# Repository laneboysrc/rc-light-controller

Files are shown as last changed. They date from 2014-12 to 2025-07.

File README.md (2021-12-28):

# Light controller for Radio Controlled cars

Realistic lighting of RC model cars using a standard 3-channel radio control system.

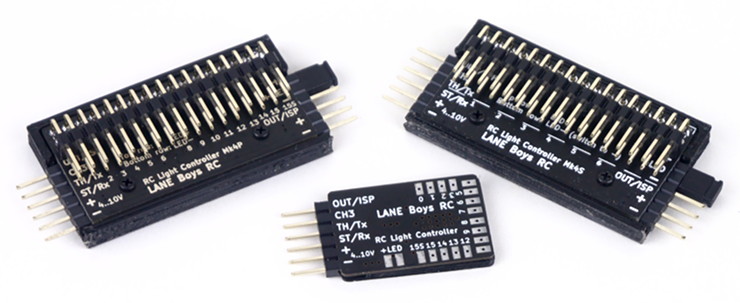
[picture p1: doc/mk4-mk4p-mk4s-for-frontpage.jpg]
MK4 light controller revision 2 PCB


The light controller supports the following features, and more::

- **16 LED outputs, constant-current** driven. Up to 20mA per output. Two light
controllers can be cascaded for a total of 32 LED outputs.
(Mk4 and Mk4P only)

- 1 high current non-dimmable **switched output** of up to **2A** to drive a roof light bar
(Mk4S: 9 non-dimmable switched outputs)

- **Parking, Low-beam, High-beam** and a roof **light bar** can be switched on/off manually from the transmitter

- **Brake** and **Reversing** lights are **automatically** controlled by monitoring the throttle channel. The brake lights now automatically turn on for a short, random time when the throttle goes to neutral.

- **Combined tail and brake light** function in a single LED through controlling the brightness of the LED. (Mk4 and Mk4P only)

- **Indicators** only come on when you want to. You have to stay in neutral for one seconds, then hold the steering left/right for one second before they engage. This way normal driving does not trigger the indicators.

- **Hazard lights** can be switched on/off from the transmitter

- **Programmable output** designed to drive a **steering wheel** or a figures head, or a
**gearbox servo**

- Automatic center and end-point adjustment for steering and throttle channels

- **16 LEDs** can be driven by one light controller. Two controllers can be **daisy-chained for up to 32 LEDs**.

- **Light Programs for custom light animations** like police lights, running lights ...

- Simulation of incandescent lights and faulty ground wiring

- Optional **i-Bus** compatible input

- Optional Pre-Processor for **easier wiring**

- **Up to 3 AUX channels** can control light functions when using the **5-channel Pre-
Processor**

- All functions can be **customized through a [web browser](https://laneboysrc.github.io/rc-light-controller/)**

## Documentation

An **introduction video** can be found at:

- [https://youtu.be/-VyNAVU3-ok](https://youtu.be/-VyNAVU3-ok)

You may also want to read the **[users guide](doc/light-controller-instructions-mk4.pdf)** to get a grasp of the full functionality of this light controller system.

(Die [Bedieungsanleitung ist auch in Deutsch](doc/light-controller-instructions-mk4-deutsch.pdf) verfügbar)

## Hardware

Firmware and schematics for the different variants are included in this project.

Over the years, the light controller went through various iterations. The document [doc/hardware-overview.md](doc/hardware-overview.md) explains the history of development.

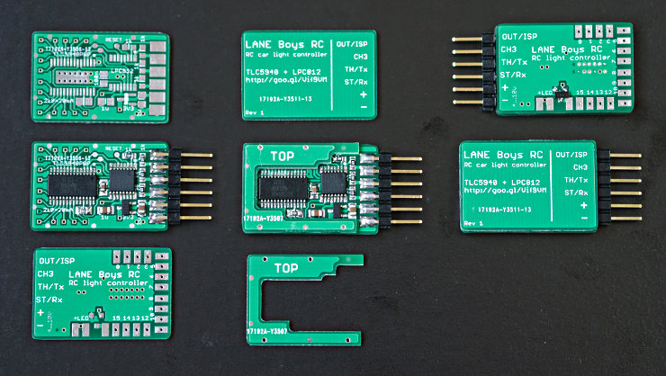
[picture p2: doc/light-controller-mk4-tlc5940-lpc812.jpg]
MK4 light controller in various state of assembly


[The current MK4 variant](mk4-tlc5940-lpc812/) can drive **16 LEDs** with a **constant current**. It utilises an inexpensive **NXP ARM Cortex-M0 32-bit microcontroller**.
The main advantage of this design is that it can be fully configured through a [web-based user interface](https://laneboysrc.github.io/rc-light-controller/). Firmware and configuration can be downloaded with a standard USB-to-serial converter, no proprietary tools required.

## Unable to build one yourself?

Not everyone is able to build circuit boards with tiny SMD components. If this applies to you please contact [laneboysrc@gmail.com](mailto:laneboysrc@gmail.com), we usually have a few fully built-up units in stock.

## Related articles

- [http://laneboysrc.blogspot.com/2012/07/diy-car-light-controller-for-3-channel.html](http://laneboysrc.blogspot.com/2012/07/diy-car-light-controller-for-3-channel.html)

- [http://laneboysrc.blogspot.com/2013/09/diy-rc-light-controller-update.html](http://laneboysrc.blogspot.com/2013/09/diy-rc-light-controller-update.html)

- [http://laneboysrc.blogspot.com/2012/12/pre-processor-for-diy-rc-light.html](http://laneboysrc.blogspot.com/2012/12/pre-processor-for-diy-rc-light.html)

- [http://laneboysrc.blogspot.com/2013/01/pre-processor-miniaturization.html](http://laneboysrc.blogspot.com/2013/01/pre-processor-miniaturization.html)

- [http://laneboysrc.blogspot.com/2014/07/ws2812-and-pl9823-led-power-consumption.html](http://laneboysrc.blogspot.com/2014/07/ws2812-and-pl9823-led-power-consumption.html)

- [http://laneboysrc.blogspot.com/2014/08/diy-rc-light-controller-with-ws2812b.html](http://laneboysrc.blogspot.com/2014/08/diy-rc-light-controller-with-ws2812b.html)

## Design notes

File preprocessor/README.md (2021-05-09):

# Pre-processor

The pre-processor converts steering, throttle and AUX/CH3 signals into a single wire serial signal. By mounting the pre-processor near the receiver in the car chassis, you only need to run a standard servo extension cable to the light controller in the body shell.

This makes it very convenient when removing the body shell from the chassis: only one cable needs to be unplugged.

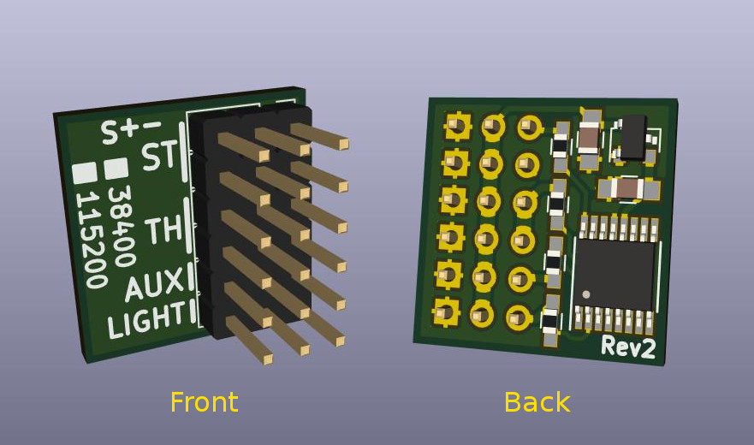
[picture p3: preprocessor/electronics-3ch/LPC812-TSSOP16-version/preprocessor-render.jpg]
Pre-processor circuit board rendering


The pre-processor PCB also acts as "Y-cable" for steering and throttle. Use short male-to-male servo extensions to connect the pre-processor to your receiver, and plug the servo and ESC into the two extra ports on the pre-processor.

A [wiring diagram](../doc/preprocessor-wiring-diagram.pdf) explains how to connect the pre-processor, the light controller and the other electronics components in an RC car together.

The firmware for the pre-processor is the same as for the [MK4 variant](../mk4-tlc5940-lpc812/), you just have to utilize the MK4 configurator tool to generate a pre-processor firmware.

If the baud rate is configured to 38400, the pre-processor is also compatible with the MK2 and MK3 variants.

The PCB and schematics design was done in [KiCad EDA](http://kicad-pcb.org/)

3-channel Pre-Processor: [electronics-3ch/](electronics-3ch/)

5-channel Pre-Processor: [electronics-5ch/](electronics-5ch/)

5-channel Pre-Processor/switching light controller combination (4 switched LED outputs): [electronics-5ch-switching/](electronics-5ch-switching/)

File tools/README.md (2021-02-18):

# Tools that apply to multiple versions of the light controller

The command line tools are writing in [Python](http://www.python.org/).

## preprocessor-reader.py

Reads and displays the output of the preprocessor (= a small microcontroller that interfaces with your receiver. This microcontroller outputs a single serial signal containing information for steering, servo and AUX channels. By using a preprocessor the light controller can be connected with a single servo extension wire.)

Used for debugging and testing the preprocessor.

## preprocessor-simulator.py

This tool simulates an RC transmitter, generating a serial output of steering, throttle and AUX channels in the serial preprocessor format. It is very useful for bench-testing the light controller functionality without having to hook up a RC system.

The user interface is web-based: after launching the tool open your webbrowser and browse to [http://localhost:1234/](http://localhost:1234/)

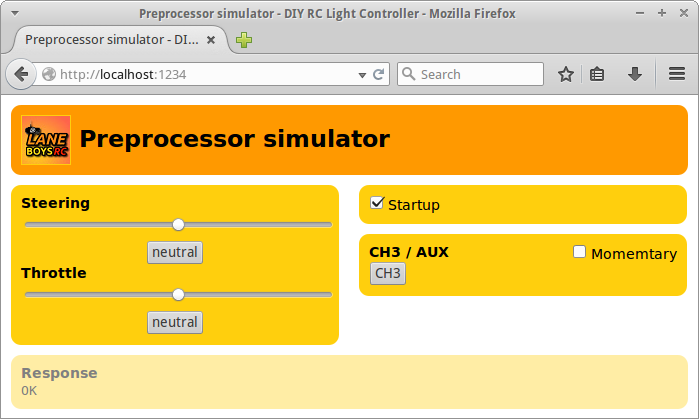
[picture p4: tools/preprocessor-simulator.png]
Preprocessor-simulator screenshot


Keyboard shortcuts:

- **s**: Toggles startup-mode
  Startup-mode signals the light controller that the preprocessor is initializing and not ready for operation yet.

- **c**: Perform a CH3/AUX "click". Easier than hitting the on-screen button with the mouse.

## slave-reader.py

This utility reads the slave output of an RC light controller and displays it in human readable form.

## test-slave.py

This tool drives a light contoller *slave* with a test pattern. Useful for testing.

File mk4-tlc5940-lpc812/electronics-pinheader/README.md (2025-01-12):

# Mk4P - light controller with pin headers

This is a variant of the DIY RC Light Controller Mk4 where all outputs are available on a standard 2.54 mm pin header.

We are using a microcontroller from NXP: LPC824M101FDH20 (or LPC832M101FDH20) in TSSOP-20 package.

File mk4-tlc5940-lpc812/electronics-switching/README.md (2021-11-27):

# Mk4S - light controller with pin headers and 9 switching outputs

This is a new variant of the DIY RC Light Controller Mk4.
It has 9 (Mosfet) switched outputs on standard 2.54 mm pin headers, 8 of them with two connections and one of them with 1 connection.

We are using the TSSOP-20 package of the LPC812 as it is easier to source (as of 2020) than the TSSOP-16 version, and we have plenty of space.

# 2021 electronics shortage

As of early 2021, many electronics components are out of stock due to global semiconductor shortage. This affects also the LPC812 microcontroller.

As of April 2021 a similar microcontroller from NXP, the LPC832M101FDH20 was still in stock at some distributors (but stocks declined towards mid of April rapidly). We prepared a new circuit board for the LPC832, and also ported the firmware.

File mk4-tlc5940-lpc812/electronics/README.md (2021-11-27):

# Mk4 - light controller with solder pads

This is the original version of the Mk4 light controller.
Multiple PCB versions are available for different microcontrollers.

The LPC812-TSSOP16 version is the original design.

pcb-size-27x20 uses the LPC812-TSSOP16 and was created to get around the minimum assembly width requirement for 3rd party manufacture. Not recommended.

The LPC812-XSON16 version uses a tiny case for the microcontroller, which is extremely difficult to work with unless you have professional equipment.

The LPC812-TSSOP20 was never built and tested.

The LPC832-TSSOP20 version is not tested yet, but most likely will work as we successfully ported the Mk4P (basically same schematics) already to the LPC832.

Background info: we ported to the different microcontroller variants to get around the global chip shortage in 2020/2021.

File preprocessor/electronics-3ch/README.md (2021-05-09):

# 3-ch Pre-Processor

This folder contains KiCAD files for the 3 channel Pre-Processor.

The original design used the TSSOP-16 package of the NXP LPC812 microcontroller.
Folder [LPC812-TSSOP16-version/](LPC812-TSSOP16-version/)

Since the TSSOP-20 version was easier available at distributors, we also designed a PCB for this mircocontroller: [LPC812-TSSOP20-version/](LPC812-TSSOP20-version/)
We never built this PCB yet ourselves but it is likely to work since it is just a different package.

# 2021 electronics shortage

As of early 2021, many electronics components are out of stock due to global semiconductor shortage. This affects also the LPC812 microcontroller in both TSSOP-16 and TSSOP-20 packages.

However the XSON-16 package was still available, so we redesigned the PCB for this package: [LPC812-XSON16-version/](LPC812-XSON16-version/)
XSON-16 has a pin-pitch of only 0.4 mm and is extremely difficult to solder in a hobbyist-environment using cheap solder paste and a modified toaster oven. A high number of boards have to be reworked, making it very labor intense to build the hardware.

As of April 2021 a microcontroller similar to the LPC812 from NXP, the LPC832M101FDH20, was still in stock at some distributors (but stocks declined towards mid of April rapidly). We prepared a new circuit board for the LPC832, and also ported the firmware.

As of 2021-04-20 the same firmware can be used for the LPC812 and LPC832 variant.

Note that the LPC81x_ISP programming tool does not support LPC832 yet, but the WebUSB programmer does.

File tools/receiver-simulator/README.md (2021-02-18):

# Receiver simulator

This test code uses a Microchip (Atmel) SAMD21 micro-controller to simulate a 2-channel receiver.

It was designed to run on an SAMR21 Xplained Pro board (because this is what I had lying around), but can be easily adapted to other SAMD21 boards.

The current I/O definition can be found in hal.h.

- The UART prints diagnostics output.
- Two pins should be connected to potentimeters to control ST and TH channels.
- Two other pins output 1000-2000 us servo pulses depending on the potentiometer position.

The receiver has one special feature that the ST and TH output run asynchronously and at different fequencies. TH outputs every 32 ms, ST ever 16ms.
This was done because it seems to mimic the behaviour of the Spektrum 4210 receiver. This behaviour is quite unusual and caused an issue with flickering brake lights.

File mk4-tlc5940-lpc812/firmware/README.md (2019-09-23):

# Build instructions for the MK4 TLC5940 LPC812 variant

Note: most users will not need to build the firmware as it can be fully configured through a web-based configuration tool!

## Tools required:

- GCC for ARM - [https://developer.arm.com/tools-and-software/open-source-software/developer-tools/gnu-toolchain/gnu-rm/downloads](https://developer.arm.com/tools-and-software/open-source-software/developer-tools/gnu-toolchain/gnu-rm/downloads)

- GNU Make - [https://www.gnu.org/software/make/](https://www.gnu.org/software/make/)
  Windows executable is available at [http://gnuwin32.sourceforge.net/packages/make.htm](http://gnuwin32.sourceforge.net/packages/make.htm)

- Windows users: **rm.exe** from [coreutils](http://gnuwin32.sourceforge.net/downlinks/coreutils-bin-zip.php).

# Building the firmware

Running ``make`` in a console window in this directory builds the firmware. The resulting *firmware.bin* and *firmware.hex* are located in the build directory.

Running ``make program`` flashes the firmware, assuming you are using the [LCP81x-ISP](https://github.com/laneboysrc/LPC81x-ISP-tool) tool.

Files in the firmware root directory are source code that is processor hardware independent. The *hal/* folder contains processor-specific light controller functionality such as MCU initialization, GPIO, SPI, UART etc.
*LPC8xx/* contains header files provided by NXP for the LPC812 MCU. *light_programs/* contains example light programs you can use for reference.
Output files of the build process are placed in the *build/* folder.

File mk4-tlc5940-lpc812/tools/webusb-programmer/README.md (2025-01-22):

This is a programmer for the NXP LPC812/823/824 micro-controller, using the ISP (serial) protocol.

It connects to a PC or Android phone via USB and uses WebUSB (available in Chrome, Opera and Edge browsers) to communicate with a web app.

The great thing about this programmer is that no driver or software needs to be installed. Just connect the WebUSB programmer to the PC, load the Light Controller Configurator in the web browser, and program your light controller.

REV6 uses standard 0805 LEDs instead of the hard-to-work-with 1204 side firing LEDs we used in earlier revisions.

REV5 switched from MicroUSB to USB Type C.

REV4 can work with the CH551G, CH552G or CH554G microcontroller from WCH. REV3 was working fine, but due to the *chip crisis* of 2021 it was not possible to get hold of the ST power switch anywhere. So we re-designed the electronics to use a very cheap motor driver to switch the power to the light controller. The firmware was also modified to use UART0, because only UART0 is available on CH551G.

REV3 was the first version using the inexpensive CH552G microcontroller from WCH that has an 8051 core and USB device capability. The BOM has been reduced to the minimum so that long-term we can provide the WebUSB programmers instead of USB-to-Serial adapters. The LEDs are now side mounted so they can be viewed from both sides of the PCB.

In REV1 and REV2 a Microchip (Atmel) ATSAMD21 MCU was used, as we had stock of these. However, this is quite an expensive MCU (at least ten times the price of the CH552!), and needs additional peripheral electronics like an LDO. And it uses a 0.5mm QFN package which requires a stencil, solderpaste and reflow equipment.

REV1 used a surface mount Micro-USB connector (because we had it in stock). However, several people broke the connector as it is mechanically not very robust. Furthermore, the white LED with its soft diffuser is also fragile and can get damaged when handling or shipping.

In REV2 we changed the Micro-USB connector to one with through-hole mounting tabs, and use "reverse mount" LEDs (actually side view LEDs abused in a reverse mount fashion). REV2 worked fine except that the footprint for the Micro-USB connector is not optimal and the hole for the LEDs is slightly too small.

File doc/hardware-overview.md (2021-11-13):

# Hardware overview

Over time the DIY RC Light Controller hardware went through several iterations.

The following sections describe the various variants in detail, list their unique features and provide pros and cons to allow you to make a decision which variant is best for your application.

**Important: Older versions are available in the branch named [*obsolete*](https://github.com/laneboysrc/rc-light-controller/tree/obsolete) in this repository.**

## Mk4 TLC5940 LPC812 and LPC832

Mk4 light controller Rev 2

This iteration makes use of NXP's LPC812 micro-controller. The LPC812 contains an ARM Cortex-M0+ 32-bit core, yet costs as little as the PIC micro-controller we used in earlier variants. The firmware is now written in C. It is compiled with the Open-Source GCC compiler. The LPC812 contains a ROM-based bootloader so firmware can be flashed by using a very low cost USB-to-serial converter (less than USD 3, including shipping, on eBay).

One of the main issue for other people building earlier light controller variants was making changes to the firmware to suite their particular requirements. With the Mk4 variant we have now a **web-based configuration tool** called the **Configurator** that allows anyone to adapt the light outputs to their desired functionality without having to modify source code.

The TI TLC5940 LED driver IC is employed to drive the LEDs with a constant current. 16 LED outputs are available. The current, and therefore the LED brightness, can be adjust in 63 steps. Using a constant current means that no resistor is needed for the LEDs, and that the LEDs don't flicker as they would when they are driven by PWM signals. Humans don't see the flicker, but in videos the shutter speed of the camera often causes ugly blink effects when PWM dimming is employed.

Based on feedback from users, the Mk4 variant also now supports an option for a high-current switched light output. Such output is useful to drive an off-the-shelf roof light bar without modification.

The light controller can also control a 2-speed or 3-speed gearbox servo, or an auxiliary servo that drives the steering wheel in the cabin of the car, or a figures head.

If more than 16 LED outputs are needed, a second light controller "slave" can be added to drive another 16 LEDs, all in control of the "master" light controller.

Due to improved hardware available in the LPC812 micro-controller, servo pulse reading is now auto-adaptable and should work with any RC system on the market. In addition there is also support for the [preprocessor](#preprocessor).

The preprocessor makes wiring up the light controller much simpler as only a single servo extension wire is needed to get steering, throttle and AUX channel information from the receiver to the light controller.

The light controller can now also be used with 2-channel radios by mounting a push-button somewhere hidden on the car to control the lights.

The main downside of the Mk4 design is that the LPC812 micro-controller is only available in tiny surface mount packages. It more or less requires to build the light controller on a PCB, though one may get away with an off-the-shelf TSSOP-16 adapter board.

Based on customer request, we also made the Mk4P light controller. Schematics-wise it is identical with the Mk4, but it has a pin header so that LEDs can be connected without soldering.

We also made a Mk4S variant that has 9 switching outputs instead of current-controlled outputs. The Mk4S has the same form factor as the Mk4P is great for users who want to use high-power LEDs.

There are also two variants that we haven't promoted. The Mk4S-mini is a small light controller with 3 switching outputs. It is suitable for users that require more than one switching output, but not all 9 that the Mk4S offers.

Then there is the 5ch-PP-S, a 5-channel Pre-Processor and light controller hybrid. It has the form-factor of a slightly enlarged 5-channel Pre-Processor and offers 4 switched light outputs. This variant is useful for crawlers where there are a few LEDs in the chassis (driven by the 5ch-PP-S) and the remaining LEDs in the body shell (powered by Mk4, Mk4P or Mk4S)

*And then the chip crisis of 2020/2021 happened ...*

The LPC812 micro-controller suddenly had a lead time of 52 weeks, and is nowhere to be found. Well, a few places had the tiny XSON package with 0.4 mm pin pitch. We tried building light controllers in the XSON package, but it was not practical in our primitive home workshop -- we had almost 60% failure rate.

Luckily, NXP also has a similar sister-chip named LPC832. It has slightly different features, a different pin out and comes only in TSSOP20 package. We were able to stock a few pieces of LPC832 at affordable prices and developed new circuit boards for all Mk4 variants. The firmware was adapted so that it can seamlessly work with both LPC812 and LPC832. Also the programming tools had to be adapted. As of writing of this paragraph (November 2021), also the LPC832 becomes a very scarce resource ...

## Pre-Processor for simpler wiring

To utilize its full potential, the DIY RC Light Controller must be able to read Steering, Throttle and AUX (CH3) signals from the receiver. Such a combined signal such as CPPM is unfortunately not available on most modern surface receivers. (Update 2021: i-Bus is now available on surface receivers from Flysky!)

Therefore the easiest way is to use a Y-cable on steering and throttle channels and feed all signals individually to the light controller.

However, since the light controller is usually mounted on the body shell and the receiver on the chassis, the Y-cable solution requires one to disconnect three cables every time the body shell needs to be separated from the chassis.

To solve this issue we added a small micro-controller into our receivers. This micro-controller directly taps into the servo outputs and generates a serial signal on a single wire that contains combined information of all channels. This way we only need to run a single servo extension wire between the chassis and the body, providing both power and data. We use this system in most of our RC cars.

More information about the Pre-Processor:

- [http://laneboysrc.blogspot.com/2012/12/pre-processor-for-diy-rc-light.html](http://laneboysrc.blogspot.com/2012/12/pre-processor-for-diy-rc-light.html)

- [http://laneboysrc.blogspot.com/2013/01/pre-processor-miniaturization.html](http://laneboysrc.blogspot.com/2013/01/pre-processor-miniaturization.html)

Note that with the Mk3 WS2812 PIC12F1840 variant one could mount the light controller on the chassis and have a single 3-pole wire running to the first LED in the chain. Since we run different bodies on many of our chassis, each having different light configurations, we still use the Pre-Processor. Since the cost of the PIC12F1840 is less than USD 2 this is not an issue.

Naturally most people won't modify their receiver to add this chip, plus programming the PIC micro-controller requires investment in a proprietary programming tool.

So with the introduction of the Mk4 light controller, we also made separate circuit boards for the Pre-Processor. This enabled more users to benefit from the Pre-Processor concept.

The Pre-Processor is built upon the same NXP LCP812 (and LPC832) micro-controller as the Mk4 light controller. Actually a Pre-Processor is nothing more than a light controller without LED driver, and a special configuration in the firmware.

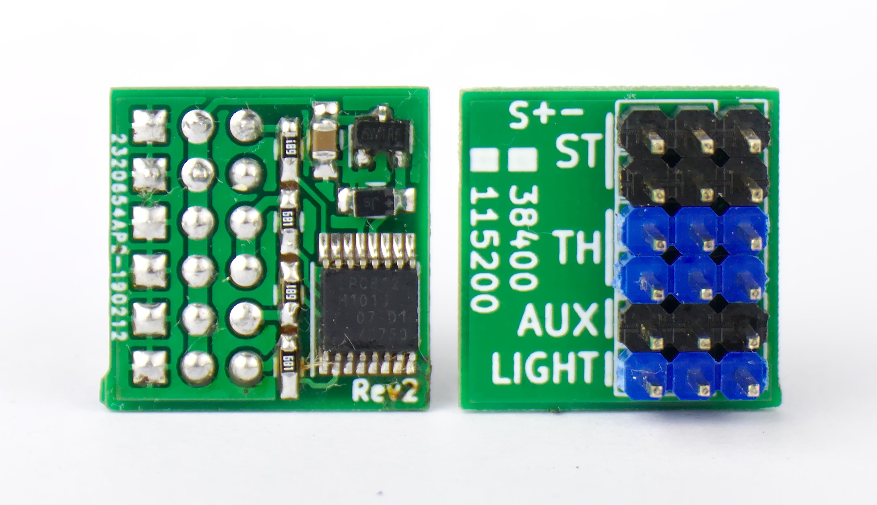
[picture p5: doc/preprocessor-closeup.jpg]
The 3-channel Pre-Processor


A few customers were requesting more control over lights, so we added a 5-channel Pre-Processor that offers two additional AUX channels.

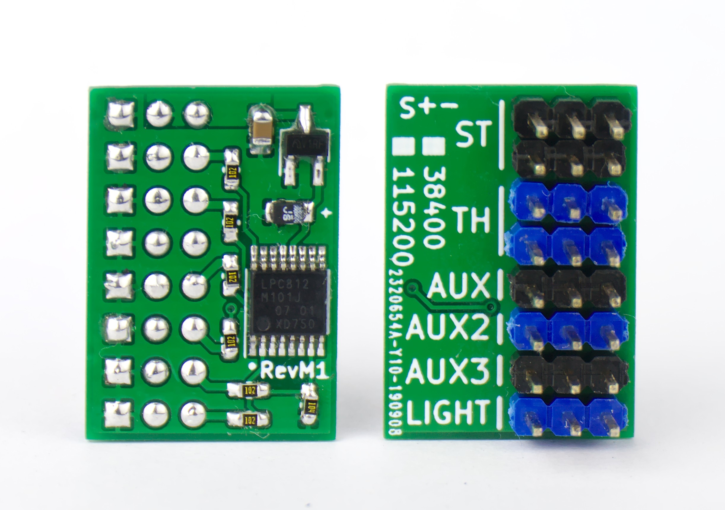
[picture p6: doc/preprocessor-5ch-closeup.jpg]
The 5-channel Pre-Processor


## Mk3 WS2812 PIC12F1840

The MK3 light controller on the left

(MK3 on the left, MK2 on the right)

In recent years LEDs are appearing on the market that contain a controller chip. Currently the [WS2812B](https://www.adafruit.com/products/1655) is highly popular. It is a RGB LED that contains a simple chip inside. The LED is controlled through a single pin using a [serial shift-register-like protocol](http://cpldcpu.wordpress.com/2014/01/14/light_ws2812-library-v2-0-part-i-understanding-the-ws2812/). Multiple LEDs can be chained together; like a Christmas light.

The WS2812B is extremely cheap too. When ordered in 100 pcs quantity from China it is only slightly more expensive than a regular 5 mm white LED from the local hobby shop.

Using such LEDs makes wiring up a vehicle very easy: one only needs to run 3 wires from one LED to the next. Also the control electronics becomes simpler as only a simple low pin-count device is needed. We have chosen the PIC12F1840 that we already employed in other applications.

The WS2812B are SMD LEDs in a 5 x 5 mm square case. This makes mounting them in a traditional RC car light bucket, which is usually designed for 5 mm round dome style LEDs, inconvenient.

However, the [PL9823](http://www.aliexpress.com/item/PL9823-F5-5mm-round-hat-RGB-LED-with-PD9823-chipset-inside-full-color-frosted/1707175958.html) has the same functionality as the WS2812B and comes in a standard 5 mm dome encasing with four leads. The PL9823 is timing compatible with the WS2812B, so both LEDs can be mixed in the same string of lights.

The PL9823 has few downsides over the WS2812B:

- [High power consumption](http://laneboysrc.blogspot.com/2014/07/ws2812-and-pl9823-led-power-consumption.html) of \~7-8mA even if the LED is off

* When power is applied the LEDs usually light up blue until they receive valid data. The WS2812B stay off until data is received.

* Data format is red-green-blue , while WS2812 is green-red-blue. This can be easily dealt with in software though.

**Note that it is essential to put a bypass capacitor of 100nF over the supply pins of each LED.**

When using the WS2812 it is advisable to not buy the bare LED, but rather the ones that come on a tiny circuit board of \~10 x 10 mm.
This board already contains the bypass capacitor and convenient terminals for soldering.

Unfortunately no such board seems to exist for the PL9823. It is possible to solder wires directly onto the leads of the LEDs, but due to the narrow pitch it is not fun. We have made a small break-out board, including bypass capacitor, ourself. The board layout is available in Eagle format.

The hardware is extremely simple: just four components are needed. It is easy to build on a prototyping board in less than half an hour.

A downside of the WS2812B or PL9823 based light controller is the narrow operating voltage range. The WS2812B can operate between 3.5V to 5.3V, the PL9823 requires 4.5V to 6V. The PIC12F1840 can operate between 2.5V and 5.5V.
This means that the light controller is best powered from a 5V BEC, or if the BEC operates at 6V a diode must be used to drop the voltage to the safe range.
When the car battery gets low, especially when using NiMh batteries, the LEDs at the end of the chain can start to glitch.

The LEDs also do not tolerate any reverse voltage. When + and - are accidentally swapped they burn out immediately. Don't ask how we know...

A great feature of the WS2812B or PL9823 based light controller is that the color of each LED can be programmed individually. In our Rally Legends Lancia Fulvia body shell the rear indicators and reversing lights are driven by a single LED, but by programming the LED to output either white or orange
light we were still able to simulate reversing lights and indicators.

The LEDs are very bright, often too bright for scale appearance. They can be dimmed down, for which they employ PWM. This can cause flicker when making a video.

Since the LEDs are RGB based, white is not exactly white and often has a bit of a purple tint, giving a strange look to car head lights. Since the individual RGB chips within the LED are not exactly at the same spot, colored fringes can be visible.
All this is nit-picking of course...

Unfortunately there does not seem to be any variant of the WS2812B or PL9823 that comes in a 3 mm dome factor, which is sometimes used in light buckets of Tamiya or HPI.

The firmware is the same as the MK2 TLC5940 PIC16F1825 variant, with some minor additions to drive the WS2812B LEDs.

## Mk2 TLC5940 PIC16F1825

Light controller on prototyping board and PCB (http://www.flickr.com/photos/78037110@N03/9769284031/)

This variant uses the Microchip PIC16F1825 8-bit micro-controller in a 14-pin package.

The TI TLC5940 LED driver can drive up to 16 LEDs. If more LEDs are needed two light controllers can be daisy-chained (master-slave concept).

It is possible to build the light controller on a prototyping board using DIL components, which may be easier for hobbyists than SMD. Size is still small enough to fit in a RC car.
Be careful: the TLC5940 has a different pin assignment between the DIL and TSSOP (SMD) package variants!

This variant of the light controller can operate from a wide voltage range of 4 to 10V. The LEDs can be driven from an even higher voltage of up to 20V, although heat generated in the TLC5940 will be a limiting factor.

LEDs are driven with a constant current, which can be individually programmed per LED output. Since the LEDs are driven with DC there is no flicker appearing on videos.

If the supply voltage allows, multiple LEDs that need to light up at the same time can be wired in series. For example, the red tail light LEDs can be wired in series, so only one light output is used up. Naturally wiring becomes more complex.

Due to historical reasons the firmware is written in PIC assembler, using the Open-Source *gputils* software. This is quite a hurdle for the average RC enthusiast to adapt the functionality to their need.

Due to hardware limitations, a software approach is needed to read the servo signal pulses. Various configuration options must be carefully set to ensure the light controller can inter-operate with your particular RC radio.

To program the firmware into the micro-controller, a proprietary programmer is needed. This needs to be taken into account as the cost of this programmer (~ USD 50) may be a big chunk of the budget needed to get the light controller built and running.

### Mk1 TLC5916 PIC628a

The first light controller we ever built (https://www.flickr.com/photos/78037110@N03/7675556184)

The original design used a PIC16F628A and TLC5916 LED driver. The LED driver was constant current, but not adjustable like the TLC5940. It had only 8 light outputs, so LEDs had to be wired in series to get a car fully lit up.

Since white LEDs require more than 3V each, a voltage booster had to be installed to ensure the voltage never went below 7V even if the main car battery was almost empty. This added significant cost.

This design is not recommended for new projects as the components are outdated, functionality is limited and the parts are more expensive than the other variants.

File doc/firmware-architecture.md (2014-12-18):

# Firmware architecture

All current variants of the DIY RC Light Controller use Microchip PIC 16 micro-controllers.

The firmware is written in Assembler, using the open source [gputils](http://gputils.sourceforge.net/).

## Customizing the light controllers functionality

Often body shells require different light configurations: some have parking lights and main beam, others main beam and high beam only. Some cars have fog lamps. On some cars the brake and tail lamps are combined, on others they are separate LEDs.

To facilitate these difference, vehicle-specific algorithms are stored in a separate file that starts with the prefix ``lights-``.

There is however also a ``lights-generic.asm`` that may fit a wide variety of vehicles. The functionality of the generic configuration is described in [../doc/light-controller-instructions.pdf](../doc/light-controller-instructions.pdf).
This configuration is currently only available for the TLC5940 based hardware. The firmware directory contains pre-assembled HEX files for your covenience:

- [generic-two-position-master.hex](../firmware/generic-two-position-master.hex)

    For transmitters where the AUX/CH3 channel is a two position switch; e.g. HobbyKing HK310, FlySky GT3B

- [generic-momentary-master.hex](../firmware/generic-momentary-master.hex)

    For transmitters where the AUX/CH3 channel is a momentary push button; e.g. Futaba 4PL

For hardware testing there is ``lights-test-tlc5940-16f1825.asm`` and ``lights-test-ws2812-12f1840.asm``, which blink the connected LEDs without the need of any receiver input. Very useful for debugging PCBs.

Ready made HEX files are available for your convenience:

- [test-tlc5940-16f1825.hex](../firmware/test-tlc5940-16f1825.hex)

    For the TLC5940 and PIC16F1825 based hardware

- [test-ws2812-12f1840.hex](../firmware/test-ws2812-12f1840.hex)

    For the PIC12F1840 based hardware driving WS2812B or PL9823 LEDs

## Common components

Independent of the hardware and vehicle configuration, all light controller
variants build upon a set of common files. Usually you will not need to modify
any of these files.

- ``master.asm``

    This file contains the main business logic of the light controller. It also
    contains the startup function and hardware initialization.

- ``utils.asm``

    Utility functions for mathematics, etc.

- ``servo-output.asm``

    Functionality to drive a servo, e.g. for a 2-speed gearbox, a steering wheel or a figures head.

## Hardware specific components

To gain flexibility in the used hardware, certain functionality has been split
into include files. The correct include file matching the light controller
hardware must be chosen.

- ````hw_tlc5940_16f1825.inc````

    For hardware based on the TLC5940 and the PIC16F1825.

- ````hw_ws2812_12f1840.inc````, ````ws2812.asm````

    For driving WS2812B or PL9823 LEDs using a PIC12F1840 micro-controller.

- ````hw_original_servo_reader.inc````, ````hw_original_uart_reader.inc````

    For the first iteration of the light controller based on PIC16F628A and
    TLC5916. Not recommended for new builds.

## Input specific components

The DIY RC Light Controller can get access to the Steering, Throttle and AUX
channels either by reading the servo pulses directly from the receiver, or in a
single combined UART (serial) signal from a pre-processor. Please refer to
[hardware-overview.md](hardware-overview.md) for information on the pre-
processor.

- ``servo-reader.asm``

    This file must be used when reading servo pulses directly from a receiver.
    Note that all three signals must be present, otherwise the light controller
    will not function!

- ``uart-reader.asm``

    This file is used when a pre-processor is employed.

- ``dummy-reader.asm``

    Used during development only. It can be modified to perform certain operations
    without having to use an actual RC system.

## Build process

Building the various light controller firmware variants is done with a makefile. The supplied makefile is GNU Make compatible.

Running ``make`` builds all configured variants and vehicles. To build a
specific variant one needs to execute ``make vehicle_name``.

Please refer to the makefile itself for more information; it contains detailed
comments about how the build process works.

## Creating a custom light configuration

As stated initially, RC body shells differ in terms of available lights. Therefore we usually create a new custom light logic for each new body shell we
acquire. We don't do this from scratch but mostly copy from an existing vehicle
that has a hardware and light configuration close to the new vehicle.

The light logic is stored in files with the prefix ``lights-"``. Each light
logic is also tied to a specific hardware, which is the hardware we've chosen
for that vehicle.

Good choices for starting new vehicles are:

For the TLC5940 based light controller, use the simple ``lights-ferrari-la-ferrari.asm`` for a car that has only 2 LEDs in the front and 2 in the back.

A more complex TLC5940 based example is ``lights-subaru-impreza-2008.asm``, which drives 14 light outputs in total.

A very elaborate light logic with winch control, 2-speed gearbox control and
running lights is ``lights-wraith.asm``; also TLC5940 based like most of the
light logic files supplied.

For the WS2812 based light controller there is ``lights-fiat-131.asm`` as simple
example, mixing both WS2812B and PL9823 LEDs. ``lights-lancia-fulvia.asm`` is
using PL9823 LEDs exclusively but has a nice gimmick of fading indicators,
simulating incandescent bulbs, and a simulation of a weak earth connection by
dimming the left tail/brake light whenever the indicator lights up.

Some old American vehicles have a single light in the back for combined tail,
brake and indicator functionality. You can find a reference implementation of
this scheme in ``lights-sawback.asm`` (TLC5940 based) and ``lights-xr311.asm``
(outdated TLC5916 design with two stacked TLC5916s, not recommended).

## Light configuration implementation details

Every ``lights-"`` vehicle specific file needs to export two functions that
are called by the rest of the firmware:

- ``Init_lights``

    This function is called during startup of the DIY light controller. Here we
    initialize the LED driver hardware, and set the LEDs to a unique pattern
    that indicates that the light controller is waiting for a receiver signal.
    This helps us identifying connection problems, as the ``Output_lights``
    function documented below is only called once we have detected valid pulses
    from the receiver. Therefore we know that if the LED pattern set by the
    ``Init_lights`` function is visible, we did not receive valid signals from the receiver yet.

- ``Output_lights``

    This function is called every *mainloop*. It monitors the state of certain
    global variables (see below) and turns on and off the LEDs corresponding to
    the state found in those variables. The mainloop runs once every time all
    three servo signals (Steering, Throttle and AUX) have been read. Ideally
    this happens at the repeat rate of the servo pulses (e.g. 16ms for the
    HobbyKing HK310, ~8ms for the Futaba 4PL), but may take 3 times as long if
    the sequence of the pulses generated by the receiver is not the sequence
    expected by ``servo-reader.asm``.

The light controller firmware outputs the state of certain light and drive
functions in global variables. The ``lights-"`` vehicle specific file monitors
these variables and outputs LEDs that corresponds to the state of those
variables.

The next sections describes some of the variables available.

### startup_mode

This variable is non-zero during the time the DIY RC light controller is waiting for the servo signals to stabilize and register the neutral point for Steering and Throttle. The user should not touch Steering and Throttle during this time as it would interfer with recording the neutral point, therefore we generate a uniquly identifyable light pattern that the driver can recognize that initialization is in progress.
Currently ``startup_mode`` only has a single bit ``STARTUP_MODE_NEUTRAL``, but other bits are reserved for future use.

### setup_mode

This variable is non-zero whenever a setup function, such as servo reversing or setting neutral and end-points for the steering wheel servo, are active.

The bits ``SETUP_MODE_CENTRE``, ``SETUP_MODE_LEFT`` and ``SETUP_MODE_RIGHT`` are used for setting up the steering wheel or gear shift servo (8 clicks on the AUX/CH3 channel). Usually we turn off all LEDs and turn the Indicator lights on permamently to signal those states (``SETUP_MODE_LEFT`` = left indicator; ``SETUP_MODE_RIGHT`` = right indicator; ``SETUP_MODE_CENTRE`` = both indicators).

``SETUP_MODE_STEERING_REVERSE`` and ``SETUP_MODE_THROTTLE_REVERSE`` prompt the user to turn the steering left, and the throttle to forward respectively so that the DIY RC Light Controller can learn the direction of the steering an throttle channels. This function is invoked with 7 clicks on the AUX/CH3 channel. Usually we turn on both main beams (but no tail lights) for ``SETUP_MODE_THROTTLE_REVERSE``, and both left indicators for ``SETUP_MODE_STEERING_REVERSE``.

### light_mode

This variable sets one more bit every time a single click on AUX/CH3 is performed.

It is used to drive the main lights on the vehicle. For example if a vehicle has parking lamps, main beam, and high beam, we would use bit 0 in ``light_mode`` to light up the parking lamps and tail lights; bit 1 to light up the main beam, and bit 2 to light up the high beam.

Higher bits are only set when the lower bits are 1, so we generate realistic light patterns, i.e. the main beam can only be on when parking lamps and tail lights are on.

### drive_mode

There are two bits in this variable that are of concern to us:

``DRIVE_MODE_BRAKE`` is set when the brake lights should turn on.

``DRIVE_MODE_REVERSE`` is set when the reversing lights should be on.

Other bits are available too; please refer to the source code for details.

### blink_mode

The ``blink_mode`` variable contains bits that relate to the indicator and hazard light functions.

``BLINK_MODE_BLINKFLAG`` toggles with 1.5 Hz and provides the actual blinking frequency. Usually you want to have the indicator LEDs off when this bit is off.

``BLINK_MODE_HAZARD`` is set when the hazard light funciton has been turned on (4 clicks on AUX/CH3)

``BLINK_MODE_INDICATOR_LEFT``, ``BLINK_MODE_INDICATOR_RIGHT`` are set when the left / right indicator function is active.

## Changing features at compile time

Certain features of the light controller can be configured when compiling a vehicle.
These features can be found in the ``CFLAGS`` directive of a vehicle in the makefile.

- ``LIGHT_MODE_MASK = 0x0f``

    This bitmask defines how many lights there are that should be switched on
    with a single click of the AUX/CH3 channel. Each time AUX is activated, more lights are turned on. If you have 2 lights (main beam and high beam for example), then you would specify ``0x03`` (0011 binary), if you have parking, main beam, high beam and fog lights you would specify ``0x0f`` (1111 binary), and so on. The mask defines basically the maximum value the ``light_mode`` variable (see above) will receive.

- ``CH3_MOMENTARY``

    Define this name if your transmitters AUX channel returns to the initial position when the AUX channel button is released (Futaba 4PL for example).

    If this name is not defined then the software assumes that every AUX channel activation toggles the AUX servo position (HobbyKing HK310, FlySky GT3B).

- ``ESC_FORWARD_REVERSE``

    Define this name when your ESC is in "crawler mode", i.e. it does not have a brake function but goes from forward to reverse immediately.

- ``DISABLE_BRAKE_DISARM_TIMEOUT``

    Define this name if your ESC goes into reverse only after applying the brake function once (Example: Tamiya TEU-105BK).

    Do not define this name for ESCs that automatically allow going into reverse when the throttle has been in neutral for a certain amount of time.

- ``ENABLE_STEERING_WHEEL_SERVO``

    Define this name if you want the light controller to drive a steering wheel servo. You must also define ``ENABLE_SERVO_OUTPUT`` and include ``servo-output`` in the list of files in the makefile.

- ``ENABLE_SERVO_OUTPUT``

    Define this name if you want the light controller to drive a servo. You must also include ``servo-output`` in the list of files in the makefile.

- ``ENABLE_UART``

    Define this name when using a UART related function such as uart-reader.

- ``NUMBER_OF_LEDS=`` 8

    Specifies the number of WS2812B or PL9823 LEDs in use. Only applies to the WS2812 variant of the light controller. The maximum number of LEDs currently supported is 21. This is a limitation of the RAM banks in the PIC16F architecture.

- ``ENABLE_GEARBOX``

    Define this name to enable control of a 2-speed gearbox using a servo. You must also define ``ENABLE_SERVO_OUTPUT`` and include ``servo-output`` in
    the list of files in the makefile.

- ``SERVO_OUTPUT_ON_THROTTLE``

    Define this name to output the servo signal on the throttle channel instead of the dedicated steering wheel servo output of the light controller. Only has an effect when ``ENABLE_SERVO_OUTPUT`` is enabled.

- ``ENABLE_WINCH``

    Enables control of a RC winch through using the [DIY RC Winch Controller](http://laneboysrc.blogspot.com/2013/09/make-your-own-rc-winch-controller.html).

- ``RECEIVER_OUTPUT_RATE = 20``

    Allows to specify the number of milliseconds between repeated servo pulses given by the receiver. If not specified the default of 16 ms is used. All this value really does is adjust the timing of initialization.

- ``SEQUENTIAL_CHANNEL_READING``

    Define this name when you are sure that the steering, throttle and AUX channel pulses are output by the receiver in sequence, right after each other. This is the case for the HobbyKing HKR3000 receiver. If unsure, do not define this value.

- ``CHANNEL_SEQUENCE_TH_ST_CH3``

    Define this along with ``SEQUENTIAL_CHANNEL_READING`` when the receiver pulse sequence throttle, steering, AUX; like in the GT3B.

- ``DUAL_TLC5916``

    Enables the use of two TLC5916 (for dim and full brightness). Not recommended, use TLC5940 hardware instead.

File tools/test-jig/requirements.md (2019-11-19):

# Test jig for light controllers and pre-processors

## Goals
- Be able to test light controllers and pre-processors before shipping them
- Be able to test light controllers after soldering
- Be able to test pre-processors after soldering
- Needs to work for both 3-ch and 5-ch pre-processors

**Excluded functions**
- Programming of light controllers and pre-processors

## Execution ideas
x Socket for mounting the 8ch receiver
x 5x 3-pin pin headers for mounting external receivers
x Power:
    x Micro-USB
    x 3-pin pin header
    x on/off Switch
    x Power LED
x 6-pin pin header for the light controller when testing with a pre-processor
x 6-pin pin header for the light controller when testing as servo reader
x 18 Pogo-pins (16 LED, 1 switched LED, 1 LED+) and mechanical support for the light controller
x Socket for the 3-ch pre-processor
x Socket for the 5-ch pre-processor
x 6-pin pin header for the USB-to-serial, wired to read the pre-processor output
    - Power not connected!
x 6-pin pin header for the USB-to-serial, wired to use the pre-processor simulator on the light controller
    - Power not connected!
x 2-pin pin header test points for all signals
    - Supply +, -
    - ST, TH, AUX, AUX2, AUX3, OUT/ISP, Pre-processor light output
x Push-button on CH3 for preprocessor test
x Mounting holes on the PCB edge
x Screw holes for the mechanical support for the light controller
- Everything is wired in parallel, no switches or jumpers; just plug in the devices needed for a test
- Generous and descriptive silk screen

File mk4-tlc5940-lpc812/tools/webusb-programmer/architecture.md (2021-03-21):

# Design goals

- Reset a connected light controller through switching its power supply
- OUT/ISP pin can be pulled-low for programming and released for running
- Custom WebUSB protocol using simple IN and OUT endpoints
- Be able to extend the protocol for use as Pre-Processor simulator
- Multiple LED indicating state
- USB DFU compatible bootloader for firmware upgrade

# Architecture considerations

- We don't want to put too much protocol details in the MCU
    - Which means we should separate the serial interface to the MCU from the control interface that controls power switching, OUT/ISP switching etc.

- UART interface
    - OUT endpoints sends data to Light Controller (Tx on the programmer)
    - IN endpoint sends data received from Light Controller (Rx on the programmer)

- Controler interface
    - We will be using USB control transfers
        - Type will be set to VENDOR
        - Request will be set to 72
        - wValue will contain the command
        - Commands can return data if necessary (using controlTransferIn)
            - Note that a command must be either out or in (SET or GET), it is not possible to use the same command with different directions
    - Commands:
        - SET OUT/ISP state: low, high, tri-state
        - SET DUT power: on, off
        - SET Baudrate
        - SET LEDs on, off

- LEDs
    - System power
    - Light controller power
    - Ok (green)
    - Busy (amber)
    - Error (red)

# Hardware (REV1 and 2)

- SAMD21E15A
- Micro-USB connector with through-hole mounting tabs for physical strength
- LDO 3V3, 1uF on input, 10uF + some 100n on output
- STMPS2141 high-side power switch, active low
- Light controller is powered from 5V
- 5 LEDs
    - USB power: white
    - Light controller power: blue
    - OK: green
    - Busy: amber
    - Error: red
- 6-pin header for light controller
    - Pin-out like Light controller or like USB-to-Serial?
- All pins have 1K series resistors for protection

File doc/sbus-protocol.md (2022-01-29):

# S.Bus

S.Bus is a proprietary protocol developed by Futaba.
(Dead link: https://www.futabarc.com/sbus/index.html)

S.Bus2 is an extension that supports telemetry.

Some receivers on the market output an "inverted SBUS" signal. However, it seems that those receivers are not suitable for RC cars as they only have S.Bus / Inverted S.Bus output and no traditional PWM servo output.

For the light controller it only makes sense to implement standard S.Bus, which is supported by Futaba and FrSky receivers.

## S.Bus, as LANE Boys RC understands it

(Source: https://quadmeup.com/generate-s-bus-with-arduino-in-a-simple-way/)

* The serial port uses 100000 BAUD, 8 bits, even parity, 2 stop bits (!)
* There is also a fast mode that uses 200000 BAUD, 8 bits, even parity, 2 stop bits (The light controller will not support this mode)
* Packets containing servo information are sent at regular intervals of about 10-20ms (FrSky: 6ms Futaba/FrSky fast mode: 3ms)
* When the connection with the Transmitter is broken, the receiver sets a FAILSAFE flag in the packet

* A packet is always 25 bytes long and contains the following information:
    * 1 byte HEADER
    * 22 bytes payload for 16 servo channels (11 bits per channel; packed)
    * 1 byte bit-field payload containing:
        * Bit 0: channel 17
        * Bit 1: channel 18
        * Bit 2: lost frame
        * Bit 3: failsafe
    * 1 byte FOOTER or FOOTER 2

* The HEADER byte is 0x0f
* The FOOTER byte is 0x00
* The FOOTER2 byte is 0x4 or 0x8 (contents of the upper nibble is ignored, it contains a slot number for telemetry use)
* FOOTER is used in the original S.Bus protocol, while S.Bus2 changed to FOOTER2.
* The upper nibble of FOOTER2 contains a slot number used for telemetry (see _Example packets_ below).

* The servo information is 11 bits per channel
    Channel values describe the servo pulse duration from 0..2047

        servo_us = (5 * sbus / 8) + 880;

## Impact of S.Bus support on the light controller

The S.Bus system uses an inverted UART signal (idle=low).

The LPC812 and LPC832 do not support inverted UART, hence S.Bus can not be supported without additional hardware.
(It would be possible to support "inverted SBUS" (idle=high), but as stated above this may not be useful due to lack of receiver support).

For the Mk4P and Mk4S PCB we could integrate an inverter (1 MosFET, 1 Resistor) and route the inverted UART signal to an unused pin (e.g. GPIO10). The software could then route the UART RX line to GPIO10 if S.Bus is configured.

For the user this means that only newer revisions of the Mk4P light controller (Rev3) can support S.Bus.

The Baudrate used by S.Bus is 100000. This is a non-standard Baudrate, but it should be possible with the LPC8xx microcontroller. However, in case a Slave is used the Baudrate of the Slave would also have to be 100000 Baud.

The WebUSB programmer and the CH340G chip used in the USB-to-Serial dongle do neither support 100000 Baud nor the inverted UART signal. It will therefore not possible to implement the "Testing" function in the Configurator for S.Bus.

## Example packets

(Source: https://github.com/mikeshub/FUTABA_SBUS/blob/master/FUTABA_SBUS/FUTABA_SBUS.cpp):

```
0x0f 0x01 0x04 0x20 0x00 0xff 0x07 0x40 0x00 0x02 0x10 0x80 0x2c 0x64 0x21 0x0b 0x59 0x08 0x40 0x00 0x02 0x10 0x80 0x00 0x00
```

(Source: https://www.rcgroups.com/forums/showthread.php?2420473-Arduino-S-BUS-Packet-Generator-Code)

```
0x0f 0x5c 0x91 0x26 0x37 0x7f 0xa4 0x6a 0xab 0x00 0x10 0x80 0x00 0x04 0x20 0x00 0x01 0x08 0x70 0x00 0x02 0x10 0x80 0x0c 0x00
```

S-Bus data sent from Futaba R7008SB in "FASSTest 14ch" mode:
```
0x0f 0x04 0x1c 0xa1 0x43 0x09 0x48 0x40 0x04 0x7a 0x10 0x2c 0x00 0x04 0x20 0x58 0xc0 0x13 0x07 0x38 0x00 0x10 0x80 0x00 0x04
0x0f 0x04 0x1c 0xa1 0x43 0x09 0x48 0x40 0x04 0x7a 0x10 0x2c 0x00 0x04 0x20 0x58 0xc0 0x13 0x07 0x38 0x00 0x10 0x80 0x00 0x14
0x0f 0x04 0x1c 0xa1 0x43 0x09 0x48 0x40 0x04 0x7a 0x10 0x2c 0x00 0x04 0x20 0x58 0xc0 0x13 0x07 0x38 0x00 0x10 0x80 0x00 0x24
0x0f 0x04 0x1c 0xa1 0x43 0x09 0x48 0x40 0x04 0x7a 0x10 0x2c 0x00 0x04 0x20 0x58 0xc0 0x13 0x07 0x38 0x00 0x10 0x80 0x00 0x34
```

S-Bus data sent from Futaba R7008SB in FASSTest 12CH mode (packets may be in shorter intervals):
```
0x0f 0x00 0x1c 0x20 0x5b 0x09 0x08 0xc0 0x13 0x7a 0x10 0x2c 0x00 0x04 0x20 0x00 0x01 0x08 0x40 0x00 0x02 0x10 0x80 0x00 0x08
0x0f 0x00 0x1c 0x21 0x59 0x09 0x08 0xc0 0x13 0x7a 0x10 0x2c 0x00 0x04 0x20 0x00 0x01 0x08 0x40 0x00 0x02 0x10 0x80 0x00 0x08
0x0f 0x00 0x1c 0x21 0x5b 0x09 0x08 0xc0 0x13 0x7a 0x10 0x2c 0x00 0x04 0x20 0x00 0x01 0x08 0x40 0x00 0x02 0x10 0x80 0x00 0x08
0x0f 0x00 0x1c 0x21 0x5b 0x09 0x08 0xc0 0x13 0x7a 0x10 0x2c 0x00 0x04 0x20 0x00 0x01 0x08 0x40 0x00 0x02 0x10 0x80 0x00 0x08
0x0f 0x00 0x1c 0x21 0x59 0x09 0x08 0xc0 0x13 0x7a 0x10 0x2c 0x00 0x04 0x20 0x00 0x01 0x08 0x40 0x00 0x02 0x10 0x80 0x00 0x08
```

S-Bus output from FrSky TFR8SB receiver in FASST-MULTI mode:
```
0x0f 0x04 0x1c 0xa1 0x43 0x0b 0x48 0x40 0x04 0x7a 0x10 0x2c 0x00 0x04 0x20 0x58 0xc0 0x13 0x07 0x38 0x00 0x10 0x80 0x00 0x00
0x0f 0x04 0x1c 0xa1 0x43 0x0b 0x48 0x40 0x04 0x7a 0x10 0x2c 0x00 0x04 0x20 0x58 0xc0 0x13 0x07 0x38 0x00 0x10 0x80 0x00 0x00
0x0f 0x04 0x1c 0xa1 0x43 0x0b 0x48 0x40 0x04 0x7a 0x10 0x2c 0x00 0x04 0x20 0x58 0xc0 0x13 0x07 0x38 0x00 0x10 0x80 0x00 0x00
0x0f 0x04 0x1c 0xa1 0x43 0x0b 0x48 0x40 0x04 0x7a 0x10 0x2c 0x00 0x04 0x20 0x58 0xc0 0x13 0x07 0x38 0x00 0x10 0x80 0x00 0x00
```

## Open points:

* There is conflicting info about the meaning of the servo channel value range.

Is 1024 center? https://github.com/mikeshub/FUTABA_SBUS/blob/master/FUTABA_SBUS/FUTABA_SBUS.cpp
Or 992? https://quadmeup.com/generate-s-bus-with-arduino-in-a-simple-way/

BetaFlight uses the following formula to convert S.Bus servo information to microseconds (servo pulse):
servo_us = (5 * sbus / 8) + 880;

Using this formula would make S.Bus value 1024 translate to 1520 us, which is exactly what Futaba traditionally used as center value for servos.

But how does FrSky map the S.Bus values? Most likely they are using 1500 as center, hence the 992 value.

* What are the possible values for FOOTER2?

https://github.com/cleanflight/cleanflight/issues/590#issuecomment-101027349
https://github.com/cleanflight/cleanflight/issues/590#issuecomment-101706023

* Frame detection

Most libraries seem to use HEADER and FOOTER/FOOTER2 to detect frames. Those libraries will not work with the FASSTest 12CH mode, which uses 0x08 last byte.

BetaFlight uses the maximum frame time of 3000 us + 500 us margin. If the time since the last byte is more than 3500us then a start of frame is assumed. This will only work with interrupt-driven UART receive.
(Source: https://github.com/betaflight/betaflight/blob/master/src/main/rx/sbus.c)

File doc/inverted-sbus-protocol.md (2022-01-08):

# Inverted SBUS

S.Bus is a proprietary protocol developed by Futaba.
(Dead link: https://www.futabarc.com/sbus/index.html)

S.Bus2 is an extension that supports telemetry.

Some receivers on the market now output an "inverted SBUS" signal.

## Inverted SBUS, as LANE Boys RC understands it

(Source: https://quadmeup.com/generate-s-bus-with-arduino-in-a-simple-way/)

The original S.Bus system uses an inverted UART signal (idle=low).
The LPC812 and LPC832 do not support inverted UART, hence S.Bus can not be supported.

However, "inverted SBUS" as output by some receivers uses the traditional UART polarity (idle=high), which can be used with the Light Controller.

The Baudrate is 100000. This is a non-standard Baudrate, which is not supported by the WebUSB programmer or the CH340G chip in the USB-to-Serial dongle. This means that the test function can not be used with "inverted SBUS".

* The serial port uses 100000 BAUD, 8 bits, even parity, 2 stop bits (!)
* There is also a fast mode that uses 200000 BAUD, 8 bits, even parity, 2 stop bits (The light controller will not support this mode)
* Packets containing servo information are sent at regular intervals of about 10-20ms (FrSky: 6ms Futaba/FrSky fast mode: 3ms)
* When the connection with the Transmitter is broken, the receiver sets a FAILSAFE flag in the packet
* A packet is always 25 bytes long and contains the following information:
    * 1 byte HEADER
    * 22 bytes payload for 16 servo channels (11 bits per channel)
    * 1 byte bit-field payload containing:
        * Bit 0: channel 17
        * Bit 1: channel 18
        * Bit 2: lost frame
        * Bit 3: failsafe
    * 1 byte FOOTER or FOOTER 2

* The HEADER byte is 0x0f
* The FOOTER byte is 0x00
* The FOOTER2 byte is 0x4 or 0x8 (contents of the upper nibble is ignored, it contains a slot number for telemetry use)
* The servo information is 11 bits per channel
    Channel values describe the servo pulse duration from 0..2047

* FOOTER may have been used in S.Bus, while later S.Bus2 changed to FOOTER2. The upper nibble of FOOTER2 seems to contain a sequence number (see _Example packets_ below).

## Example packets

(Source: https://github.com/mikeshub/FUTABA_SBUS/blob/master/FUTABA_SBUS/FUTABA_SBUS.cpp):

```
0x0f 0x01 0x04 0x20 0x00 0xff 0x07 0x40 0x00 0x02 0x10 0x80 0x2c 0x64 0x21 0x0b 0x59 0x08 0x40 0x00 0x02 0x10 0x80 0x00 0x00
```

(Source: https://www.rcgroups.com/forums/showthread.php?2420473-Arduino-S-BUS-Packet-Generator-Code)

```
0x0f 0x5c 0x91 0x26 0x37 0x7f 0xa4 0x6a 0xab 0x00 0x10 0x80 0x00 0x04 0x20 0x00 0x01 0x08 0x70 0x00 0x02 0x10 0x80 0x0c 0x00
```

S-Bus data sent from Futaba R7008SB in "FASSTest 14ch" mode:
```
0x0f 0x04 0x1c 0xa1 0x43 0x09 0x48 0x40 0x04 0x7a 0x10 0x2c 0x00 0x04 0x20 0x58 0xc0 0x13 0x07 0x38 0x00 0x10 0x80 0x00 0x04
0x0f 0x04 0x1c 0xa1 0x43 0x09 0x48 0x40 0x04 0x7a 0x10 0x2c 0x00 0x04 0x20 0x58 0xc0 0x13 0x07 0x38 0x00 0x10 0x80 0x00 0x14
0x0f 0x04 0x1c 0xa1 0x43 0x09 0x48 0x40 0x04 0x7a 0x10 0x2c 0x00 0x04 0x20 0x58 0xc0 0x13 0x07 0x38 0x00 0x10 0x80 0x00 0x24
0x0f 0x04 0x1c 0xa1 0x43 0x09 0x48 0x40 0x04 0x7a 0x10 0x2c 0x00 0x04 0x20 0x58 0xc0 0x13 0x07 0x38 0x00 0x10 0x80 0x00 0x34
```

S-Bus data sent from Futaba R7008SB in FASSTest 12CH mode (packets may be in shorter intervals):
```
0x0f 0x00 0x1c 0x20 0x5b 0x09 0x08 0xc0 0x13 0x7a 0x10 0x2c 0x00 0x04 0x20 0x00 0x01 0x08 0x40 0x00 0x02 0x10 0x80 0x00 0x08
0x0f 0x00 0x1c 0x21 0x59 0x09 0x08 0xc0 0x13 0x7a 0x10 0x2c 0x00 0x04 0x20 0x00 0x01 0x08 0x40 0x00 0x02 0x10 0x80 0x00 0x08
0x0f 0x00 0x1c 0x21 0x5b 0x09 0x08 0xc0 0x13 0x7a 0x10 0x2c 0x00 0x04 0x20 0x00 0x01 0x08 0x40 0x00 0x02 0x10 0x80 0x00 0x08
0x0f 0x00 0x1c 0x21 0x5b 0x09 0x08 0xc0 0x13 0x7a 0x10 0x2c 0x00 0x04 0x20 0x00 0x01 0x08 0x40 0x00 0x02 0x10 0x80 0x00 0x08
0x0f 0x00 0x1c 0x21 0x59 0x09 0x08 0xc0 0x13 0x7a 0x10 0x2c 0x00 0x04 0x20 0x00 0x01 0x08 0x40 0x00 0x02 0x10 0x80 0x00 0x08
```

S-Bus output from FrSky TFR8SB receiver in FASST-MULTI mode:
```
0x0f 0x04 0x1c 0xa1 0x43 0x0b 0x48 0x40 0x04 0x7a 0x10 0x2c 0x00 0x04 0x20 0x58 0xc0 0x13 0x07 0x38 0x00 0x10 0x80 0x00 0x00
0x0f 0x04 0x1c 0xa1 0x43 0x0b 0x48 0x40 0x04 0x7a 0x10 0x2c 0x00 0x04 0x20 0x58 0xc0 0x13 0x07 0x38 0x00 0x10 0x80 0x00 0x00
0x0f 0x04 0x1c 0xa1 0x43 0x0b 0x48 0x40 0x04 0x7a 0x10 0x2c 0x00 0x04 0x20 0x58 0xc0 0x13 0x07 0x38 0x00 0x10 0x80 0x00 0x00
0x0f 0x04 0x1c 0xa1 0x43 0x0b 0x48 0x40 0x04 0x7a 0x10 0x2c 0x00 0x04 0x20 0x58 0xc0 0x13 0x07 0x38 0x00 0x10 0x80 0x00 0x00
```

## Open points:

* There is conflicting info about the meaning of the servo channel value range.

Is 1023 center? https://github.com/mikeshub/FUTABA_SBUS/blob/master/FUTABA_SBUS/FUTABA_SBUS.cpp
Or 992? https://quadmeup.com/generate-s-bus-with-arduino-in-a-simple-way/

BetaFlight uses the following formula to convert S.Bus servo information to microseconds (servo pulse):
servo_us = (5 * sbus / 8) + 880;

Using this formula would make S.Bus value 1023 translate to 1520 us, which is exactly what Futaba traditionally used as center value for servos.

But how does FrSky map the SBUS values? Most likely they are using 1500 as center

* What are the possible values for FOOTER2?

https://github.com/cleanflight/cleanflight/issues/590#issuecomment-101027349
https://github.com/cleanflight/cleanflight/issues/590#issuecomment-101706023

* Frame detection

Most libraries seem to use HEADER and FOOTER/FOOTER2 to detect frames. Those libraries will not work wiht the FASSTest 12CH mode, which uses 0x08 last byte.

BetaFlight uses the maximum frame time of 3000 us + 500 us margin. If the time since the last byte is more than this 3500us then a start of frame is assumed. This will only work with interrupt-driven UART receive.
(Source: https://github.com/betaflight/betaflight/blob/master/src/main/rx/sbus.c)

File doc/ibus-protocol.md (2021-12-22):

# i-Bus

FlySky now offers surface receivers that use the new AFHDS3 protocol and support i-Bus output.

i-Bus support in the Light Controller allows users to use a single servo cable between receive and Light Controller, without the need for a Pre-Processor.

## i-Bus specification

Unfortunately there does not appear to be a formal specification of i-Bus.

To make things worse, in February 2020 FlySky modified the data format of how i-Bus transmits servo information to cram an additional 4 channels into the same packet. This change breaks many existing i-Bus library, e.g. on Arduino.

## i-Bus, as LANE Boys RC understands it

Anyway, the Light Controller supports i-Bus protocol with the following understanding of the data structure:

* The baudrate is 115200
* Packets containing servo information are sent at regular intervals of about 7-8ms
* When the connection with the Transmitter is broken, the receiver stops outputing servo packets
* A servo packet is up to 32 bytes long and comprises the following information
    * 1 byte packet length
    * 1 byte packet ID
    * Up to 28 bytes of payload
    * 2 bytes checksum (little-endian uint16_t)
* The packet ID for servo packets is 0x40
* The checksum is the sum of all bytes (!) XOR 0xffff
* The servo payload is as follows:
    * Byte 3 (first payload byte): CH1[0..7]
    * Byte 4 CH15[0..3], CH1[8..11]
    * Byte 5 CH2[0..7]
    * Byte 6 CH15[4..7], CH2[8..11]
    * Byte 7 CH3[0..7]
    * Byte 8 CH15[8..11], CH3[8..11]
    * Byte 9 CH4[0..7]
    * Byte 10 CH16[0..3], CH4[8..11]
    * Byte 11 CH5[0..7]
    * Byte 12 CH16[4..7], CH5[8..11]
    * Byte 13 CH6[0..7]
    * Byte 14 CH16[8..11], CH4[8..11]
    * Byte 15 CH7[0..7]
    * Byte 16 CH17[0..3], CH7[8..11]
    * Byte 17 CH8[0..7]
    * Byte 18 CH17[4..7], CH8[8..11]
    * Byte 19 CH9[0..7]
    * Byte 20 CH17[8..11], CH9[8..11]
    * Byte 21 CH10[0..7]
    * Byte 22 CH18[0..3], CH10[8..11]
    * Byte 23 CH11[0..7]
    * Byte 24 CH18[4..7], CH11[8..11]
    * Byte 25 CH12[0..7]
    * Byte 26 CH18[8..11], CH12[8..11]
    * Byte 27 CH13[0..7]
    * Byte 28 CH13[8..11]
    * Byte 29 CH14[0..7]
    * Byte 30 CH14[8..11]
    Channel values describe the servo pulse duration in microseconds (e.g. 1500 = 0x5dc = center)

## Example packet

(Source: https://basejunction.wordpress.com/2015/08/23/en-flysky-i6-14-channels-part1):

```
0x20 0x40 0xdc 0x05 0xdb 0x05 0xef 0x03 0xdd 0x05 0xd0 0x07 0xd0 0x07 0xdc 0x05 0xdc 0x05 0xdc 0x05 0xdc 0x05 0xdc 0x05 0xdc 0x05 0xdc 0x05 0xdc 0x05 0x54 0xf3
```

We have received a capture from a Saleae logic analyzer from a kind light controller user.

*i-bus_capture_from_flysky_receiver_saleae_format.sal*
Is the captured file, can be opened in the Saleae "logic" tool.

*i-bus_capture_from_actual_receiver_in_salee_format.bin*
Contains the i-Bus serial communication exported by "logic" in "binary format". See https://support.saleae.com/faq/technical-faq/binary-export-format-logic-2 for information how to decode this format.

*i-bus_decoder_for_saleae_format.py* is a tool that decodes the binary format expecting a UART signal at 115200 BAUD n-8-1

*i-bus_decoded_packets.py_or_js* is the result of running *i-bus_capture_from_actual_receiver_in_salee_format.bin* through *i-bus_decoder_for_saleae_format.py*. It contains the i-Bus packets as captured from the FlySky receiver. It has movement data on the first 4 channels.

## Channel mapping

The FlySky NB4 transmitter is an 8 channel transmitter that ships with a 4-channel receiver.

Walter from Austria suggested to be able to map the AUX channels to channels 5 and up, so that the lower 4 channels are exclusive for the receiver (ST and TH of the light controller still map to channel 1 and 2).
What would be simple to do is be able to select the mapping of AUX from CH3 to CH12. AUX2 and AUX3 would then always be the subsequent channels of AUX.
(We go until CH12 only because CH15 and up require complicated bit mangling, while channels 1..14 can be accessed via offset directly)

David from Newzealand wrote:

> What I had not noticed is that on the flysky you can bind a receiver starting at any chan number you choose, so I should be able to run a 4ch receiver without having to change to an 8 chan one to drive the lights.

> Currently all are used on the 4 chan
* 1 Thr
* 2 St front
* 3 St rear
* 4 Dig

> However I can bind it to be
* 6 thr
* 7 st front
* 8 st rear
* 9 dig

> Then mirror 6 to 1 and 7 to 2 on the transmitter
That leaves ibus 3-5 free for aux1-3 function

This would be an alternative solution, but heavily depends on the transmitter implementation.
We will therefore implement Walters suggestion as it is more universal.

## Open points:

* Is the servo packet always 32 bytes long, or can there be less servo data if the transmitter supports less than 14 channels?
    * Our implementation supports variable length servo packets up to a maximum of 32 bytes.
    * The minimum servo packet length must be 6 (payload count, packet ID, checksum, 2 bytes for 1 channel)
    * The servo packet length must be even

* What is the valid range of channel values?
    * We follow the same values as we use for our "servo reader"

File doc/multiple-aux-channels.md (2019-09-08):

# Request to support multiple AUX channels

Modern RC car transmitter support 4 or 5 channels. A few light controller users issued the request to support these additional AUX channels for light switching function, as to make operation easier than the current clicking of CH3/AUX.

## Discussion

The easiest way to implement this request is via a new version of the preprocessor.

In order to keep software-compatibility with the light controller, we can only use pins that are currently unused:

PIO0_5  (3, RESET)
PIO0_8  (11, XTAL-IN)
PIO0_10 (8, open drain)
PIO0_11 (7, open drain)

For safety reasons we will not use the reset pin.

PIO0_8 can be used as normal IO and is therefore ideal.
PIO0_10 and PIO0__11 can be used as inputs, but a pull-up or pull-down resistor is required as they are true open drain pins.

In theory we can therefore support a maximum of 4 AUX channels.

1) Adding 3 more AUX channels, each on its own standard 3-pin servo header, would add about 7.6mm to the preprocessor (29 mm instead of 21 mm)
2) Adding 2 AUX channels on a standard 3-pin servo header would add 5.1 mm (26 mm instead of 21 mm)
3) Adding 1 AUX channel. This would add 2.54 mm (24mm instead of 21 mm)
4) Adding 3 AUX channels on one 3-pin header (signal only) would add 2.54 mm (24mm instead of 21 mm)

Option 4 provides the most inputs at the least additional space, but has the disadvantage that the new AUX pin header has a different pin-out. If the user accidentally plugs in a receiver channel into the AUX pin header the MCU may get damaged (plus pole on middle pin!) The user also must use 1 pole Dupont pins, which don't hold well mechanically and may come off too easily.

Option 1 makes the preprocessor very large, and may get into mechanical issues with the servo plugs, which extend slightly on the top.

Therefore it may be best to go for option 2: 2 additional AUX channels on a standard 3-pin servo header => 5-channel preprocessor

AUX2: PIO0_8 (11, XTAL-IN)
AUX3: PIO0_11 (7, open drain)

## Features

* Fully backwards compatible with the light controller software
* Configurable functions, using UI method from Betaflight
    * Multi-function switch as per today's CH3/AUX
    * Gearbox function 1/2/3 (depends on gear configuration)
    * Winch off/in/out
    * Servo control on OUT/ISP
    * Manual indicators left/off/right
    * Hazard lights on/off
    * Light switch (servo range mapped to n positions)
* Supported actuators:
    * Two-position switch
    * Two-position switch with up/down buttons
    * Momentary push button
    * Three-position switch
    * Analog or multi-position switch
* Light programs can read AUX position

Two-position switch, Two-position switch with up/down buttons and Momentary push button are technically all of type two-position actuator.

```
       | Toggle   Gear   Winch   Ind   Hazard   Light   Servo
       | ----------------------------------------------------
2-pos  | toggle   gear1  winch1  N/A   on/off   N/A     servo
3-pos  | N/A      gear2  winch2  ind   on/off   light2  servo
n-pos  | N/A      gear2  winch2  ind   on/off   light2  servo
```

gear1: if 2 gears, direct selection; if 3 gears: 1-click=up, 2-click=down
gear2: direct selection with hysteresis
winch1: as per current operation
winch2: direct off/in/out operation
light2: the servo range 1000..2000us is mapped to n light switch sections. Note that for 3-pos switch this could mean that not all are adjustable.
servo: direct output mapping -100..0..+100 to 1000..1500..2000 us servo output (adjust endpoints on TX)

TO REDUCE EFFORT, WE WON"T BE IMPLEMENTING GEARBOX AND WINCH CONTROL FOR NOW.

Note that the combination of 2-pos and Light is not used (N/A) because we rather apply the full toggle operation in that case.

All switch actions are only executed upon switch change. This allows e.g. controlling the hazard lights from both the usual 2-pos toggle function, but also from a manual switch at the same time. Or there can be multiple switches assigned to 'toggle'.
After initialization the manual functions are applied immediately.

When the preprocessor input is active, the light controller always supports a hardware push-button the CH3/AUX input. It always serves as 'toggle' button for all functions.

When indicator control is assigned to an AUX channel then automatic indicators are disabled.

## Local buttons vs servo inputs

In theory we could make each servo input also be configurable as local momentary button -- except for AUX3 which has a pull-down.

When configured as SERVO_READER, the AUX inputs can be chosen as servo inputs or local buttons. But this would only be working for CH3/AUX anyway as the Mk4 hardware does not expose the pins.
On the preprocessor this would require additional configuration, and we create diversity in preprocessor firmware. Plus the light controller would have to match, otherwise conflicts could occur.

When configured as UART_READER, we could in theory have local buttons as well as servo inputs via the UART. (Obviously only for custom HW where the light controller exposes the AUX servo pins). However, we would have to configure the local buttons and the 'remote' buttons separately.

All this adds a lot of complexity, and is difficult to understand and implement.

We will therefore only support the old `ch3_is_local_switch`. It will only be active for the light controller, not for the preprocessor. Note that the local switch is always momentary!

## Configurator user interface

For each AUX channel, the user can specify the actuator type and which of the available functions it should control.

We need to add preprocessor and multi-aux preprocessor to the configuration list, so we can show the appropriate number of AUX channels.

## Architecture questions

* Can we extend the preprocessor protocol easily with 2 (3) more channels?
    * Yes, by setting the unused bit 3 in the 4th byte we can signal that more data follows. Old light controllers ignore that bit (incl. ancient MK2) and the trailing data.
    * We send 3 additional bytes for AUX, AUX2 and AUX3. Data is always -100..100  corresponding to 1000..2000 us pulse width (= no auto EPA)
    * Need to update the preprocessor-reader and preprocessor-simulator tools
* Can 34800 BAUD support the additional data?
    * Yes, 7 Bytes take only 200 us @38400 BAUD
* One additional AUX channel could be handled with the 4th capture input. For further inputs we need to multiplex the respective input
* How to setup the light controller if there is no CH3/AUX toggle function assigned?
    - We always do local button on CH3 if master with uart-reader
* Arbitration of functions
* What happens if a user loads a preprocessor firmware that supports multi_aux? 
    - It would show up as Master, servo reader with multi_aux turned on, which is not a supported hardware configuration.
    - Whenever we change mode to SERVO_READER, we should clear multi_aux But when loading the firmware, we accept SERVO_READER and multi_aux being set! This way someone with custom hardware can use that trick to create a servo reader with multi_aux functionality

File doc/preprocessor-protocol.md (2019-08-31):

# Preprocessor UART protocol

The preprocessor runs at either 38400 or 115200.

Usually 115200 should be used, but 38400 is still available to use nRF24LE1 which can only output at 38400. Also use of the LANE Boys RC winch controller requires 38400.

## Protocol details

The first byte is always 0x87, which indicates that it is a start byte. No other byte can have this value.
Note: values 0x80..0x87 do not appear in the other bytes by design, so those can be used as first byte to indicate start of a packet.

The second byte is a signed char of the steering channel, from -100 to 0 (Neutral) to +100, corresponding to the percentage of steering left/right.

The third byte is a signed char of the throttle channel, from -100 to 0 (Neutral) to +100.

The fourth byte holds CH3 position information in bit 0, and bit 4 indicates whether the preprocessor is initializing.
Note that bits 5..7 must be zero for backwards compatibility with the MK2 lightcontroller.
Bits 1..3 are unused and are set to 0 by the preprocessor.

Example:

    [0x87] [ST] [TH] [0b000_I_000_C]

Where *ST* is the steering value -100..0..+100%, *TH* is the throttle value -100..0..+100%, *I* is 1 when the preprocessor is initializing, otherwise 0; and *C* indicates the position of the CH3 two-position switch.

## Extension for 5-channel radios

Given the description of the legacy protocol, we can use any of the unused bits 1..3 in the 4th byte of the transfer to indicate whether additional channel follow.

We choose bit 3: when set to 1 the light controller knows to expect data to follow for additional AUX channels.
Furthermore, we also add normalized data for CH3, so that CH3/AUX can be used with any of the new functions introduced with the multi-aux-channel support (e.g. 3-position switch ...).

The values appended for the AUX channel are signed char with the range of -100..0..+100. The channels are normalized to a corresponding servo signal of 1000..1500..2000 us.
Note that this normalization is different than ST and TH, where the normalization is dynamic, as to compensate for end-point adjustments in the transmitter.

Example:

    [0x87] [ST] [TH] [0b000_I_100_C] [CH3] [AUX2] [AUX3]

The first 3 bytes are identical as described above.
The 4th byte has bit 3 set to 1 to indicate that more channels follow.
CH3 is the normalized value for the CH3/AUX servo signal in the range of -100..0..+100%.
Likewise, AUX2 and AUX3 represent the normalized values for those inputs, range -100..0..+100%.

Light controllers who don't understand the extended format will continue to function properly and simply ignore the CH3, AUX2 and AUX3 values.

Note that 7 Bytes at 38400 BAUD take about 200 us to transfer, so no issue timing-wise even at high servo refresh rates.

## HK310 expansion protocol

Note: this section is obsolete, it was an experiment to transmit addition data via the CH3 information without having to change the transmitter firmware. Please ignore.

The protocol was extended with a 5th byte, holding the normalized 6-bit value of CH3 as used in the HK310 expansion protocol. The light controller simply ignored this data.

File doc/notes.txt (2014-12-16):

This document contains various architecture related documentation that
were written during early stages of development.

=============================================================================
NOTE: Steering channel vs. Steering wheel servo

The light controller can generate an output signal that can be connected to
a servo; this servo may drive a steering wheel in the body of the RC car to
make it look as if the driver is actually driving the car.
In the context of the light controller this function is called "steering wheel
servo".

The "Steering wheel servo" is independent of "steering". "steering", or
"steering channel" refers to the servo output on your receiver, usually
channel 1, that connects to the servo that changes direction on your vehicle.
"steering" is abbreviated as ST.

Having an independent "steering wheel servo" output allows to setup
centre, endpoints and direction on the steering wheel independent of the
needs for your car's steering.
=============================================================================

There are difference implementations of CH3 (AUX) that can be found in RC car
transmitters:

- Hard switch: on/off positions (i.e. HK 310, Turnigy 3XS)

- Toggle button: press=on, press again=off (i.e. FlySky GT3B)

- Momentary button: press=on, release=off (Futaba 4PL)

Measuring the 3 servo channels:
===============================
The "Arduino OpenSourceLights" measure all 3 channels in turn, with a
21 ms timeout. This means worst one needs to wait 3 "rounds" each 20ms
until all 3 channels have been measured. That's 60 ms, which is still very
low (usually tact switches are de-bounced with 40 ms).

So the pseudo code should look like:

    main
        wait for CH3 = Low
        wait for CH3 = High
        start TMR1
        wait for CH3 = Low
        stop TMR1
        save CH1 timing value

        (repeat for CH2, CH1 (if present))

        process channels
        switch lights according to new mode
        send lights and steering to slave via UART (3 bytes)

        goto main

On newer MCUs the timer hardware can "capture" the pulse width on an external
IO. This is preferred as it is more precise.
The PIC16F1825 can only measure one GPIO. The LPC812 can measure all 3 channels
at the same time, independently.

Robustness matters:
===================
A servo signal should come every 20 ms. OpenSourceLights says in their
comment that they meassured "~20-22ms" between pulses. So for the safe
side let's assume that worst case we wait 25 ms for a servo pulse.

Modern digital RC receivers output a servo pulse even if the connection to the
transmitter is lost. Therefore the light controller can not signal that
failsafe has triggered.

Discussion on the protocol to use between the master and the slave:
AKA: pre-processor protocol
===================================================================

First, CPPM was considered.
Each pulse is 300us,
Data: 1000-2000 us full range, 1500 us = center (includes pulse width!)
    Allow for: 770-2350 us
Repeated every 20ms
=> 8 channels worst case: 8 * 2100 us =  16800 us
=> space between transmissions minimum: -20000 = 3200 us
=> 9 channels don't fit!

We are dealing with 3 RC channels. A channel has a signal of max 2.1 ms
that is repeated every 20 ms. Hoever, there is no specification in which
sequence and with which timing the receiver outputs the individual channels.
Worst case there is only 6.85 ms between the channels. As such we can
not send the PPM signal synchronously between reading the channels with a
pure software approach.

Using interrupts may be critical too, as we need precision. Lets assume we
want to divide the servo range of 1 ms to 2 ms in 200 steps (100% in each
direction as e.g. EPA in transmitters works). This requires a resolution
of 5 us -- which is just 5 instruction cycles (1 MHz instruction clock).
No way to finish processing interrupts this way.

UART approach:
==============
UART at 38400 BAUD is fast enough to send 3 bytes between measuring servo
pulses.

UART protocol for the TLC5916 based master/slave design:
========================================================
3 Bytes: SYNC, Lights, Lights-half, ST
    SYNC:       Always 0x80..0x87, which does not appear in the other values
                If a slave receives 0x87 the data is processed.
                If the value is 0x86..0x80 then it increments the value
                by 1 and sends all 3 received bytes at its output.
                This provides us with a simple way of daisy-chaining
                several slave modules!
                Note: Currently the software only drives a single slave.
    Lights:     Each bit indicates a different light channel (0..6)
    Lights-half:Each bit indicates a different light channel (0..6) for
                outputs that shall be on in half brightness. Note that if
                the same bit is set in "Lights" then the output will be
                fully on (i.e. full brightness takes precedence over half
                brightness).
    ST:         Steering wheel servo data: -120 - 0 - +120

Flashing speed for hazard and indicators:
=========================================
1.5 Hz = 333 ms per half-period

Auto configuration:
===================
In order to avoid having to setup the light controller manually every time
something is changed on the vehicle RC system, automatic configuration
shall be employed.

The assumption is that both throttle and steering are in Neutral on power
on. So at startup we measure the servo signals and treat them as neutral.

The end-points are set to 200us (configurable throught INITIAL_ENDPOINT_DELTA)
initially and "grow" when servo signals are received that are larger than
the current value (up to the maximum of 800 and 2300 us respectively where
we clamp servo signals).

Depending on your servo and ESC installation, the servo and throttle may
be reversed.
In the original design we had throttle and steering direction auto-detect.
It was assumed that the user pushes the throttle forward and the steering
to left as first operation after powering up the car.
In practice this caused confusion for some users, and we resorted to store
the servo reversing persistently.
Servo reversing is configured by performing 7 clicks on CH3, then pushing
the throttle forward and the steering to the direction of the indicators
that light up.

TX/RX system findings:
======================
In general the jitter is 3 us, which is expected given that it takes about
3 instructions (PIC16F628 at 4 MHz) to detect a port change and start/stop
the timer.

GT3B:
    EPA can be +/- 120 %
    Normal range (trim zero, 100% EPA): 986 .. 1568 .. 2120
    Trim range: 1490 .. 1568 .. 1649  (L30 .. N00 .. R30)
    Worst case with full EPA and trim: 870 .. 2300 (!)
    Failsafe: Servo signal holds for about 500ms, then ST and CH3 stops and
      TH outputs 1500us (configurable?)
    CH3: 1058, 2114

    Output sequence: TH, ST, CH3 (measured on HK-GT2R receiver). There is about
    2us gap between the channels

    The repeat frequency of servo pulses is about 18.5 ms.

    The receiver internally operates at 3.3V and has a simple boost converter
    that generates 5V if the input voltage is lower than 5V before feeding
    the 3.3V LDO.

HK-310:
    EPA can be +/- 120 %
    Normal range (sub-trim and trim zero, 100% EPA): 1073 .. 1568 .. 2117
    Sub-Trim range: 1232 .. 1565 .. 1901  (-100 .. 0 .. 100)
    Trim range: 1388 .. 1568 .. 1745
    Worst case with full EPA and sub-trim and trim: 779 .. 2327 (!)
    Failsafe: Continously sends ST centre, TH off, CH3 holds last value
    CH3: 1013 = AUX, 2120 = OFF

    By default all channels are set to "REV" strangely. This means:
    ST: left means smaller values
    TH: fwd means larger values
    CH3: AUX means small value, OFF means large value (note: it is easy to
            place in the switch physically in both directions when assembling
            the transmitter, so different HK310 may have this reversed ...

    The repeat frequency of servo pulses is 16 ms (precisely) = 62.5 Hz.
    The order of which they are sent is ST, TH, CH3. There is a gap of 100 ns
    between the channel outputs.

        => This means we can change our algorithm: we can read the channels
        in sequence, when one is finished, we treat it as start for the
        next one.

    When the receiver is powered on, the servo output stays high until the
    first valid transmitter command is received. If the signal is lost during
    normal operation, the receiver outputs the programmed failsafe values.

    When the transmitter is powered up, it sends "neutral" values for ST and TH,
    and the initial position of CH3 (apparently it reads this directly during
    power up). The real data based on actual ST/TH position is only sent
    after the transmitter has booted (= showing its main operating screen).
    The boot time seems to be approx 4 seconds.

    The pin on the battery connector outputs a strange pulse that is the
    combination of all 3 servo pulses. The signal is high when idle and
    low during the signal pulse. Its falling edge is 700 ns after the start
    (rising edge) of the ST output, its rising edge is 100 ns after the
    end (falling edge) of the CH3 output.

    The receiver internally operates at 3.3V and 2.5V. The servo outputs
    are 3.3V.

Futaba R2104GF:
    EPA can be +/- 120 %
    Normal range (sub-trim and trim zero, 100% EPA): 1000 .. 1500 .. 2000

    The repeat frequency of servo pulses is 6.8 ms = 147 Hz! This is
    "fast mode". The normal mode is 13.63 ms according to documentation.

    CH1 and CH2 start their pulse at exactly the same time. CH3 and CH4 start
    together 300 ns after CH1 and CH2.

    The receiver internally operates at 3V and 1.8V. It uses TI CC2500 RF chip
    and a MSP430 microprocessor with a 26 MHz crystal.

    The battery connector signal pin has a wire to it, but there is no signal.
    Voltage range is specified to being 3.5V - 8.4V.
    Size: 39 x 26 x 10 mm

Servo processing:
=================
Given the TX/RX findings above, we will design the light controller
to expect a servo range of 800 .. 1500 .. 2300 us (1500 +/-700 us).

    Everything below 600 will be considered invalid.
    Everything between 600 and 800 will be clamped to 800.
    Everything between 2300 and 2500 will be clamped to 2300
    Everything above 2500 will be considered invalid.
    Defaults are 1000 .. 1500 .. 2000 us

CH3 processing:
Implement a Schmitt-Trigger around the center between the endpoints.
Example:
    Switch pos 0: 1000 us
    Switch pos 1: 2000 us
    Center is therefore   (2000 + 1000) / 2 = 1500 us
    Hysteresis:           (2000 - 1000) / 8 = 125 us
    If last switch position was pos 0:
        measured timing must be larger than 1500 + 125 = 1625 us to accept
        as pos 1
    If last switch position was pos 1:
        measured timing must be larger than 1500 - 125 = 1375 us to accept
        as pos 0
Accuracy is not important as we are dealing with a switch. Therefore we can
only use bits 11..4 (16 us resolution), so we can deal with 8-bit
calculations instead of 16-bit calculations.

Steering and Throttle processing:
We have:
    EPL (end point left)
    EPR (end point right)
    REV (flag that indicates servo reversing)
    CEN (neutral position)
        Margin for neutral position: +/- 5%
        Some speed controlled can configure this from 4..8%
    POS (measured servo pulse length)
To make processing easier we ensure that
    EPL > CEN > EPR must be true
This can be achieved with the REV flag that indicates when a channel is
reversed.
By default we assume that
    Throttle forward is EPR, backward EPL
    Steering left is EPL, Steering right is EPR

We need to convert POS into a range of
    -100 .. 0 .. +100   (left .. centre .. right)

If POS == CEN:           We found dead centre
    POS_NORMALIZED = 0
Else
    If POS > CEN:    We are dealing with a right turn
        POS_NORMALIZED = calculate(POS, EPR, CEN)
        If REV
            POS_NORMALIZED = 0 - POS_NORMALIZED
    Else             We are dealing with a left turn
        POS_NORMALIZED = calculate(POS, EPL, CEN)
        If not REV
            POS_NORMALIZED = 0 - POS_NORMALIZED

caluclate:  (inputs are POS, EP(L or R), CEN)
    If EP > CEN:
        If POS > EP      Clamp invald input
            return 100
        POS_NORMALIZED = ((POS - CEN) * 100 / (EP - CEN))
    Else:                EP < CEN
        If POS < EP      Clamp invald input
            return 100
        POS_NORMALIZED = (CEN - POS) * 100 / (CEN - EP)

Timer:
======
We need a way to measure time, e.g. for double click detection of ch3 and
to derive the blink frequency. For the PIC16F628 will use TIMER0 for generating
a low, steady frequency. TIMER0 will be set in such a way that within a
worst-case mainloop it can only overflow once. This means we will be able to
accurately measure longer periods of time.

To do so we select a pre-scaler of 1:256. This gives us a timer clock of
256 us. This means that the timer overflows every 65.536 ms.
We will use T0IF to detect overflow.
The blink frequency of 1.5 Hz can be easily derived: a single period is
5 timer overflows (333 ms / 65.536 ms).
For ease of implementation we can have several 8-bit variables that are
incremented every 64.536 ms. E.g. we can have one for blinking, that is
reset after it reaches "5", which toggles the blink flag.
We can have another one that we reset when we receive a CH3 pulse and
want to determine multiple clicks.

For modern PIC chips that operate at higher frequencies than 4 MHz TIMER0
is too fast. We use TIMER2 (or 4, or 6) instead which has a post scaler.
At 32 MHz even TIMER2 overflows every 32.768ms, so we need an additional
software-divider to generate the 65.536ms.

Steering wheel servo:
=====================
To allow easy reconfiguration of the steering wheel servo the user has to
toggle the CH3 button 8 times. The steering channel will then directly drive
the steering wheel servo output, allowing the user to set the center
position. Toggling CH3 once switches to "left end point". The user can
use the steering channel to set the left end point of the steering wheel
servo. Note that this may mean that the user has to turn the steering
channel to the right in case of servo reversing is needed! The user
confirms with toggling CH3 again, switching to "right end point" mode.
Once this is set, toggling CH3 stores all values persistently and switches
back to normal operation.

The slave controller accepts inputs of -120..0..+120, which it translates
to servo pulses 780..1500..2220 us. (This scales easily by multiplying
the servo value by 6, offsetting by 1500!)
The scaling will be done in the master.
The master stores 3 values for the steering wheel servo: left, centre and
right. Each of those may contain a value in the range of -120 to +120.
If the "steering" variable is 0 then it sends the centre value.
If the "steering" variable has a positive value it sends the interpolated
value:

    right - centre * 100
    -------------------- + centre
        abs(steering)

Note this needs to be a signed operation! If "steering" is negative then
'right' is replaced with 'left' in the formula above.

Combined Tail/Brake/Indicators
==============================
In the 1970s some US cars had only a single red light in the back that
served as tail light, brake light and indicators all at the same time. At
least that is how I remember seeing it in movies.
The Tamiya XR311 also has only a single light for tail/brake/indicator (plus
and additional reversing light), so I had to implement this function.

Tail       | Brake     | Indicator || Output
off        | off       | on  | off || high | off
half       | off       | on  | off || high | half
off        | high      | on  | off || high | half
half       | high      | on  | off || high | half

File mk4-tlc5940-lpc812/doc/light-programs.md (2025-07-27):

# Light programs

Light programs are simple scripts that allow end-users to build custom light sequences that go beyond the fixed car related functions built into the Mk4 Light Controller.

Light programs can be triggered when the light controller goes into certain states of operation. For example, a light program can be written to flash a 3rd brake light whenever the brakes are enganged.

Light programs are entered into the corresponding edit field in the light controller [Configurator](https://laneboysrc.github.io/rc-light-controller/).

A total number of 20 light programs can exist at a certain time.

Here is a simple light program example:

    // ----------------------------------------------------------------------
    // Light up the main beam lights while the light controller is
    // initializing.
    //
    // Normally the main beam would be on only if the parking lights are
    // already on, so just the main beam lighting up is a unique
    // identifiaction.
    // ----------------------------------------------------------------------
    run when initializing

    use all leds
    led main-beam-l = led[2]
    led main-beam-r = led[3]

    loop:
        fade all leds stepsize 0
        all leds = 0%
        main-beam-l, main-beam-r = 100%
        sleep 0
        goto loop

    end

Everything from ``//`` until the end of the line is considered as comment.

The ``run when`` line describes the condition that the light controller must be in for the program to run. In this case the light program runs when the light controller is starting up (i.e. waiting a short time until power up until it reads the center points for steering and throttle channels).

``use all leds`` declares that no other light controller function shall control any of the LEDs while this light program is running. The lines ``led ... = led[y]`` assign human readable names to light outputs 2 and 3.

This ends the declaration section.

The ``loop:`` statement defines a label that can be used to jump to from a ``goto`` instruction.

``fade all leds stepsize 0`` turns slowly fading LEDs in and out off for all LEDs, i.e. all LEDs turn on and off in an instant.

Then all LEDs are switched off, after which led[2] and led[3] are specifically set to fully on (100% brightness).

The light program pauses then for one 20 ms period (``sleep 0``), which causes the LED values we assigned to be actually executed and other light controller functions to run.
Without the sleep statement the light program would run for 30 internal instructions before being forcefully paused, which is unnecessary. After the 20 ms are over, the ``goto`` statement is executed and the light program continues from the begin.

The following sections explain all elements of the light program language in detail.

## Light program structure

Light programs are **line-based**, meaning a single statement or declaration must be on the same source code line.

All light programs comprise of the following structure

    run conditions

    constants, variable and led declarations

    statements (= the actual code)

    end

These elements are described below in further detail.

> **Important!**
>
> * Every light program **must** end with an ``end`` statement.
> * A new-line must be present after the ``end`` statement.

## Comments

Everything behind ``//`` or ``;`` until the end of the line is considered a *comment*.

Comments are useful for describing what the light program does. The comments are not stored into the light controller itself, but can be saved in the *Configurator* through saving the configuration.

Here is a valid light program showing various forms of comments:

    // This is a test to ensure the comment system works
    //

    // Another comment, with an empty line in front
    run always  // no-signal

        sleep 1     // Sleep for 1 ms. Actually will sleep for about 20ms...
    pos1:
        sleep 2     // Sleep for 2ms // Comment in comment
        goto forward_declaration
        ; Also semicolons can be used for comments
    pos2:               ; This is a comment at a label
        sleep 3
        goto pos1

    forward_declaration:
        sleep 4
    //pos2:
    ;  pos2:
        goto pos2

        end

## Line continuation

While light programs are line-based, if the last character on a line is ``\`` the statement is assumed to be continued on the following line. This can be useful to prevent excessively long lines in source code, making it more readable.

The following shows a valid light program, but it is certainly _not advisable_ to write like this:

    run \
       when\
        indicator-left or braking \
        or \        // Comment here, should not matter ...
        indicator-right blink-flag \

    // ^ That linefeed has terminated the run when statement

        sleep 0
    pos1 :
    pos2 \
    :                  // Not very readable, but correct...
        sleep \
            2
            goto \
                pos1
        goto \
    pos2

        end

## Identifiers

Light programs can assign human readable names to constants, variables, LEDs and labels. These are called identifiers.

Identifiers must start with a character ``a..z`` or ``A..Z`` and continue with a number of alphanumeric characters, ``-`` or ``_``. Identifiers are case sensitive.

**Examples of valid identifiers**

    testvariable
    var_with_underscore
    name-with-dash
    ThisOneHas1Number

**Examples of invalid identifiers**

    3test       // does not start with a..zA..Z
    name&value  // & not allowed in identifiers
    _min        // does not start with a..zA..Z

## Run conditions

*Run conditions* define the state the light controller must be in for a light program to be executed. Each light program defines its own run condition. More than one light program may run at the same time.

There are several types of *run conditions*:

* **Events**

    Events are single-shot actions that can trigger execution of a light program. At the moment the only event supported by the light controller is "gear changed". Events have the highest priority of all *run conditions*.

* **Priority run conditions**

    These run conditions take precendence over ordinary run coditions.

* **Run conditions**

    Ordinary conditions like forward, braking, indicators, etc.

A light program can define multiple run conditions of the same type. For example, a light program can be run when the light controller is either *forward*  or *braking*.

However, a light program can not mix events, priority run conditions and run conditions.

Run conditions must be the first no-comment or empty line in the light program.
The syntax is as follows:

    run always
    run when cond1
    run when cond1 cond2
    run when cond1 or cond2

``run always`` is a special condition that runs the light program at all times.

``run when cond1`` describes a single condition that must be met for the light program to run.

``run when cond1 cond2`` and ``run when cond1 or cond2`` are identical and define that the light program shall be executed when *cond1* **or** *cond2* are met.

### Priority run conditions and events

- **no-signal**

    The light program runs when the light controller does not receive a valid servo input signal on at least one of the input channels.

- **initializing**

    The light program runs after startup while the light controller waits before reading center points of steering and throttle channels.

- **servo-output-setup-centre, servo-output-setup-left, servo-output-setup-right**

    The light program runs when the respective setup function for the steering wheel servo or gearbox servo is triggered. Performing **eight CH3-clicks** starts servo setup. These run conditions can be used to drive the lights in a unique manner to guide the user through the servo setup.

- **reversing-setup-steering, reversing-setup-throttle**

    The light program runs when the servo reversing for the steering/throttle channel is engaged. Performing **seven CH3-clicks** starts steering and throttle reversing. These run conditions can be used to guide the user through the setup process.

- **gear-changed**

    This event fires whenever the gear is changed. It only applies when the light controller is configured to drive a 2-speed or 3-speed gearbox using a servo connected to the OUT/ISP ouptut. The run condition can be used to perform a short light animation, indicating to the user that the gear change occured.

- **shelf-queen-mode** (firmware version 20 and later)

    The light program runs when shelf queen mode has activated. Shelf queen
    mode is engaged when there is no receiver signal for more than 5 seconds. It simulates driving behaviour: turning lights on an off, braking, reversing, indicator and hazard usage.

### Run conditions

- **light-switch-position-0 .. light-switch-position-8**

    The light program runs when the virtual light switch, which is incremented by one CH3-click and decremented by two CH3-clicks, is in the given postion.

- **neutral, forward, reversing, braking**

    The light program runs when the throttle is in neutral, the car is driving forward, reversing, or is braking. Neutral, forward and reversing are mutually exclusive. Braking may be active when in parallel with the other states.
    The exact behaviour of these conditions depends on the ESC configuration of the light controller. For example, if the ESC type is configured as Forward/Brake only, then a light program with the condition``run when reversing`` will never execute.

- **indicator-left, indicator-right**

    The light program runs when the left/right indicator (turn signal) is active. The indicators are engaged by having throttle and steering in neutral for one second, and then moving the steering either left or right.

- **hazard**

    The light program runs when the hazard lights are active. The hazard lights can be toggled on/off with four CH3-clicks.

- **blink-flag**

    The light program runs during the bright period of the blink timer used for indicators and hazard lights. By default the blink frequency is 1.5 Hz (320 ms half-period during which the blink-flag is set).

- **blink-left, blink-right**

    The light program runs during the bright period of the respective left or right indicator light.

- **program-state-0 .. program-state-4**

    The light program runs when the value of the global variable with the same name is not 0 (zero).
    This allows light programs to trigger other light programs.
    For more information please refer to the section near the end of this document.

## Constants

Good programming practice suggests to never use immediate number values within code, but rather define the values as constants at the begin of the program. This can make maintenance easier, i.e. to change the same delay time used in several places within a light program.

A constant is declared by giving it an identifier and assigning a value:

    const LOOP_COUNT = 10
    const thisIsAConstant_too = 42
    const constant3 = 3

The constants can then be used in the light program:

    // Blink LED 5 three times
    var count
    led light = led[5]
    const LOOP_COUNT = 3
    const BLINK_DELAY = 250
    const BRIGHTNESS = 40

        count = 0

    loop:
        light = BRIGHTNESS
        sleep BLINK_DELAY

        light = 0
        sleep BLINK_DELAY

        count += 1
        skip if count >= LOOP_COUNT
        goto loop

        end

## Declarations

The declaration section defines the LEDs and variables used by the light program and assigns human readable names to them.

Variable and LED declarations can appear in any order in the declaration section.
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

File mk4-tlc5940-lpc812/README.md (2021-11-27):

# Light controller MK4 TLC5940 LPC812 / LPC832

Usually light controller users can use the on-line Configurator at https://laneboysrc.github.io/rc-light-controller/ to adjust all settings to their need and use the WebUSB programmer to flash the resulting firmware.

---

For configuring the light controller offline, please download **[mk4-download-me.zip](mk4-download-me.zip)**.
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

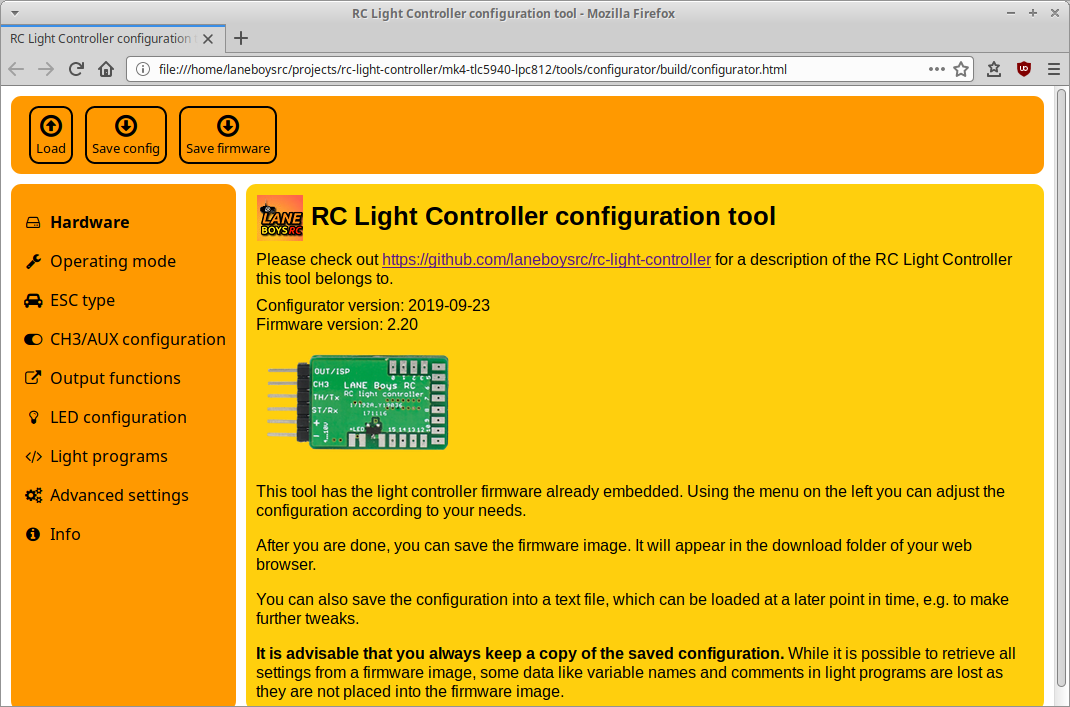
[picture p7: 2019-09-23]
doc/src/configurator.png

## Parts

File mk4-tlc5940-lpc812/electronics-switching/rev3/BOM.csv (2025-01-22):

Reference | Quantity | Value | Footprint | Datasheet
C1 | 1 | 1u/16V | Capacitor_SMD:C_0805_2012Metric
C2 | 1 | 47u/6V3 | Capacitor_SMD:C_0805_2012Metric | https://www.vishay.com/doc?40189
C3 | 1 | 100n | Capacitor_SMD:C_0603_1608Metric | ~
H1 H2 | 2 | MountingHole | MountingHole:MountingHole_2.2mm_M2_ISO14580 | ~
J1 | 1 | Pinheader right-angle 2x17 | Connector_PinHeader_2.54mm:PinHeader_2x17_P2.54mm_Horizontal | ~
J2 J3 | 2 | Pinheader straight 1x06 | rc-light-controller-tlc5940-lpc812:PinHeader_1x06_P2.54mm_Flat | ~
RN1 | 1 | 1k x4 | Resistor_SMD:R_Array_Convex_4x0603 | https://datasheet.lcsc.com/szlcsc/1810311812_UNI-ROYAL-Uniroyal-Elec-4D03WGJ0102T5E_C20197.pdf
T1 T2 T3 T4 T5 T6 T7 T9 T8 | 9 | AO3400 | Package_TO_SOT_SMD:SOT-23 | https://www.lcsc.com/product-detail/MOSFETs_PUOLOP-AO3400-SOT23_C332101.html
U1 | 1 | LPC824M101FDH20 | Package_SO:TSSOP-20_4.4x6.5mm_P0.65mm | https://www.nxp.com/part/LPC824M201JDH20
U2 | 1 | MCP1703A-3302 | Package_TO_SOT_SMD:SOT-23W

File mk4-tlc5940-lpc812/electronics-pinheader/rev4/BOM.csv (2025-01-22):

Reference | Quantity | Value | Footprint | Datasheet
C1 | 1 | 1u/16V | Capacitor_SMD:C_0805_2012Metric
C2 | 1 | 47u/6V3 | Capacitor_SMD:C_0805_2012Metric | https://www.vishay.com/doc?40189
C3 | 1 | 100n | Capacitor_SMD:C_0603_1608Metric | ~
H1 H2 | 2 | MountingHole | MountingHole:MountingHole_2.2mm_M2_ISO14580 | ~
J1 | 1 | Pinheader right-angle 2x17 | Connector_PinHeader_2.54mm:PinHeader_2x17_P2.54mm_Horizontal | ~
J2 J3 | 2 | Pinheader straight 1x06 | rc-light-controller-tlc5940-lpc812:PinHeader_1x06_P2.54mm_Flat | ~
R1 | 1 | 2k 1% | Resistor_SMD:R_0603_1608Metric | ~
RN1 | 1 | 1k x4 | Resistor_SMD:R_Array_Convex_4x0603 | https://datasheet.lcsc.com/szlcsc/1810311812_UNI-ROYAL-Uniroyal-Elec-4D03WGJ0102T5E_C20197.pdf
T9 | 1 | AO3400 | Package_TO_SOT_SMD:SOT-23 | https://www.lcsc.com/product-detail/MOSFETs_PUOLOP-AO3400-SOT23_C332101.html
U1 | 1 | LPC824M201JDH20 | Package_SO:TSSOP-20_4.4x6.5mm_P0.65mm | https://www.nxp.com/part/LPC824M201JDH20
U2 | 1 | TLC5940PWPR | rc-light-controller-tlc5940-lpc812:SOP65P640X120-29N | http://www.ti.com/lit/ds/symlink/tlc5940.pdf
U3 | 1 | MCP1703A-3302_SOT23 | Package_TO_SOT_SMD:SOT-23W | http://ww1.microchip.com/downloads/en/DeviceDoc/20005122B.pdf

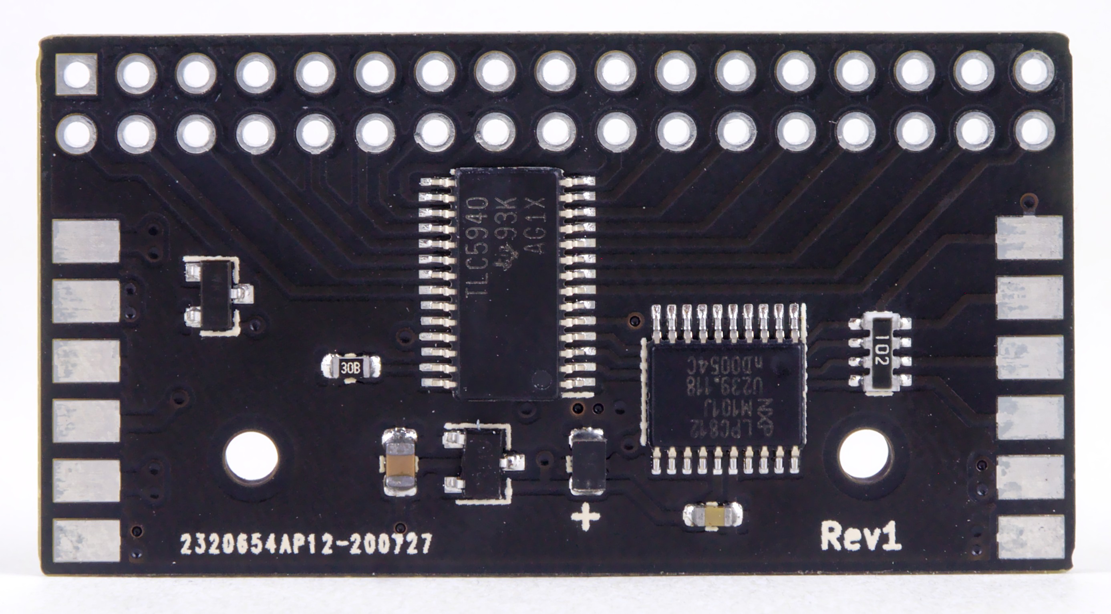
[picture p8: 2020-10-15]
doc/mk4p-component-side.jpg

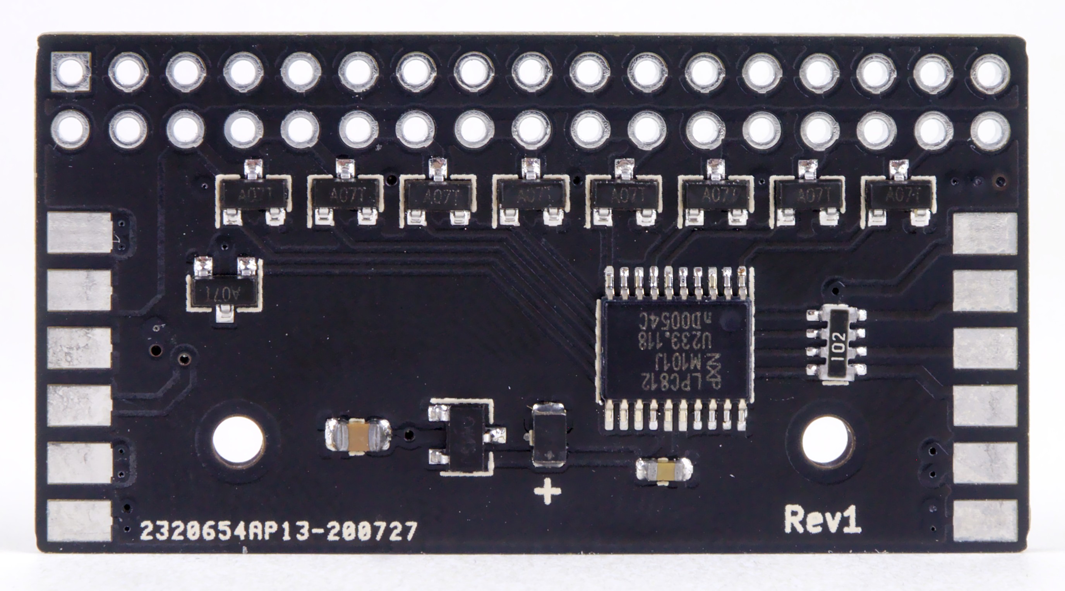
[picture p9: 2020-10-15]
doc/mk4s-component-side.jpg

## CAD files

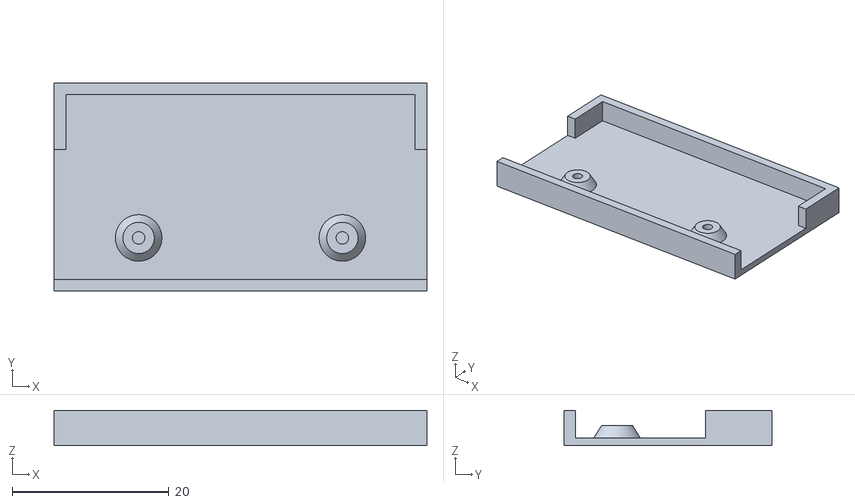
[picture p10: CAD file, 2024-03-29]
mk4-tlc5940-lpc812/mechanics/light-controller-case-mk4s-mk4p.stl
47.6 x 26.6 x 4.50

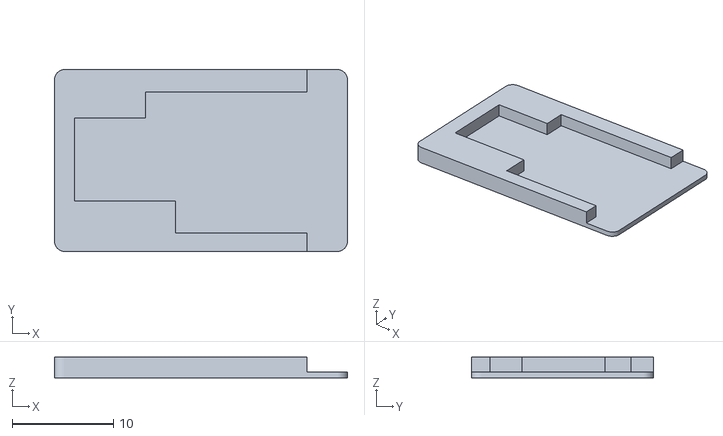
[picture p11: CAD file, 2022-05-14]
mk4-tlc5940-lpc812/mechanics/light-controller-case-mk4-sbus-rev7.stl
29.0 x 18.0 x 2.05

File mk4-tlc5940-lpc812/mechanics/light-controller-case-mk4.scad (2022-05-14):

// Case for the LANE Boys RC DIY light controller 
//
// Print with 0.2 mm layer height
//
// Modified on 2022-05-12 for compatibility with Mk4 Rev 7 (LPC832, S.Bus)

$fn = 50;
eps = 0.05;

h_bottom = 0.6;
h_middle = 1.5;

h_total = h_bottom + h_middle;

h_cutout = h_middle + eps;

difference() {
    rounded_cube([29, 18, h_total-eps], r=1);

    translate([0, 0, h_bottom]) {
        translate([2, 5, 0]) cube([18, 8.2, h_cutout]);
        translate([9, 5, 0]) cube([18, 10.8, h_cutout]);
        translate([12, 1.8, 0]) cube([14, 5, h_cutout]);
        translate([25, -eps, 0]) cube([10, 18+eps+eps, h_cutout]);
    }
}

module rounded_cube(dim, r=3, center="") {
    d = 2 * r;
    fudge = 0.05;
    
    x = search("x", center) ? 0 : dim.x/2;
    y = search("y", center) ? 0 : dim.y/2;
    z = search("z", center) ? 0 : dim.z/2;
    translate([x, y, z])
        minkowski() {
            cube(dim - [d, d, fudge], true);
            cylinder(r=r, h=fudge);
        }
}

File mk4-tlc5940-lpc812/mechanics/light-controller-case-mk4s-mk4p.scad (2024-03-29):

// Case for the LANE Boys RC DIY light controller Mk4S and Mk4P
//
// Print with 0.2 mm layer height

$fn = 50;
fudge = 0.05;
fudge2 = 2 * fudge;

gap = 0.3;

wall_t = 1.5;
bottom_t = 1;

pcb = [44, 23, 1.6];

cutout_z = 3.5;


pcb_cutout = [pcb.x+2*gap, pcb.y+2*gap, cutout_z+fudge];
pcb_cutout_offset = [-gap, -gap, pcb.z-cutout_z];

dim = pcb_cutout + [2*wall_t, 2*wall_t, bottom_t-fudge];
case_offset = [-wall_t-gap, -wall_t-gap, pcb_cutout_offset.z-bottom_t];

connector_w = 16;

connector_cutout = [2*pcb.x, connector_w+2*gap, cutout_z+fudge];
connector_cutout_offset = pcb_cutout_offset-[pcb.x/2, 0, 0];

post_d1 = 4;
post_d12 = 6;
post_h1 = cutout_z-pcb.z - 0.3; // Reduce height slightly due to printing not being precise
hole_d = 1.6;                   // Determined through test prints, may not work on your printer...

post1_pos = [9, 5, pcb_cutout_offset.z-fudge];
post2_pos = [pcb.x-9, 5, pcb_cutout_offset.z-fudge];

hole1_pos = post1_pos - [0, 0, bottom_t-fudge-0.3];
hole2_pos = post2_pos - [0, 0, bottom_t-fudge-0.3];

difference() {
    union() {
        difference() {
            translate(case_offset) cube(dim);
            translate(pcb_cutout_offset) cube(pcb_cutout);
            translate(connector_cutout_offset) cube(connector_cutout);
        }

        translate(post1_pos) post();
        translate(post2_pos) post();
    }
    
    translate(hole1_pos) cylinder(d=hole_d, h=2*post_h1);
    translate(hole2_pos) cylinder(d=hole_d, h=2*post_h1);
}

module post() {
    cylinder(d1=post_d12, d2=post_d1, h=post_h1);
}

//color("salmon") cube(pcb);

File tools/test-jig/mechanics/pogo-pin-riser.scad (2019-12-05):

$fa = 1;
$fs = 0.2;

fudge = 0.05;
fudge2 = 2 * fudge;
clearance = 0.3;

// Light controller PCB dimension
pcb_dim = [27, 18, 0.8];

// Test jig PCB thickness
pcb_t = 1.6;

pogo_pin_d = 1;
pogo_pin_l = 16.5;
pogo_pin_head_d = 1.75;
pogo_pin_head_l = 7;

chute_w = 2;
wall_t = 1;

riser_dim = [pcb_dim.x+wall_t, pcb_dim.y+2*wall_t, 15-pcb_t];
riser_pos = [-1.78-wall_t, -1.78-wall_t, 0];

mounting_hole_d = 1.75;
mounting_hole_l = 9;
mounting_hole_pos = [
    [6, 7],
    [16, 7],
];

// Chute dimensions
inner_bottom = [pcb_dim.x, pcb_dim.y] - [fudge, fudge2];
inner_top = [pcb_dim.x+chute_w, pcb_dim.y+chute_w];
outer_bottom = inner_bottom;
outer_top = inner_top + [0, 2*wall_t, 0];


pin_pos = [
    [0, 0],         // OUT11       
    [2.8, 0],       // OUT12
    [4.8, 0],       // OUT13
    [6.9, 0],       // OUT14
    [8.9, 0],       // OUT15
    [10.9, 0],      // OUT15S
    [14.7, 0],      // +LED1 
    //[16.8, 0],   // +LED2

    [0, 2],         // OUT10
    [0, 4.1],       // OUT9
    [0, 6.1],       // OUT8
    [0, 8.4],       // OUT7
    [0, 10.4],      // OUT6
    [0, 12.4],      // OUT5
    [0, 14.4],      // OUT4

    [2.8, 14.4],    // OUT3
    [4.8, 14.4],    // OUT2
    [6.9, 14.4],    // OUT1
    [8.9, 14.4],    // OUT0
];


//pogo_pin_riser();
rotate([0, -90, 0]) clip();
translate([-13.9, 0, 0]) cube([10, 20, 0.3]);

module clip() {
    gap = 2.5;
    cl = 3 * clearance;
    clip_dim = [10, outer_top.y+2*wall_t+cl, chute_w+gap+wall_t+cl];

    module cavity() {
        x = clip_dim.x + fudge2;
        y1 = outer_bottom.y + cl;
        y2 = outer_top.y + cl;
        z1 = chute_w;
        z2 = chute_w + gap + clearance;
        y1p = (y2-y1)/2;
        y2p = 0;
        
        translate([-fudge, wall_t, 0]) rotate([90, 0, 90]) linear_extrude(x) polygon([
            [y1p, -fudge],
            [y2p, z1],            
            [y2p, z2],            
            [y2p+y2, z2],            
            [y2p+y2, z1],           
            [y1p+y1, -fudge], 
        ]);
    }

    translate([0, -3*wall_t, 0]) difference() {
        cube(clip_dim);
        cavity();
    }
}


module pogo_pin_riser() {
    difference() {
        riser();
        pogo_pins();
        pogo_pins_head_clearance();
        mounting_holes();
        solder_clearance();
    }
}

module riser() {
    translate(riser_pos) {
        cube(riser_dim);
        translate([fudge+wall_t, fudge+wall_t, riser_dim.z]) chute();
//        translate([fudge+wall_t, fudge+wall_t, riser_dim.z]) clip();
    }
}

module solder_clearance() {
    w = 3.5;
    h1 = 2;
    h2 = 7;
    
    module shape(length=10) {
        translate([-fudge, -fudge, -fudge]) rotate([0, 90, 0]) linear_extrude(length+fudge2) polygon([
            [0, 0],
            [0, w],
            [-h1, w],
            [-h2, 0],
        ]);
    }
    
    translate(riser_pos) {
        shape(19);
        translate([0, riser_dim.y, 0]) mirror([0, 1, 0]) shape(13);
        mirror([0, 1, 0] ) rotate([0, 0, -90]) shape(riser_dim.y);
    }
}

module mounting_holes() {
    for (pos = mounting_hole_pos) {
        translate([pos.x, pos.y, -fudge]) mounting_hole();
    }
}

module mounting_hole() {
    cylinder(h=mounting_hole_l, d=mounting_hole_d);
}

module pogo_pins_head_clearance() {
    h = pogo_pin_l-pogo_pin_head_l;
    d_head = pogo_pin_head_d + 1.5;
    
    translate([0, 0, h-pcb_t]) {
        hull() {
            translate(pin_pos[0]) cylinder(h=pogo_pin_head_l, d=d_head);
            translate(pin_pos[6]) cylinder(h=pogo_pin_head_l, d=d_head);
        }

        hull() {
            translate(pin_pos[0]) cylinder(h=pogo_pin_head_l, d=d_head);
            translate(pin_pos[13]) cylinder(h=pogo_pin_head_l, d=d_head);
        }
        
        hull() {
            translate(pin_pos[13]) cylinder(h=pogo_pin_head_l, d=d_head);
            translate(pin_pos[17]) cylinder(h=pogo_pin_head_l, d=d_head);
        }
    }
}


module pogo_pins() {
    for (pos = pin_pos) {
        translate([pos.x, pos.y, -pcb_t]) pogo_pin_clearance();
    }
}

module pogo_pin_clearance() {
    d = pogo_pin_d + 0.5;
    d_solder = 6;
    h_solder = pcb_t * 3;
    d_head = pogo_pin_head_d + 1.5;
    
    cylinder(h=pogo_pin_l, d=d);
//    cylinder(h=h_solder, d1=d_solder, d2=d);
    translate([0, 0, pogo_pin_l-pogo_pin_head_l]) cylinder(h=pogo_pin_head_l, d=d_head);
}
    
module chute() {
     difference() {
        translate([-wall_t, -wall_t, 0]) hull() {
            translate([wall_t, wall_t, -chute_w]) linear_extrude(fudge2) square(outer_bottom);
            translate([-chute_w/2, -chute_w/2, chute_w]) linear_extrude(fudge) square(outer_top);
        }
        
        translate([0, 0, -fudge])hull() {
            linear_extrude(fudge2) square(inner_bottom);
            translate([-chute_w/2, -chute_w/2, chute_w+fudge2]) linear_extrude(fudge) square(inner_top);
        }
    }
}

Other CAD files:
doc/src/servo.scad

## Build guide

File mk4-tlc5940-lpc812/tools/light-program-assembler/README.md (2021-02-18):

# Light program assembler

Light programs are simple programs that are interpreted by the LANE Boys RC light controller (Mk4 TLC5940 LPC812 version).

## Build instructions

The following tools are needed:

- GNU Make - [https://www.gnu.org/software/make/](https://www.gnu.org/software/make/)
  Windows executable is available at [http://gnuwin32.sourceforge.net/packages/make.htm](http://gnuwin32.sourceforge.net/packages/make.htm)

- Node.js - [http://nodejs.org/](http://nodejs.org/)

After installing these tools, run ``make`` to build the assembler as needed for the configurator, plus a command line version.

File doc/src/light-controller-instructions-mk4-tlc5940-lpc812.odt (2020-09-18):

RC Light Controller

Instructions for use

for the MK4 TLC5940 LPC812 variant

# Introduction

Thanks for using the LANE Boys RC light controller!

The light controller supports the following features:

- 16 LED outputs, constant-current driven. Up to 20 mA per output. Two light controllers can be cascaded for a total of 32 LED outputs.
- High current switched output of up to 2A to drive a roof light bar
- Parking, Low-beam, High-beam and a roof light bar can be switched on/off manually from the transmitter
- Brake and Reverse lights are automatically controlled by monitoring the throttle channel. The brake lights now automatically turn on for a short, random time when the throttle goes to neutral.
- Combined tail and brake light function in a single LED through controlling the brightness of the LED.
- Separate brake light function for a 3rd brake light
- Indicators only come on when you want to. You have to stay in neutral for one seconds, then hold the steering left/right for one second before they engage. This way normal driving does not trigger the indicators.
- Hazard lights can be switched on/off from the transmitter
- Programmable output designed to drive a steering wheel or a figures head, a gearbox servo or a winch
- Automatic center and end-point adjustment for steering and throttle channel
- Light Programs for custom light animations like police lights, running lights ...
- Simulation of incandescent lights and faulty ground wiring
- Pre-processor for easier wiring
- Up to 3 AUX channels when using the new 5-channel Pre-processor
- All functions can be customized using a web browser-based tool http (http://laneboysrc.github.io/rc-light-controller/)s (http://laneboysrc.github.io/rc-light-controller/)://laneboysrc.github.io/rc-light-controller/
- Hardware and software is Open Source https://github.com/laneboysrc/rc-light-controller/

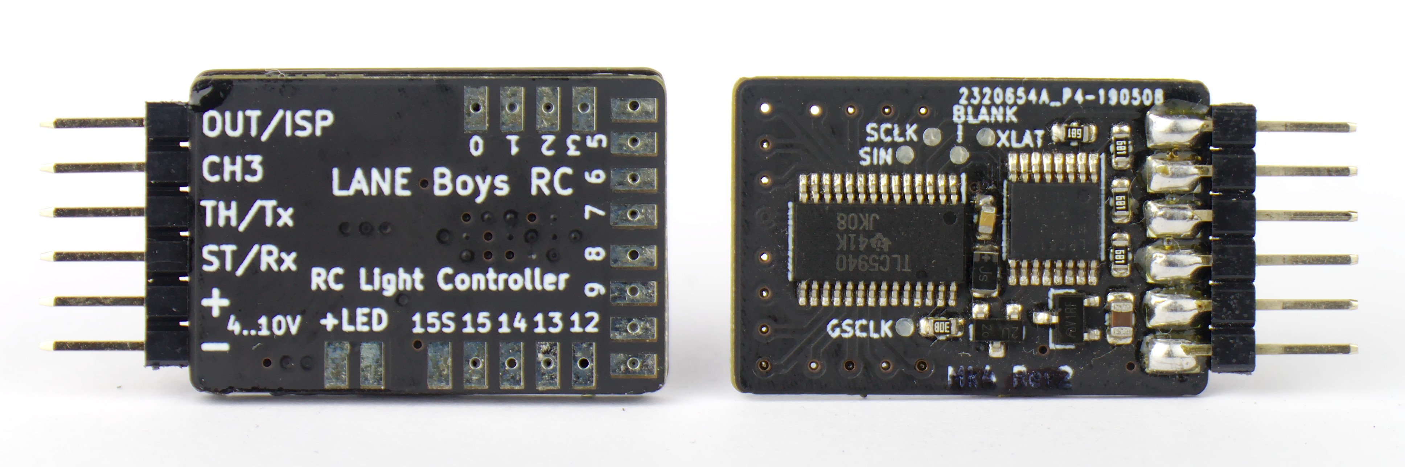
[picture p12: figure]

Light controller circuit board, Mk4 revision 2. The revision 2 is identical with the original Mk4 release except that the transistor for the switched light output is in a different location.

# Light Controller overview

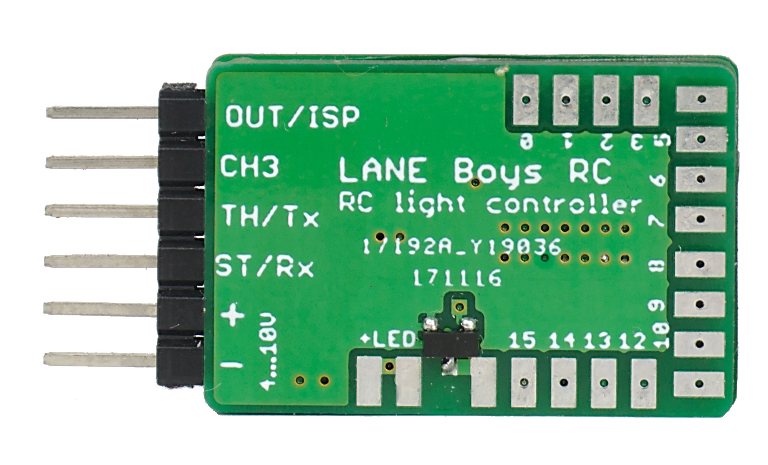
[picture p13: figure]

The table below shows how the outputs are configured by default.

Note that all outputs can be fully customized, refer to a later section in this document on how to adapt the light functions to your vehicle.

Name | Function | Description
+ | Positive power supply | +4..10V input voltage, usually taken from the receiver (red wire)
- | Negative power supply (GND) | Supply ground (brown or black wire)
ST/Rx | Steering input | Steering servo signal from the receiver, or input from the Pre-Processor
TH/Tx | Throttle input | Throttle (ESC) signal from the receiver
CH3 | CH3/AUX input | Channel 3 (AUX) signal from the receiver
OUT/ISP | Output | Output to drive a servo or connect a slave controller. The output function can be configured via the Configurator browser based tool, see below.
+LED | LED supply | Terminal to connect the (+) Anode of the LEDs. Wired internally to the “+” positive power supply connection.
OUT0 | Light output 0 | Parking/Position light front left
OUT1 | … | Parking/Position light front right
OUT2 | … | Main beam front left
OUT3 | … | Main beam front right
OUT4 | … | High beam front left
OUT5 | … | High beam front right
OUT6 | … | Indicator front left
OUT7 | … | Indicator front right
OUT8 | … | Tail/Brake light rear left
OUT9 | … | Tail/Brake light rear right
OUT10 | … | Reversing light rear left
OUT11 | … | Reversing light rear right
OUT12 | … | Indicator rear left
OUT13 | … | Indicator rear right
OUT14 | … | 3rd brake light rear
OUT15 | Light output 15 | Roof light
OUT15S | Switched light output (left of light output 15) | Carries the same signal as light output 15, but instead of current-controlled it is switched towards Ground (-). Up to 2A of current can be switched....

# Connecting the light controller to your RC car

The light controller is usually powered from the RC receiver. The following sections describe different methods how to route the outputs of the RC receiver to the light controller and the other RC components.

## Using a Pre-Processor

The Light Controller has a small companion circuit board called Pre-Processor.


3-channel Pre-Processor

Instead of connecting the servo signals to the light controller directly, you connect them to the Pre-Processor instead. The Pre-Processor accumulates all servo signals into a single data line to the light controller. The Pre-Processor also has additional connectors for the steering and throttle signal, saving the hassle of Y-cables.

This simplifies wiring drastically: only a 3-pole servo extension cable is needed between the chassis of the car (where receiver, ESC, Servo and Pre-Processor reside) and the body shell (where the light controller and the LEDs are).

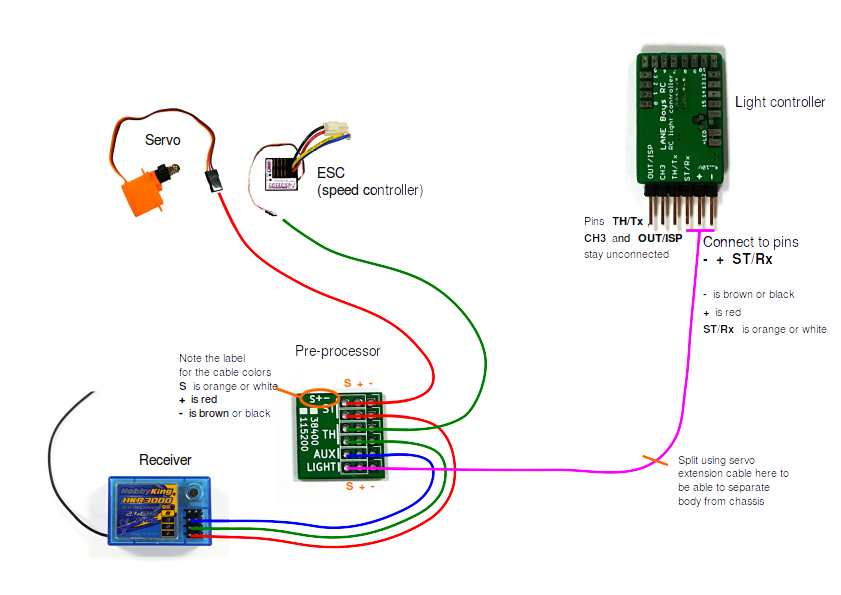
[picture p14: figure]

Pre-Processor also comes in a 5-channel variant, which is useful if you have a modern RC car radio that supports more than 3 channels. With the 5-channel Pre-Processor you can use separate AUX channels for manual indicators, or switching the lights, or turning the hazard lights on an off. The function of each AUX channel can be configured separately.


5-channel Pre-Processor

## Direct connection to the servo signals

The light controller signals ST/Rx, TH/Tx and CH3 need to connected to the steering, throttle and auxiliary channels of your receiver.

For steering and throttle you will need to utilize a Y-cable as shown on the schematics below:

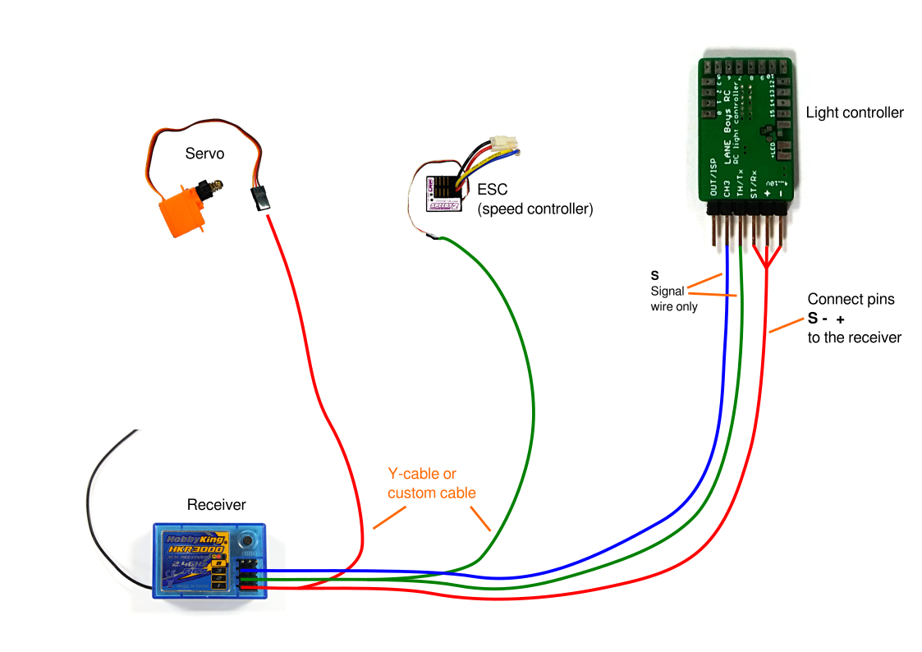
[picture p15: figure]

Only one of the channels needs to provide power to the light controller. For the other channels it is sufficient to use just the signal wire (usually orange or white in color). Servo extension leads can be easily reconfigured to achieve this:

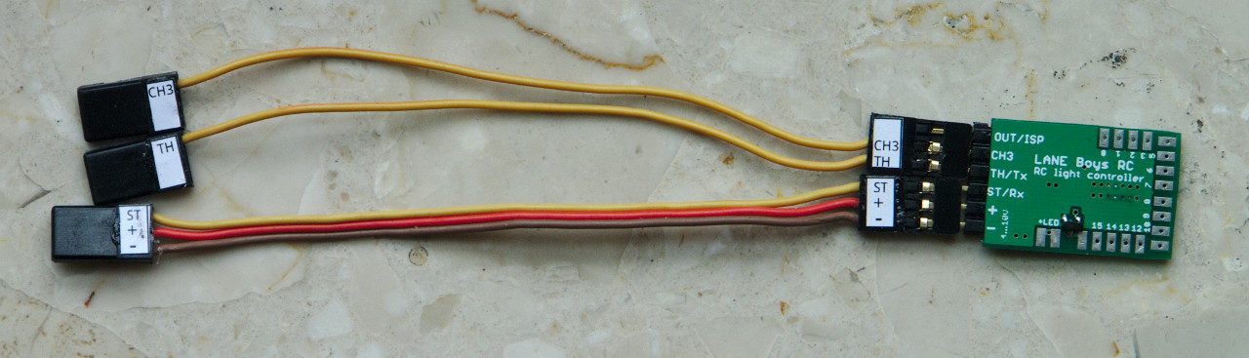
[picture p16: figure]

## Using a push-button installed in the car to switch functions

If you have a two-channel RC transmitter or don’t have a spare channel to control the light functions, then you can alternatively hook up a push-button to the CH3 input directly to the light controller. You can hide the push-button somewhere in the car and access it when needed.

The push-button needs to connect the CH3 input of the light controller to – (Receiver supply minus; GND) when pushed, as shown in the diagram below.

Note that you must enable the Push button on the light controller setting in the Configurator tool described later in this document to enable this function.

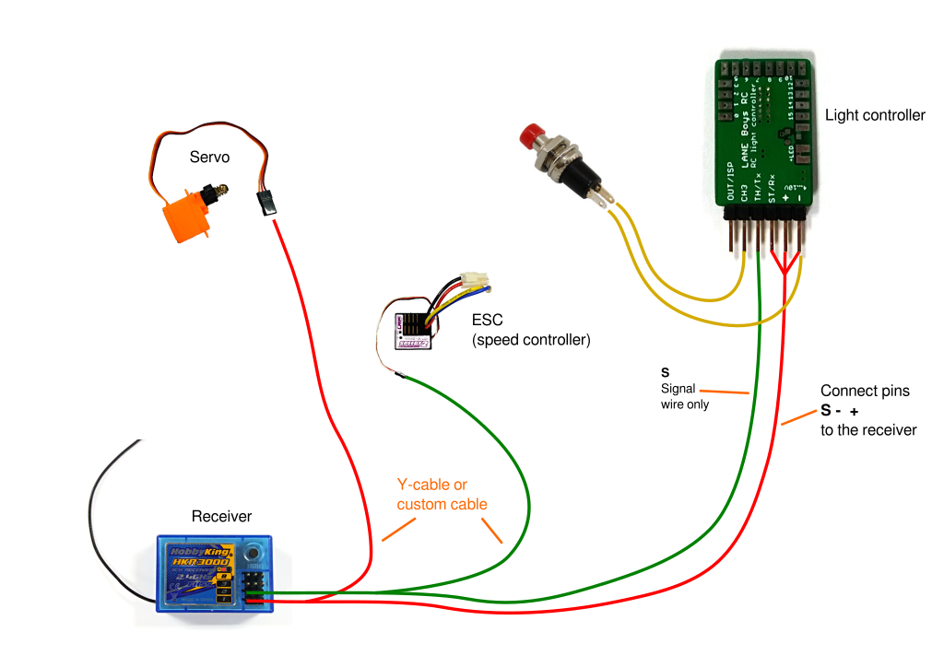
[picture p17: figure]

# Connecting LEDs

The (+) Anode (usually the long pin) connections of all LEDs are connected together to the terminals +LED. For soldering convenience there are two terminals that carry +LED.

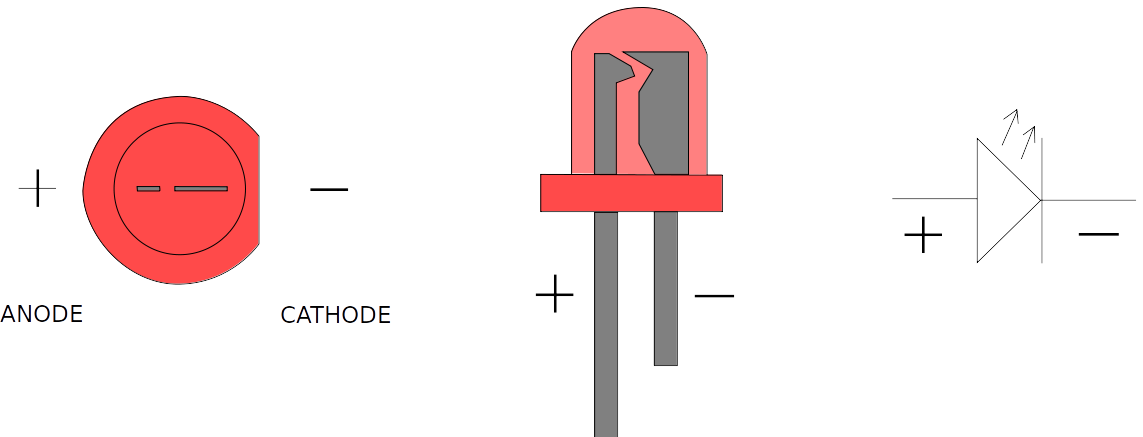
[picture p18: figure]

Each light output is designed to drive a single LED. The outputs are driven with a constant current of up to 20mA for optimal LED performance and uniform brightness.

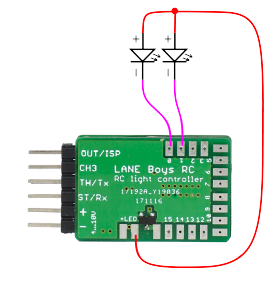
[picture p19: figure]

Do not connect a resistor in line with the LED, it is not necessary for this light controller!

For more information about LEDs please refer to Appendix A: More info about LED connections

# High current LED output OUT15S

Beside the 16 light outputs, there is also a high current capable switched light output. It is designed to drive an off-the-shelf light bar.

The switched light output is marked 15S and turns on in conjunction with output OUT15. It can sink up to 2 Ampere in current.

Note that you must not connect LEDs without current limiting resistor to this output, as they will burn out immediately.

# Operation

After turning the power on, the front main beam LEDs will turn on for about two seconds. During this time ensure that steering and throttle controls on the transmitter are kept in neutral position.

If if the front indicators light up instead of the main beam LEDs, this means that neither of the input channels ST, TH and CH3 receive a proper servo signals from the receiver. Turn off the power and check all connections.

After initialization all lights turn off and the system is ready to use.

It is advisable to let the light controller know the endpoints of steering and throttle before driving off. To do this simply move the steering fully left, then fully right. Hold the car in the air safely and pull the throttle full forward, then full backward – ensuring that the drive train does not get damaged.

## Brake and reversing light

When driving, the brake and reverse lights will now come on according to the throttle input. The indicators can be engaged by keeping both steering and throttle neutral for one second, then turning the steering into the direction the indicators should show. Once they are engaged you can start driving off with the indicators operating. They will turn off after a short delay when the car goes straight, or immediately when the car turns in the other direction.

## Switching the main lights

Several functions of the light controller are operated manually through the auxiliary channel CH3. Since there are quite a few functions the concept of “clicks” is employed. Similar to the operation of a computer mouse, one can press the CH3 button on the transmitter repeatedly within a short time to invoke different functions.

One click: Turn on more lights at each click: Parking, Main beam, High beam, Roof lights

Two clicks: Turn the lights down; reverse of one click

Three clicks: toggle all lights on and off

Four clicks: toggle hazard lights (all indicators flash) on and off

Here is a video showing the operation: https://youtu.be/-VyNAVU3-ok

# Steering and Throttle channel reversing

The direction of the steering and throttle channels can be programmed to match the car. To do this, perform seven clicks on channel CH3. The front and rear indicators on one side as well as the front main beam lights will turn on.

Move the steering wheel on the transmitter into the direction of the indicators that light up (i.e. if the indicators on the left side of the car light up, turn the steering wheel left). When successful the indicators will turn off.

Now engage the throttle forward. When successful the main lights will turn off, programming channel reversing has finished and the light controller will resume normal operation.

The steering and throttle direction are stored persistently so this configuration has to be carried out only once after installing the light controller.

# Servo output

The light controller also can drive a small servo in synchronization with the steering input. This is designed to turn the steering wheel in the cabin of a truck. The center, endpoints and direction can be fully programmed (see below).

Note: for safety reasons do not connect the steering servo of your vehicle to this output!

The signal wire of the servo must be connected to the OUT/ISP pin on the light controller. Note that some servos, especially analog servos, put a high load on the OUT/ISP pin, preventing the light controller to start. Digital servos usually work without issue.

The servo output can also be configured for controlling a 2-speed or 3-speed gearbox. When the gearbox control is enabled, 1-click and 2-clicks on CH3/AUX change their behavior:

2-speed gearbox: 1-click changes to gear 1, 2-clicks to gear 2.

3-speed gearbox: 1-click changes to the next higher gear, 2-clicks changes to the next lower gear.

Since 1-click and 2-clicks are now taken up by gearbox control, it is no longer possible to switch between the different virtual light switch positions. The lights can only be switched on/off using 3-clicks. If this is not desired, then one can opt to control the gearbox from a light program. With a small light program it is possible to toggle through the gears when performing 6-clicks on CH3/AUX.

Last but not least, it is also possible to control the servo output from a light program. When the respective configuration option is chosen, values between -100 (left endpoint), 0 (center) and +100 (right endpoint) can be set to move the servo to desired positions. This can be useful for simple mechatronics animations, like random movements of a figures head.

## Steering wheel servo / Gearbox servo setup

In case a steering wheel servo is utilized, the center point and end points can be configured independently of the car steering.

To set up the steering wheel servo perform eight clicks on channel CH3. The left indicators will light up and the steering wheel servo will follow directly the steering input on the transmitter. Move the steering wheel on the transmitter to the position that shall be used for full left on the steering wheel servo. Note that this may require that you need to turn the steering wheel on the transmitter right, if the servo is reversed. Don't worry, this is correct and lets the light controller know which way to turn the steering wheel servo. Hold the transmitter steering in position while clicking channel CH3 once.
Now both left and right indicators will turn on. Turn the steering wheel on the transmitter to the position that the steering wheel servo is centered and click channel CH3 once. Now the right indicators will turn on. Perform the same procedure as for the left end point and click channel CH3 once.

The center and end points should now be correct, the steering wheel should follow in the same way as the car. The settings are stored persistently and are not affected by steering trims and endpoint adjustments.

Note that after changing endpoints or trim on your RC transmitter you need to restart the light controller so that it learns the new settings.

# Configurator: Custom configuration of light functions

The light controller can be configured through a web browser.

You can access the latest version of the tool on-line at http (http://laneboysrc.github.io/rc-light-controller/)s (http://laneboysrc.github.io/rc-light-controller/)://laneboysrc.github.io/rc-light-controller/


Alternatively, you can download

https://github.com/laneboysrc/rc-light-controller/blob/master/mk4-tlc5940-lpc812/mk4-download-me.zip?raw=true

This archive contains the configuration tool configurator.html. Open this file in your web browser (tested with Firefox, Chrome and Internet Explorer 10).

The Configurator has the firmware already embedded, just set the options you want and click on the Save firmware image... button. A file named light_controller.hex will be stored in the Download folder of your web browser.

You can now use the LPC81x-ISP tool included in mk4-download-me.zip archive to flash the firmware. You need a USB-to-serial adapter to connect your PC to the light controller.

Wire-up the USB-to-serial adapter as follows:

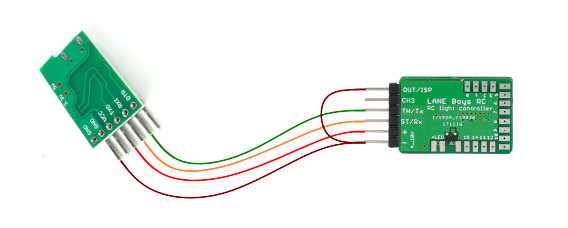
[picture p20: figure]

Note: Connect the light controller to the USB-to-serial adapter before plugging the USB-to-serial adapter into the PC. This is necessary as OUT/ISP pin must be connected to (-) GND while power-on to allow the light controller to enter the Flash function.

Start the LPC81x-ISP tool, click on the Select file… button and load the light_controller.hex file that you saved in the download folder earlier.

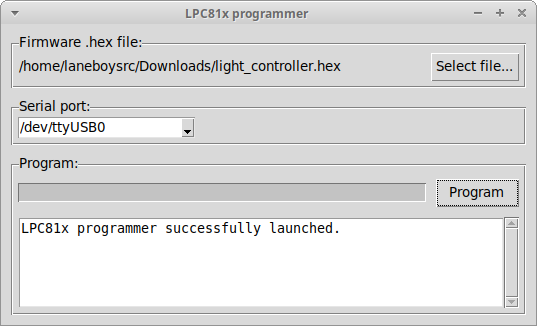
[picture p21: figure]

Click the Program button to start the flashing of the new firmware containing your custom configuration.

# Light Programs

Light Programs are simple scripts that allow full customization of light controller functions and light outputs without the need of developing a custom firmware.

Detailed documentation of Light Programs can be found at https://github.com/laneboysrc/rc-light-controller/blob/master/mk4-tlc5940-lpc812/doc/light-programs.md

Light programs are useful to create running lights, police flashers etc. A collection of light programs can be found at https://github.com/laneboysrc/rc-light-controller/tree/master/mk4-tlc5940-lpc812/configurations

# Technical data

Operating voltage: 4 V .. 10 V (receiver voltage up to 2S LiPo directly)

Constant current outputs: 20 mA per LED output

Dimming: constant current in 63 steps (DC, no PWM)

LED configuration: common Anode (common plus pole, minus pole goes to individual outputs of the light controller)

Dimensions:

Light Controller: 36 x 18 x 3 mm
Pre-processor: 17 x 17 mm
5-channel Pre-processor: 24 x 17 mm

Have fun with RC! Werner

laneboysrc@gmail.com

http (https://laneboysrc.blogspot.com/)s (https://laneboysrc.blogspot.com/)://laneboysrc.blogspot.com/

http (https://www.youtube.com/user/laneboysrc)s (https://www.youtube.com/user/laneboysrc)://www.youtube.com/user/laneboysrc

https://www.flickr.com/photos/78037110@N03/albums/

https://github.com/laneboysrc/rc-light-controller/

# Appendix A: More info about LED connections

## Wiring LEDs in series

Depending on the power supply voltage and the LED's forward voltage, it is possible to drive two LEDs in series on a single light output:

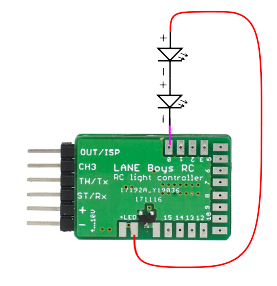
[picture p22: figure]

The LED forward voltage depends on the color of the LED.

- Red and Amber LEDs have a forward voltage of about 1.8V
- Green LEDs about 2.2V
- White LEDs about 3.2V
- Blue LEDs may require up to 3.6V

Always consolidate the datasheet of your LEDs for exact values.

The light controller itself requires at least 0.8 V to be able to control the current.

Usually the light controller is powered from the BEC in the car, which outputs 5V or 6V.

Example: Two red LEDs are wired in series,

...so the voltage drop across them is 1.8V times 2 = 3.6V.

The BEC voltage is 5V. 5V – 3.6V = 1.4V, which is more than the 0.8V that the light controller requires for proper operation, so everything works fine.

Example 2: A white and a blue LED wired in series.

The voltage drop across both LEDs is 3.2V + 3.6V = 6.8V.

The BEC voltage is 6V, so it is not high enough to drive those LEDs.

However, it is possible to power the light controller from the 2S LiPo car battery.

A fully charged LiPo is 8.4V.

8.4V – 6.8V = 1.6V, which is more than the 0.8V required by the light controller.

As the LiPo discharges and voltage drops below 6.8V + 0.8V = 7.6V, the LEDs will be not driven properly anymore and may become dim.

Note: when powering the light controller directly from a 2S LiPo precautions have to be taken to ensure that the installation is safe against short circuits, as the energy stored in a battery can easily cause fire.

Furthermore, the power dissipated in the light controller increases if the input voltage increases. The light controller may become too hot and malfunction.

## Wiring LEDs in parallel

In general, it is not recommended to wire LEDs in parallel. LEDs are non-linear devices – a small change in forward voltage can cause a large change in the current flowing through the LEDs.

If two LEDs wired in parallel have a different forward voltage, than one of the LEDs may draw more current than the other LED.

That said, in practice it is usually OK to wire two LEDs in parallel, as modern LEDs are manufactured to a tight tolerance.

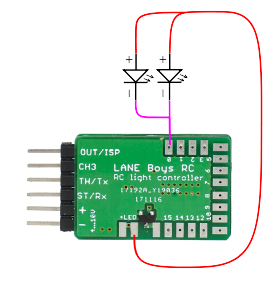
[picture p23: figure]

Only LEDs of the same manufacturer, type and color can be wired in parallel.

When two LEDs are wired in parallel, half of the current runs through each LED.

One potential use-case is to save an output for white parking lights or reversing lights. Wiring white LEDs in series (see previous section) is not possible as the total voltage required is less than the voltage available. However, since for parking lights or reversing lights the brightness does not need to be extreme, wiring two LEDs together can save an output on the light controller.

Still, if possible it is advisable to wire each LED to a dedicated output on the light controller.

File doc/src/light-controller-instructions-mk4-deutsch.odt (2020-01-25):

RC Light Controller

Anleitung

für die Mk4 TLC5940 LPC812 Variante

# Einleitung

Danke, dass Sie den LANE Boys RC Light Controller benutzten!

Der Light Controller unterstützt unter anderem folgende Funktionen:

- 16 LED Ausgänge, mit Konstant-Strom gesteuert um Flickern zu verhindern. Zwei Light Controller können kaskadiert werden für insgesamt 32 LED Ausgänge.
- 2 Ampere Schaltausgang z.B für einen Lichtbalken am Dach
- Standlicht, Abblendlicht, Fernlicht und der Lichtbalken können vom Sender aus manuell ein/ausgeschaltet werden
- Brems und Rückfahrscheinwerfer werden automatisch über das Gas-Signal angesteuert. Die Bremslichter schalten sich für eine kurze, zufällig gewählte Zeit ein wenn das Gas in Neutral-Stellung geht.
- Kombinierte Schlusslicht und Bremslicht Funktion mit nur einer roten LED durch Ansteuerung der Helligkeit
- Separate Bremslichtfunktion für ein 3. Bremslicht
- Die Blinker schalten sich automatisch nur ein, wenn das Fahrzeug für mindestens eine Sekunde in Neutral befindet und man dann die Lenkung links oder rechts betätigt. Damit blinken die Richtungsanzeiger während des Fahren nicht andauernd.
- Warnblinker können vom Sender aus ein/ausgeschaltet werden
- Programmierbarer Servo-Ausgang um zum Beispiel ein Lenkrad im Fahrzeuginnenraum zu bewegen, oder den Kopf einer Puppe. Der Ausgang kann auch für ein schaltbares Getriebe oder eine Winde verwendet werden.
- Automatische Mittelstellung- und Endpunkterkennung für Gas und Lenkung
- Licht Skripte (Light Programs) für benutzerdefinierte Lichtanimationen wie z.B. Blaulichter, Lauflichter ...
- Simulation von Glühlampen und schlechter Masse-Verbindung
- Pre-processor (Signalwandler) für Vereinfachung der Verkabelung
- Bis zu 3 AUX Kanäle bei Verwendung des neuen 5-Kanal Pre-processor
- Alle Funktionen können im Web-Browser konfiguriert werden http (http://laneboysrc.github.io/rc-light-controller/)s (http://laneboysrc.github.io/rc-light-controller/)://laneboysrc.github.io/rc-light-controller/
- Hardware und Software sind Open Source https://github.com/laneboysrc/rc-light-controller/


Die Platine des Light Controller, Mk4 Revision 2. In der Revision 2 befindet sich der Transistor für den Schaltausgang jetzt auf der Seite mit den anderen Bauteilen. Von den Funktionen her ist die Revision 2 identisch mit der ursprünglichen Version.

# Verbindung des Light Controller mit der Fahrzeugelektronik

Normalerweise erhält der Light Controller seine Stromversorgung vom Empfänger.

Die folgenden Kapitel beschreiben wie man die Servo Signale vom Empfänger mit den anderen elektronischen Komponenten wie Lenk-Servo und Fahrtregler verbindet.

## Direkte Verbindung mit den Servo Signalen

Die Eingänge des Light Controller ST/Rx (Lenkung), TH/Tx (Gas) and CH3 (Schaltkanal) werden direkt mit dem entsprechenden Ausgängen am Empfänger verbunden.

Für Lenkung und Gas benötigt man ein Y-Kabel damit man auch den Fahrtregler und das Lenk-servo gleichzeitig anschließen kann. Das folgende Diagramm zeigt die Verbindungen:


Nur einer der Kanäle (Lenkung) wird benötigt um die Stromversorgung zum Light Controller zu bringen. Für die anderen Kanäle (Gas, CH3/AUX) ist es ausreichend nur die Signalleitung zum Light Controller zu führen. Die Signalleitung ist meist Orange oder Weiß. Handelsübliche Servoverlängerungskabel kann man einfach umkonfigurieren, siehe Foto unten:


## Verbindung unter Zuhilfenahme eines Pre-processor

Der Light Controller hat eine Schwesterplatine namens Pre-processor. Der Pre-processor agiert als Signalwandler.


3-Kanal Pre-processor

Anstatt die Servo Signale des Empfängers direkt mit dem Light Controller zu verbinden, schaltet man den Pre-processor dazwischen. Der Pre-processor packt alle Servo Signal in eine einzelne Datenleitung, die dann zum Light Controller geführt wird. Der Pre-processor hat auch doppelte Anschlüsse für Lenkung und Gas, sodass die umständlichen Y-Kabel wegfallen.

Der Pre-processor vereinfacht das Verkabeln: Nur ein handelsübliches Servo-Verlängerungskabel wird vom Chassis des Fahrzeuges zur Karosserie geführt.
Im Chassis befinden sich Empfänger, Fahrtregler, Lenk-Servo und der Pre-processor; und in der Karosserie der Light Controller und die LEDs.


Die Eingänge TH/Tx und CH3 werden nicht benutzt.

Der Pre-processor ist auch in einer 5-Kanal Variante erhältlich. Dies ermöglicht die Benutzung von zusätzlichen AUX Kanälen, wie man sie oft in modernen Fernsteuerungen findet.

Bei Verwendung des 5-Kanal Pre-processor kann man separate Schaltkanäle am Sender verwenden um z.B. die Blinker manuell zu steuern, oder die Scheinwerfer zu schalten, oder die Warnblinker ein/ausschalten. Jeder AUX Kanal kann separat konfiguriert werden.


5-Kanal Pre-processor

Es ist auch möglich einen Mikrocontroller, der die Funtion des 3-Kanal Pre-processor beinhaltet, direkt in den Empfänger einzubauen:

http://laneboysrc.blogspot.com/2012/12/pre-processor-for-diy-rc-light.html

http://laneboysrc.blogspot.com/2013/01/pre-processor-miniaturization.html

(Beschreibung nur auf Englisch verfügbar)
Diese Methode ist aber nur für Elektronikexperten geeignet.

## Verwendung eines im Auto eingebauten Tasters

Wenn nur eine 2-Kanal Fernsteuerung verwendet wird, oder kein AUX Kanal mehr frei ist, dann kann man als Alternative auch einen Taster direkt an den CH3 Eingang des Light Controller anschließen. Der Taster kann irgendwo im Auto versteckt werden.

Der Taster muss zwischen dem CH3 Eingang und – (Minus-Pol; GND) eingebaut werden, wie es das Diagramm weiter unten zeigt.

In der Konfiguration des Light Controller muss die Option „Push button on the light controller“ (Taster direkt am Light Controller) eingestellt werden. Das Konfigurieren wird in einem Kapitel weiter unten erklärt.


# Ausgänge des Light Controller


Die folgende Tabelle zeigt, wie die Ausgänge des Light Controller im Auslieferungszustand konfiguriert sind.

Wichtig: alle Ausgänge sind frei konfigurierbar; jedem Ausgang kann jede gewünschte Funktion zugewiesen werden. Das Konfigurieren wird in einem Folgekapitel erklärt.

Name | Funktion | Beschreibung
+ | Stromversorgung, Plus-Pol | +4..10V Eingangsspannung, kommt normalerweise vom Empfänger (rotes Kabel)
- | Stromversorgung, Minus-Pol (GND) | 0-Potential (braunes oder schwarzes Kabel)
ST/Rx | Lenk-Signal Eingang | Lenk-Servo Signal vom Empfänger
TH/Tx | Gas-Signal Eingang | Gas (Fahrtregler, ESC) Signal vom Empfänger
CH3 | CH3/AUX Eingang | Kanal 3 (Schaltkanal, AUX) Signal vom Empfänger
OUT/ISP | Ausgang | Multi-Funktionsausgang: Steuern eines Servo; Anschluss eines 2. Light Controller Die Konfiguration wird weiter unten beschrieben.
+LED | LED Stromversorgung | Ausgang zu den Plus-Polen (+, Anode) der LEDs. Dieser Ausgang ist mit dem Plus-Pol der Stromversorgung “+” intern verbunden.
0 | LED Ausgang 0 | Standlicht vorne links
1 | … | Standlicht vorne rechts
2 | … | Abblendlicht vorne links
3 | … | Abblendlicht vorne rechts
4 | … | Fernlicht vorne links
5 | … | Fernlicht vorne rechts
6 | … | Blinker vorne links
7 | … | Blinker vorne rechts
8 | … | Kombiniertes Schlusslicht/Bremslicht hinten links
9 | … | Kombiniertes Schlusslicht/Bremslicht hinten rechts
10 | … | Rückfahrlicht hinten links
11 | … | Rückfahrlicht hinten rechts
12 | … | Blinker hinten links
13 | … | Blinker hinten rechts
14 | … | 3. Bremsleuchte
15 | LED Ausgang 15 | Lichtbalken (roof light bar)
15S | Schaltausgang (befindet sich links vom LED Ausgang 15) | Selbe Funktion als LED Ausgang 15, aber anstatt eines Konstant-Strom Ausgang handelt es sich hierbei um einen Schaltausgang nach Minus (GND, „-“) der bis zu 2 A schalten kann.

# Anschließen der LEDs

Die (+) Anode (normalerweise der lange Anschluss) von allen LEDs wird zusammengeführt und an die Anschlüsse +LED angeschlossen. Um das Löten zu erleichtern hat der Light Controller zwei +LED Anschlüsse.


Jeder der LED Ausgänge ist gedacht um eine einzelne LED anzusteuern. Die Ansteuerung erfolgt mit einem konstanten Strom von bis zu 20 mA. Dies gewährleistet die optimale Funktion handelsüblicher LEDs und einheitliche Helligkeit.


Bitte keinen Widerstand in Serie mit den LEDs verwenden; dies ist nicht nötig da es sich um Konstant-Strom Ausgänge handelt!

Wenn die Versorgungsspannung hoch genug ist, kann man auch 2 LEDs in Serie an einem Ausgang betrieben.


Die benötigte Spannung einer LED hängt von ihrer Farbe ab. Rote und Orange LEDs benötigen ungefähr 1.8 V; Grüne LEDs ungefähr 2.2 V; Weiße LEDs etwa 3.2 V; Blaue LEDs können bis zu 3.6 V benötigen.

Der Light Controller selbst benötigt für die Regelung des Stroms mindestens 0.8 V.

Normalerweise versorgt man den Light Controller über den Fahrtregler, der je nach Modell 5V oder 6V liefert.

Beispiel: Zwei rote LEDs werden in Serie geschaltet, also ist der Spannungsabfall 1.8V mal 2 = 3.6V. Die Stromversorgung ist z.B. 5V. 5V – 3.6V = 1.4V; dies ist mehr als die 0.8V, die der Light Controller für die Stromregelung braucht. Daher funktioniert alles bestens.

Beispiel 2: Eine weiße LED und eine blaue LED werden in Serie geschaltet. Der Spannungsabfall über beide LEDs ist 3.2V + 3.6V = 6.8V. Die Stromversorgung ist z.B. 6V, also nicht hoch genug um beide in Serie geschaltete LEDs zu versorgen.

Es ist jedoch möglich den Light Controller direkt von einer 2S LiPo Batterie zu betreiben. Eine vollständig geladene LiPo Batterie liefert 8.4V. 8.4V – 6.8V = 1.6V, und das ist mehr als die 0.8V, die der Light Controller für die Regelung braucht. Wenn die LiPo Batterie aber entladen wird und die Spannung unter 6.8V + 0.8V = 7.6V fällt, dann werden die LEDs nicht mehr vollständig angesteuert und erscheinen eventuell dunkler als mit einer vollen Batterie.

Wichtig: Wenn der Light Controller direkt von einer 2S LiPo versorgt wird muss man sicherstellen, dass die Installation gut gegen Kurzschlüsse abgesichert ist. Eine LiPo Batterie speichert viel Energie, die im Fehlerfall schnell zu Feuer führen kann.

Weiters erhöht sich mit steigender Spannung die Verlustleistung im Light Controller. Der Light Controller kann dann in gewissen Situationen überhitzen.

# Schaltausgang

Der Light Controller hat einen Schaltausgang der bis zu 2 Ampere schalten kann. Dieser Ausgang wird oft in Verbindung mit einem handelsüblichen Lichtbalken (light bar) verwendet.

Der Schaltausgang befindet sich links vom LED Ausgang 15 und schaltet synchron mit der Funktion, welche dem LED Ausgang 15 zugewiesen wurde.

# Servo-Ausgang

Der Light Controller kann ein kleines Servo synchron mit dem empfangenen Lenksignal ansteuern. Dies kann handlich sein wenn man zu Beispiel ein Lenkrad im Fahrzeug realistisch mit bewegen lassen will. Die Endpunkte und Mittelstellung des Servo Ausgangs kann unabhängig von der Lenkung eingestellt werden (siehe unten).

Wichtig: aus Sicherheitsgründen sollte der Servo-Ausgang nicht für Fahrfunktionen verwendet werden!

Das Signalkabel des Servos muss mit dem OUT/ISP Pin des Light Controller verbunden werden.

Achtung: einige Servos, ins besonders Analog Servos, ziehen den OUT/ISP Pin nach Masse, was verhindert, dass der Light Controller startet. Digital Servos sind zu bevorzugen da sie dieses Problem nicht verursachen.

Der Servo-Ausgang kann auch zur Steuerung eines 2-Gang oder 3-Gang Getriebes konfiguriert werden. Wenn die Getriebesteuerung ausgewählt wurde, dann schalten 1-Klick und 2-Klicks mit CH3/AUX zwischen den Gängen wie folgt:

2-Gang Getriebe: 1-Klick schaltet auf Gang 1, 2-Klicks auf Gang 2.

3-Gang Getriebe: 1-Klick schaltet in den nächst höheren Gang, 2-Klicks schalten in den nächst niedrigen Gang.

Da 1-Klick und 2-Klicks jetzt für das Getriebe verwendet werden, können die einzelnen Lichtstufen jetzt nicht mehr geschaltet werden. Man kann nur alle Lichter ein/ausschalten mit 3-Klicks an CH3/AUX

Wenn das nicht gewünscht ist, kann man als Option das Getriebe von einem Light Program steuern. Zum Beispiel kann man ein Light Program schreiben, dass mit 6-Klicks an CH3/AUX zwischen den Gängen schaltet.

Es besteht auch die Möglichkeit ein Servo direkt vom einem Light Program zu steuern. Wenn die entsprechende Konfiguration gewählt wurde, dann kann man in einem Light Program das Servo auf Werte zwischen -100 (linke Endposition), 0 (Mitte) und +100 (rechte Endposition) setzen. Damit lassen sich einfache elektromechanische Animationen ausführen, wie zum Beispiel die zufällige Bewegung des Kopfes einer Puppe.

# Benutzung

Nachdem die Stromversorgung eingeschaltet wurde, leuchten die Abblendlichter für etwa 2 Sekunden. Während dieser Zeit sollten das Lenk- und Gas-Signal am Sender in Neutral-Stellung sein.

Wenn anstatt des Abblendlichtes die vorderen Blinker leuchten, bedeutet dass der Light Controller (oder Pre-Processor) kein Signal vom Empfänger bekommt. Bitte alles Ausschalten und die Verkabelung überprüfen.

Nach der Initialisierung gehen alle Lichter aus und das System ist bereit.

Es ist ratsam dem Light Controller die Endpunkte von Gas und Lenkung beizubringen. Dazu bewegt man das Lenkrad am Sender ganz nach links, und dann ganz nach rechts. Das Auto vom Boden abheben und sicher halten, dann das Gas voll auf vorwärts und dann voll auf rückwärts – unter Beachtung dass der Antrieb dadurch nicht beschädigt wird.

Während des Fahrens werden die Bremslichter und Rückfahrscheinwerfer automatisch anhand der Gas-Stellung am Sender gesteuert.

Die Blinker können aktiviert werden in dem man Gas und Lenkung für mindestens eine Sekunde in Neutral-Stellung hält, und dann das Lenkrad am Sender in die gewünschte Richtung dreht. Wenn die Blinker an sind, kann man losfahren und die Blinker bleiben an, bis man einige Zeit gerade aus fährt oder die Lenkung in die entgegengesetzte Richtung einschlägt.

Mehrere Funktionen werden manuell durch den Schaltkanal am Sender, der mit CH3 am Light Controller verbunden wurde, gesteuert. Das Bedienkonzept ist dem der bekannten Computer-Maus mit mehreren „Klicks“ angelegt. Man kann durch die Anzahl der „Klicks“, also die Betätigung des Schaltkanals am Sender innerhalb einer kurzen Zeit, von verschiedenen Funktionen wählen.

Ein Klick: Lichtschalter eine Stellung weiter. Mit je einem Klick schaltet man vom Standlicht zum Abblendlicht, weiter zum Fernlicht, und dann den Lichtbalken ein

Zwei Klicks: Lichtschalter eine Stellung zurück; Umkehrfunktion zu Ein Klick

Drei Klicks: Umschalten zwischen alle Lichter an und aus

Vier Klicks: Warnblinker ein/ausschalten

Diese Video zeigt die Bedienung (nur in Englisch verfügbar):

https://youtu.be/-VyNAVU3-ok

# Kanalrichtung ändern

Die Richtung von Gas und Lenk Signal kann am Light Controller umgedreht werden, falls die Funktionen mit dem Fahrzeug nicht übereinstimmen.

Dazu macht man sieben Klicks am Schaltkanal. Die Blinker vorne und hinten auf einer Seite des Fahrzeuges gehen an, und auch die Abblendlichter leuchten. Sonst sind alle Lichter aus. Jetzt bewegt man das Lenkrad am Sender in die Richtung der leuchtenden Blinker. (Beispiel: wenn die Blinker auf der linken Seite leuchten, dreht man das Lenkrad nach links). Wenn der Light Controller das Lenksignal erkannt hat, gehen die Blinker aus.

Jetzt den Gas-Hebel am Sender in Richtung vorwärts betätigen. Wenn der Light Controller das Gas-Signal erkannt hat, gehen die Abblendlichter aus und die normalen Lichtfunktionen sind wieder aktiv.

Die Richtung des Gas- und Lenksignales wird im Light Controller gespeichert, man muss diese Prozedur also nur einmal beim Einrichten eines neuen Fahrzeuges durchführen.

# Lenkrad Servo / Getriebe Servo

Wenn man ein Servo zum Ansteuern eines Lenkrades benutzt, kann man die Mittelstellung und die Endpunkte unabhängig von der Lenkung des Fahrzeuges einstellen.

Dazu macht man acht Klicks am Schaltkanal. Die Blinker links leuchten permanent und das Servo folgt direkt dem Lenkrad am Sender. Das Lenkrad am Sender vorsichtig drehen, bis das Servo die Stellung erreicht, die als „voll Links“ programmiert werden soll. Wichtig: Je nach Drehrichtung des Servo kann das auch bedeuten, dass man das Lenkrad am Sender nach rechts drehen muss, um die gewünschte Stellung des Servo zu erreichen. Das ist so in Ordnung!

Wenn die gewünschte Stellung des Servo erreicht ist, das Lenkrad festhalten und am Schaltkanal einen Klick durchführen.

Jetzt werden die Blinker auf beiden Seiten leuchten. Das Lenkrad am Sender nun so lange bewegen, bis das Servo die gewünschte Mittelstellung erreicht hat. Wieder einen Klick am Schaltkanal durchführen.

Jetzt leuchten die Blinker auf der rechten Seite auf. Jetzt kann man die rechte Endposition wie beschrieben festlegen und mit einem Klick bestätigen.

Alle Positionen des Servos sollten jetzt korrekt sein. Das Lenkrad sollte dem Fahrzeug korrekt folgen. Die Einstellungen werden gespeichert und werde nicht durch Trimmung der Lenkung beeinflusst.

Wenn man die Endpunkte oder Trimmung der Lenkung am Sender verstellt, muss man den Light Controller neu starten sodass er die neuen Einstellungen „lernen“ kann.

# Configurator: Benutzerdefinierte Konfiguration erstellen

Der Light Controller kann mit Hilfe eines Web-Browser konfiguriert werden.

Zuerst bitte folgende Archivdatei laden:

https://github.com/laneboysrc/rc-light-controller/blob/master/mk4-tlc5940-lpc812/mk4-download-me.zip?raw=true

Diese Archiv erhält das Konfigurations-Programm namens configurator.html. Es ist nur in Englisch verfügbar. Diese Datei kann mit dem Web-Browser geöffnet werden (getestet mit Firefox, Chrome und Internet Explorer 10)


Das Konfigurations-Programm kann auch direkt im Internet erreicht werden: http (http://laneboysrc.github.io/rc-light-controller/)s (http://laneboysrc.github.io/rc-light-controller/)://laneboysrc.github.io/rc-light-controller/

Damit hat man immer die letzte Version des Programms in Verwendung.

configurator.html hat die Firmware des Light Controller bereits eingebaut. Man selektiert die gewünschten Optionen und drückt auf den Save firmware Knopf. Dies lädt eine Datei namens light_controller.hex herunter, welches durch den Web-Browser auf die Festplatte gespeichert wird.

Man kann jetzt mit dem LPC81x-ISP Programm, welches auch im Archiv beiliegt, die Firmware in den Light Controller programmieren. Dazu benötigt man einen USB-to-Serial Adapter (USB UART), der an den PC angesteckt wird. Der USB-to-Serial Adapter und der Light Controller müssen wie folgt verbunden werden:


Wichtig: Der Light Controller muss mit dem USB-to-Serial Adapter verbunden werden bevor der USB-to-Serial Adapter an den PC angesteckt wird. Dies ist notwendig weil der OUT/ISP Pin mit (-) GND während des Einschalten der Versorgung verbunden sein muss um die Programmierfunktion zu starten.

Jetzt kann man das LPC81x-ISP Programm starten, Select file… drücken und die light_controller.hex Datei auswählen, die vom configurator.html erzeugt wurde.


Auf den Knopf Program drücken und das Programmieren beginnt.

# Light Programs

Light Programs sind einfache Skripte, mit denen man fast alle Funktionen und Lichter des Light Controller beliebig programmatisch steuern kann, ohne dass Mikrocontroller Firmware geschrieben werden muss.

Ausführliche Dokumentation zu Light Programs gibt es auf https://github.com/laneboysrc/rc-light-controller/blob/master/mk4-tlc5940-lpc812/doc/light-programs.md (nur in English verfügbar)

Mit Light Programs kann man Lauflichter oder Polizei-Blinklichter erstellen. Eine kleine Sammlung von Light Programs gibt es unter https://github.com/laneboysrc/rc-light-controller/tree/master/mk4-tlc5940-lpc812/configurations

# Technische Daten

Stromversorgung: 4 V .. 10 V (Empfänger-Stromversorgung oder bis zu 2S LiPo direkt)

Konstant-Strom Ausgänge: 20 mA pro LED Ausgang

Helligkeitsregelung: Konstant-Strom in 63 Stufen (DC, kein PWM)

LED Konfiguration: Gemeinsame Anode (gemeinsamer Plus-Pol; Minus-Pol geht an die einzelnen LED Ausgänge des Light Controller)

Abmessungen:

Light Controller: 36 x 18 x 3 mm
Pre-processor: 17 x 17 mm
5-Kanal Pre-processor: 24 x 17 mm

Viel Spass! Werner

laneboysrc@gmail.com

http (https://laneboysrc.blogspot.com/)s (https://laneboysrc.blogspot.com/)://laneboysrc.blogspot.com/

http (https://www.youtube.com/user/laneboysrc)s (https://www.youtube.com/user/laneboysrc)://www.youtube.com/user/laneboysrc

https://www.flickr.com/photos/78037110@N03/albums/

https://github.com/laneboysrc/rc-light-controller/

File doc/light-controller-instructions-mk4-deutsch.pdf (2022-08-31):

# RC Light Controller

# Anleitung

Mk4, Mk4P und Mk4S

# Einleitung

Danke, dass Sie den LANE Boys RC Light Controller benutzten!

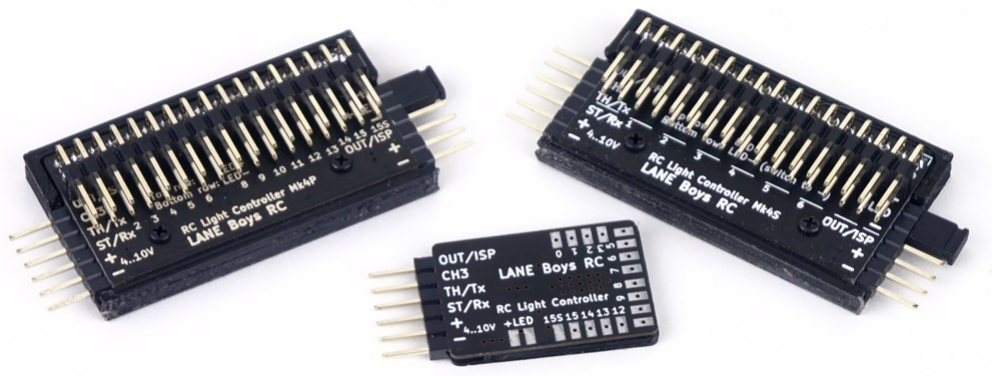
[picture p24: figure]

Der Light Controller unterstützt unter anderem folgende Funktionen:

- 16 LED Ausgänge, mit Konstant-Strom gesteuert um Flickern zu verhindern. Bis zu 20mA pro Ausgang. Je eine LED (oder zwei in Reihe) wird an einem Ausgang angeschlossen.
(nur Mk4 und Mk4P)
- 1 Schaltausgang, bis zu 2A z.B für einen Lichtbalken am Dach. Nicht in der Helligkeit steuerbar.
(Mk4S: 9 Schaltausgänge)
- Zwei Light Controller können kaskadiert werden für insgesamt 32 LED Ausgänge.
- Standlicht, Abblendlicht, Fernlicht und der Lichtbalken können vom Sender aus manuell ein/ausgeschaltet werden
- Brems- und Rückfahrscheinwerfer werden automatisch über das Gas-Signal angesteuert. Die Bremslichter schalten sich für eine kurze, zufällig gewählte Zeit ein wenn das Gas in Neutral-Stellung geht.
- Kombinierte Schlusslicht und Bremslicht Funktion mit nur einer roten LED durch Ansteuerung der Helligkeit (nur Mk4 und Mk4P)

- Separate Bremslichtfunktion für ein 3. Bremslicht
- Die Blinker schalten sich automatisch nur ein, wenn das Fahrzeug für mindestens eine Sekunde in Neutral befindet und man dann die Lenkung links oder rechts betätigt. Damit blinken die Richtungsanzeiger während des Fahren nicht andauernd.
- Warnblinker können vom Sender aus ein/ausgeschaltet werden
- Programmierbarer Servo-Ausgang um zum Beispiel ein Lenkrad im Fahrzeuginnenraum zu bewegen, oder den Kopf einer Puppe. Der Ausgang kann auch für ein schaltbares Getriebe verwendet werden.
- Automatische Mittelstellung- und Endpunkterkennung für Gas und Lenkung
- Licht Skripte (Light Programs) für benutzerdefinierte Lichtanimationen wie z.B. Blaulichter, Lauflichter ...
- Simulation von Glühlampen und schlechter Masse-Verbindung
- Optionaler i-Bus kompatibler Eingang
- Optionaler S.Bus kompatibler input (nur Mk4P Rev 3 oder Mk4 Rev 7 Light Controller)
- Optionaler Pre-Processor (Signalwandler) für Vereinfachung der Verkabelung
- Bis zu 3 AUX Kanäle bei Verwendung des neuen 5-Kanal Pre-Processor
- Alle Funktionen können im Web-Browser konfiguriert werden
http s ://laneboysrc.github.io/rc-light-controller/
- Hardware und Software sind Open Source (MIT Lizenz)
https://github.com/laneboysrc/rc-light-controller/

# Light Controller Varianten

Es gibt drei verschiedene Ausführungen des Mk4 Light Controller:

Mk4: | Der kleinste Light Controller mit Lötanschlüssen
Mk4P: | Entspricht dem Mk4, hat aber 2.54mm Stecker für LEDs
Mk4S: | Neun Schaltausgänge (keine Helligkeitsregelung), auf 2.54mm Stecker für LEDs

Alle Ausführungen sind miteinander Kompatibel. Sie können in Verbindung mit dem optionalen Pre-Processor benutzt werden (siehe unten). Jede Ausführung kann kaskadiert werden, wenn mehr als 16 LED Anschlüsse benötigt werden.
Es ist zum Beispiel möglich, einen Mk4 oder Mk4P zu verwenden um Blinker, Rück/Bremslicht und Rückfahrscheinwerfer zu steuern, und zusätzlich einen Mk4S für einen Lichtbalken, Rock Lights, und Scheinwerfer die hohen Strom benötigen.

Mk4
Dies ist die ursprüngliche Version des Mk4 Light Controller. Der Mk4 hat einen 6-poligen 2.54mm Stecker für Stromversorgung und Servo-Signale, sowie Lötanschlüsse für LEDs.

Der Mk4 hat 16 Konstant-Strom Ausgänge. Jeder Ausgang ist gedacht um eine LED mit bis zu 20mA anzusteuern. Des weiteren gibt es einen Schaltausgang, der bis zu 2A schalten kann.

Mk4P
Der Mk4P ist von der Funktion her identisch mit dem Mk4, aber er hat eine Steckerleiste mit 2.54mm Pin-Abstand, das das Anschließen der LEDs erleichtert.
Die LEDs können entweder vom Empfänger, oder von einer separaten Stromquelle versorgt werden. Des Weiteren gibt es einen Anschluss für ein Servo, oder einen zweiten Light Controller (OUT/ISP).

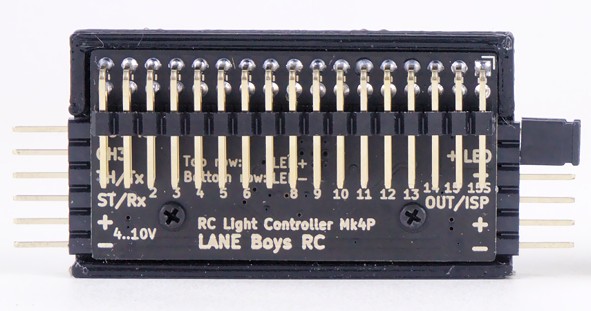
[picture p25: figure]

Genau wie der Mk4 hat der Mk4P 16 Konstant-Strom Ausgänge, gedacht um je eine LED mit bis zu 20mA anzusteuern. Zusätzlich gibt es einen Schaltausgang, der bis zu 2A schalten kann.

Die obere Reihe des LED Steckers führt LED+ (Anode), die unter Reihe führt LED- (Kathode)

Mk4S
Diese Variante des Light Controller hat 9 Schaltausgänge, die nicht in der Helligkeit geregelt werden können. Jeder der 9 Ausgänge kann bis zu 2A schalten.

An allen Ausgängen des Mk4S Light Controller müssen Strombegrenzungs-Widerstände verwendet werden!

Die Helligkeit der LEDs kann beim Mk4S Light Controller nicht gesteuert werden; jeder Ausgang kann nur ein- oder ausgeschaltet werden.

Acht von den Ausgängen (OUT0 .. OUT7) sind auf je zwei LED Anschlüsse geführt. Für OUT8 ist nur ein LED Anschluss verfügbar.

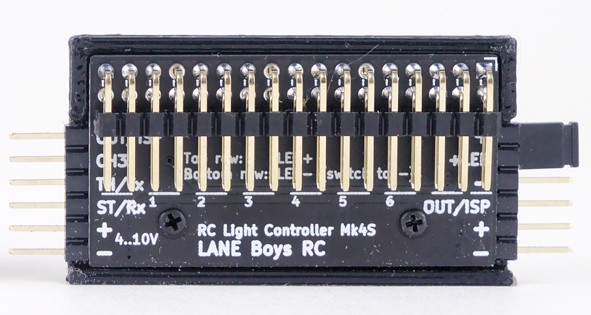
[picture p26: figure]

Der Mk4S Light Controller hat nur 9 Ausgänge: OUT0 .. OUT8. Die Konfiguration anderer Ausgänge (OUT9 .. OUT15) wird intern verarbeitet, steht aber nicht als Anschluss zur Verfügung.

Die obere Reihe des LED Steckers führt LED+ (Anode), die unter Reihe führt LED- (Kathode)

# Light Controller Anschlüsse

Die folgende Tabelle zeigt, wie die Ausgänge des Light Controller im Auslieferungszustand konfiguriert sind.

Alle Funktionen können völlig frei konfiguriert werden. Weiter unten wird beschrieben, wie sie die Funktionen auf ihr Fahrzeug anpassen können.

Name | Funktion | Beschreibung
+ | Stromversorgung, Plus-Pol | +4..10V Eingangsspannung, kommt normalerweise vom Empfänger (rotes Kabel)
- Stromversorgung, Minus-Pol | (GND) | 0-Potential (braunes oder schwarzes Kabel)
ST/Rx | Lenk-Signal Eingang | Lenk-Servo Signal vom Empfänger; oder Pre-Processor-Eingang, i-Bus oder S.Bus
TH/Tx | Gas-Signal Eingang | Gas (Fahrtregler, ESC) Signal vom Empfänger. Wenn ein Pre-Processor verwendet wird kann dieser Anschluss auch als Ausgang konfiguriert werden, ähnlich dem OUT/ISP Anschluss.
CH3 | CH3/AUX Eingang | Kanal 3 (Schaltkanal, AUX) Signal vom Empfänger
OUT/ISP | Ausgang | Multi-Funktionsausgang: Steuern eines Servo; Anschluss eines 2. Light Controller Die Konfiguration wird weiter unten beschrieben.
+LED | LED Stromversorgung | Ausgang zu den Plus-Polen (+, Anode) der LEDs.
OUT0 | LED Ausgang 0 | Standlicht vorne links
OUT1 | … | Standlicht vorne rechts
OUT2 | … | Abblendlicht vorne links
OUT3 | … | Abblendlicht vorne rechts
OUT4 | … | Fernlicht vorne links
OUT5 | … | Fernlicht vorne rechts
OUT6 | … | Blinker vorne links
OUT7 | … | Blinker vorne rechts
OUT8 | … | Kombiniertes Schlusslicht/Bremslicht hinten links
OUT9 | … | Kombiniertes Schlusslicht/Bremslicht hinten rechts
OUT10 | … | Rückfahrlicht hinten links
OUT11 | … | Rückfahrlicht hinten rechts
OUT12 | … | Blinker hinten links
OUT13 | … | Blinker hinten rechts
OUT14 | … | 3. Bremsleuchte
OUT15 | LED Ausgang 15 | Lichtbalken (roof light bar)
OUT15S | Schaltausgang | Selbe Funktion als LED Ausgang 15, aber anstatt

Name | Funktion | Beschreibung
| (befindet sich links vom LED Ausgang 15) | eines Konstant-Strom Ausgang handelt es sich hierbei um einen Schaltausgang nach Minus (GND, „-“) der bis zu 2 A schalten kann.

# Verbinden des Light Controller mit dem Fahrzeug

Normalerweise erhält der Light Controller seine Stromversorgung vom Empfänger. Die folgenden Kapitel beschreiben wie man die Servo Signale vom Empfänger mit den anderen elektronischen Komponenten wie Lenk-Servo und Fahrtregler verbindet. Verwendung eines Pre-Processor
Der Light Controller hat eine Schwesterplatine namens Pre-Processor. Der Pre-Processor agiert als Signal-Multiplexer.

Anstatt die Servo Signale des Empfängers direkt mit dem Light Controller zu verbinden, schaltet man den Pre-Processor dazwischen. Der Pre-Processor packt alle Servo Signal in eine einzelne Datenleitung, die dann zum Light Controller geführt wird. Der Pre-Processor hat auch doppelte Anschlüsse für Lenkung und Gas, sodass die umständlichen Y-Kabel wegfallen.
Der Pre-Processor vereinfacht das Verkabeln: Nur ein handelsübliches Servoverlängerungskabel wird vom Chassis des Fahrzeuges zur Karosserie geführt.
Im Chassis befinden sich Empfänger, Fahrtregler, Lenk-Servo und der Pre-Processor; und in der Karosserie der Light Controller und die LEDs.

3-Kanal Pre-Processor

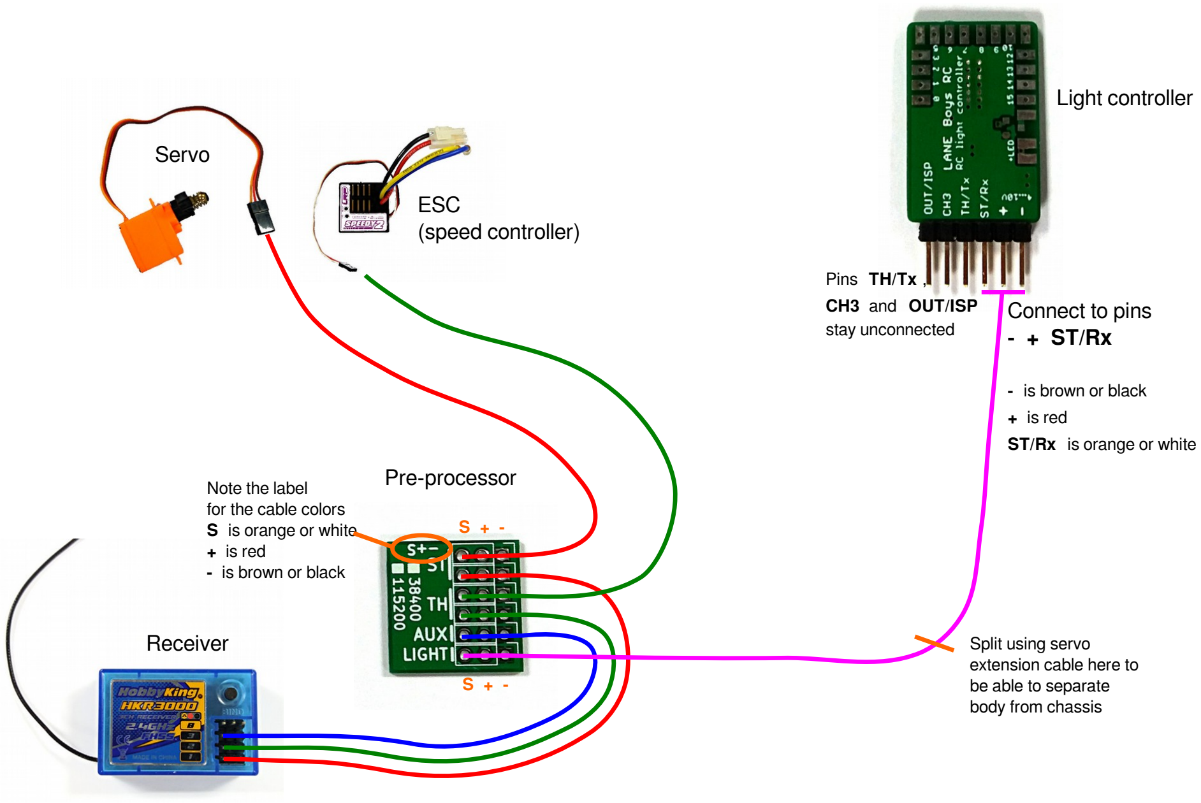
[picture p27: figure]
Servo; ESC (speed controller); Pre-processor; Light controller; Connect to pins - + ST/Rx; - is brown or black + is red ST/Rx is orange or white; Pins TH/Tx , CH3 and OUT/ISP stay unconnected; Receiver; Note the label for the cable colors S is orange or white + is red - is brown or black; Split using servo extension cable here to be able to separate body from chassis

Die Eingänge TH/Tx und CH3 am Light Controller werden nicht benutzt.
Der Pre-Processor ist auch in einer 5-Kanal Variante erhältlich. Dies ermöglicht die Benutzung von zusätzlichen AUX Kanälen, wie man sie oft in modernen Fernsteuerungen findet.
Bei Verwendung des 5-Kanal Pre-Processor kann man separate Schaltkanäle am Sender verwenden um z.B. die Blinker manuell zu steuern, oder die Warnblinker ein/ausschalten. Jeder AUX Kanal kann separat konfiguriert werden.

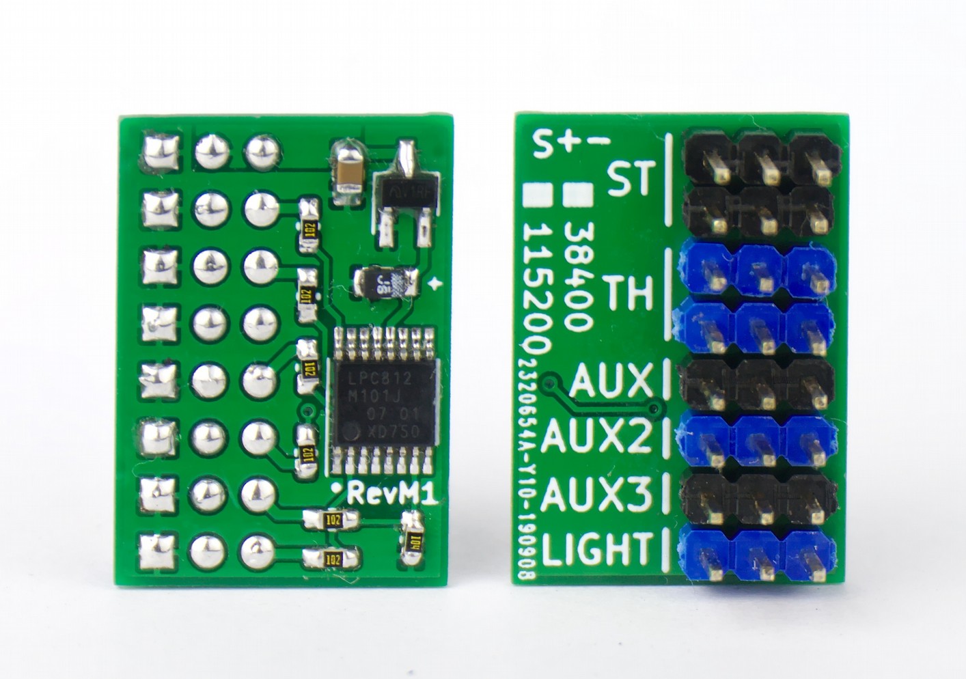
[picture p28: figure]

Direkter Anschluss des Light Controllers an dem Empfänger
Die Eingänge des Light Controller ST/Rx (Lenkung), TH/Tx (Gas) und CH3 (Schaltkanal) werden direkt mit dem entsprechenden Ausgängen am Empfänger verbunden.

Für Lenkung und Gas benötigt man ein Y-Kabel damit man auch den Fahrtregler und das Lenk-Servo gleichzeitig anschließen kann. Das folgende Diagramm zeigt die Verbindungen:

5-Kanal Pre-Processor

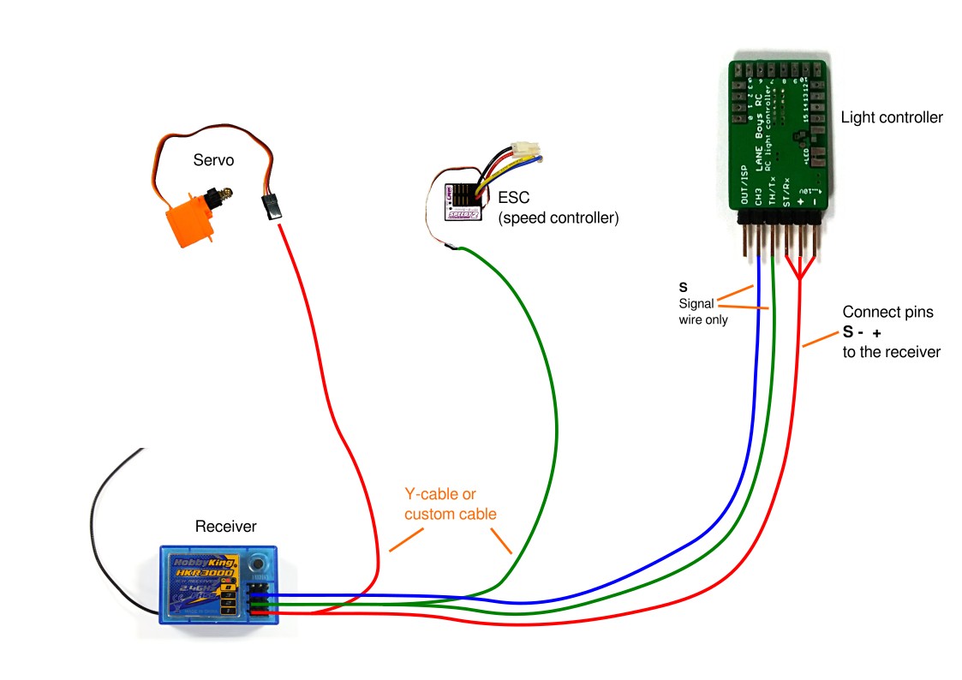
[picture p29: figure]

Nur einer der Kanäle (Lenkung) wird benötigt um die Stromversorgung zum Light Controller zu bringen. Für die anderen Kanäle (Gas, CH3/AUX) ist es ausreichend nur die Signalleitung zum Light Controller zu führen. Die Signalleitung ist meist Orange oder Weiß.
Handelsübliche Servoverlängerungskabel kann man einfach um-konfigurieren, siehe Foto unten:

Verwendung eines Empfängers mit i-Bus kompatiblem Ausgang Wenn eine Fernsteuerung verwendet wird, bei der am Empfänger ein i-Bus kompatibler Ausgang zur Verfügung steht (z.B. FlySky FGr4S) dann man den Light Controller direkt mit dem i-Bus Ausgang mit einem handelsüblichen Servokabel anschließen.

In dieser Konfiguration verwendet der Light Controller die Signale ST (Lenkung), TH (Gas) und bis zu drei AUX Kanäle aus. ST ist Kanal 1 am i-Bus; TH ist Kanal 2; Die AUX Kanäle können auf 3 sequentielle Kanäle zwischen i-Bus Kanal 3 und Kanal 12 konfiguriert werden.

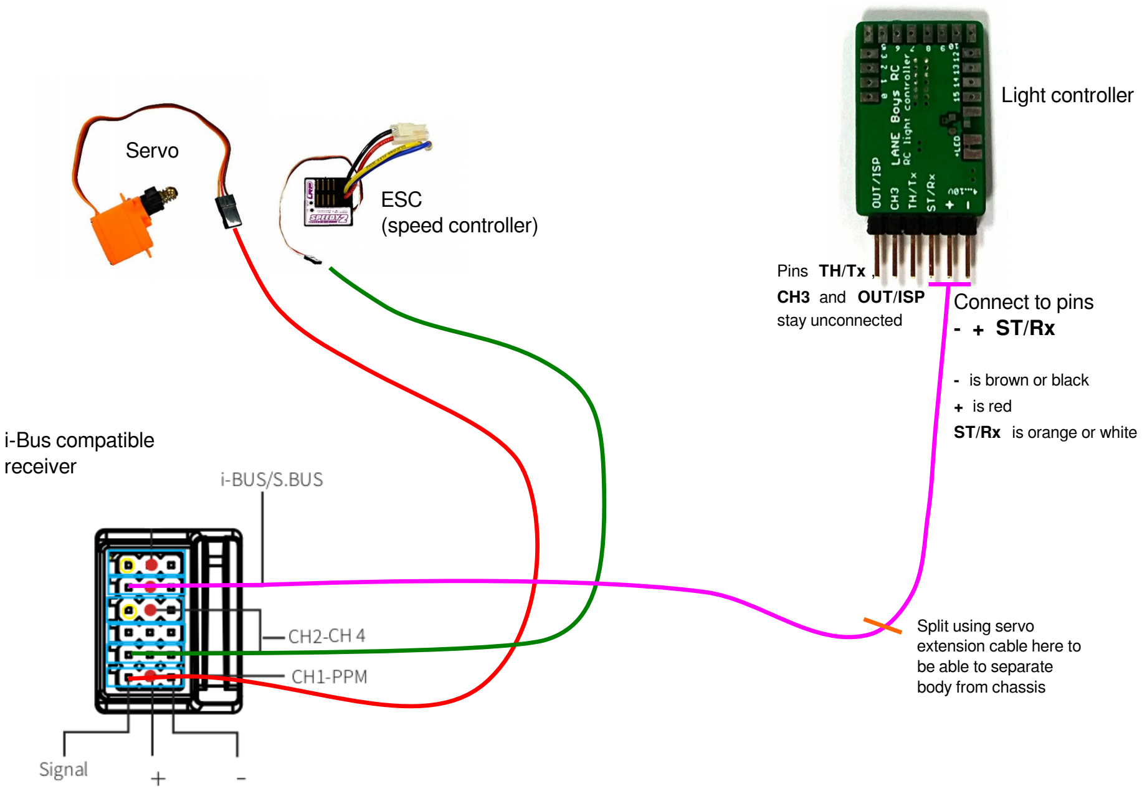
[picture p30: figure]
Servo; ESC (speed controller); Light controller; Connect to pins - + ST/Rx; - is brown or black + is red ST/Rx is orange or white; Pins TH/Tx , CH3 and OUT/ISP stay unconnected; i-Bus compatible receiver; Split using servo extension cable here to be able to separate body from chassis

Verwendung eines Empfängers mit S.Bus kompatiblem Ausgang Wenn eine Fernsteuerung verwendet wird, bei der am Empfänger ein S.Bus kompatibler Ausgang zur Verfügung steht (z.B. Futaba oder FrSky) dann man den Light Controller direkt mit dem S.Bus Ausgang mit einem handelsüblichen Servokabel anschließen (ähnlich wie im Diagramm oben für i-Bus gezeigt).

S.Bus Kompatibilität wird nur den folgenden Hardware revisionen unterstützt:
Mk4P Rev 3 (ab Februar 2022)
Mk4 Rev 7 (ab Juni 2022)

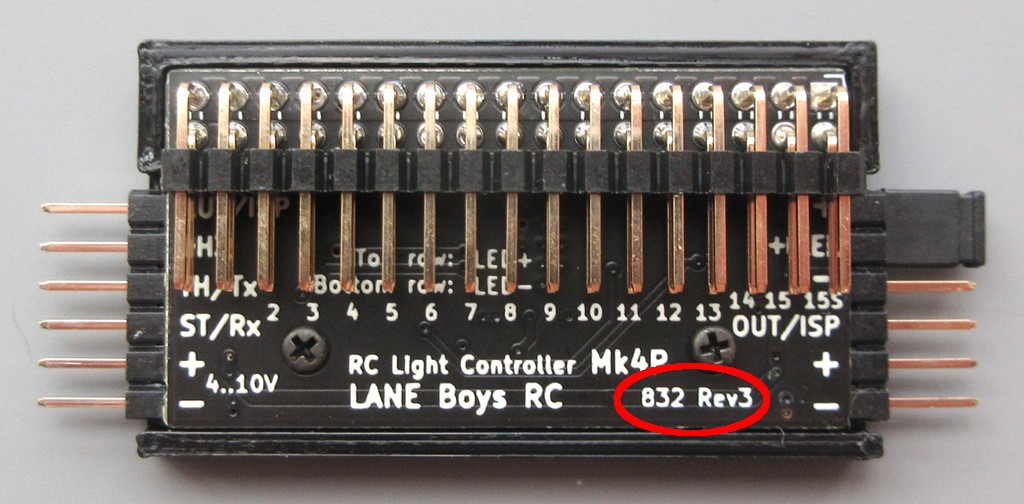
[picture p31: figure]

Um einen Mk4P Rev 3 zu identifizieren, sucht man den Text 832 Rev3 auf der Vorderseite des Mk4P. Wenn dieser Text nicht sichtbar ist, dann wird S.Bus nicht unterstützt.

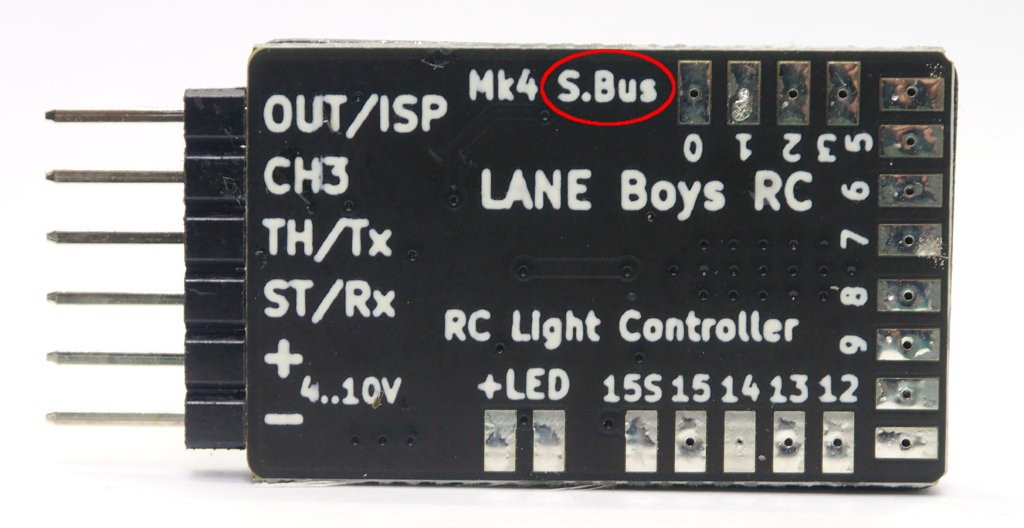
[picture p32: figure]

Um einen Mk4 Rev 7 zu identifizieren, sucht man den Text S.BUS auf dem Mk4. Wenn dieser Text nicht sichtbar ist, dann wird S.Bus nicht unterstützt.

Bei Verwendung von S.Bus stehen dem Light Controller die Signale ST (Lenkung), TH (Gas) und bis zu drei AUX Kanäle zur Verfügung.
ST ist Kanal 1 am S.Bus; TH ist Kanal 2; Die AUX Kanäle können auf 3 sequentielle Kanäle zwischen S.Bus Kanal 3 und Kanal 14 konfiguriert werden.

Verwendung eines im Auto eingebauten Tasters
Wenn nur eine 2-Kanal Fernsteuerung verwendet wird, oder kein AUX Kanal mehr frei ist, dann kann man als Alternative auch einen Taster direkt an den CH3 Eingang des Light Controller anschließen. Der Taster kann irgendwo im Auto versteckt werden.
Der Taster muss zwischen dem CH3 Eingang und – (Minus-Pol; GND) eingebaut werden, wie es das Diagramm weiter unten zeigt.
In der Konfiguration des Light Controller muss die Option „Push button on the light controller“ (Taster direkt am Light Controller) eingestellt werden. Das Konfigurieren wird in einem Kapitel weiter unten erklärt.

Verwendung von zwei Light Controller um 32 LEDs anzusteuern
Wenn die 16 LED Ausgänge des Light Controllers nicht ausreichen, kann ein weiterer Light Controller verwendet werden um insgesamt 32 LED Ausgänge zu erreichen, die alle individuell konfiguriert werden können.
Aus traditionellen Gründen wird dies Master/Slave System genannt. Der Slave Light Controller bekommt eine spezielle Firmware programmiert, die unabhängig von den Lichtfunktionen ist.
Im Master Light Controller wird der Slave-Ausgang freigeschaltet. Damit werden alle 32 Ausgänge konfigurierbar, und es muss nur ein Light Controller mit der Konfiguration des Fahrzeuges versehen werden.

Jede der Light Controller Ausführungen (Mk4, Mk4P und Mk4S) kann sowohl als Master und als Slave verwendet werden.

Bei Verwendung des Mk4P oder Mk4S ist der Anschluss des Slave Light Controller sehr einfach, weil ein separater 3-poliger Anschluss zur Verfügung steht, welcher die Verwendung eines handelsüblichen Servokabels zulässt.

Ein handelsübliches Servoverlängerungskabel reicht für die Verbindung zwischen Master und Slave. Der Slave Light Controller kann dadurch bequem nahe der LEDs eingebaut werden, oder sogar ein einem Anhänger.

Servo

LiPo 2S 7.4V

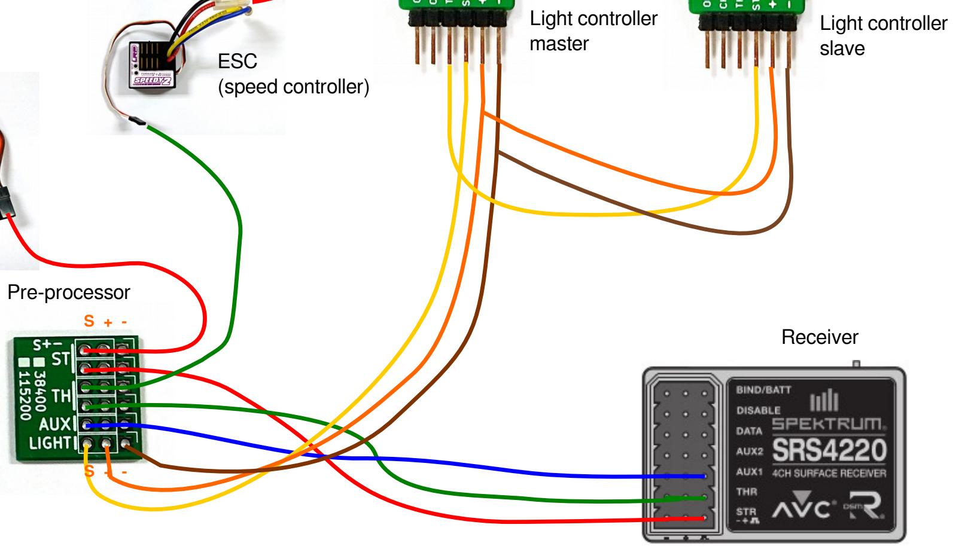
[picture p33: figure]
ESC (speed controller); Pre-processor; Light controller master; Receiver; Light controller slave

Wenn die Konfiguration für Master und Slave erstellt wird ist darauf zu achten, dass bei beiden die gleiche Baudrate eingestellt wird.

Manche Anwender wollen einen zweiten Empfänger plus Batterie und Light Controller in einen Anhänger einbauen. Davon ist abzuraten, weil die folgenden Probleme entstehen:

- Die Taktquelle im Light Controller ist nicht sehr präzise und verändert sich mit Zeit und Temperatur. Daher laufen zum Beispiel die Blinker nicht synchron.
- Einige Funktionen, wie zum Beispiel das Aufleuchten der Bremslichter oder Rückfahrscheinwerfer, werden zufalls-gesteuert. Da die beiden Light Controller eine andere Zufallszahl generieren, leuchten diese Lichter dann nicht mehr synchron.

Diese Probleme existieren nicht bei Verwendung des Master/Slave Systems, da der Master den Takt vorgibt.

# Anschließen der LEDs

Die (+) Anode (normalerweise der lange Anschluss) von allen LEDs wird zusammengeführt und an die Anschlüsse +LED angeschlossen.

ANODE | CATHODE

Konstant-Strom LED Ausgänge
Jeder der LED Ausgänge ist gedacht um eine einzelne LED anzusteuern. Die Ansteuerung erfolgt mit einem konstanten Strom von bis zu 20 mA. Dies gewährleistet die optimale Funktion handelsüblicher LEDs und einheitliche Helligkeit.

Bitte keinen Widerstand in Serie mit den LEDs verwenden (Mk4 und Mk4P); dies ist nicht nötig da es sich um Konstant-Strom Ausgänge handelt!

Die Konstant-Strom Ausgänge sind ideal um normale 3mm oder 5mm (oder SMD) LEDs mit 20mA zu steuern. Sie sind nicht für Hochleistungs-LEDs geeignet.

Für mehr Information lesen sie bitte Anhang A: Alles über LEDs und Verkabelung auf Seite 29.
Schaltausgang OUT15S, und Mk4S
Der Mk4 und Mk4P hat einen Schaltausgang der bis zu 2 Ampere schalten kann. Dieser Ausgang wird oft in Verbindung mit einem handelsüblichen Lichtbalken (light bar) verwendet.

Der Schaltausgang ist als 15S auf der Leiterplatte identifizierbar und schaltet synchron mit der Funktion, welche dem LED Ausgang 15 zugewiesen wurde.

In der Mk4S Ausführung sind alle Ausgänge solche Schaltausgänge. Jeder der Schaltausgänge kann bis zu 2A verkraften.

Für die Schaltausgänge ist die Verwendung eines Vorwiderstandes nötig um den Strom durch die LED zu begrenzen.

Ohne Vorwiderstand wird die LED sofort durchbrennen.

# Ausgangsfunktionen

Der Light Controller kann für bestimmte Hilfsfunktionen auf dem OUT/ISP Anschluss konfiguriert werden. Bei Verwendung des Pre-Processor steht auch der TH/Tx Anschluss als Hilfsausgang zur Verfügung.

Die folgenden Hilfsfunktionen können gewählt werden:
- Servoausgang der dem Lenk-Kanal folgt
- Getriebe-Servo Ausgang
- Servoausgang unter Kontrolle eines Light Programs
- Slave Light Controller Ausgang
- Pre-Processor Ausgang

Diese Hilfsfunktionen können wie folgt gruppiert werden: Servo Funktionen und UART Funktionen (serielle Schnittstelle).
Der Light Controller kann zur gleichen Zeit nur eine Hilfsfunktion aus jeder Gruppe (eine Funktion aus der Servo Gruppe, und eine Funktion aus der UART Gruppe) ausführen.

Die Mk4P and Mk4S Light Controller haben einen 6-poligen Anschluss auf der rechten Seite. Die unteren drei Pole sind kompatibel mit der Servo-Standardbelegung (Minus, Plus, Signal). Der Signalanschluss ist mit OUT/ISP verbunden. Dieser Ausgang ist daher sehr gut zur geeignet um direkt ein Servo oder einen Slave Light Controller anzuschließen.

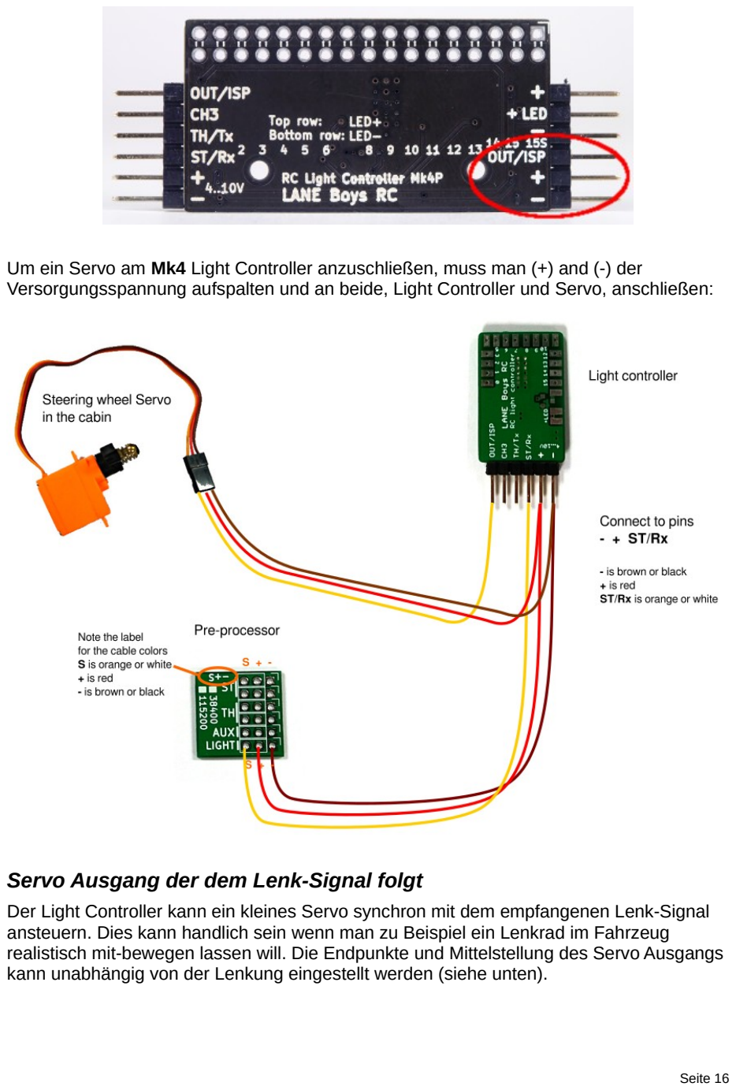
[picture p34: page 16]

Um ein Servo am Mk4 Light Controller anzuschließen, muss man (+) and (-) der Versorgungsspannung aufspalten und an beide, Light Controller und Servo, anschließen:

Servo Ausgang der dem Lenk-Signal folgt
Der Light Controller kann ein kleines Servo synchron mit dem empfangenen Lenk-Signal ansteuern. Dies kann handlich sein wenn man zu Beispiel ein Lenkrad im Fahrzeug realistisch mit-bewegen lassen will. Die Endpunkte und Mittelstellung des Servo Ausgangs kann unabhängig von der Lenkung eingestellt werden (siehe unten).

Aus Sicherheitsgründen sollte der Servo-Ausgang nicht für Fahrfunktionen verwendet werden!

Das Signalkabel des Servos muss mit dem OUT/ISP Ausgang (oder TH/Tx; abhängig von der Konfiguration) des Light Controller verbunden werden.
Achtung: einige Servos, insbesonders Analog Servos, belasten OUT/ISP stark, was verhindert, dass der Light Controller startet. Digital Servos sind zu bevorzugen da sie dieses Problem nicht verursachen.

Getriebe-Servo Ausgang
Der Servo-Ausgang kann auch zur Steuerung eines 2-Gang oder 3-Gang Getriebes konfiguriert werden. Wenn die Getriebesteuerung ausgewählt wurde, dann schalten 1-Klick und 2-Klicks mit CH3/AUX zwischen den Gängen wie folgt:
2-Gang Getriebe: 1-Klick schaltet auf Gang 1, 2-Klicks auf Gang 2.

3-Gang Getriebe: 1-Klick schaltet in den nächst höheren Gang, 2-Klicks schalten in den nächst niedrigen Gang.

Da 1-Klick und 2-Klicks jetzt für das Getriebe verwendet werden, können die einzelnen Lichtstufen jetzt nicht mehr geschaltet werden. Man kann nur alle Lichter ein/ausschalten mit 3-Klicks an CH3/AUX.
Wenn das nicht gewünscht ist, kann man als Option das Getriebe von einem Light Program steuern. Zum Beispiel kann man ein Light Program schreiben, dass mit 6-Klicks an CH3/AUX zwischen den Gängen schaltet.

Servoausgang unter Kontrolle eines Light Program
Es besteht auch die Möglichkeit ein Servo direkt vom einem Light Program zu steuern. Wenn die entsprechende Konfiguration gewählt wurde, dann kann man in einem Light Program das Servo auf Werte zwischen -100 (linke Endposition), 0 (Mitte) und +100 (rechte Endposition) setzen. Damit lassen sich einfache elektromechanische Animationen ausführen, wie zum Beispiel die zufällige Bewegung des Kopfes einer Puppe.

Servo Endpunkte einstellen
Wenn man ein Servo zum Ansteuern eines Lenkrades im Fahrzeuginneren benutzt, kann man die Mittelstellung und die Endpunkte unabhängig von der eigentlichen Lenkung des Fahrzeuges einstellen. Die gleiche Methode erlaubt auch das Programmieren der Endpunkte für ein Getriebe-Servo.
Dazu macht man acht Klicks am Schaltkanal. Die Blinker links leuchten permanent und das Servo folgt direkt dem Lenkrad am Sender. Das Lenkrad am Sender vorsichtig drehen, bis das Servo die Stellung erreicht, die als „voll Links“ programmiert werden soll. Wichtig: Je nach Drehrichtung des Servo kann das auch bedeuten, dass man das Lenkrad am Sender nach rechts drehen muss, um die gewünschte Stellung des Servo zu erreichen. Das ist so in Ordnung!
Wenn die gewünschte Stellung des Servo erreicht ist, das Lenkrad festhalten und am Schaltkanal einen Klick durchführen.

Jetzt werden die Blinker auf beiden Seiten leuchten. Das Lenkrad am Sender nun so lange bewegen, bis das Servo die gewünschte Mittelstellung erreicht hat. Wieder einen Klick am Schaltkanal durchführen.
Jetzt leuchten die Blinker auf der rechten Seite auf. Jetzt kann man die rechte Endposition wie beschrieben festlegen und mit einem Klick bestätigen.
Alle Positionen des Servos sollten jetzt korrekt sein. Das Lenkrad sollte dem Fahrzeug korrekt folgen. Die Einstellungen werden gespeichert und werde nicht durch Trimmung der Lenkung beeinflusst.
Wenn man die Endpunkte oder Trimmung der Lenkung am Sender verstellt, muss man den Light Controller neu starten sodass er die neuen Einstellungen „lernen“ kann.

Slave Light Controller Ausgang
Wenn man diese Option konfiguriert kann man einen zweiten Light Controller anschließen um insgesamt 32 von einander unabhängige LED Ausgänge zu steuern.

Pre-Processor Ausgang
Diese Einstellung ist nicht für Benutzer bestimmt, sie wird intern verwendet um die Firmware des Pre-Processor zu erstellen.
Wenn diese Hilfsfunktion eingeschaltet ist, werden Lenk-, Gas- und CH3-Signal im Light Controller zusammengefasst und als serielles Datenpaket ausgegeben. Das Protokoll ist hier dokumentiert:
https://github.com/laneboysrc/rc-light-controller/blob/master/doc/preprocessor-protocol.md

# Configurator: Benutzerdefinierte Konfiguration erstellen

Jedes Auto ist anders. Die Funktionen des Light Controller können durch Verwenden eines Programms mit dem Namen Configurator an Ihr Fahrzeug angepasst werden.
Der Configurator läuft in modernen Web-Browsern wie Mozilla Firefox, Google Chrome und Microsoft Edge.
Die aktuelle Version des Configurator ist im Internet unter der folgenden Adresse erreichbar:
http s ://laneboysrc.github.io/rc-light-controller/

Alternativ kann man alles, was zur Programmierung des Light Controller nötig ist, hier herunterladen:

https://github.com/laneboysrc/rc-light-controller/blob/master/mk4-tlc5940-lpc812/mk4-download-me.zip?raw=true
Dann benötigt man keine Internetverbindung mehr (z.B im Bastelkeller).
Das Archiv beinhaltet den Configurator (Dateiname configurator.html) sowie das unten beschriebene Programmier-Programm.
Das folgende Video zeigt ab 14:09 den Konfigurationsvorgang (nur in Englisch verfügbar): https://youtu.be/-VyNAVU3-ok?t=849
Der Configurator hat die Firmware des Light Controller bereits eingebaut. Man selektiert die gewünschten Optionen und programmiert den Light Controller mit der erstellten Firmware.

# Firmware aufspielen

Der Light Controller wird mit einer Standard-Firmware ausgeliefert, dessen Konfiguration in der Sektion Light Controller Anschlüsse auf Seite 5 beschrieben ist.
Viele Installation werden aber einen angepasste Konfiguration benötigen, wie im vorigen Kapitel beschrieben. Nachdem die Konfiguration angepasst wurde, muss diese in den Light Controller eingespielt werden.
Dazu bieten wir ein Gerät namens WebUSB Programmer an, mit dessen Hilfe die Firmware direkt aus dem Configurator heraus in den Light Controller programmiert werden kann.

[Es ist auch mögliche – aber komplizierter – die Firmware mit einem handelsüblichen USB-to-Serial Adapter zu programmieren. Diese Methode wird in Anhang D: Den Light Controller mit einem USB-to-Serial Adapter programmieren auf Seite 38 beschrieben.]

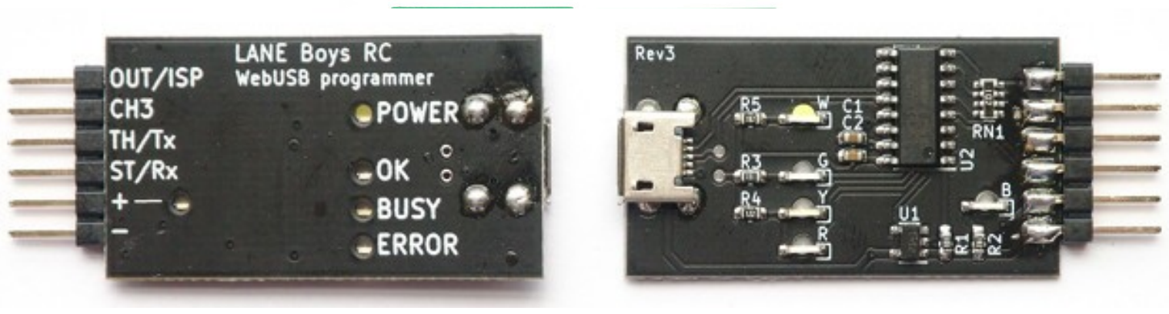
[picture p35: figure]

Der WebUSB Programmer funktioniert direkt in kompatiblen Web Browsern, wie zum Beispiel Google Chrome oder Microsoft Edge, und ist für jedermann leicht in Betrieb zu nehmen. Eine Liste von Web Browsern, die WebUSB Technologie unterstützen findet man unter:
https://caniuse.com/?search=webusb

Achtung: Der WebUSB Programmer funktioniert nicht im Safari und Firefox Browser, weil diese den WebUSB Standard nicht unterstützten.

Der WebUSB Programmer funktioniert unter Linux, Mac OS, und Windows 8.1 oder neuer.

Der WebUSB Programmer benötigt keinen Treiber! Er funktioniert sofort nach dem Anstecken an den Computer.

Verbinden Sie den WebUSB Programmer mit dem Light Controller und dem Computer. Nachdem eine Konfiguration erstellt wurde, wählt man den Reiter Programming im Configurator.

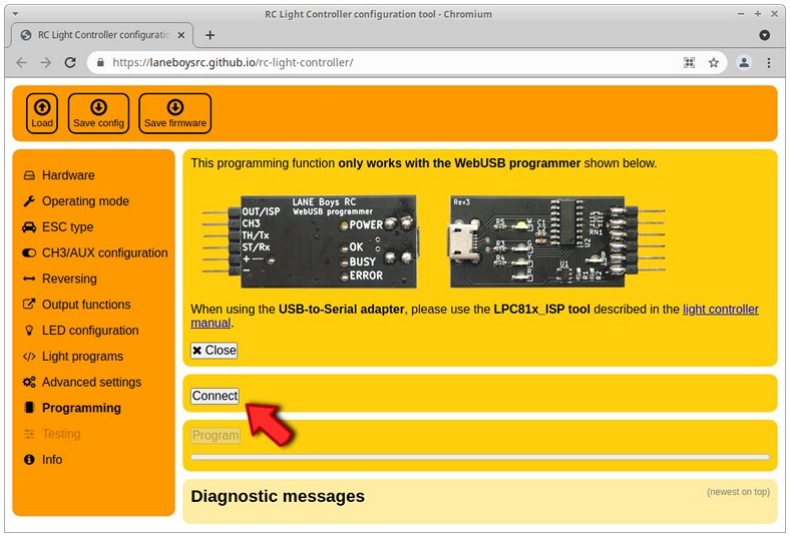
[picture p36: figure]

Bei der ersten Verwendung muss dem Configurator Zugriffsrechte auf die Hardware erteilt werden.
Dazu drückt man auf den Connect Knopf. Der Web Browser zeigt darauf einen Dialog an mit einer Liste von kompatiblen Geräten. Die Liste sollte einen Eintrag namens Programmer zeigen.

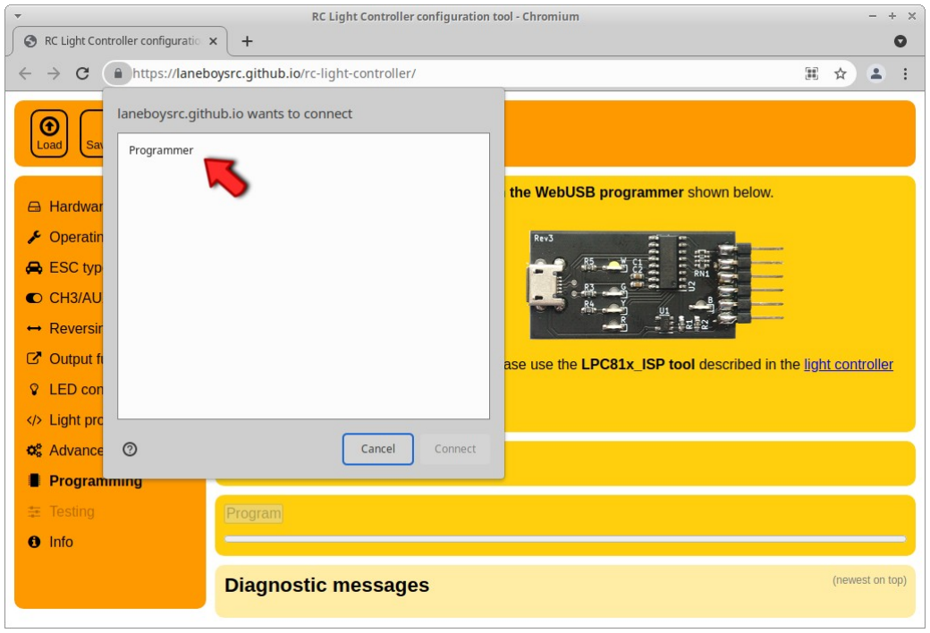
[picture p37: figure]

Wenn der Eintrag nicht vorhanden ist, dann ist der WebUSB Programmer nicht richtig mit dem Computer verbunden, oder das Micro-USB Kabel ist defekt.
Den Eintrag Programmer mit der Maus an-klicken; dies schaltet den Knopf Connect (Verbinden in deutschsprachigen Versionen des Web Browser?) frei.

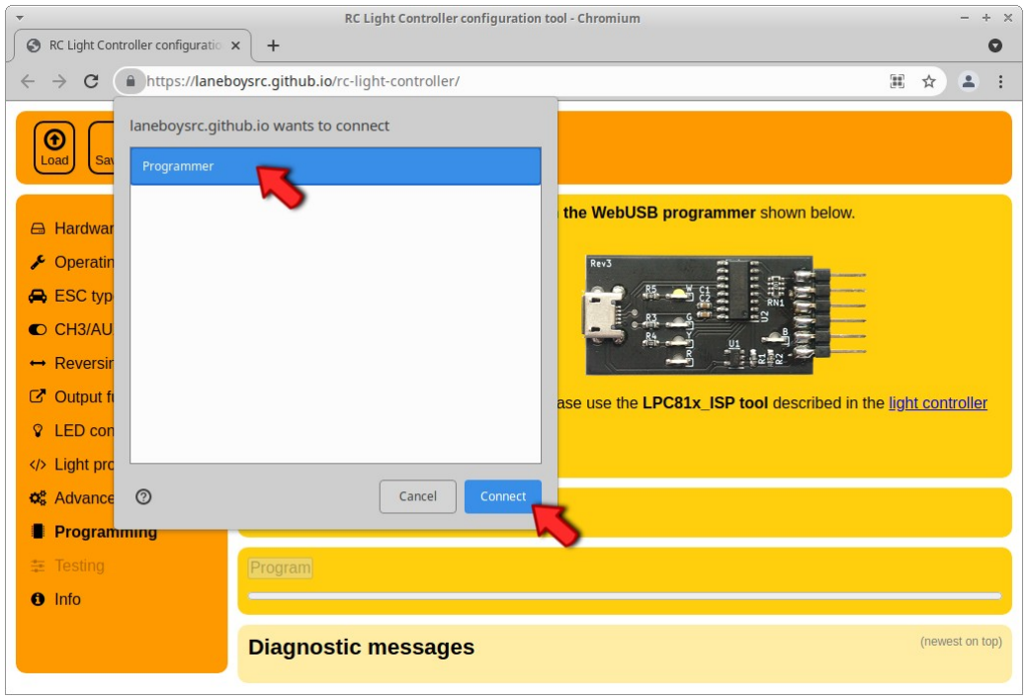
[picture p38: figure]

Den Connect (Verbinden?) Knopf drücken. Damit erlaubt man dem Configurator zugriff auf den WebUSB Programmer, und die grüne LED am WebUSB Programmer leuchtet auf. Dieser Vorgang muss nur einmal ausgeführt werden, da der Web Browser die Zugriffsrechte speichert. Von nun an einfach den WebUSB Programmer anschließen und der Configurator verbindet sich sofort.

Um die Firmware zu laden, drückt man den Program Knopf. Darauf erscheinen Meldungen im Bereich Diagnostics und der Balken zeigt den Fortschritt an. Nachdem die Programmierung erfolgt ist, erscheint eine grüne Meldung im Diagnostics Bereich.

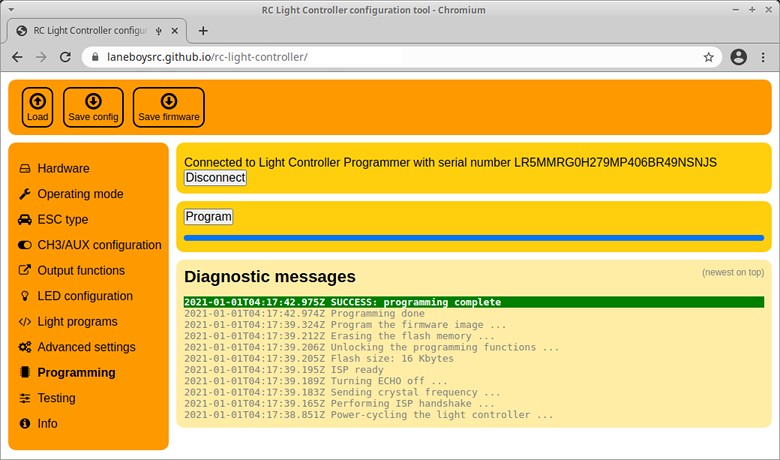
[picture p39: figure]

Wenn der Light Controller für die Verwendung eines Pre-Processors konfiguriert ist, dann kann man mit Hilfe des WebUSB Programmer die Konfiguration auch direkt testen, ohne den Light Controller an das RC System anschließen zu müssen.
Dazu wählt man den Reiter Testing. Dann erscheint ein einfaches Interface das eine Fernsteuerung simuliert.

Das Bild zeigt einen erfolgreichen Programmiervorgang, der direkt im Configurator durchgeführt wurde.

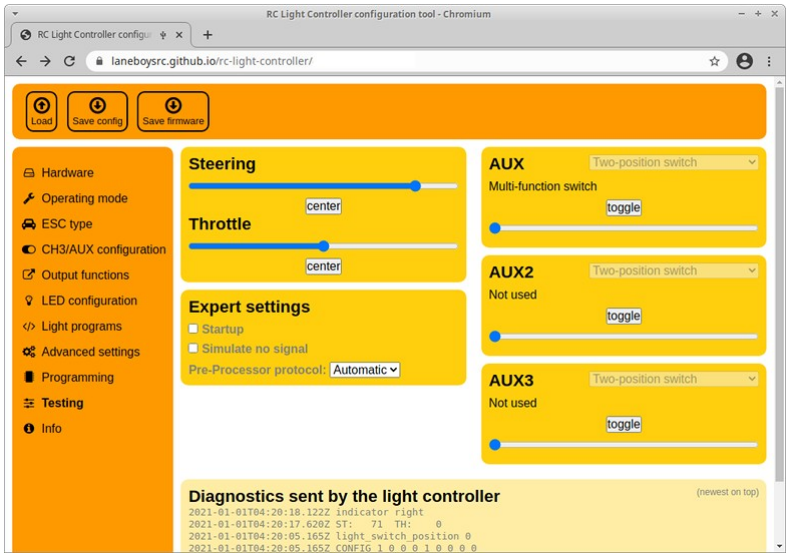
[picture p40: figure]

Wichtig: die Testfunktion steht nur zur Verfügung, wenn der Light Controller für Pre-Processor Betrieb konfiguriert ist. Wenn man den Light Controller im Auto direkt mit den Servo-Kabeln verbinden will, kann man temporär die Konfiguration auf Pre-Processor für Testzwecke umstellen, und dann, wenn alles funktioniert, die Konfiguration zurück auf „Servo inputs“ ändern.

# Benutzung

Nachdem die Stromversorgung eingeschaltet wurde, leuchten die Abblendlichter für etwa 2 Sekunden. Während dieser Zeit sollten das Lenk- und Gas-Signal am Sender in Neutral-Stellung sein.
Wenn anstatt des Abblendlichtes die vorderen Blinker leuchten, bedeutet das, dass der Light Controller (oder Pre-Processor) kein Signal vom Empfänger bekommt. Bitte alles ausschalten und die Verkabelung überprüfen.
Nach der Initialisierung gehen alle Lichter aus und das System ist bereit.
Es ist ratsam dem Light Controller jetzt die Endpunkte von Gas und Lenkung beizubringen. Dazu bewegt man das Lenkrad am Sender ganz nach links, und dann ganz nach rechts. Das Auto vom Boden abheben und sicher festhalten, dann das Gas voll auf

Der Testing Reiter simuliert ein komplettes Fernsteuersystem inklusive Pre-Processor. Damit lässt sich die Konfiguration testen, ohne dass der Light Controller vom Computer getrennt werden muss.

vorwärts und dann voll auf rückwärts – unter Beachtung dass der Antrieb dadurch nicht beschädigt wird.

Bremslichter, Rückfahrscheinwerfer und Blinker
Während des Fahrens werden die Bremslichter und Rückfahrscheinwerfer automatisch anhand der Gas-Stellung am Sender gesteuert.
Die Blinker können aktiviert werden in dem man Gas und Lenkung für mindestens eine Sekunde in Neutral-Stellung hält, und dann das Lenkrad am Sender in die gewünschte Richtung dreht.
Wenn die Blinker an sind, kann man losfahren und die Blinker bleiben an, bis man einige Zeit gerade aus fährt, oder die Lenkung in die entgegengesetzte Richtung einschlägt.

Lichter schalten
Mehrere Funktionen werden manuell durch den Schaltkanal am Sender, der mit CH3 am Light Controller verbunden wurde, gesteuert.
Das Bedienkonzept ist dem der bekannten Computer-Maus mit mehreren „Klicks“ empfunden. Man kann durch die Anzahl der „Klicks“, also die Betätigung des Schaltkanals am Sender innerhalb einer kurzen Zeit, von verschiedenen Funktionen wählen.
Ein Klick: Lichtschalter eine Stellung weiter. Mit je einem Klick schaltet man vom Standlicht zum Abblendlicht, weiter zum Fernlicht, und dann den Lichtbalken ein
Zwei Klicks: Lichtschalter eine Stellung zurück; Umkehrfunktion zu Ein Klick Drei Klicks: Umschalten zwischen alle Lichter an und aus
Vier Klicks: Warnblinker ein/ausschalten

Diese Video zeigt die Bedienung (nur in Englisch verfügbar): https://youtu.be/-VyNAVU3-ok

Der Light Controller unterstützt verschiedene Sender-seitige Schalter Typen. Lesen Sie bitte Anhang F: AUX Schalter Typ erkennen für weitere Informationen.

Kanalrichtung ändern
Die Richtung von Gas- und Lenk-Signal kann am Light Controller umgedreht werden, falls die Funktionen nicht mit dem Fahrzeug übereinstimmen.
Dazu macht man sieben Klicks am Schaltkanal. Die Blinker vorne und hinten auf einer Seite des Fahrzeuges gehen an, und auch die Abblendlichter leuchten. Sonst sind alle Lichter aus. Jetzt bewegt man das Lenkrad am Sender in die Richtung der leuchtenden Blinker. (Beispiel: wenn die Blinker auf der linken Seite leuchten, dreht man das Lenkrad nach links). Wenn der Light Controller das Lenksignal erkannt hat, gehen die Blinker aus. Jetzt den Gas-Hebel am Sender in Richtung vorwärts betätigen. Wenn der Light Controller das Gas-Signal erkannt hat, gehen die Abblendlichter aus und die normalen Lichtfunktionen sind wieder aktiv.

Die Richtung des Gas- und Lenksignales wird im Light Controller gespeichert, man muss diese Prozedur also nur einmal beim Einrichten eines neuen Fahrzeuges durchführen.

Die Richtung aller Kanäle kann auch im Configurator angepasst werden.

# Light Programs

Light Programs sind einfache Skripte, mit denen man fast alle Funktionen und Lichter des Light Controller beliebig programmatisch steuern kann, ohne dass Mikrocontroller Firmware geschrieben werden muss.
Ausführliche Dokumentation zu Light Programs gibt es auf https://github.com/laneboysrc/rc-light-controller/blob/master/mk4-tlc5940-lpc812/doc/light-programs.md (https://github.com/laneboysrc/rc-light-controller/blob/master/mk4-tlc5940-lpc812/doc/light-programs.md) (nur in Englisch verfügbar)
Mit Light Programs kann man zum Beispiel Lauflichter oder Polizei-Blinklichter erstellen. Eine kleine Sammlung von Light Programs gibt es unter https://github.com/laneboysrc/rc-light-controller/tree/master/mk4-tlc5940-lpc812/configurations (https://github.com/laneboysrc/rc-light-controller/tree/master/mk4-tlc5940-lpc812/configurations)

# Technische Daten

Parameter | Mk4 | Mk4P | Mk4S
Versorgungsspannung | 4V .. 10V
Konstant-Strom Ausgänge 20mA pro LED Ausgang | 16 | 16 | –
Helligkeitsregelung | 63 Stufen DC, kein PWM | 63 Stufen DC, kein PWM | (keine Helligkeitssteuerung)
Schaltausgang 2A max pro Ausgang | 1 | 1 | 9 8 Ausgänge mit je zwei 2-pol Anschlüssen, 1 Ausgang mit einem 2-pol Anschluss
LED configuration | Gemeinsame Anode Gemeinsamer Plus Pol; Minus Pol geht zu den individuellen LED Ausgängen
Abmessungen | 38 × 19 × 3mm | 62 × 27.5 × 9.5mm | 62 × 27.5 × 9.5mm
Abmessungen (ohne Stecker und Gehäuse) | 29 × 18 × 2.5mm | 44 × 23 × 3mm | 44 × 23 × 3mm
Pre-Processor: | 17 × 17 mm
5-channel Pre-Processor: 24 × 17 mm

Viel Spaß! Werner

laneboysrc@gmail.com

http s ://www.youtube.com/user/laneboysrc https://github.com/laneboysrc/rc-light-controller/
http s ://laneboysrc.blogspot.com/ https://www.flickr.com/photos/78037110@N03/albums/

# Anhang A: Alles über LEDs und Verkabelung

Was für LEDs können verwendet werden?
Fast jede 3mm, 5mm oder kleine SMD LED kann verwendet werden, solange sie für 20 mA Strom bei einer Vorwärts-Spannung von 3.6 V ausgelegt ist.

Der oben stehende Satz gilt für LEDs, die an einen Konstant-Strom Ausgang am Light Controller angeschlossen werden sollen.

An den Schaltausgängen kann jede beliebige LED angeschlossen werde, solange sie weniger als 2 A benötigt. Es muss aber eine für eine ausreichend hohe Versorgungsspannung und Strombegrenzung gesorgt werden.

Extrem helle LEDs, die mehr als 20 mA benötigen, oder LEDs die aus mehreren LED-Chips bestehen sind nicht geeignet.

Standard 3mm, 5mm, 0402 SMD, 0603 SMD, 0805 SMD, 1206 SMD LEDs sollten problemlos funktionieren.

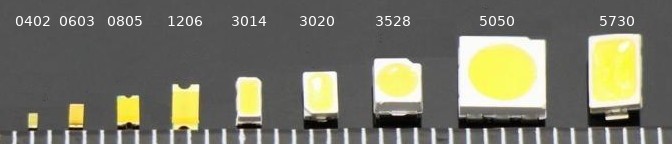
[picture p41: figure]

Größere SMD LEDs, z.B. 3528 oder 5730, sind meist Hochleistungs-LEDs die einen großen Strombedarf haben. Diese LEDs sind nicht geeignet um an einen Konstant-Strom Ausgang angeschlossen zu werden. Ob eine LED geeignet ist, kann man anhand des Datenblattes der LED herausfinden (20 mA bei <3.6 V).

Wie verbindet man das + Kabel von 16 LEDs mit den nur zwei +LED Lötanschlüssen am Mk4 Light Controller?
Der Mk4 Light Controller ist sehr kein und bietet nur zwei +LED Anschlüsse.

Die Design-Idee ist, dass die Anode (Plus Pol) der LEDs bereits gleich in unmittelbarer Nähe der LEDs zusammen geschaltet wird. Dann führt man nur ein einziges Kabel von den LEDs vorne und hinten zum Light Controller.

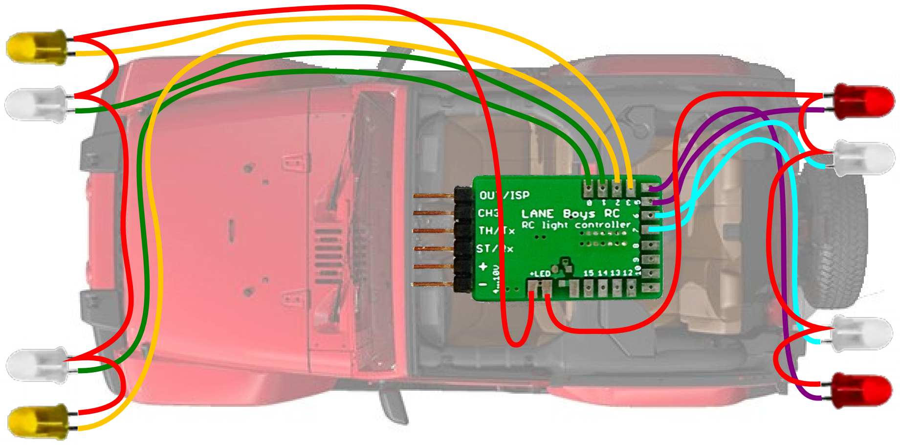
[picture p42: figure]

Als Alternative kann man den Mk4P Light Controller verwenden, der für jeden LED Ausgang separat einen +LED Anschluss bietet.

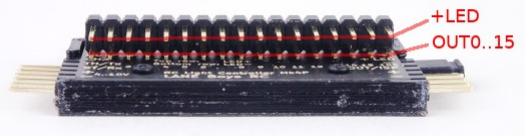
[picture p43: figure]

Verwendung einer separaten Stromversorgung für die LEDs Normalerweise ist es ausreichend wenn der Light Controller vom BEC (meist im Fahrtregler eingebaut) versorgt wird, wie auch Empfänger und Servos.
Man kann die LEDs aber auch von einer separaten Stromquelle versorgen. Der Light Controller erhält seine Versorgung aber nach wie vor über den BEC.
Dies kann zum Beispiel hilfreich sein, wenn man einen 12V Lichtbalken verwenden will. Das folgende Schaltbild zeigt einen Lichtbalken, der direkt von der LiPo Batterie des Fahrzeuges versorgt wird. Die anderen LEDs werden weiterhin vom BEC versorgt:

Die Stromquelle kann eine separate Batterie sein, aber auch die Fahrbatterie, oder ein separater DC/DC Spannungswandler.
Diese Methode der LED Stromversorgung kann für alle Ausgänge (Konstant-Strom oder Schaltausgang) angewendet werden.

Bei den Konstant-Strom Ausgängen muss die Gesamt-Verlustleistung beachtet werden. Sie darf 2.5W nicht überschreiten.

Die Verlustleistung für die Konstant-Strom Ausgänge kann wie folgt berechnet werden: (Versorgungsspannung minus LED-Spannung) mal LED-Strom
Beispiel: 8.4V Versorgungsspannung, 3V LED Spannung, 20mA LED Strom
(8.4V – 3V) × 0.02A = 0.108W (pro LED Ausgang!)

Beim Mk4 Light Controller sind die +LED Lötanschlüsse direkt auf der Platine mit dem + der Eingangsspannung verbunden. +LED darf daher nicht benutzt werden, wenn die LEDs von einer externen Stromversorgung gespeist werden sollen.
Am Mk4P und Mk4S Light Controller ist ein separater Stecker für den Anschluss von +LED vorgesehen. Es wird ein Kurschluss-Stecker (Jumper) mitgeliefert, den man verwendet um +LED vom BEC (Fahrtregler) zu speisen.
Wenn man den Kurzschluss-Stecker absteckt, kann man +LED mit einer externen Stromquelle verbinden.

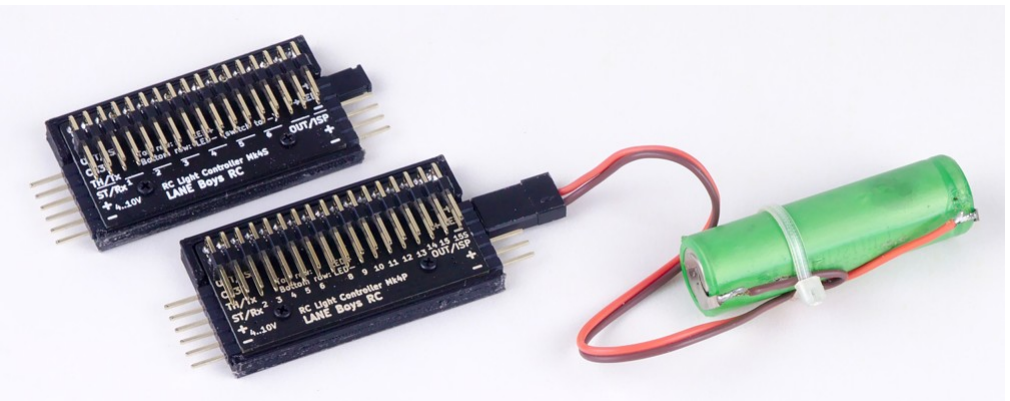
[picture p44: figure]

Der Light Controller oben hat den Kurzschluss-Stecker installiert und daher werden die +LED Leitungen über den Fahrtregler versorgt.
Der untere Light Controller hat anstatt des Kurzschluss-Steckers eine Batterie an +LED und – angeschlossen.

Serienschaltung von LEDs
Abhängig von der Höhe der Versorgungsspannung und der LED Spannung ist es eventuell möglich zwei LEDs in Serie zu betreiben, um Ausgänge zu sparen:

Die LED Spannung hängt in der Regel von der Farbe ab:
- Rot und Orange LEDs benötigen etwa 1.8V
- Grüne LEDs etwa 2.2V
- Weisse LEDs etwa 3.2V
- Blaue LEDs können bis zu 3.6V benötigen

Am besten immer die LED Spannung aus dem Datenblatt der LEDs verwenden.

Der Light Controller selbst benötigt für die Regelung des Stroms mindestens 0.8V. Normalerweise versorgt man den Light Controller über den Fahrtregler, der je nach Modell 5V oder 6V liefert.

Beispiel: Zwei rote LEDs werden in Serie geschaltet.
...also ist der Spannungsabfall 1.8V mal 2 = 3.6V.
Die BEC Spannung ist 5V.
5V – 3.6V = 1.4V, dies ist mehr als die 0.8V, die der Light Controller für die Stromregelung braucht. Daher funktioniert alles bestens.

Beispiel 2: Eine weiße LED und eine blaue LED werden in Serie geschaltet.
Der Spannungsabfall über beide LEDs ist 3.2V + 3.6V = 6.8V.
Die Stromversorgung ist 6V, also nicht hoch genug um beide in Serie geschaltete LEDs zu versorgen.

Es ist jedoch möglich den Light Controller direkt von einer 2S LiPo Batterie zu betreiben. Eine volle LiPo Batterie liefert 8.4V.
8.4V – 6.8V = 1.6V, und das ist mehr als die 0.8V, die der Light Controller für die Regelung braucht.
Wenn die LiPo Batterie aber entladen wird und die Spannung unter 6.8V + 0.8V = 7.6V fällt, dann werden die LEDs nicht mehr vollständig angesteuert und erscheinen eventuell dunkler als mit einer vollen Batterie.

Wenn der Light Controller direkt von einer 2S LiPo versorgt wird muss man sicherstellen, dass die Installation gut gegen Kurzschlüsse abgesichert ist. Eine LiPo Batterie speichert viel Energie, die im Fehlerfall schnell zu Feuer führen kann.

Des Weiteren erhöht sich mit steigender Spannung die Verlustleistung im Light Controller. Der Light Controller kann dann in gewissen Situationen überhitzen.

LEDs parallel schalten
Es ist generell nicht ratsam, LEDs parallel zu schalten. LEDs sind nicht-lineare Bauteile – eine kleine Änderung in der Spannung kann eine große Änderung im Strom verursachen. Wenn zwei parallel-geschaltete LEDs eine verschiedene Nennspannung aufweisen, dann wird eine LED mehr Strom ziehen als die Andere und daher heller leuchten und mehr erhitzen.
In der Praxis wird das parallel schalten jedoch trotzdem häufig angewendet um Geld zu sparen. Dies wird auch ermöglicht, weil moderne LEDs nur geringe Toleranzen aufweisen.

Nur LEDs vom gleichen Hersteller, Typ und der selben Farbe können parallel geschaltet werden.

Wenn zwei LEDs parallel geschaltet werden, halbiert sich der Strom durch jede LED. Eine potentielle Anwendung für parallel-schalten sind Begrenzungslichter oder Rückfahrscheinwerfer, wo die volle Helligkeit der LEDs nicht benötigt wird. Damit kann man sich die Verkabelung eventuell erleichtern und Ausgänge sparen.
Trotzdem: im Idealfall wird jede LED auf ihren eigenen Ausgang des Light Controllers angeschlossen. Parallel-schalten sollte nur in Ausnahmefällen angewandt werden.

# Anhang B: Berechnen des Vorwiderstand Wertes für LED und Lichtbalken

LEDs sind aktive Halbleiter mit einer nicht-linearen Relation zwischen Spannung und Strom. Eine kleine Erhöhung der Spannung kann eine große Änderung des Stromes verursachen.
Des weiteren wird diese Relation von anderen physikalischen Eigenschaften, wie zum Beispiel Temperatur, beeinflusst. Wenn die LED heiß wird, nimmt sie sich mehr Strom bei gleicher Spannung, und wird dadurch noch heißer – bis sie durchbrennt.
Um dies zu vermeiden verwendet man im allgemeinen einen Vorwiderstand, der den Strom durch die LED begrenzt. Nur so lässt sich eine LED sicher an einer Konstant-Spannungsquelle (wie zum Beispiel einer Batterie, oder dem Fahrtregler) betreiben.

Ausgänge OUT0 bis OUT15 des Mk4 und Mk4P Light Controller sind Konstant-Strom Ausgänge, bei denen der Strom geregelt wird. Daher benötigt man bei diesen Ausgängen keinen Vorwiderstand.

Jedoch für LEDs, die an OUT15S des Mk4 oder Mk4P angeschlossen werden, oder an einen beliebigen Ausgang des Mk4S (Schalt-Version), benötigen unbedingt einen Vorwiderstand zur Strombegrenzung.

Widerstands-Werteberechnung für eine einzelne LED
Die Formel ist sehr einfach:

Widerstandswert = (Versorgungsspannung minus LED-Spannung) geteilt durch LED-Strom

Die LED Spannung entnimmt man am besten dem Datenblatt. Wenn das nicht vorhanden ist, kann man folgende Richtlinie verwenden:
- Rot und Orange LEDs benötigen etwa 1.8V
- Grüne LEDs etwa 2.2V
- Weisse LEDs etwa 3.2V
- Blaue LEDs können bis zu 3.6V benötigen

Diese Richtwerte gilt für herkömmliche 3mm und 5mm LEDs, sowie kleine SMD LEDs. Hochleistungs-LEDs können ganz andere Werte haben, da hilft nur das Datenblatt weiter.

Beispiel: Versorgungsspannung: 6V. Orange LED mit 2V. Gewünschter Strom: 20mA

(6V – 2V) / 0.02A = 200 Ohm → nächst-höherer Standard Wert wäre 220 Ohm

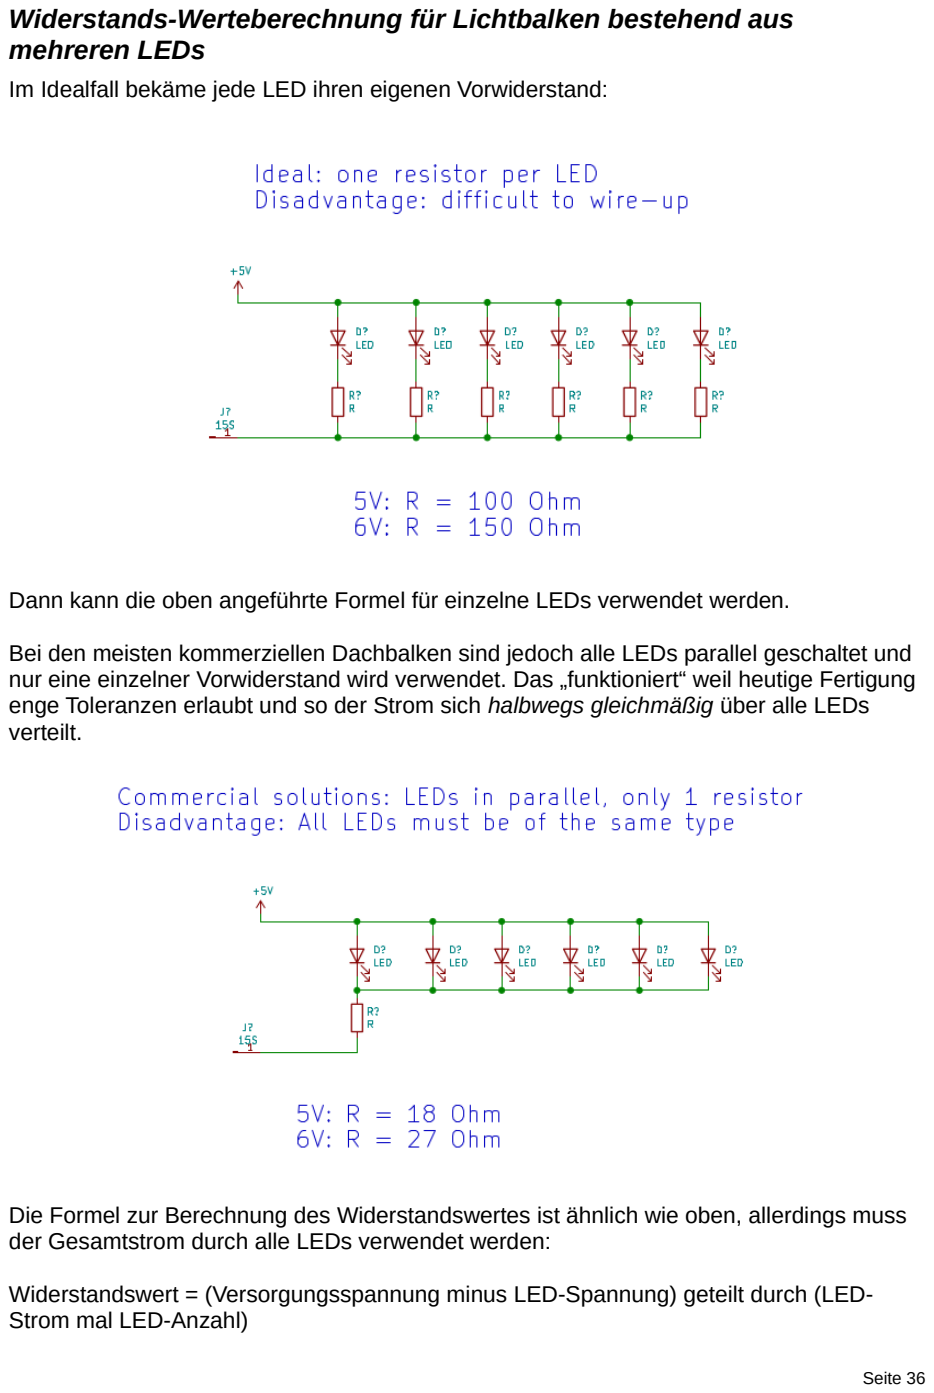
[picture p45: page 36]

Widerstands-Werteberechnung für Lichtbalken bestehend aus mehreren LEDs
Im Idealfall bekäme jede LED ihren eigenen Vorwiderstand:

Dann kann die oben angeführte Formel für einzelne LEDs verwendet werden.

Bei den meisten kommerziellen Dachbalken sind jedoch alle LEDs parallel geschaltet und nur eine einzelner Vorwiderstand wird verwendet. Das „funktioniert“ weil heutige Fertigung enge Toleranzen erlaubt und so der Strom sich halbwegs gleichmäßig über alle LEDs verteilt.

Die Formel zur Berechnung des Widerstandswertes ist ähnlich wie oben, allerdings muss der Gesamtstrom durch alle LEDs verwendet werden:

Widerstandswert = (Versorgungsspannung minus LED-Spannung) geteilt durch (LED-Strom mal LED-Anzahl)

Beispiel: Versorgungsspannung: 6V. Weiße LEDs mit einer Spannung von 3V. Gewünschter Strom pro LED: 20mA. Anzahl der LEDs: 6.

(6V – 3V) / (0.02A × 6) = 25 Ohm → nächster Standardwert = 27 Ohm

Die Verlustleistung des Widerstandes muss beachtet werden!

Die Energie, die der Vorwiderstand vernichten muss, kann sehr hoch sein. Dies führt zu starker Erhitzung und eventuell zum Ausfall des Widerstandes, wenn er nicht richtig dimensioniert wurde.

Die Verlustleistung im Vorwiderstand kann wie folgt berechnet werden:

Verlustleistung = (Versorgungsspannung minus LED-Spannung) mal LED-Strom mal LED-Anzahl

Beispiel: Versorgungsspannung: 6V. Weiße LEDs mit einer Spannung von 3V. Gewünschter Strom pro: 20mA. Anzahl der LEDs: 6.

(6V – 3V) × 0.02A × 6 = 0.36W

In diesem Beispiel wäre mindestens ein Halb-Watt Widerstand nötig. Ein kleiner ¼-Watt Widerstand würde schnell durchbrennen.

# Anhang C: Wasserfestigkeit

Der Light Controller ist nicht gegen Wasser geschützt.

Um den Light Controller von Nässe fern zu halten wird er am besten in eine wasserdichte Dose eingebaut, die möglichst hoch im Fahrzeug angebracht wird. Durchführungen der Kabel sollten abgedichtet werden.

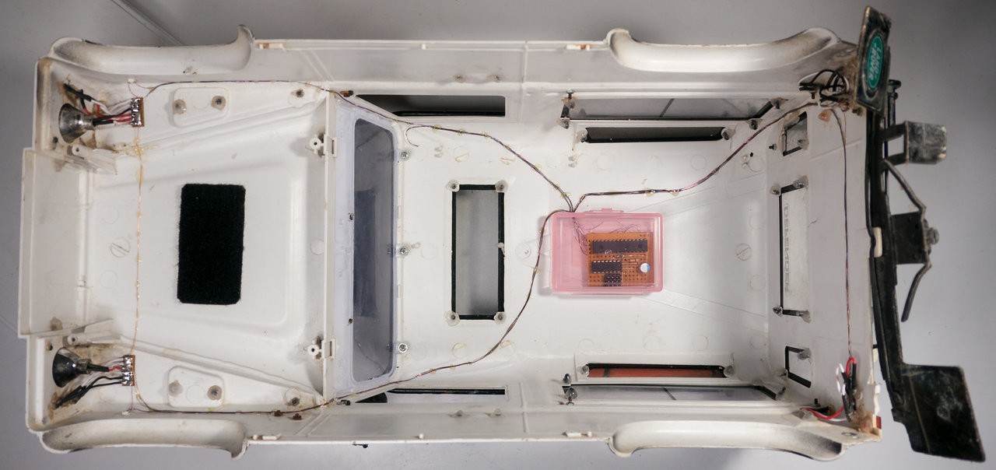
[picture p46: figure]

# Anhang D: Den Light Controller mit einem USB-to-Serial Adapter programmieren

Man kann den Light Controller auch mit einem handelsüblichen USB-to-Serial Adapter programmieren.
Dazu muss erst ein Treiber, der zu dem USB-to-Serial Adapter passt und vom Hersteller geliefert wird, installiert werden.
Nachdem man einen Konfiguration im Configurator erstellt hat, drückt man auf Save firmware image...
Dann wird eine Datei names light_controller.hex im Download Ordner des Computers gespeichert.

Der USB-to-Serial Adapter muss mit dem Light Controller wie folgt verbunden werden:

USB-to-Serial | Light Controller
GND (–) ↔ – (Stromversorgung) VCC (+) ↔ + (Stromversorgung)
TX ↔ ST/Rx
RX ↔ TH/Tx
GND ↔ OUT/ISP

Bitte beachten: Das TX (transmit) Signal des USB-to-Serial Adapter wird mit dem RX (receive) Signal am Light Controller verbunden, und vice-versa.

Der Light Controller muss mit dem USB-to-Serial Adapter verbunden werden bevor der USB-to-Serial Adapter an den PC angesteckt wird.

Dies ist notwendig weil der OUT/ISP Pin mit (-) GND während des Einschalten der Versorgung verbunden sein muss um die Programmierfunktion zu starten.

Wenn die Hardware angeschlossen ist, kann man einen von zwei Methoden wählen um die .HEX Datei in den Light Controller einzuspielen.

Web Serial API
Web Serial API ist einen neue Technologie die es Web Seiten erlaubt Serielle Schnittstellen direkt anzusprechen.
Web Serial API funktioniert mit Google Chrome, Microsoft Edge, oder anderen Browsern die auf der Chrome Engine basieren. Eine Liste von unterstützten Browsern findet man hier:
https://caniuse.com/?search=web- (https://caniuse.com/?search=web-serial) serial (https://caniuse.com/?search=web-serial)

Wir haben eine einfache Web Seite erstellt, mit dem man über das Web Serial API den Light Controller programmieren kann. Die Web Seite befindet sich hier: https://laneboysrc.github.io/rc-light-controller/webserial-programmer.html
Den USB-to-Serial Adapter verbinden, die .HEX Datei laden, und dann programmieren.

LPC81x-ISP tool
Wir haben ein einfaches Programm namens LPC81x-ISP erstellt, mit dem man den Light Controller programmieren kann. Das Programm ist Open Source. Es ist hier verfügbar: https://github.com/laneboysrc/LPC81x-ISP-tool
Das Programm wurde in der Programmiersprache Python entwickelt (https://www.python.org).
Das Programm kann unter Windows, Linux und Mac OS ausgeführt werden. Für Microsoft Windows gibt es eine direkt ausführbare Datei hier:

https://github.com/laneboysrc/rc-light-controller/blob/master/mk4-tlc5940-lpc812/mk4-download-me.zip?raw=true

Das LPC81x-ISP Programm starten, Select file… drücken und die light_controller.hex Datei auswählen, die vom Configurator erzeugt wurde.

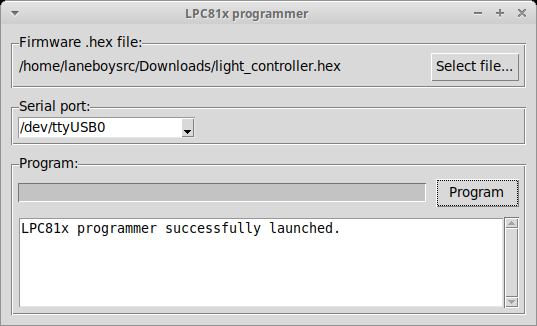
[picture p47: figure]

Auf den Knopf Program drücken und das Programmieren beginnt. Fertig!

# Anhang E: Probleme beim Programmieren beheben

In fast allen Fällen handelt es ich um ein Problem mit dem verwendeten Micro-USB Kabel (welches nicht mit geliefert wird).

In einigen Fällen wurde der USB-to-Serial Adapter nicht vom Betriebssystem erkannt. LANE Boys RC empfiehlt, einen USB-to-Serial Adapter mit dem CH340 Chip zu verwenden. Einen passenden Treiber findet man hier: https://learn.sparkfun.com/tutorials/how-to-install-ch340-drivers/all
Wenn ein USB-to-Serial Adapter mit einem anderen Chip verwendet werden soll, muss man einen passenden Treiber vom Hersteller installieren.
Einige Computer haben auch eingebaute serielle Schnittstellen. Das LPC81x-ISP verwendet dann unter Umständen die falsche Schnittstelle und das Programmieren schlägt fehl. Der Benutzer muss im Programm das richtige COM Port des USB-to-Serial Adapters auswählen. Wie man dieses im Gerätemanager findet wird im oben angeführten Link beschrieben.
Einige Benutzer verwenden noch eine 32-bit Version von Windows. Eine LPC81x-ISP Version, die mit 32-bit Windows kompatibel ist, gibt es hier: https://laneboysrc.github.io/rc-light-controller/lpc81x-isp-windows-32bit.zip

Einige Anwender berichteten, dass der Virus-Scanner das LPC81x-ISP Programm als möglicherweise schädlich erkannt hat. Wenn Sie dem ausführbaren Programm nicht vertrauen, können Sie Python installieren und dann den Quellcode von LPC81x-ISP direkt ausführen.
Der Light Controller kann auch mit jedem anderen Programm, welches den NXP LPC812 und LPC832 Mikrocontroller unterstützt, programmiert werden. Zum Beispiel Flash Magic (https://www.flashmagictool.com/).

# Anhang F: AUX Schalter Typ erkennen

Mehrere Funktionen des Light Controllers werden über einen AUX Kanal, der an eine Schaltfunktion am Sender angeschlossen wird, gesteuert.
Die Funktionen werden, wie in Kapitel Lichter schalten auf Seite 26 beschrieben, über einen Multifunktions-Schalter angewählt.
Der Light Controller unterstützt die folgenden Schalter Typen:
- Two-position switch (Zwei-Stufen-Schalter)
- Two-position switch with up/down buttons (Zwei-Stufen-Schalter Funktion, die durch zwei Drucktasten implementiert wird)
- Momentary push button (Drucktaste)
- Push button on the light controller (Drucktaste im Fahrzeug; siehe Kapitel Verwendung eines im Auto eingebauten Tasters auf Seite 11)

Wenn Sie nicht sicher sind, welchen Schalter-Typ Ihr Sender implementiert, können Sie das wie folgt herausfinden:
Verbinden Sie ein Servo mit dem AUX Kanal am Empfänger. Betätigen Sie den Taster/Schalter am Sender und beobachten Sie, welche Bewegungen das Servo ausführt. Vergleichen Sie die Funktion mit den folgenden Diagrammen:

Two position switch:

Push button implementing a Two position switch:

Pu sh an d r elease | Pu sh an d r elease

Two-position switch with up/down buttons

Pu sh an d r elease | Pu sh an d r elease

Momentary push button:

Pu sh an d h old | Release

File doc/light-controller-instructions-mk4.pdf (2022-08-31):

# RC Light Controller

# Instructions for use

Mk4, Mk4P and Mk4S

# Introduction

Thank you for using the LANE Boys RC light controller!

The light controller supports the following features, and more:

- 16 LED outputs, constant-current driven. Up to 20mA per output.
(Mk4 and Mk4P only)
- 1 high current non-dimmable switched output of up to 2A to drive a roof light bar (Mk4S: 9 non-dimmable switched outputs)
- Two light controllers can be cascaded for a total of 32 LED outputs.
- Parking, Low-beam, High-beam and a roof light bar can be switched on/off manually from the transmitter
- Brake and Reverse lights are automatically controlled by monitoring the throttle channel. The brake lights now automatically turn on for a short, random time when the throttle goes to neutral.
- Combined tail and brake light function in a single LED through controlling the brightness of the LED. (Mk4 and Mk4P only)
- Separate brake light function for a 3rd brake light
- Indicators only come on when you want to. You have to stay in neutral for one seconds, then hold the steering left/right for one second before they engage. This way normal driving does not trigger the indicators.
- Hazard lights can be switched on/off from the transmitter
- Programmable output designed to drive a steering wheel or a figures head, or a gearbox servo
- Automatic center and end-point adjustment for steering and throttle channels
- Light Programs for custom light animations like police lights, running lights ...
- Simulation of incandescent lights and faulty ground wiring
- Optional i-Bus compatible input
- Optional S.Bus compatible input (Mk4P Rev 3 and Mk4 Rev 7 hardware only)
- Optional Pre-Processor for easier wiring
- Up to 3 AUX channels can control light functions when using the 5-channel Pre-Processor or i-Bus
- All functions can be customized using a web browser-based tool
http s ://laneboysrc.github.io/rc-light-controller/
- Hardware and software is Open Source under MIT license
https://github.com/laneboysrc/rc-light-controller/

# Light controller variants

There are three different implementations of the Mk4 Light Controller:

Mk4: | The smallest light controller with solder pads
Mk4P: | Same functions as Mk4, but with a convenient 2.54mm connector for LEDs
Mk4S: | Nine non-dimmable switched light outputs, with a convenient 2.54mm connector for LEDs

The variants are all interchangeable. All of them can be used with the optional Pre-Processor (see below). Any of them can be cascaded if more than 16 light outputs are needed.
For example, you could use an Mk4 or Mk4P to drive indicators, tail/brake and reversing lights of a car, and an additional Mk4S to drive high power light bars, rock lights and headlamps.

Mk4
This is the original version of the Mk4 light controller. It has a 6-pin 2.54mm connector for power and servo signals, and solder pads to connect the LEDs.

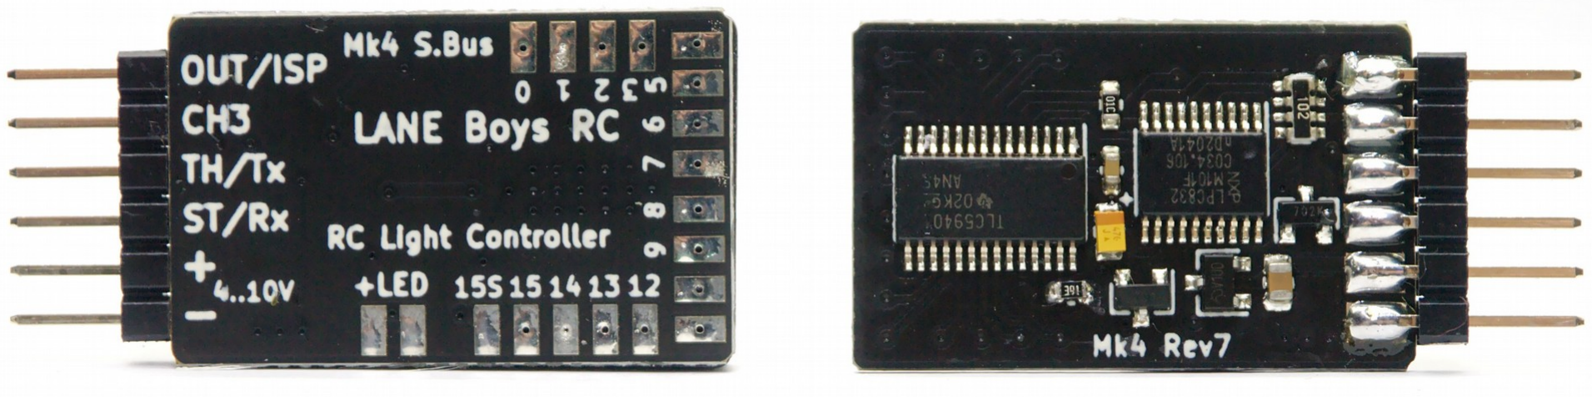
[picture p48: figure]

There are 16 constant-current outputs, each designed to drive a single LED at 20mA; and 1 switching output capable of up to 2A.

Mk4P
The Mk4P is functionally identical to the Mk4, but it has 2.54mm pin headers for easier connections of LEDs. Furthermore, the LEDs can be powered separately, and there are connections to directly hook up a servo or a secondary light controller.


Like the Mk4, the Mk4P has 16 constant-current outputs, each designed to drive a single LED at 20mA; and 1 switching output capable of up to 2A.

The upper row on the LED pin header carries LED+ (anode), the lower row carries LED- (cathode)

Mk4S
This version of the light controller has 9 non-dimmable switching light outputs, each capable of driving up to 2A.

Since all outputs are switching outputs, you must use current-limiting resistors for all LEDs connected to the Mk4S.

The Mk4S light controller is not dimmable; LEDs can only be on or off.

Eight of the outputs (OUT0 .. OUT7) are wired to 2 LED connections each, and OUT8 is wired to a single LED connection.


The Mk4S light controller only has only 9 outputs: OUT0 .. OUT8. Any configuration for other outputs (OUT9 .. OUT15) will be processed internally but are not accessible.

The upper row on the LED pin header carries LED+ (anode), the lower row carries LED- (cathode)

# Light Controller connections

The table below shows how the outputs are configured by default.

All output functions can be fully customized, refer to a later section in this document on how to adapt the configuration to your vehicle.

Name | Function | Description
+ | Positive power supply | +4..10V input voltage, usually taken from the receiver (red wire)

Name | Function | Description
- | Negative power supply (GND) | Supply ground (brown or black wire)
ST/Rx | Steering input | Steering servo signal from the receiver, or input from the Pre-Processor, i-Bus or S.Bus
TH/Tx | Throttle input | Throttle (ESC) signal from the receiver. In case the Pre-Processor is used, this pin can also serves as configurable output similar to OUT/ISP
CH3 | CH3/AUX input | Channel 3 (AUX) signal from the receiver
OUT/ISP | Output | Output to drive a servo or connect a slave controller. The output function can be configured via the Configurator tool, see below.
+LED | LED supply | Terminal to connect the (+) Anode of the LEDs.
OUT0 | Light output 0 | Parking/Position light front left
OUT1 | … | Parking/Position light front right
OUT2 | … | Main beam front left
OUT3 | … | Main beam front right
OUT4 | … | High beam front left
OUT5 | … | High beam front right
OUT6 | … | Indicator front left
OUT7 | … | Indicator front right
OUT8 | … | Tail/Brake light rear left
OUT9 | … | Tail/Brake light rear right
OUT10 | … | Reversing light rear left
OUT11 | … | Reversing light rear right
OUT12 | … | Indicator rear left
OUT13 | … | Indicator rear right
OUT14 | … | 3 rd brake light rear
OUT15 | Light output 15 | Roof light
OUT15S | Switched light output (left of light output 15) | Carries the same signal as light output 15, but instead of current-controlled it is switched towards Ground (-). Up to 2A of current can be switched....

# Connecting the light controller to your RC car

The light controller is usually powered from the RC receiver. The following sections describe different methods how to route the servo signal from the RC receiver to the light controller and the other RC components.
Using a Pre-Processor
The Light Controller has a small companion circuit board called Pre-Processor.

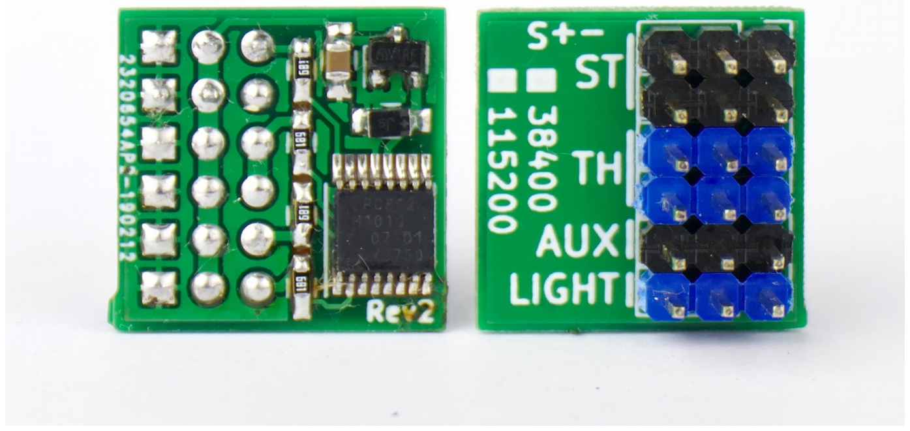
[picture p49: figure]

Instead of connecting the servo signals to the light controller directly, connect them to the Pre-Processor instead. The Pre-Processor accumulates all servo signals into a single data line to the light controller. The Pre-Processor also has additional connectors for the steering and throttle signals, saving the hassle of Y-cables.
This simplifies wiring drastically: only a 3-pole servo extension cable is needed between the chassis of the car (where receiver, ESC, Servo and Pre-Processor reside) and the body shell (where the light controller and the LEDs are).

3-channel Pre-Processor

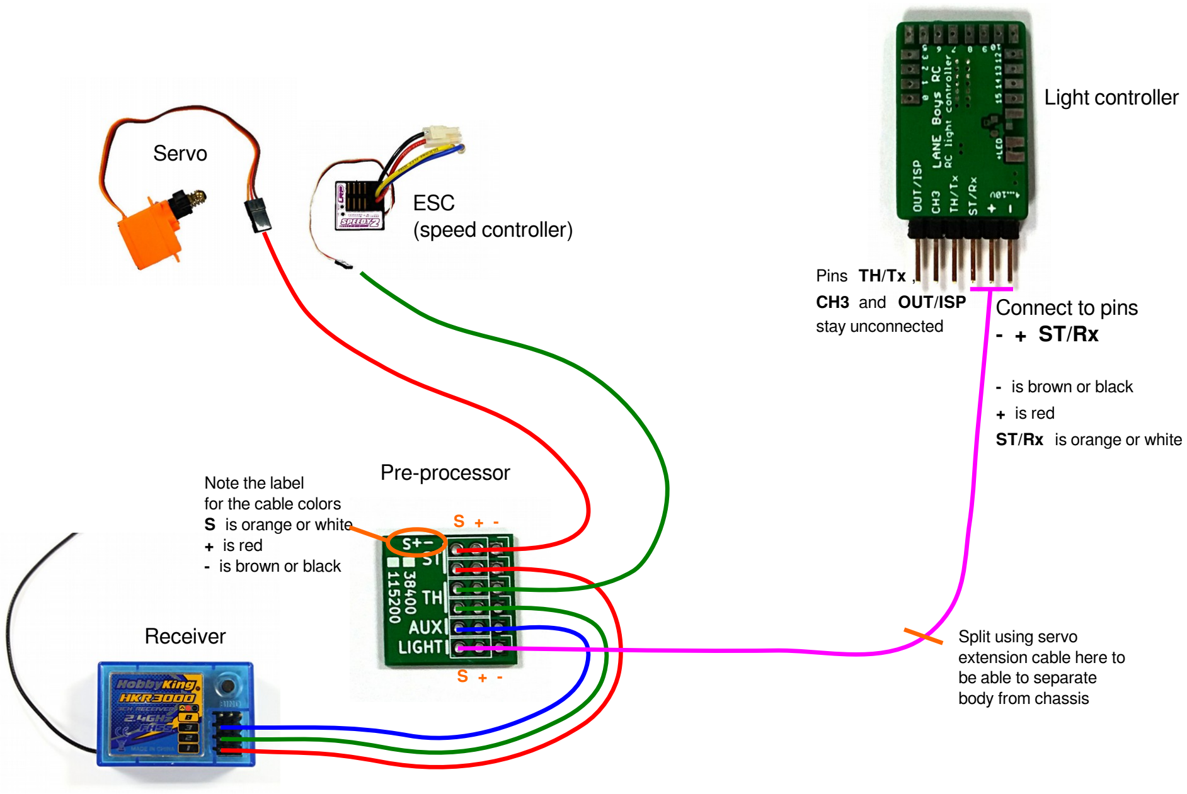
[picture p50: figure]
Servo; ESC (speed controller); Pre-processor; Light controller; Connect to pins - + ST/Rx; - is brown or black + is red ST/Rx is orange or white; Pins TH/Tx , CH3 and OUT/ISP stay unconnected; Receiver; Note the label for the cable colors S is orange or white + is red - is brown or black; Split using servo extension cable here to be able to separate body from chassis

Pre-Processor also comes in a 5-channel variant, which is useful if you have a modern RC car radio that supports more than 3 channels. With the 5-channel Pre-Processor you can use separate AUX channels for manual indicators, or switching lights, or turning the hazard lights on an off. The function of each AUX channel can be configured separately.


Direct connection to the servo signals
Connect the light controller signals ST/Rx, TH/Tx and CH3 to the steering, throttle and auxiliary channels of your receiver.

For steering and throttle you will need to utilize a Y-cable as shown on the schematics below:

5-channel Pre-Processor


Only one of the channels needs to provide power to the light controller. For the other channels it is sufficient to use just the signal wire (usually orange or white in color). Servo extension leads can be easily reconfigured to achieve this:

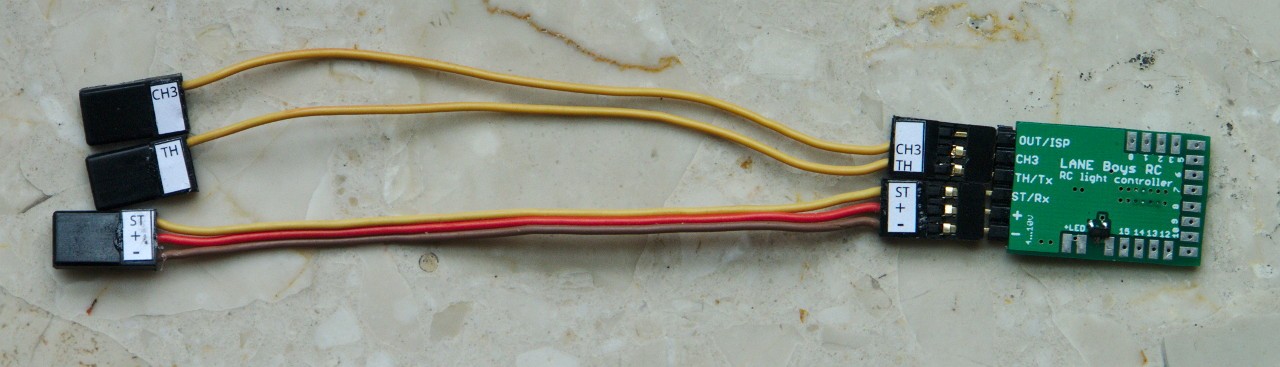
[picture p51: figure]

Using a receiver with an i-Bus compatible output
If you use a RC system that has an i-Bus compatible output on the receiver side (e.g. FlySky FGr4S) then you can connect the light controller directly to the i-Bus output of the receiver using a standard 3-pole servo cable.
In this configuration the light controller supports ST, TH and three AUX channels. ST is channel 1 on i-Bus; TH is channel 2; the AUX channels can be mapped to a 3 sequential i-Bus channels in the range between channel 3 and channel 12.

Servo; ESC (speed controller); Light controller; Connect to pins - + ST/Rx; - is brown or black + is red ST/Rx is orange or white; Pins TH/Tx , CH3 and OUT/ISP stay unconnected; i-Bus compatible receiver; Split using servo extension cable here to be able to separate body from chassis

Using a receiver with an S.Bus compatible output
If you use a RC system that has an S.Bus compatible output on the receiver side (e.g. Futaba or FrSky receivers) then you can connect the light controller directly to the S.Bus output of the receiver using a standard 3-pole servo cable (similar to the i-Bus diagram shown above).

S.Bus compatibility is only supported on the following light controller hardware:
Mk4P Rev 3 (shipped from February 2022 on-wards)
Mk4 Rev 7 (shipped from June 2022 on-wards)

To identify whether your Mk4P is a Rev 3 hardware, look for the

text 832 Rev3 on the front side of the Mk4P. If it does not have this text, S.Bus is not supported.

To identify whether Mk4 Rev 7 hardware, look for the text S.Bus on the Mk4. If it does not have this text, S.Bus is not supported.

The S.Bus compatible input supports ST, TH and three AUX channels. ST is channel 1 on S.Bus; TH is channel 2; the AUX channels can be mapped to a 3 sequential S.Bus channels in the range between channel 3 and channel 14.

Using a push-button installed in the car to switch functions
If you have a two-channel RC transmitter, or don’t have a spare channel to control the light functions, then you can alternatively hook up a push-button to the CH3 input directly to the light controller. You can hide the push-button somewhere in the car and access it when needed.
The push-button needs to connect the CH3 input of the light controller to (–) (Receiver supply minus; GND) when pushed, as shown in the diagram below.
Note that you must enable the Push button on the light controller setting in the Configurator tool described later in this document to enable this function.


Connecting two light controllers for a total of 32 LED outputs
For large installations, where 16 LED outputs are not sufficient, two light controllers can be connected to control a total number of 32 independent LED outputs.
For traditional reasons this is called Master/Slave system. The Slave light controller contains a generic configuration that is independent of the vehicle.
The Master light controller gets configured with the Slave output enabled on OUT/ISP (or TH/Tx) and holds the configuration for all 32 LEDs. This is convenient, as only one light controller needs to be programmed when adjustments to the configuration are necessary.

Any of the light controller variants (Mk4, Mk4P and Mk4S) can be used as either Master or Slave. You can mix-and-match as required.

Using Mk4P and Mk4S as Master can be convenient as they come with a separate 3-pin output connector that accepts a servo extension cable; no custom cable required.

A simple 3-pole servo extension wire is sufficient as connection between the Master and Slave light controller. This allows the Slave light controller to be placed close to where the LEDs are, or even in a trailer.

Servo

LiPo 2S 7.4V

When creating a configuration for Master and Slave, the Baudrate setting in the Configurator needs to be set to the same value.

Some users tried to install a second receiver, battery and light controller in a trailer. This is not recommended due to the following reasons:

- The timing reference in the light controller is not precise and drifts. This means that indicators don’t light up in sync on the car and the trailer
- Some timings like automatic reversing or brake lights are created randomly. Therefore the car and trailer brake and reversing lights will not be in sync.

None of these problem exists when using the Master/Slave system, as all timings are generated by the Master only.

# Connecting LEDs

The (+) Anode (usually the long pin) connections of all LEDs are connected together to the terminals +LED.

ANODE | CATHODE

Constant-current controlled LED outputs
Each light output on the Mk4 and Mk4P light controller is designed to drive a single LED. The outputs are driven with a constant current of up to 20mA for optimal LED performance and uniform brightness.

Do not connect a resistor in line with the LED on Mk4 and Mk4P, it is not necessary for constant-current controlled outputs!

The outputs are designed to drive standard 3mm or 5mm (or SMD) LEDs at 20mA, they are not suitable for high-power LEDs.

For more information about LEDs please refer to Appendix A: All about LEDs and wiring on page 27

Switched LED output OUT15S, and Mk4S
Beside the 16 current-regulated light outputs, the Mk4 and Mk4P light controller also have one non-dimmable, high current capable, switched light output. It is designed to drive an off-the-shelf light bar or high power LEDs.

The non-dimmable switched light output is marked 15S and turns on together with output OUT15. When OUT15 is turned on at any brightness, OUT15S is also turned on.

On the Mk4S (Switching) light controller, all outputs are such non-dimmable switched outputs.

Every switched output can sink up to 2 Ampere in current.

For the switched outputs you must use a current-limiting resistor in series with the LED.

Without resistor the LED will burn out immediately.

# Output functions

The light controller can provide auxiliary functions on its OUT/ISP pin. When using a Pre-processor, an second auxiliary function can be configured to the TH/Tx pin.

The following auxiliary functions are available:
- Servo output that follows the steering channel
- Gearbox servo output
- Servo output under control of light programs
- Slave light controller output
- Pre-Processor output

These auxiliary functions can be split into two types: Servo functions and UART functions (serial communication).
The light controller supports at most one Servo function and one UART function at a given time.

The Mk4P and Mk4S light controller have a 6-pin connector on the right side. The lower 3 pins follow the standard servo connector layout (Minus (-), Plus (+), Signal). The signal pin is connected to OUT/ISP. This makes it very convenient to connect a servo, or a Slave light controller.


To connect a servo to the Mk4 light controller, you need to splice the (+) and (-) power supply to power both light controller and servo:

Servo output that follows the steering channel
The light controller can drive a small servo in synchronization with the steering input. This is designed to turn the steering wheel in the cabin of a truck. The center, endpoints and direction can be fully programmed (see below).

For safety reasons do not connect the steering servo of your vehicle to this output!

The signal wire of the servo must be connected to the configured output pin (OUT/ISP or TH/Tx) on the light controller. Note that some servos, especially analog servos, put a high load on the OUT/ISP pin, preventing the light controller to start. Digital servos usually work without issue.
Gearbox servo output
The servo output can also be configured for controlling a 2-speed or 3-speed gearbox. When the gearbox control is enabled, 1-click and 2-clicks on CH3/AUX change their behavior:

2-speed gearbox: 1-click changes to gear 1, 2-clicks to gear 2.

3-speed gearbox: 1-click changes to the next higher gear, 2-clicks changes to the next lower gear.

Since 1-click and 2-clicks are now taken up by gearbox control, it is no longer possible to switch between the different virtual light switch positions. The lights can only be switched on/off using 3-clicks. If this is not desired, then one can opt to control the gearbox from a light program. With a small light program it is possible to toggle through the gears when performing 6-clicks on CH3/AUX.
Servo output under control of light programs
It is possible to control the servo output from a light program. When the respective configuration option is chosen, values between -100 (left endpoint), 0 (center) and +100 (right endpoint) can be set to move the servo to desired positions. This can be useful for simple mechatronics animations, like random movements of a figures head.
Servo setup
The center point and end points of the servo output can be configured independently of the car’s steering.
To set up the servo output, perform eight clicks on channel CH3. In the default configuration, the left indicators will light up and the steering wheel servo will follow directly the steering input on the transmitter. Move the steering wheel on the transmitter to the position that shall be used for full left on the steering wheel servo.
Note that this may require that you need to turn the steering wheel on the transmitter right, if the servo is reversed. Don't worry, this is correct and lets the light controller know which way to turn the steering wheel servo. Hold the transmitter steering in position while clicking channel CH3 once.

Now both left and right indicators will turn on. Turn the steering wheel on the transmitter to the position that the steering wheel servo is centered and click channel CH3 once. Now the right indicators will turn on. Perform the same procedure as for the left end point and click channel CH3 once.
The center and end points should now be correct, the steering wheel should follow in the same way as the car. The settings are stored persistently and are not affected by steering trims and endpoint adjustments.
Note that after changing endpoints or trim on your RC transmitter, you need to restart the light controller so that it learns the new settings.

Slave light controller output
When choosing this option, a secondary Slave light controller can be connected so that a total of 32 independently controlled light outputs are available.

Pre-Processor output
This setting is usually not useful for end-user configuration, it is internally used by the Pre-Processor.
When enabled, the Steering, Throttle and AUX signals on the input of the light controller are output using a serial protocol. The protocol is documented here: https://github.com/laneboysrc/rc-light-controller/blob/master/doc/preprocessor-protocol.md

# Configurator: Custom configurations

Every car is different. To adjust the light controller behavior for your particular vehicle, create a custom configuration by using a tool called Configurator.
The Configurator runs in a modern web browser. It has been tested with Mozilla Firefox, Google Chrome and Microsoft Edge.
You can access the latest version of the Configurator on-line at
http s ://laneboysrc.github.io/rc-light-controller/

Alternatively, you can download everything needed to program the light controller from here – which is useful if you want to configure and program the light controller without requiring Internet access:

https://github.com/laneboysrc/rc-light-controller/blob/master/mk4-tlc5940-lpc812/mk4-download-me.zip?raw=true
Open the file configurator.html in your web browser.

To learn how the configuration process works, please watch the following video (starting at 14:09):
https://youtu.be/-VyNAVU3-ok?t=849

The Configurator has the firmware already embedded, just set the options you want and flash the firmware into the light controller.

# Flashing the firmware

The light controller is shipped with a default firmware, with the light configuration described in section Light Controller connections on page 4.
However, most installations will require changes to the configuration, as described in the previous section. After creating such custom configuration, you need to load the updated firmware into the light controller.
We offer a custom programmer hardware called WebUSB programmer that allows flashing and testing the light controller firmware directly from within the Configurator tool.


[It is also possible (but more difficult) to flash the light controller with an off-the-shelf USB-to-Serial adapter. This method is described in Appendix D: Flashing the firmware with a USB-to-Serial adapter on page 35.]

The WebUSB programmer requires a web browser that supports WebUSB technology, such as Google Chrome or Microsoft Edge, or other browsers based on the Chrome engine. An up-to-date list of compatible browsers can be found here: https://caniuse.com/?search=webusb
Note that the WebUSB programmer does not work in Safari and Firefox, as those browsers do not implement the WebUSB standard.

The WebUSB programmer works under Linux, Mac OS, and Windows 8.1 or newer.

The WebUSB programmer does not need a driver. Just connect it to the computer and it is operational straight away.

Connect the WebUSB programmer to the light controller and the computer. After creating a configuration suitable for the car, click on the Programming tab in the Configurator.


If you are using the WebUSB programmer for the first time, you must grant the Configurator access to the hardware.
Click the Connect button. The web browser will pop up a dialog with a list of compatible devices. The list should have one entry named Programmer.


If this entry is not present, the WebUSB programmer is not connected to the computer or the Micro-USB cable is defective.


Select the entry Programmer, which will enable the Connect button in the dialog.Click the Connect button. This will grant the Configurator access to the WebUSB programmer, and the green LED on the WebUSB programmer should light up.
This process only has to be done once, the web browser will remember the hardware access permission. From now on the Configurator will connect to the WebUSB programmer automatically as soon as it is connected.

To flash the firmware, simply click the Program button. Diagnostics messages will appear and a progress bar will show the flash progress. After programming has finished, a green message will appear in the diagnostics area.


If you are configuring the light controller for use with a Pre-Processor, you can also use the WebUSB programmer to test the configuration without connecting the light controller to your RC system.
Click on the Testing tab and a simple user interface that simulates the controls on a RC transmitter will appear.

A web browser with the Configurator running after a successful programming operation


Important: the Testing function only works for configurations with Pre-Processor operation. If you intend to use direct servo connections to the light controller, you can temporarily switch to Pre-Processor mode for testing; and then change back to Servo inputs before installing the system in the car.

# Operating the Light Controller

After power-on, the front main beam LEDs will turn on for about two seconds. During this time ensure that steering and throttle controls on the transmitter are kept in neutral position.
If if the front indicators light up instead of the main beam LEDs, this means that none of the input channels ST, TH and CH3 receive a proper servo signals from the receiver. Turn off the power and check all connections.
After initialization, all lights turn off and the system is ready to use.
It is advisable to let the light controller know the endpoints of steering and throttle before driving off. To do this, simply move the steering fully left, then fully right. Hold the car in the air safely and pull the throttle full forward, then full backward – ensuring that the drive train does not get damaged.

The Testing tab simulates a RC system including Pre-Processor, so that the light configuration can be tested without disconnecting from the computer.

Brake and reversing light
When driving, the brake and reverse lights will now come on according to the throttle input. The indicators can be engaged by keeping both steering and throttle neutral for one second, then turning the steering into the direction the indicators should show. Once they are engaged, you can start driving off with the indicators operating. They will turn off after a short delay when the car goes straight, or immediately when the car turns in the other direction.

Switching the main lights
Several functions of the light controller can be operated manually through the auxiliary channel CH3 (AUX). Since there are quite a few functions, the concept of multiple “clicks” is employed. Similar to the operation of a computer mouse, one can switch the CH3 (AUX) switch on the transmitter repeatedly within a short time to invoke different functions.
One click: Turn on more lights at each click: Parking, Main beam, High beam, Roof lights Two clicks: Turn the lights down; reverse of one click
Three clicks: toggle all lights on and off
Four clicks: toggle hazard lights (all indicators flash) on and off

Here is a video showing the operation: https://youtu.be/-VyNAVU3-ok

The light controller supports various switch types on the transmitter side. Please refer to Appendix G: Determining the AUX switch type for details.

# Steering and Throttle channel reversing

The direction of the steering and throttle channels can be programmed to match the car. To do this, perform seven clicks on channel CH3. The front and rear indicators on one side as well as the front main beam lights will turn on.
Move the steering wheel on the transmitter into the direction of the indicators that light up (i.e. if the indicators on the left side of the car light up, turn the steering wheel left). When successful the indicators will turn off.
Now engage the throttle forward. When successful the main lights will turn off, programming channel reversing has finished and the light controller will resume normal operation.
The steering and throttle direction are stored persistently so this configuration has to be carried out only once after installing the light controller.

It is also possible to reverse channels in the Configurator.

# Light Programs

Light Programs are simple scripts that allow full customization of light controller functions and light outputs without the need of developing a custom firmware.
Detailed documentation of Light Programs can be found at https://github.com/laneboysrc/rc-light-controller/blob/master/mk4-tlc5940-lpc812/doc/light-programs.md (https://github.com/laneboysrc/rc-light-controller/blob/master/mk4-tlc5940-lpc812/doc/light-programs.md)
Light programs are useful to create running lights, police flashers etc. A collection of light programs can be found at
https://github.com/laneboysrc/rc-light-controller/tree/master/mk4-tlc5940-lpc812/configurations (https://github.com/laneboysrc/rc-light-controller/tree/master/mk4-tlc5940-lpc812/configurations)

# Technical data

Parameter | Mk4 | Mk4P | Mk4S
Operating voltage | 4V .. 10V
Constant current outputs 20mA per LED output | 16 | 16 | –
Dimming | 63 steps DC, no PWM | 63 steps DC, no PWM | (no dimming)
Switched output 2A max per output | 1 | 1 | 9 8 outputs with two 2-pin connectors each, 1 output with one 2-pin connector
LED configuration | Common Anode Common Plus pole; Minus pole goes to individual outputs of the light controller
Dimensions | 38 × 19 × 3mm | 62 × 27.5 × 9.5mm | 62 × 27.5 × 9.5mm
Dimensions (without connectors and case) | 29 × 18 × 2.5mm | 44 × 23 × 3mm | 44 × 23 × 3mm
Pre-Processor: | 17 × 17 mm
5-channel Pre-Processor: 24 × 17 mm

Have fun with RC! Werner

laneboysrc@gmail.com

http s ://laneboysrc.blogspot.com/
http s ://www.youtube.com/user/laneboysrc https://www.flickr.com/photos/78037110@N03/albums/https://github.com/laneboysrc/rc-light-controller/

# Appendix A: All about LEDs and wiring

What kind of LEDs can be used?
Almost any 3mm, 5mm or small SMD LED can be used, as long as it is rated for a nominal current of 20 mA at a forward voltage of less than 3.6 V.

The statement above is for LEDs connected to one of the constant-current outputs of the Mk4 and Mk4P light controller.

For switching outputs, any LED is suitable as long as the current is less than 2 A. You need to provide suitable LED supply voltage and current limiting for LEDs connected to switching outputs.

Extremely bright LEDs that use more than 20 mA, or LEDs that contain multiple LED dies in a package, are not suitable.

Standard 3mm, 5mm, 0402 SMD, 0603 SMD, 0805 SMD, 1206 SMD LEDs should all work fine.


SMD LEDs of size 3528 or 5730 are usually high-power LEDs that require a higher drive current. Those LEDs are not suitable for connection to a constant-current output on the light controller. Please refer to the datasheet of the LED to determine if it is suitable (20mA at <3.6V).

How to connect the (+) of 16 LEDs to only two +LED pins on the light controller?
The Mk4 light controller is very small and only offers two +LED connections. The design idea is that the (+) (Anode) of all LEDs are tied together right at the LEDs, and then only a single wire goes from the various LED clusters in the car to the light controller.


Alternatively, you can use the Mk4P pin-header version of the light controller, where a separate +LED output is available for each LEDs.

Using a separate power source for the LEDs
Usually the light controller is powered from the BEC that feeds the receiver and servos. Alternatively, it is possible to drive the LEDs from a separate power source, while the light controller is still powered form the BEC. This could be useful, for example, if the vehicle is powered from a 3S LiPo (about 12V) and a 12V capable light bar is used.

In the following schematic the light bar is powered directly from the car LiPo, while the light controller and other LEDs are powered from the BEC of the ESC:

LiPo

The power source can be either a separate battery, the driving battery of the car, or a separate BEC (DC/DC converter).
This method can be applied to any light output (current-controlled or switched).

When used for current-controlled outputs care must be taken that the total power dissipation of the light controller does not exceed 2.5W

The power dissipation for current-controlled light outputs can be calculated as follows: (Supply-voltage minus LED-forward-voltage) times LED-current

Example: 8.4V supply voltage, 3V LED forward voltage, 20mA LED current
(8.4V – 3V) × 0.02A = 0.108W (per LED output!)

On the Mk4 light controller the +LED pins on the circuit board are directly connected to the + input power supply. Do not use +LED when you want to power the LEDs from an external power source.
The Mk4P and Mk4S light controller have a separate connector for choosing whether the +LED connection is powered from the BEC/receiver or from a separate power source.

The supplied jumper can be used when powering +LED from the receiver, or instead a servo connector or JST connector can be used to supply the +LED from a separate battery.


The light controller on the top has the jumper installed to connect the +LED lines to the + from the receiver.
The light controller on the bottom has the jumper removed, and instead an external battery connected to +LED and - pins.

Wiring LEDs in series
Depending on the power supply voltage and the LED's forward voltage, it may be possible to drive two LEDs in series on a single light output:

The LED forward voltage depends on the color of the LED.
- Red and Amber LEDs have a forward voltage of about 1.8V
- Green LEDs about 2.2V
- White LEDs about 3.2V
- Blue LEDs may require up to 3.6V

Always consolidate the datasheet of your LEDs for exact values.

The light controller itself requires at least 0.8 V to be able to control the current. Usually the light controller is powered from the BEC in the car, which outputs 5V or 6V.

Example: Two red LEDs are wired in series,
...so the voltage drop across them is 1.8V times two = 3.6V.
The BEC voltage is 5V.
5V – 3.6V = 1.4V, which is more than the 0.8V that the light controller requires for proper operation, so everything works fine.

Example 2: A white and a blue LED wired in series.
The voltage drop across both LEDs is 3.2V + 3.6V = 6.8V.
The BEC voltage is 6V, so it is not high enough to drive those LEDs at full brightness.

However, it is possible to power the light controller from the 2S LiPo car battery.
A fully charged LiPo is 8.4V.
8.4V – 6.8V = 1.6V, which is more than the 0.8V required by the light controller.
As the LiPo discharges and voltage drops below 6.8V + 0.8V = 7.6V, the LEDs will be not driven properly anymore and may become dim.

When powering the light controller directly from a 2S LiPo, precautions have to be taken to ensure that the installation is safe against short circuits, as the energy stored in a battery can cause fire.

Furthermore, the power dissipated in the light controller increases with the input voltage. The light controller may become too hot and malfunction.

Wiring LEDs in parallel
In general, it is not recommended to wire LEDs in parallel. LEDs are non-linear devices – a small change in forward voltage can cause a large change in the current flowing through the LEDs. If two LEDs wired in parallel have a different forward voltage, than one of the LEDs may draw more current than the other LED.
That said, in practice it is usually OK to wire two LEDs in parallel, as modern LEDs are manufactured to tight tolerances.

Only LEDs of the same manufacturer, type and color can be wired in parallel.

When two LEDs are wired in parallel, half of the current that the light controller regulates runs through each LED.
One potential use-case is to save an output for white parking lights or reversing lights. Wiring white LEDs in series (see previous section) may not possible as the total voltage required could be more than the supply voltage. However, since parking lights or reversing lights don’t need to be very bright, wiring two LEDs together can free up one output on the light controller for another purpose.
Still, it is advisable to wire each LED to a dedicated output on the light controller. Parallel connections should only be used as last resort.

# Appendix B: Resistor calculation for LED and light bars

LEDs are active components with a non-linear relationship between voltage and current. Even a small increase in voltage may cause a large increase in the current flowing through the LED.
Furthermore, the temperature of the LED influences this relationship, hence current may increase when the LED heats up, which causes further current increase – and so on, until the LED burns out.
In order to prevent LED damage, we therefore need a current limiting resistor before we can connect an LED to a voltage source.

Outputs OUT0 to OUT15 on the Mk4 and Mk4P light controller are current-regulated and do not need a current limiting resistor.

However, LEDs connected to OUT15S on Mk4 and Mk4P, or any output on Mk4S (switching version) needs a current limiting resistor.

Resistor value for a single LED
The formula is very straight forward:
Resistor = (Supply-voltage minus LED-forward-voltage) divided by LED-current

The forward voltage of an LED is specified in its datasheet. If you don’t have a datasheet available for the particular LED you are using, refer to the following guide:

- Red and Amber LEDs have a forward voltage of about 1.8V
- Green LEDs about 2.2V
- White LEDs about 3.2V
- Blue LEDs may require up to 3.6V

Note that this table applies to normal 3mm, 5mm or small SMD LEDs. Power LEDs may have very different voltage and current requirements.

Example: Supply voltage: 6V. Amber LED with 2V. Desired current: 20mA

(6V – 2V) / 0.02A = 200 Ohm → next larger standard value would be 220 Ohm Resistor value for a light bar using multiple LEDs
Ideally each LED in a light bar would have its own current limiting resistor:

In this configuration, the formula for a single LED, described above, applies.

In practice, most commercial light bars have all LEDs wired in parallel and utilize a single current limiting resistor for the whole light bar. This “works” because modern LEDs have relatively tight tolerances, so the current through all LEDs is roughly the same.


The formula for calculating the current limiting resistor is similar as for a single LED, except that the current now is the total current of all LEDs:
Resistor = (Supply-voltage minus LED-forward-voltage) divided by (LED-current times number-of-LEDs)

Example: Supply voltage: 6V. White LEDs with a forward voltage of 3V. Desired current per LED: 20mA. Number of LEDs: 6.

(6V – 3V) / (0.02A × 6) = 25 Ohm → next standard value = 27 Ohm

Important: consider the power dissipated in the resistor!

Especially for light bar use, a lot of power is potentially dissipated in the current limiting resistor, causing it to get hot and possibly fail.

The required power capability of the resistor can be calculated as follows:
Power = (Supply-voltage minus LED-forward-voltage) times LED-current times number-of-LEDs

Example: Supply voltage: 6V. White LEDs with a forward voltage of 3V. Desired current per LED: 20mA. Number of LEDs: 6.

(6V – 3V) × 0.02A × 6 = 0.36W

In this example we therefore need at least a half-Watt power resistor; a typical quarter-Watt resistor would burn out quickly.

# Appendix C: Waterproofing

The light controller is not waterproof.

To protect the light controller from moisture, place it in a waterproof box and seal all wire exits.


# Appendix D: Flashing the firmware with a USB-to-Serial adapter

It is possible to flash the firmware of the light controller using an off-the-shelf USB-to-Serial adapter.

You may have to install a driver on your computer before the USB-to-serial adapter functions.
After creating a configuration in the Configurator, click on the Save firmware image... button. A file named light_controller.hex will be stored in the Download folder of your web browser.
The USB-to-serial adapter must be connected to the light controller as follows:

USB-to-Serial; Light Controller

GND (–) ↔ – (power supply) VCC (+) ↔ + (power supply)
TX ↔ ST/Rx
RX ↔ TH/Tx
GND ↔ OUT/ISP

Note that the TX (transmit) line from the USB-to-Serial adapter connects to the RX (receive) line on the Light Controller, and vice-versa.

Connect the light controller to the USB-to-serial adapter before plugging the USB-to-serial adapter into the PC.

This is necessary as OUT/ISP pin must be connected to (-) GND while power-on to allow the light controller to enter the programming function.

When the hardware is ready, you can use one of two programming methods to flash the firmware .HEX file.

Web Serial API
Web Serial API is a new web browser technology that allows a web page to access serial ports on a computer.
The Web Serial API works with Google Chrome, Microsoft Edge, or other browsers based on the Chrome engine. An up-to-date list of compatible browsers can be found here:

https://caniuse.com/?search=web- (https://caniuse.com/?search=web-serial) serial (https://caniuse.com/?search=web-serial)
We have made a simple programming tool for the light controller that uses the Web Serial API. The tool can be accessed at https://laneboysrc.github.io/rc-light-controller/webserial-programmer.html
Connect to the USB-to-Serial adapter, load the light_controller.hex file and flash it.

LPC81x-ISP tool
LANE Boys RC created a simple desktop program named LPC81x-ISP. The project repository is at:
https://github.com/laneboysrc/LPC81x-ISP-tool
The program is written in a programming language called Python (https://www.python.org). The tool can run on Windows, Linux and Mac OS. However, an executable file is only available for Windows.
If you are using Microsoft Windows, a compiled version of LPC81x-ISP is included in

https://github.com/laneboysrc/rc-light-controller/blob/master/mk4-tlc5940-lpc812/mk4-download-me.zip?raw=true

Start the LPC81x-ISP tool, click on the Select file… button and load the light_controller.hex file that you saved in the download folder earlier.

Click the Program button to start the flashing of the new firmware containing your custom configuration.

# Appendix E: Solving programming issues

In most cases the Micro-USB cable turned out to be faulty.

The remaining section gives hints of how to resolve programming issues when using a

USB-to-Serial adapter.
In some cases, the USB-to-Serial adapter was not recognized by the operating system. LANE Boys RC recommends using a USB-to-Serial adapter using the CH340 chip. On Microsoft Windows, manual driver installation may be required.
Please refer to https://learn.sparkfun.com/tutorials/how-to-install-ch340-drivers/all for detailed instructions.
If you are using a USB-to-Serial adapter with a different chip, contact the supplier of the adapter for suitable drivers.
Some computers may also have built-in serial ports. The LPC81x-ISP tool may by default choose the built-in port rather than the USB-to-Serial adapter. Please select the correct COM port in the drop down box of the LPC81x-ISP tool. You can find the correct COM port in the device manager as outlined in the link above.
Some users are still using a 32-bit version of Windows. A compatible version of the LPC81x-ISP tool that works on 32-bit Windows can be downloaded here: https://laneboysrc.github.io/rc-light-controller/lpc81x-isp-windows-32bit.zip
Some users reported that their virus scanner identified the tool as potentially malicious. If you don’t trust the executable file, you can download the Python source code, install Python and run the tool this way. The project repository is at: https://github.com/laneboysrc/LPC81x-ISP-tool
The tool can also run on a Raspberry Pi – and because the Raspberry Pi has native serial ports no USB-to-Serial adapter is required.
You can also program the light controller firmware with any other tool that can program the NXP LPC812 and LPC832 micro-controller via UART, for example Flash Magic (https://www.flashmagictool.com/)

# Appendix G: Determining the AUX switch type

Several light functions can be controlled through an AUX channel connected to a switch on the transmitter. The main functions are operated through a multi-function switch as explained in section Switching the main lights on page 25.
The following switch types are supported
- Two-position switch
- Two-position switch with up/down buttons
- Momentary push button
- Push button on the light controller (see section Using a push-button installed in the car to switch functions on page 10)

You can determine the switch type of the AUX channel on your transmitter as follows: Connect a servo to the AUX channel on the receiver. Operate the AUX switch (or push buttons) on the transmitter and match the behavior of the servo with the description below:

Two position switch:

Push button implementing a Two position switch:

Pu sh an d r elease | Pu sh an d r elease

Two-position switch with up/down buttons

Pu sh an d r elease | Pu sh an d r elease

Momentary push button:

Pu sh an d h old | Release

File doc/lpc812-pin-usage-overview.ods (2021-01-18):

Pin | 16P | 20P | Mk4 | Mk4P | Mk4S | Mk4S-mini | Mk4S-mini5 | 3-ch | 5-ch | Special function
PIO0_0 | 16 | 19 | ST-Rx | ST-Rx | ST-Rx | ST-Rx | ST-Rx | ST-Rx | ST-Rx | ISP Rx
PIO0_1 | 9 | 12 | GSCLK | GSCLK | OUT7 | NC | NC | NC | NC
PIO0_2 | 6 | 7 | XCLK | XCLK | OUT2 | OUT2 | OUT2 | NC | NC | SWDIO
PIO0_3 | 5 | 6 | XLAT | XLAT | OUT1 | OUT1 | OUT1 | NC | NC | SWCLK
PIO0_4 | 4 | 5 | TH-Tx | TH-Tx | TH-Tx | TH-Tx | TH-Tx | TH-Tx | TH-Tx | ISP Tx
PIO0_5 | 3 | 4 | NC | NC | NC | NC | NC | NC | NC | Reset
PIO0_6 | 15 | 18 | BLANK | BLANK | NC | NC | AUX2 | NC | NC
PIO0_7 | 14 | 17 | SIN | SIN | OUT4 | NC | NC | NC | NC
PIO0_8 | 11 | 14 | NC | NC | OUT5 | NC | NC | NC | AUX2
PIO0_9 | 10 | 13 | OUT15S | OUT15S | OUT6 | NC | NC | NC | NC
PIO0_10 | 8 | 9 | NC | NC | NC | NC | NC | NC | NC | Open-drain
PIO0_11 | 7 | 8 | NC | NC | NC | NC | AUX3 | NC | AUX3 | Open-drain
PIO0_12 | 2 | 3 | OUT-ISP | OUT-ISP | OUT-ISP | OUT-ISP | OUT-ISP | OUTPP-ISP | OUTPP-ISP
PIO0_13 | 1 | 2 | CH3 | CH3 | CH3 | CH3 | CH3 | CH3 | CH3
PIO0_14 |  | 20 | NC | Mk4P/S | Mk4P/S (GND) | Mk4P/S (GND) | Mk4P/S (GND) | NC | NC
PIO0_15 |  | 11 | NC | NC | OUT8 | NC | NC | NC | NC
PIO0_16 |  | 10 | NC | NC | OUT3 | NC | OUT3 | NC | NC
PIO0_17 |  | 1 | NC | NC | OUT0 | OUT0 | OUT0 | NC | NC

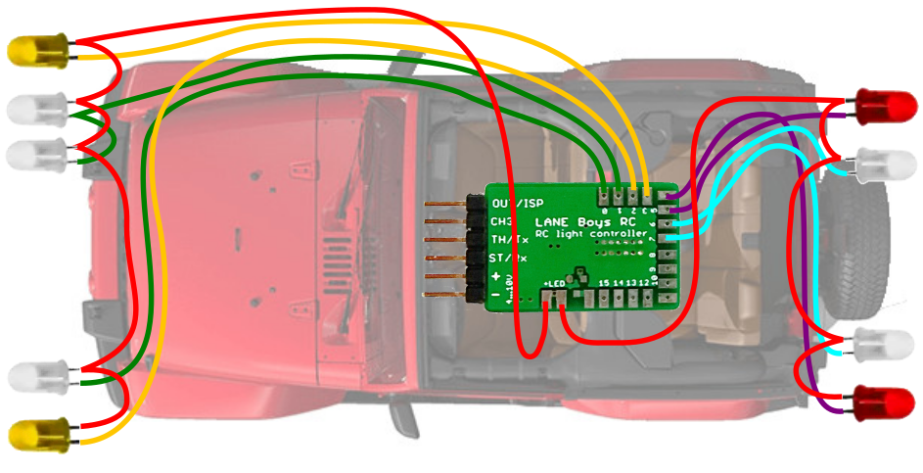
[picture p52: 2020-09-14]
doc/wiring-diagram-leds-white-in-parallel.png

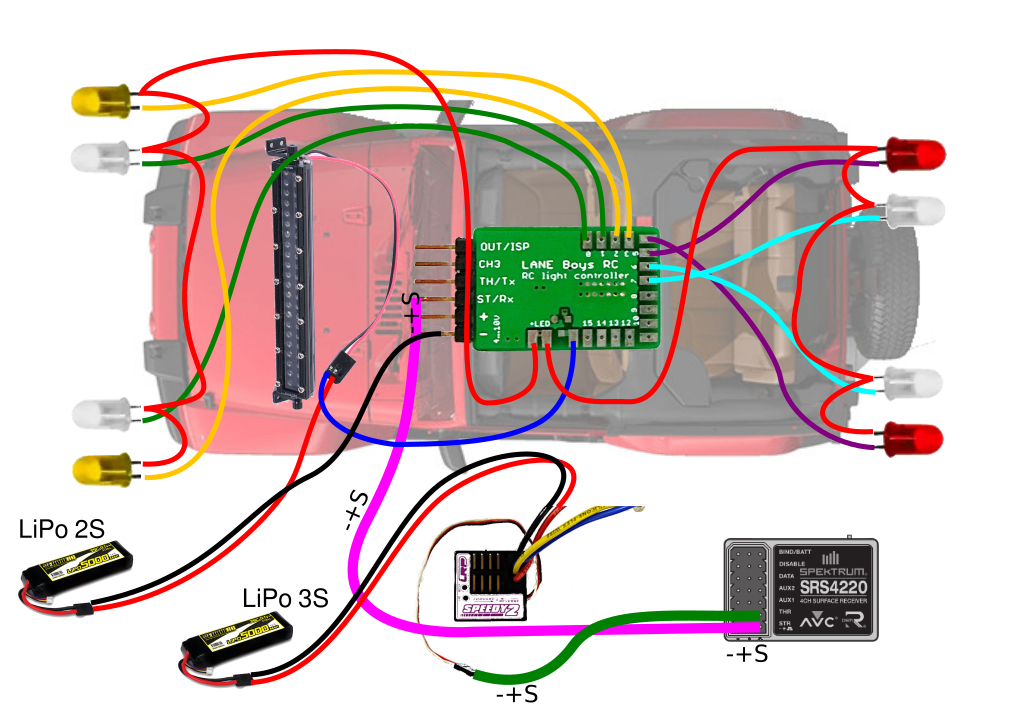
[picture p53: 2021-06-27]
doc/wiring-diagram-lightbar-separate-battery.png

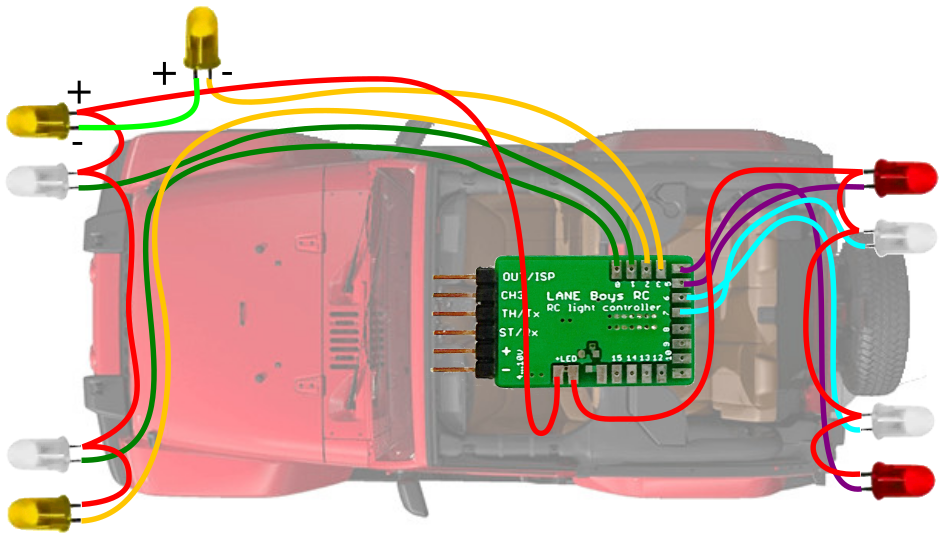
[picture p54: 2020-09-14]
doc/wiring-diagram-leds-indicators-in-series.png

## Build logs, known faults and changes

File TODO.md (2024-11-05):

DEFECTS:

* ALL LEDS does not work properly with LED names declared in the table
* print message for light programs in diagnostics
* Pattern generate for LED flashing: number of steps, boxes that indicate on/off, timing
* Disable automatic indicators for S.Bus and i-Bus manual indicator use
* Make all i-Bus/S.Bus channels fully assignable?

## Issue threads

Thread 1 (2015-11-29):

misc issues gerber/brd/oshpark

s0len0id, 2015-11-29:
First off, thanks for creating and documenting such an awesome rc-light-controller! I'd been looking for a programmable led controller for a while for my 1:10 drifter and Slash. So accidentally stumbling on the mark1 video made my day :)

While ordering the mark4 at OSHPark i got missing board outlines on the gerber zips, and missing texts in the brd file previews. Even when i tried to reproduce the nicely shared mark2 Shared Project.

Now, i know about software, but i'm a complete noob in electronics, but i think i figured it out: :)
for OSHPark the Gerber zips were missing a specific outline file, and the brds have their text in the tValues layer instead of the tNames.

So, i updated a CAM file from OSHPpark to take for the:
Top Silkscreen: 27 tValues instead of 25 tNames
Bottom Silkscreen: 28 bValues instead of 26 bNames

..and regenerated the gerber files for the 3 PCBs. They all look perfect now in the OSHPark preview, as well as in http://mayhewlabs.com/3dpcb. If you want to take a look, i guess i could do a git-pull-request, or simply mail them or something?

thanks,
/Sander.

laneboysrc, 2015-12-01:
Hi Sander!

Thanks for your awesome concise report. And sorry for the trouble...

I have fixed the issues and updated the Gerber ZIP archives on Github. They now seem to load correctly in OSH Park.

Regarding the issue with tNames/tValues: Usual practice is to put the component names on the silkscreen. However, for small, simple boards I prefer to have the values on the silkscreen as it makes populating the boards by hand easier. Therefore the OSH Park CAM file needs to be adjusted for the light controller project. Somehow I saved the original OSH Park CAM file on Github, not the modified version. This is now fixed.

Once more, thanks for highlighting the issues!

If you need any help with programming/configuring the light controllers don't hesitate to contact me at laneboysrc@gmail.com

kind regards, Werner

laneboysrc, 2015-12-01:
Fixed in commit 49d735e30d28a1489c8f2886658f53f37199dd67

s0len0id, 2015-12-02:
Great! I've put OSHPark to work :)

Closed 2015-12-01.

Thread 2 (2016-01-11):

void SCT_irq_handler(void) could not invoke output_raw_channels()

LockeKK, 2016-01-11:
Please check void SCT_irq_handler(void) in rc-light-controller-master\mk4-tlc5940-lpc812\firmware\servo_reader.c

===========================================
                    if (channel_flags & (1 << i)) {
                        output_raw_channels(result);
                        channel_flags = (1 << i);
                    }
                    channel_flags |= (1 << i);
===========================================
whatever channel_flags and i change, output_raw_channels() is impossible to run. I picked up related code and verified in VS2015. Obviously, output_raw_channels(result) has no chance to run.

Locke

laneboysrc, 2016-01-12:
Hi,

    if (channel_flags & (1 << i)) {
        output_raw_channels(result);
        channel_flags = (1 << i);
    }
    channel_flags |= (1 << i);

The important part of this code is that channel_flags is declared *static*,
i.e. it persists between interrupts.
The code checks if a particular servo channel has been seen a second time,
and if it has it calls output_raw_channels().
This code allows automatic detection of how many servo channels are
connected to the light controller, and it also ensures that the order in
which servo pulses are sent by the receiver does not matter.

*Example:*
- At startup channel_flags is 0. result[ST, TH, CH3] are all set to 0 to
indicate "no servo pulse".
- Only two servo channels are connected to the light controller; Steering
(ST, setup for timer capture CTIN_1) and Throttle (TH, setup for timer
capture CTIN_2). CH3/AUX (setup for timer capture CTIN_3) is not connected.
- The receiver outputs TH first, then followed by ST (most transmitters
output ST first, but some like FrSky GT3B output TH first)

- The interrupt triggers Timer Capture CTIN_2 at the *rising* edge of TH.
start[TH] is set with the timer value. channel_flags is 0, so
output_raw_channels is *not* called. channel_flag bit TH is set at the end
of the function.
- The interrupt triggers Timer Capture CTIN_2 at the *falling* edge of TH.
The pulse duration for TH is calculated and saved in result[TH]
- The interrupt triggers Timer Capture CTIN_1 at the *rising* edge of ST.
start[ST] is set with the timer value. channel_flags has only the TH bit
set, but not the ST bit, so output_raw_channels is *not* called.
channel_flag bit ST is set at the end of the function.
- The interrupt triggers Timer Capture CTIN_1 at the *falling* edge of ST.
The pulse duration for ST is calculated and saved in result[ST]
- [around 4..20 ms go by until the receiver repeats the servo channels]
- The interrupt triggers Timer Capture CTIN_2 at the *rising* edge of TH.
start[TH] is set with the timer value. channel_flags has the TH bit now set
from the pulse pulse before, which makes the *if* statement you quoted
*true*, therefore output_raw_channel is being called, with result[ST] and
result[TH] holding the measured pulse durations, and result[CH3] being 0
because this channel is not connected so it was not measured. After
output_raw_channel returns the TH bit in channel_flags is set because we
are just processing a new rising edge for TH, all other bits are cleared.

kind regards, Werner

On Mon, Jan 11, 2016 at 11:07 PM, Locke Huang <notifications@github.com>
wrote:

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

LockeKK, 2016-01-12:
Hello, Werner:
Thanks for the so detailed explanation. You are exact right. output_raw_channels(result); will be invoked in THE SECOND rising edge of TH. I verified this with my VS. It is well designed and very intelligent.
I should noticed the PWM for receiver is contentious. Thanks for the clarify. And this is an awesome project. Please kindly close this "issue".

BR
Locke

Closed 2016-01-12.

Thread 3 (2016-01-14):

Link failed with latest gcc-arm-none-eabi-gcc(v5.2.1)

LockeKK, 2016-01-14:
Hello, Werner:
Sorry to trigger another issue to you. Now I followed the instructions in firmware/readme.md to build mk4.
On my win7, I installed latest tool-chains:
gcc-arm-none-eabi-5_2-2015q4-20151219-win32.exe
make-3.81.exe
coreutils-5.3.0.exe

Compile is OK but there is some conflicts in the linking session.
Please see my my console:

[CC] ch3_handler.c
[CC] channel_reversing.c
[CC] config.c
[CC] config_light_programs.c
[CC] config_lights.c
[CC] crt0.c
[CC] drive_mode.c
[CC] indicators.c
[CC] light_programs.c
[CC] lights.c
[CC] main.c
[CC] persistent_storage.c
[CC] preprocessor_output.c
[CC] servo_output.c
[CC] servo_reader.c
[CC] uart_reader.c
[CC] uart0.c
[CC] utils.c
[CC] winch.c
[LD] build/firmware.elf
c:/program files (x86)/gnu tools arm embedded/5.2 2015q4/bin/../lib/gcc/arm-none-eabi/5.2.1/../../../../arm-none-eabi/bi
n/ld.exe: section .init loaded at [00002c00,00002c03] overlaps section .data loaded at [00002c00,00002c3f]
collect2.exe: error: ld returned 1 exit status
make: *** [build/firmware.elf] Error 1

From my understanding, the latest gcc might change _init @crti.o.

See the firmware.map:
.init           0x00002c00        0x4
 .init          0x00002c00        0x4 c:/program files (x86)/gnu tools arm embedded/5.2 2015q4/bin/../lib/gcc/arm-none-eabi/5.2.1/armv6-m/crti.o
                0x00002c00                _init

.init will conflict with this .data segment:
.data           0x10000000       0x40 load address 0x00002c00
                0x10000000                _data = .
 *(.data*)
 .data.throttle_threshold
                0x10000000        0x2 build/./drive_mode.o
 .data.old_light_switch_position.5100
                0x10000002        0x1 build/./lights.o
 *fill*         0x10000003        0x1
 .data.last_found.5824
                0x10000004        0x4 build/./main.o
 .data.st.5839  0x10000008        0x2 build/./main.o
 .data.th.5840  0x1000000a        0x2 build/./main.o
 .data.channel  0x1000000c       0x30 build/./main.o
                0x1000000c                channel
 .data.next_tx_index
                0x1000003c        0x1 build/./preprocessor_output.o
                0x10000040                . = ALIGN (0x4)
 *fill*         0x1000003d        0x3
                0x10000040                _edata = .

It looks cortex-m0+ belongs to armv6-m branch. So I did not have any idea about this issue.
I could not upload my firmware.map here for some network issue. If you need, need me know.
Could you please take a look? What I would like to do is evaluate how many SRAM this project needs.

Many thanks and Respect to this awesome project.

BR
Locke

laneboysrc, 2016-01-14:
Hi Locke,

I've downloaded GCC 5.2 and was able to reproduce the problem. FYI: the project was developed with GCC 4.8.2

The issue is in the linker script. The linker drags in the C run-time from GCC, but the project comes with its own little run-time, hence the conflict. Excluding the GCC run-time fixes the problem.

With the updated **light_controller.ld** file the compilation succeeds on 5.2, but I haven't tested it to see whether it also _works_.

cheers, Werner

LockeKK, 2016-01-14:
Hello, Werner:
Thanks for your so efficient response. I will take a look. I have no board to test right now as well. Anyway this could be very helpful to understand your project. It is a classical lesson in embedded system.

Thanks! ;-)

Locke

LockeKK, 2016-01-14:
Hello, Werner:
Please remove redundancy "CPU_FLAGS" in the LD session @mk4, makefile, line 88.
LDFLAGS = $(CPU_FLAGS)
LDFLAGS += -Wl,-T,$(LINKER_SCRIPT) -Wl,-nostdlib -Wl,--warn-common
LDFLAGS += -Wl,--gc-sections -Wl,-Os
LDFLAGS += -Wl,-Map=$(TARGET_MAP) -Wl,--cref
#LDFLAGS += -mthumb -mcpu=cortex-m0plus -mlittle-endian

BR
Locke

Closed 2016-01-14.

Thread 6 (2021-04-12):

LPC812M101JDH20 lead time

mhanuel26, 2021-04-12:
Hi,

Any alternative to this MCU with high lead times on all distributors?

Thanks,

laneboysrc, 2021-04-12:
For some of the hardware I've made boards with the XSON16 version of the LPC812, which is still available at some distributors. However, not easy to build at home with a 0.4mm pin pitch.
I am also looking at the LPC832, which seems mostly software compatible but needs a new PCB layout.
Some time ago I also worked on a Mk5 using Microchip (Atmel) SAMD21, but discarded the project. The firmware was working already, but the configurator would have to be adjusted. Mk5 had an on-board USB connector for WebUSB and DFU support. However initial programming would require an SWD programmer. If you want that old build for further development, shoot me an email: laneboysrc@gmail.com
The software should be relatively easily portable onto any ARM Cortex MCU that supports SPI, UART and capture timers.

laneboysrc, 2021-05-13:
LPC832 can now be used for Mk4P, 3ch and 5ch Pre-Processor. The firmware auto-detects the chip, any HEX file can be used in LPC812 and LPC832 equally. The WebUSB programmer can program LPC832 through the Configurator, but the LPC81x_ISP Python tool has not been updated for LPC832 yet.

However, now LPC832 is also out of stock everywhere...

If anyone has any suggestion for an available MCU with similar features and price, please share!

Closed 2021-05-13.

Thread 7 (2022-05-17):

Unable to control lights with AUX [was: debug help]

mhanuel26, 2022-05-17:
Hi,

After building the project with a 5-ch pre-processor I am not able to turn any led ON. I have connected ch3 from receiver into AUX of the pre-processor and light output of 5 ch pre processor to master light controller. Stearing and Throttle works fine. I am using MkP4 rev1 and using a jumper to connect led anode to VIN. I have tested the Mk4P board with the blinking led test firmware and I also have used led15 to be always on, so I know it is working this part.

How can I debug the issue of receiving the CH3 signals?

Will appreciate your comments,
Thanks,

laneboysrc, 2022-05-18:
Hi,

Attached is a light controller configuration that should help with debugging.
[light_controller.config.aux-debug.txt](https://github.com/laneboysrc/rc-light-controller/files/8714479/light_controller.config.aux-debug.txt)

The configuration expects that (at least) two LEDs are connected to the light controller: **OUT0** and **OUT15** (or **OUT15S**).

During initialization of the system, the LED on **OUT0** **blinks very fast**.
If no signal is received from the light controller or Pre-Processor then the LED on **OUT15/15S** **blinks very fast**.

If a valid signal is received than the LED on **OUT15/OUT15S** **blinks slowly**.
The **brightness** of the LED on **OUT0** reflects the servo pulse on the AUX input of the Pre-Processor. If your transmitter has a two position switch on the channel connected to AUX, then **OUT0 should change between dark and bright** when you operate the switch.

For test purpose you can also connect CH1 (Steering) to the AUX input of the Pre-Processor, then you should be able to change the brightness when you move the Steering left/right.

The functions above have been implemented with simple "Light Programs" (small scripts running on the light controller), see "Light program" tab in the Configurator.

kind regards, Werner

mhanuel26, 2022-05-18:
Hi Werner,

Thank you foor your prompt response,

How do you create the configuration file? I am using the LPC812 with Flash 16K and have some issues while trying to load it.

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

Is that creating a project and building it or using the web Tool?

Thanks again,
Manuel

mhanuel26, 2022-05-18:
Hi Werner,

I hook up the light main light controler directly to the receiver and it seems to work, thou the clicks are difficult to understand, at least I am able to turn on/off main beams indicators using some sort of combinatio of 1 or 3 clicks. When I use the 5-ch preprocessor, I am not able to do so.

Do you have a configuration that works for 5-ch pre processor? I believe the standard configuration I can generate using web tool should work but it seems not the case, so I am wondering if you know how looks like the signals from light output pf processor to ST/Rx input on main processor?

Thanks again,

laneboysrc, 2022-05-19:
Hi Manuel,

The configuration file is created by the Configurator. The configuration file is not directly flashed into the light controller, but instead you load it into the Configurator and then save a .HEX file. The .HEX file then gets flashed into the light controller.

Steps:

- Open the Configurator https://laneboysrc.github.io/rc-light-controller/
- Click the "Load" button on the top and select the config file [light_controller.config.aux-debug.txt](https://github.com/laneboysrc/rc-light-controller/files/8723407/light_controller.config.aux-debug.txt)
- Click the "Save firmware" button, this will create a "light_controller.hex" file in the Download folder of your web browser.
- Flash the "light_controller.hex" file

For your convenience, here is the .HEX file with the "aux-debug" configuration:
[light_controller.aux-debug.hex.zip](https://github.com/laneboysrc/rc-light-controller/files/8723914/light_controller.aux-debug.hex.zip)

Based on your description "turn on/off main beams indicators using some sort of combination of 1 or 3 clicks" I would say that the switch type of your transmitter does not match the switch type that is configured in the light controller.

By default CH3/AUX expects a two-position switch. "Two-position switch" means that when you connect a servo to CH3, when you operate the switch the servo would move to one end position, and when you operate the switch again it would move to the other end position. Physically a two-position switch can implemented as slide switch, but it could also be a push-button (push: servo moves to pos1; push: servo moves to pos2; push: servo moves to pos1 ...)

In the **CH3/AUX configuration** tab of the Configurator you can select a switch type that matches your transmitter. The light controller user manual ([https://laneboysrc.github.io/rc-light-controller/light-controller-instructions-mk4.pdf](https://laneboysrc.github.io/rc-light-controller/light-controller-instructions-mk4.pdf)) describes on page 38 **Appendix G: Determining the AUX switch type** how to figure out which type your transmitter implements.

Please also check the end-point adjustments for CH3. They should be "100% or -100 .. +100, or something like that.

For test purpose you can also connect CH1 to AUX on the Pre-Processor. Then turning the steering wheel from full left to full right will trigger 1 "click", and when you turn it back to full left another "click" and so on.

Configuration that works for 5ch PP:
[light_controller.config.5chpp-default.txt](https://github.com/laneboysrc/rc-light-controller/files/8723886/light_controller.config.5chpp-default.txt)
[light_controller.5chpp-default.hex.zip](https://github.com/laneboysrc/rc-light-controller/files/8723903/light_controller.5chpp-default.hex.zip)

This is basically the configuration that the light controller ships with. It expects a two-position switch on AUX, and implements lights as described in the user manual on page 5.
This configuration is the one that you see when you load the Configurator https://laneboysrc.github.io/rc-light-controller/ and change the **Operating mode** to "Master, 5ch Pre-Processor input".

kind regards, Werner

mhanuel26, 2022-05-19:
Hi Werner,

Thank you again and sorry for the misunderstanding of the hex file.

I can confirm the AUX/CH3 is a two position switch, getting a 2ms pulse width or 1ms pulse width. I can actually see some serial output on the LIGHT output of the 5CH-PP, but the output seems to not change with the position of the switch. See below a capture with a logic analyzer

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

Here is a zoom version of the 2ms

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

So with the 5CH-PP LIGHT output connected to the MAIN Light controller ST/Rx Input, I can see the **OUT0** Led blinking slowly (if I disconnect the cable it starts blinking fast for example). But the **OUT15** Led never change the brightness when changing Switch position.

What could possible be wrong?

Manuel

laneboysrc, 2022-05-19:
Hi Manuel,

great that you have a logic analyzer. It is clear that the Pre-Processor is unable to read the AUX signal properly, despite it changing from 1ms to 2ms. Therefore also OUT0 does not change brightness.

That points to a defect Pre-Processor.

To verify this, could you please repeat the test with AUX2 (and/or AUX3) instead of AUX. It is unlikely that all 3 AUX channels have the same issue. If AUX has a problem, but AUX2 works, then using AUX2 should show a change in the Pre-Processor output on the logic analyzer when you flip the switch.

Maybe there is a bad solder joint on the Pre-Processor?

I am not sure which 5ch Pre-Processor version you have. Here are 3 photos that show different revisions and how the AUX signal goes to the which pin on the Microcontroller.

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

kind regards, Werner

mhanuel26, 2022-05-19:
Hi Werner,

That was the problem in fact, the solder was not good.

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

Now with this configuration the main controller works as expected. Thank youso much for all the help.

Manuel

Closed 2022-05-19.

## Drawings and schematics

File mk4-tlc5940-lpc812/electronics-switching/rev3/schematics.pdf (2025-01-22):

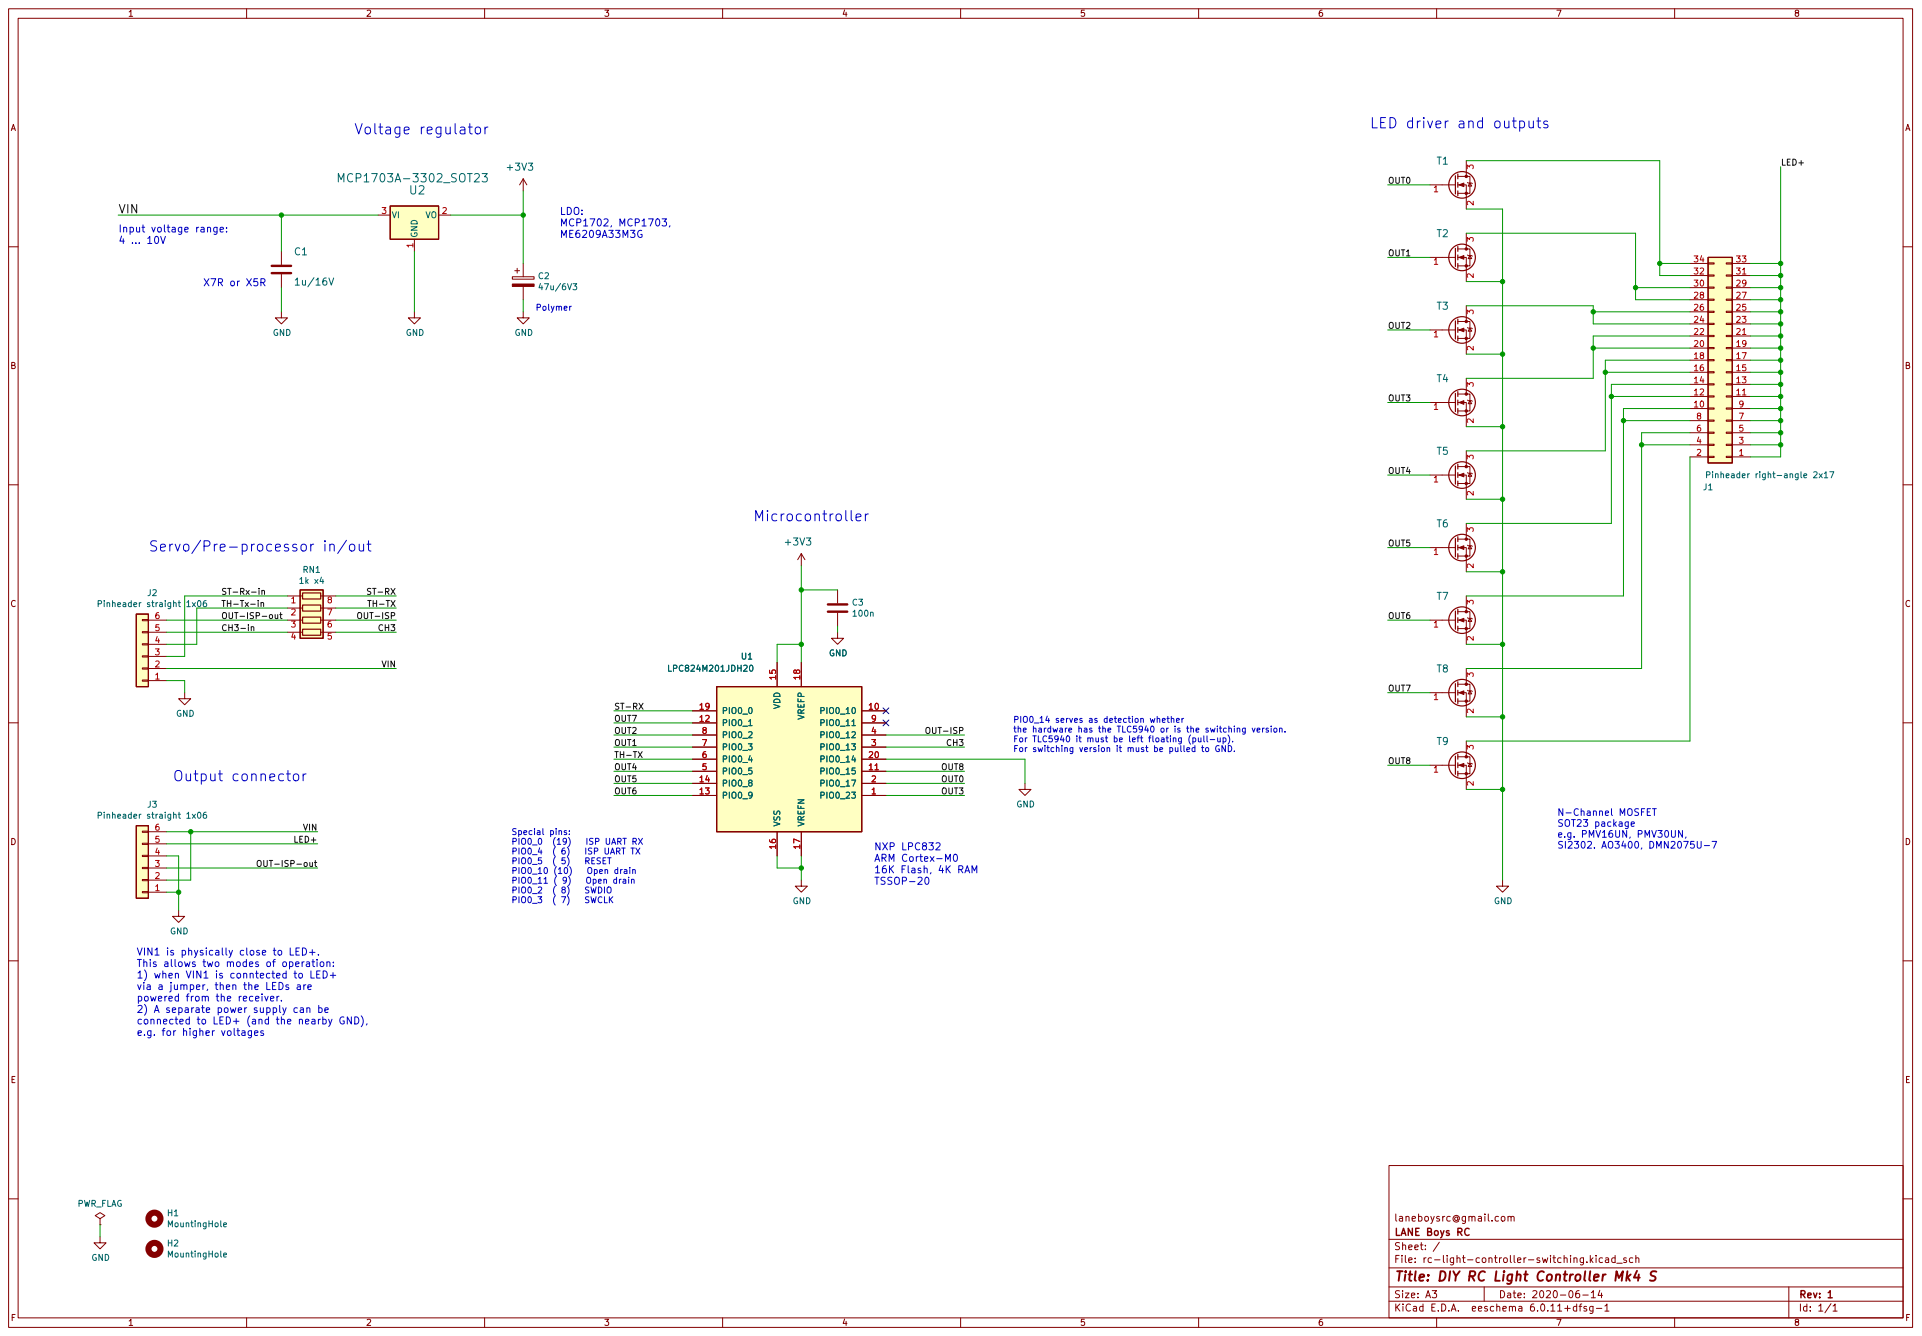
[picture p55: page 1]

VIN OUT-ISP-out ST-Rx-in VIN

20 | 19
18 | 17
16 | 15
14 | 13
12 | 11
10 | 9

laneboysrc@gmail.com
File: rc-light-controller-switching.kicad_sch Sheet: / LANE Boys RC

Id: 1/1 Title: DIY RC Light Controller Mk4 S

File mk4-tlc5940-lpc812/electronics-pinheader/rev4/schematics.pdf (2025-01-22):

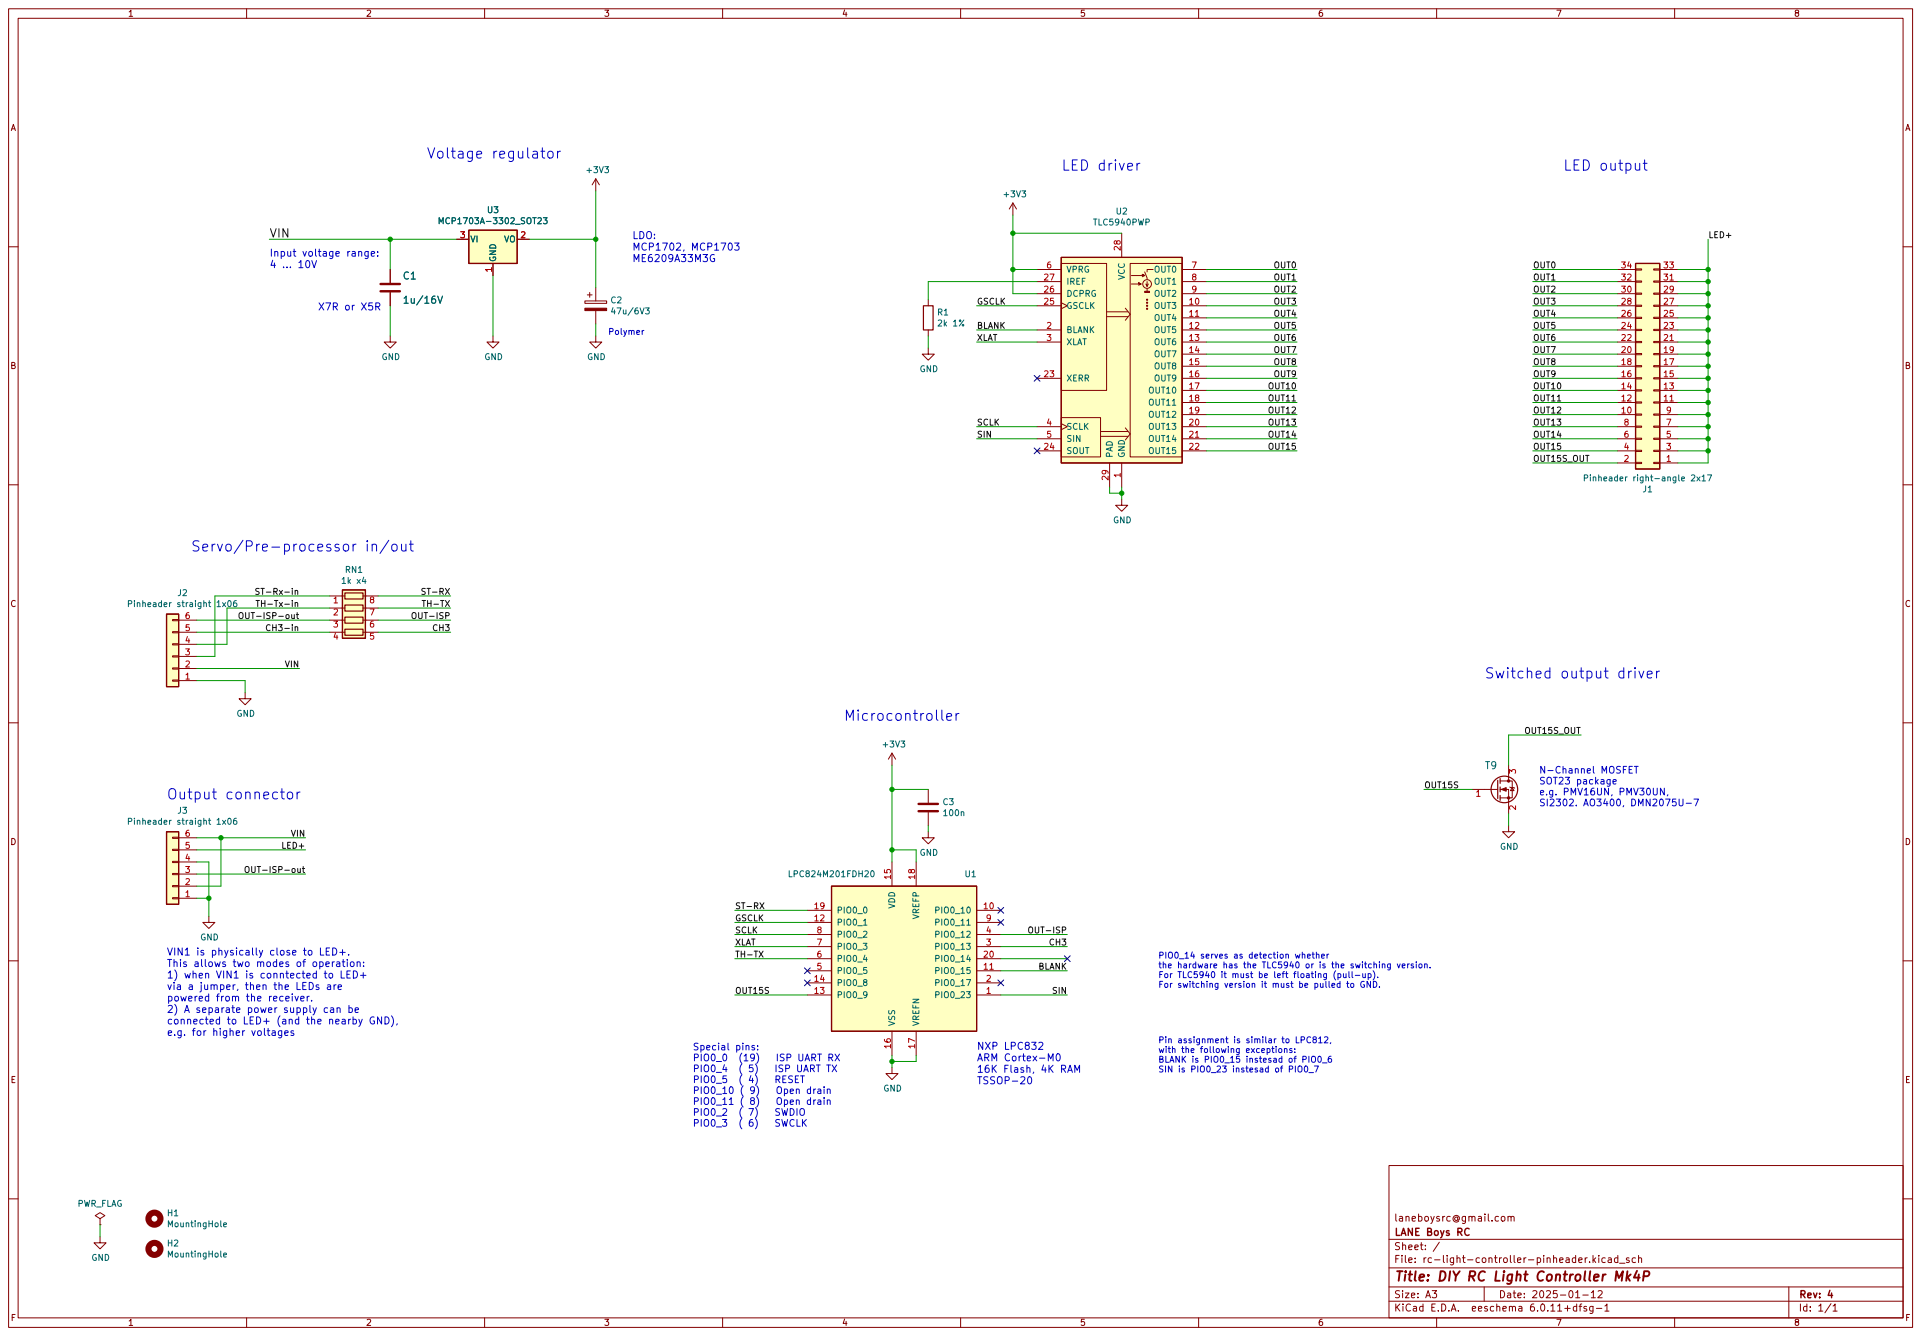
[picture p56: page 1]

laneboysrc@gmail.com
File: rc-light-controller-pinheader.kicad_sch Sheet: / LANE Boys RC

Id: 1/1 Title: DIY RC Light Controller Mk4P

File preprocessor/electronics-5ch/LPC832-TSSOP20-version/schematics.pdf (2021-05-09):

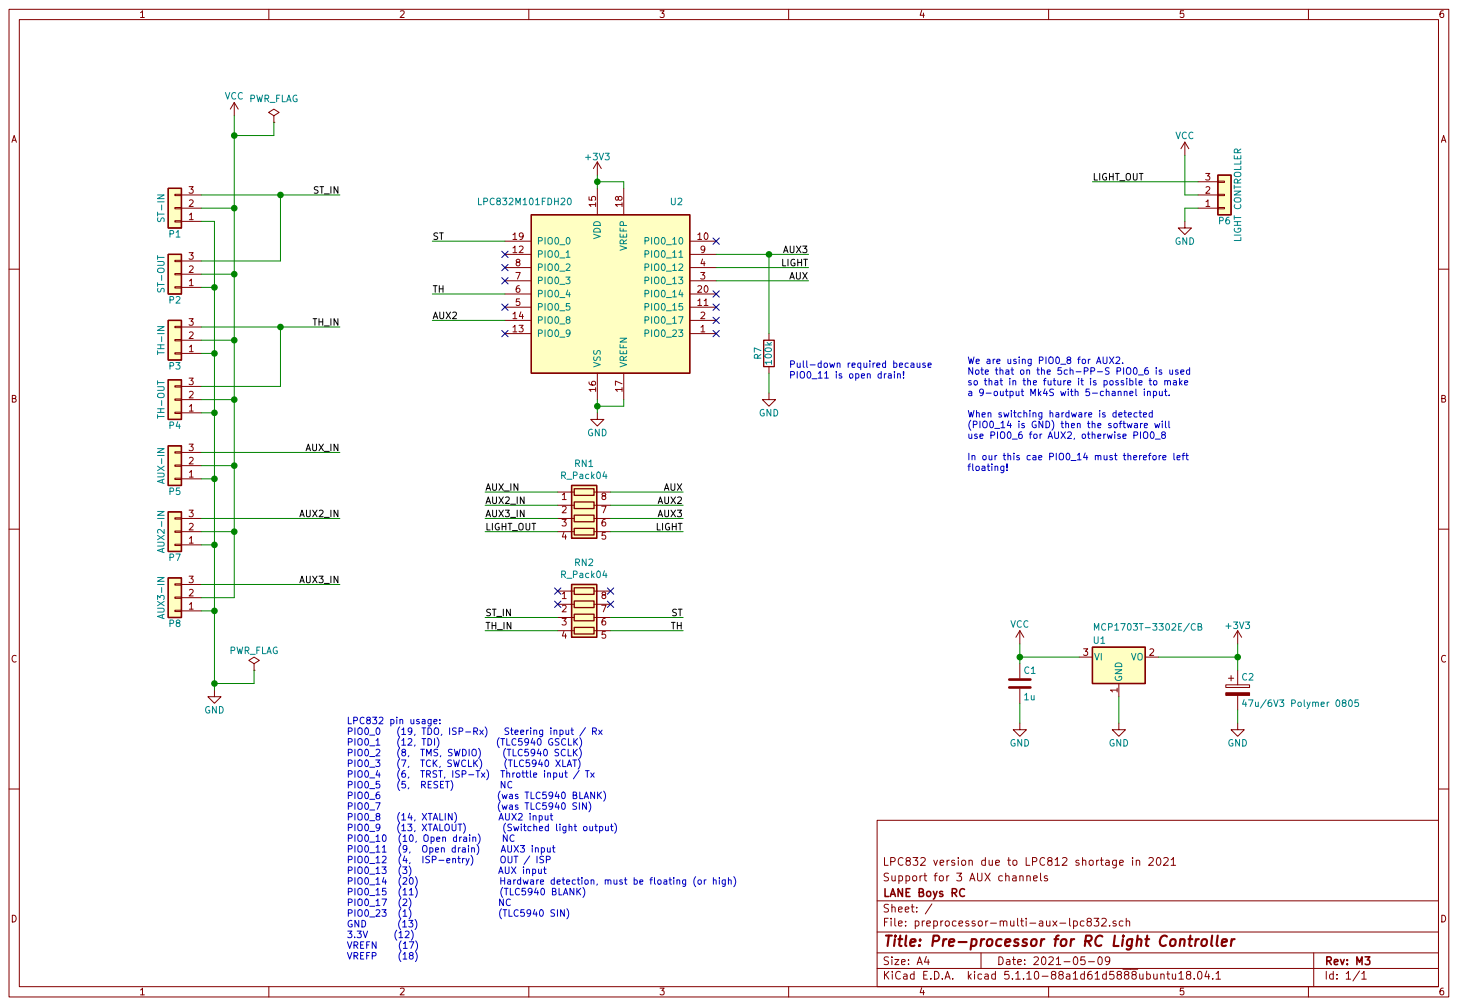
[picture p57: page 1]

Pull-down required because
PIO0_11 is open drain!

We are using PIO0_8 for AUX2. Note that on the 5ch-PP-S PIO0_6 is used

so that in the future it is possible to make
a 9-output Mk4S with 5-channel input.

When switching hardware is detected
(PIO0_14 is GND) then the software will use PIO0_6 for AUX2, otherwise PIO0_8

In our this cae PIO0_14 must therefore left
floating!

LPC832 pin usage:
PIO0_0 (19, TDO, ISP-Rx) Steering input / Rx
PIO0_2 (8, TMS, SWDIO) (TLC5940 SCLK)
PIO0_3 (7, TCK, SWCLK) (TLC5940 XLAT)
PIO0_4 (6, TRST, ISP-Tx) Throttle input / Tx
PIO0_10 (10, Open drain) NC
PIO0_11 (9, Open drain) AUX3 input
PIO0_12 (4, ISP-entry) OUT / ISP
VREFN (17)
VREFP (18)

LPC832 version due to LPC812 shortage in 2021
Support for 3 AUX channels
File: preprocessor-multi-aux-lpc832.sch Sheet: / LANE Boys RC

Id: 1/1 Title: Pre-processor for RC Light Controller

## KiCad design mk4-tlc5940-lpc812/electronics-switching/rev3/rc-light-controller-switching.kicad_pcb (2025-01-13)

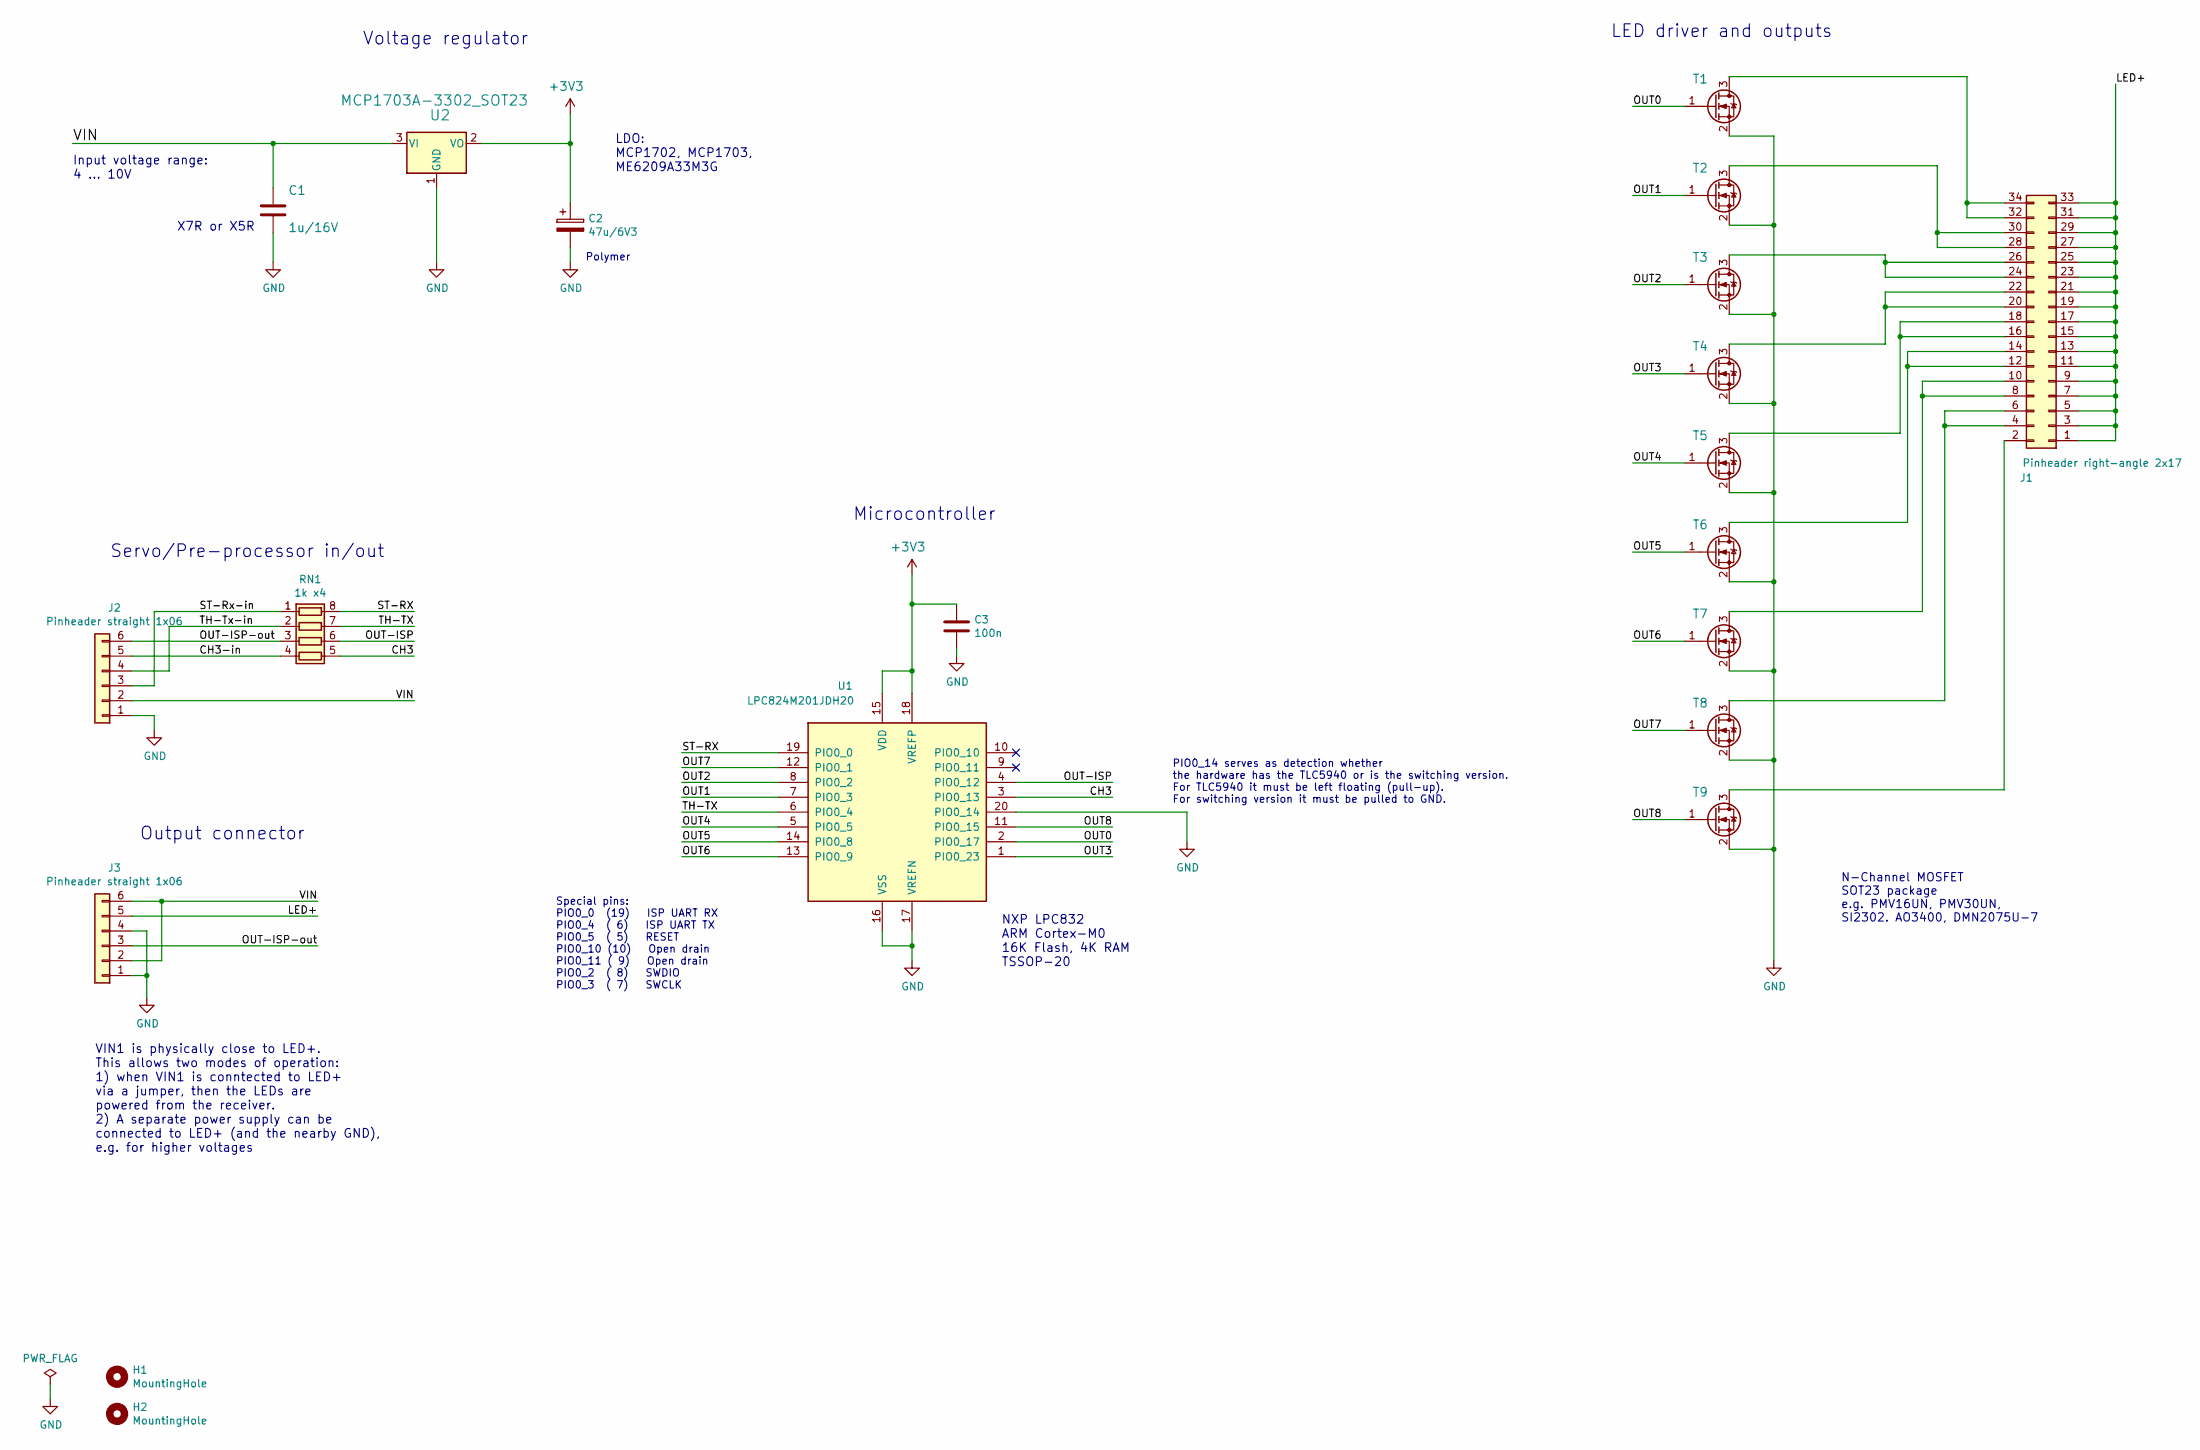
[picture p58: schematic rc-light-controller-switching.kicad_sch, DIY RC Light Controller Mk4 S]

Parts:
C1: 1u/16V; C_0805_2012Metric
C2: 47u/6V3; C_0805_2012Metric
C3: 100n; C_0603_1608Metric
H1, H2: MountingHole; MountingHole_2.2mm_M2_ISO14580
J1: Pinheader right-angle 2x17; PinHeader_2x17_P2.54mm_Horizontal
J2, J3: Pinheader straight 1x06; PinHeader_1x06_P2.54mm_Flat
RN1: 1k x4; R_Array_Convex_4x0603
T1, T2, T3, T4, T5, T6, T7, T8, T9: PMV30UN; SOT-23
U1: LPC824M201JDH20; TSSOP-20_4.4x6.5mm_P0.65mm
U2: MCP1703A-3302_SOT23; SOT-23W

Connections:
+3V3: C2.1, C3.1, U1.15 (VDD), U1.18 (VREFP), U2.2 (VO)
/CH3: RN1.5 (R4.2), U1.3 (PIO0_13)
/CH3-in: J2.5, RN1.4 (R4.1)
/LED+: J1.1, J1.3, J1.5, J1.7, J1.9, J1.11, J1.13, J1.15, J1.17, J1.19, J1.21, J1.23, J1.25, J1.27, J1.29, J1.31, J1.33, J3.5
/OUT0: T1.1 (G), U1.2 (PIO0_17)
/OUT1: T2.1 (G), U1.7 (PIO0_3)
/OUT2: T3.1 (G), U1.8 (PIO0_2)
/OUT3: T4.1 (G), U1.1 (PIO0_23)
/OUT4: T5.1 (G), U1.5 (PIO0_5)
/OUT5: T6.1 (G), U1.14 (PIO0_8)
/OUT6: T7.1 (G), U1.13 (PIO0_9)
/OUT7: T8.1 (G), U1.12 (PIO0_1)
/OUT8: T9.1 (G), U1.11 (PIO0_15)
/OUT-ISP: RN1.6 (R3.2), U1.4 (PIO0_12)
/OUT-ISP-out: J2.6, J3.3, RN1.3 (R3.1)
/ST-RX: RN1.8 (R1.2), U1.19 (PIO0_0)
/ST-Rx-in: J2.3, RN1.1 (R1.1)
/TH-TX: RN1.7 (R2.2), U1.6 (PIO0_4)
/TH-Tx-in: J2.4, RN1.2 (R2.1)
/VIN: C1.1, J2.2, J3.2, J3.6, U2.3 (VI)
GND: C1.2, C2.2, C3.2, J2.1, J3.1, J3.4, T1.2 (S), T2.2 (S), T3.2 (S), T4.2 (S), T5.2 (S), T6.2 (S), T7.2 (S), T8.2 (S), T9.2 (S), U1.16 (VSS), U1.17 (VREFN), U1.20 (PIO0_14), U2.1 (GND)
unnamed: J1.2, T9.3 (D)
unnamed: J1.4, J1.6, T8.3 (D)
unnamed: J1.8, J1.10, T7.3 (D)
unnamed: J1.12, J1.14, T6.3 (D)
unnamed: J1.16, J1.18, T5.3 (D)
unnamed: J1.20, J1.22, T4.3 (D)
unnamed: J1.24, J1.26, T3.3 (D)
unnamed: J1.28, J1.30, T2.3 (D)
unnamed: J1.32, J1.34, T1.3 (D)

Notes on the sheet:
N-Channel MOSFET SOT23 package e.g. PMV16UN, PMV30UN, SI2302. AO3400, DMN2075U-7
PIO0_14 serves as detection whether the hardware has the TLC5940 or is the switching version. For TLC5940 it must be left floating (pull-up). For switching version it must be pulled to GND.
Polymer
Microcontroller
X7R or X5R
Input voltage range: 4 ... 10V
LED driver and outputs
Special pins: PIO0_0 (19) ISP UART RX PIO0_4 ( 6) ISP UART TX PIO0_5 ( 5) RESET PIO0_10 (10) Open drain PIO0_11 ( 9) Open drain PIO0_2 ( 8) SWDIO PIO0_3 ( 7) SWCLK
Servo/Pre-processor in/out
Voltage regulator
VIN1 is physically close to LED+. This allows two modes of operation: 1) when VIN1 is conntected to LED+ via a jumper, then the LEDs are powered from the receiver. 2) A separate power supply can be connected to LED+ (and the nearby GND), e.g. for higher voltages
LDO: MCP1702, MCP1703, ME6209A33M3G
Output connector
NXP LPC832 ARM Cortex-M0 16K Flash, 4K RAM TSSOP-20

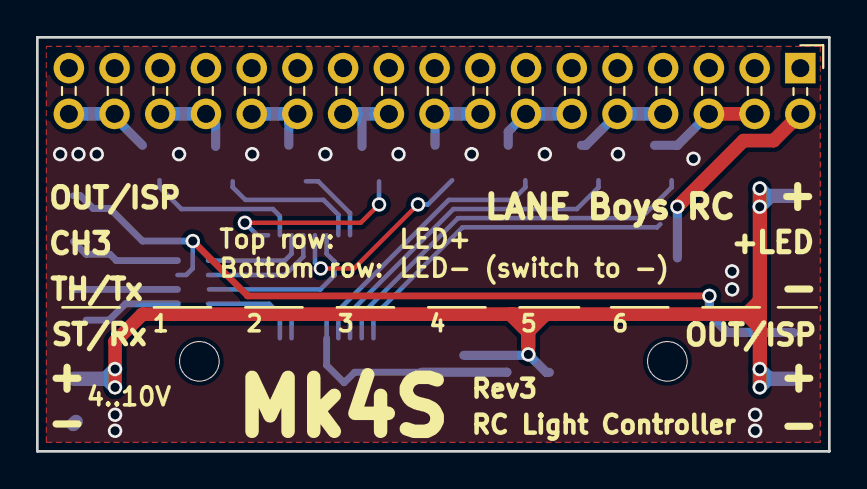
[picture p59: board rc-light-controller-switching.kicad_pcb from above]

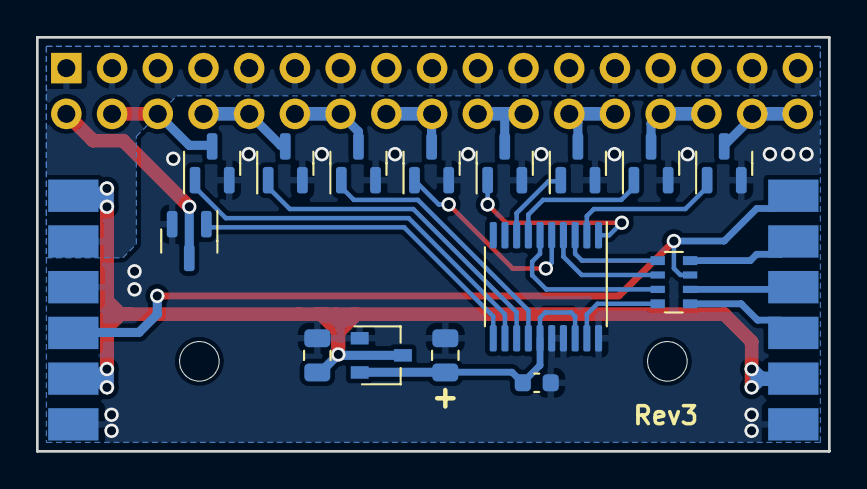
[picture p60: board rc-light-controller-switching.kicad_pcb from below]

Board: 2 copper layers, 44.0 x 23.0 mm, 20 parts (17 on the bottom side), 30 nets.

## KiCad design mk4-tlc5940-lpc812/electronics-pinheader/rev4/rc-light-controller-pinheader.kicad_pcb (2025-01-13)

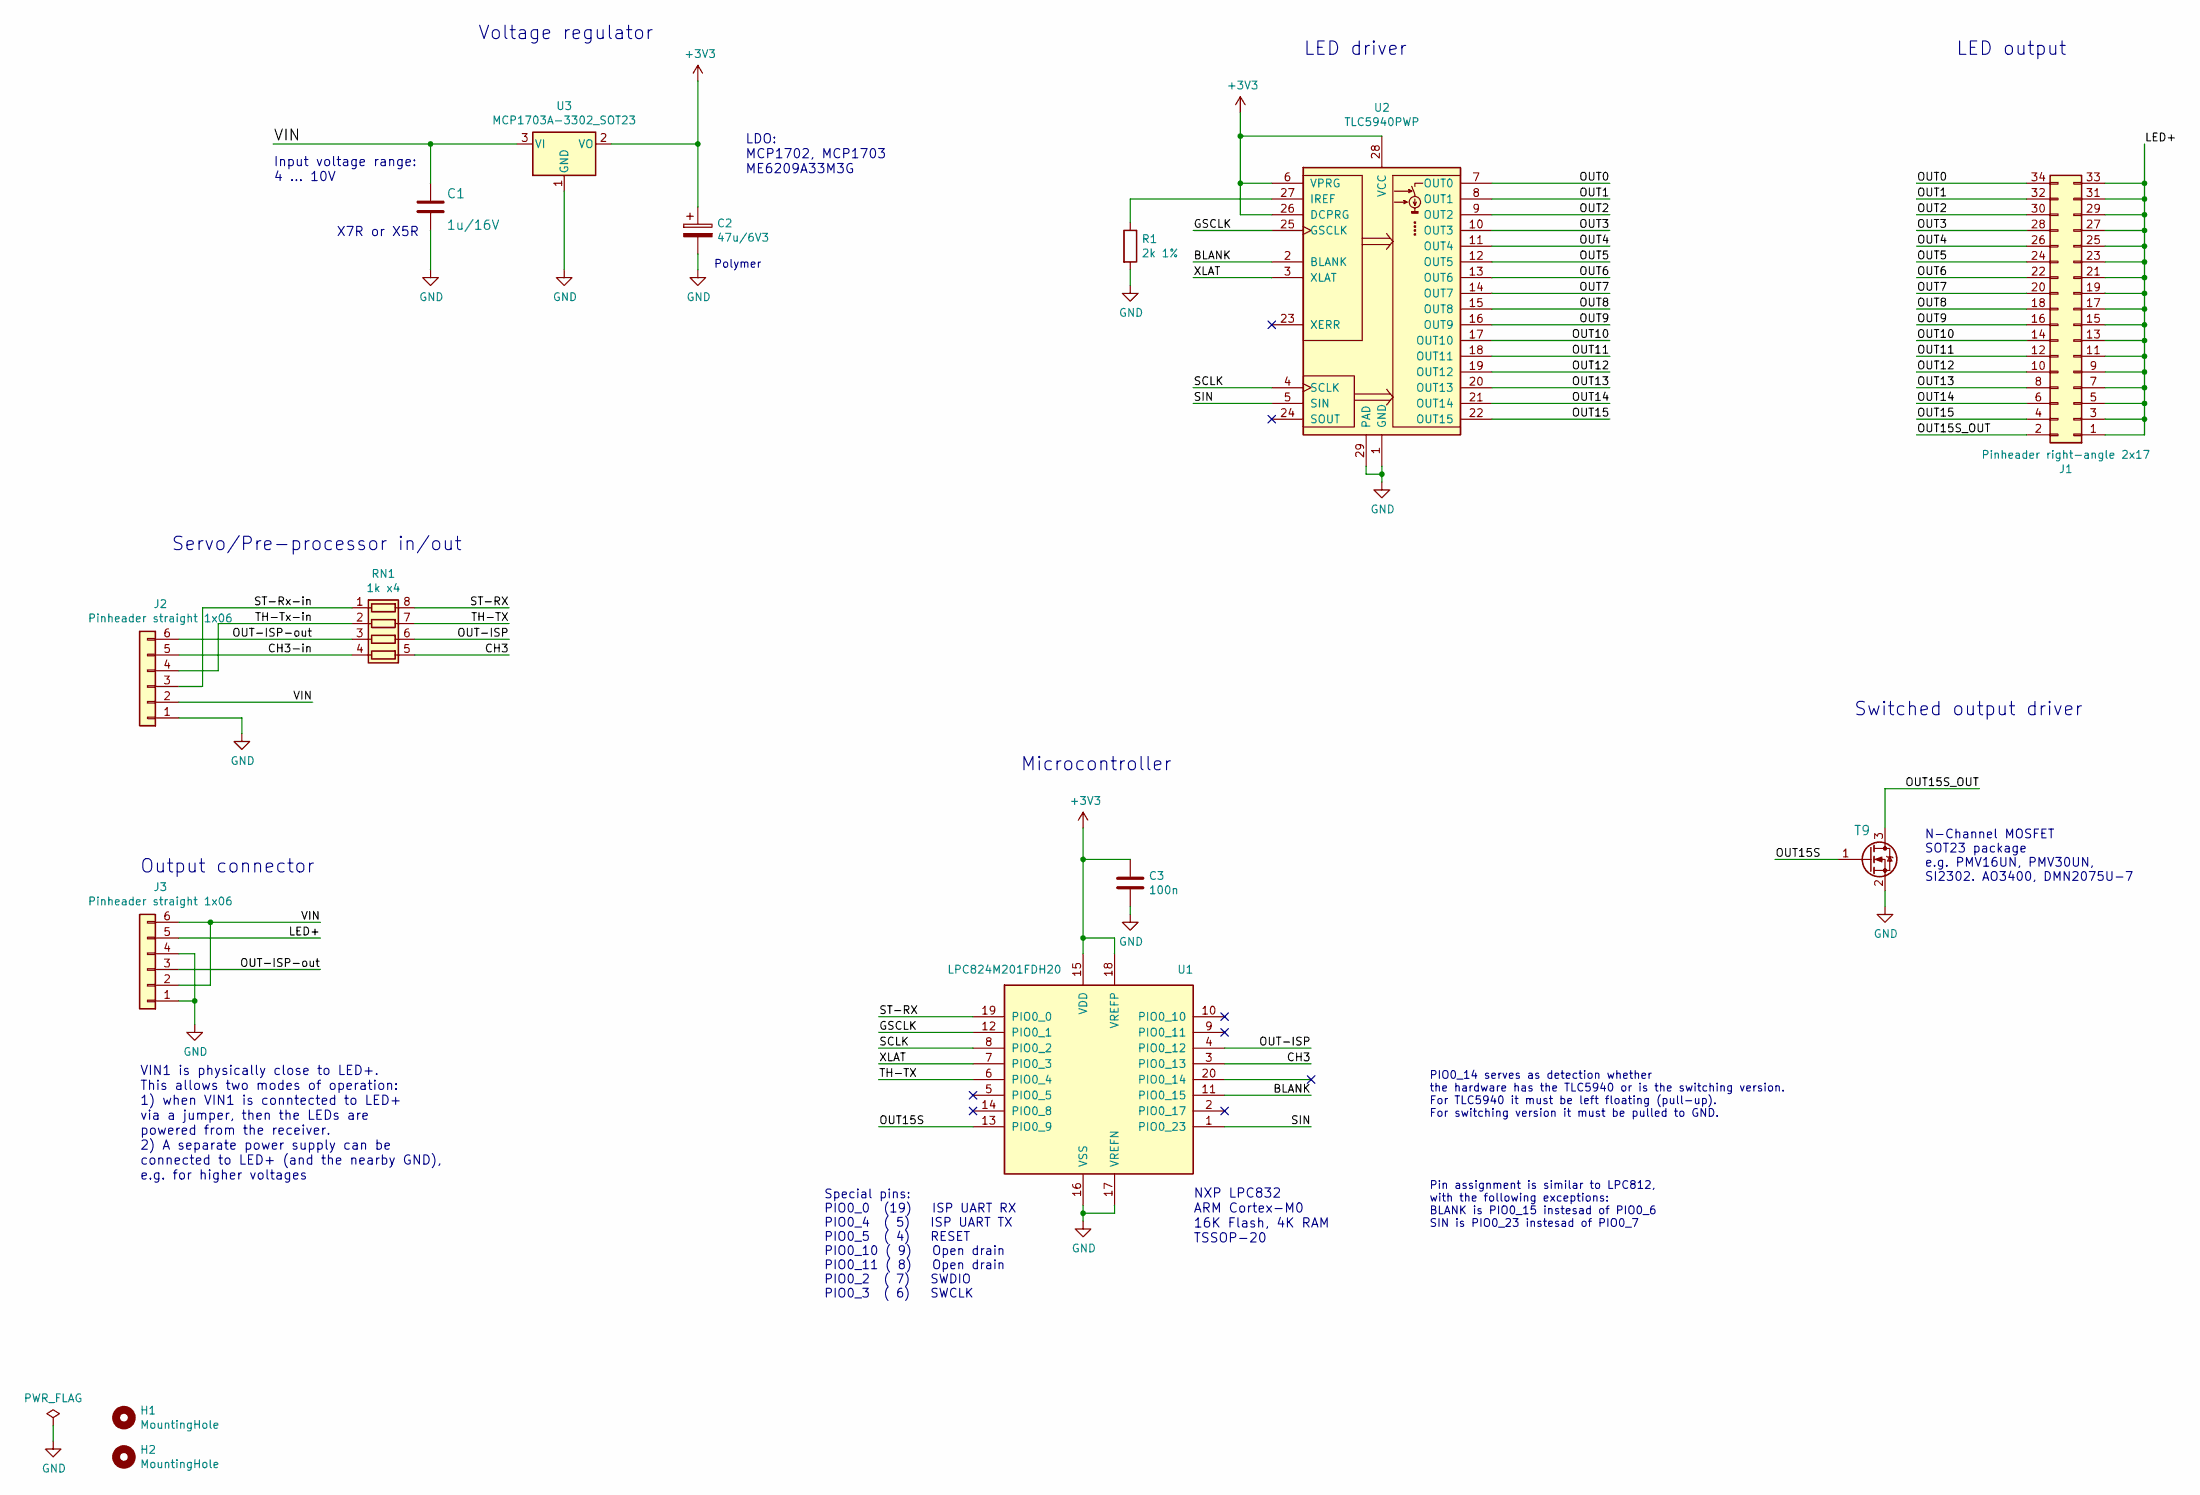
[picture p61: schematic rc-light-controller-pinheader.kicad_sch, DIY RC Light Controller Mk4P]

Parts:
C1: 1u/16V; C_0805_2012Metric
C2: 47u/6V3; C_0805_2012Metric
C3: 100n; C_0603_1608Metric
H1, H2: MountingHole; MountingHole_2.2mm_M2_ISO14580
J1: Pinheader right-angle 2x17; PinHeader_2x17_P2.54mm_Horizontal
J2, J3: Pinheader straight 1x06; PinHeader_1x06_P2.54mm_Flat
R1: 2k 1%; R_0603_1608Metric
RN1: 1k x4; R_Array_Convex_4x0603
T9: PMV30UN; SOT-23
U1: LPC824M201FDH20; TSSOP-20_4.4x6.5mm_P0.65mm
U2: TLC5940PWP; SOP65P640X120-29N
U3: MCP1703A-3302_SOT23; SOT-23W

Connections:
+3V3: C2.1, C3.1, U1.15 (VDD), U1.18 (VREFP), U2.6 (VPRG), U2.26 (DCPRG), U2.28 (VCC), U3.2 (VO)
/BLANK: U1.11 (PIO0_15), U2.2 (BLANK)
/CH3: RN1.5 (R4.2), U1.3 (PIO0_13)
/CH3-in: J2.5, RN1.4 (R4.1)
/GSCLK: U1.12 (PIO0_1), U2.25 (GSCLK)
/LED+: J1.1, J1.3, J1.5, J1.7, J1.9, J1.11, J1.13, J1.15, J1.17, J1.19, J1.21, J1.23, J1.25, J1.27, J1.29, J1.31, J1.33, J3.5
/OUT0: J1.34, U2.7 (OUT0)
/OUT1: J1.32, U2.8 (OUT1)
/OUT2: J1.30, U2.9 (OUT2)
/OUT3: J1.28, U2.10 (OUT3)
/OUT4: J1.26, U2.11 (OUT4)
/OUT5: J1.24, U2.12 (OUT5)
/OUT6: J1.22, U2.13 (OUT6)
/OUT7: J1.20, U2.14 (OUT7)
/OUT8: J1.18, U2.15 (OUT8)
/OUT9: J1.16, U2.16 (OUT9)
/OUT10: J1.14, U2.17 (OUT10)
/OUT11: J1.12, U2.18 (OUT11)
/OUT12: J1.10, U2.19 (OUT12)
/OUT13: J1.8, U2.20 (OUT13)
/OUT14: J1.6, U2.21 (OUT14)
/OUT15: J1.4, U2.22 (OUT15)
/OUT15S: T9.1 (G), U1.13 (PIO0_9)
/OUT15S_OUT: J1.2, T9.3 (D)
/OUT-ISP: RN1.6 (R3.2), U1.4 (PIO0_12)
/OUT-ISP-out: J2.6, J3.3, RN1.3 (R3.1)
/SCLK: U1.8 (PIO0_2), U2.4 (SCLK)
/SIN: U1.1 (PIO0_23), U2.5 (SIN)
/ST-RX: RN1.8 (R1.2), U1.19 (PIO0_0)
/ST-Rx-in: J2.3, RN1.1 (R1.1)
/TH-TX: RN1.7 (R2.2), U1.6 (PIO0_4)
/TH-Tx-in: J2.4, RN1.2 (R2.1)
/VIN: C1.1, J2.2, J3.2, J3.6, U3.3 (VI)
/XLAT: U1.7 (PIO0_3), U2.3 (XLAT)
GND: C1.2, C2.2, C3.2, J2.1, J3.1, J3.4, R1.2, T9.2 (S), U1.16 (VSS), U1.17 (VREFN), U2.1 (GND), U2.29 (PAD), U3.1 (GND)
unnamed: R1.1, U2.27 (IREF)

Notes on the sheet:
N-Channel MOSFET SOT23 package e.g. PMV16UN, PMV30UN, SI2302. AO3400, DMN2075U-7
LED driver
Microcontroller
LED output
Special pins: PIO0_0 (19) ISP UART RX PIO0_4 ( 5) ISP UART TX PIO0_5 ( 4) RESET PIO0_10 ( 9) Open drain PIO0_11 ( 8) Open drain PIO0_2 ( 7) SWDIO PIO0_3 ( 6) SWCLK
LDO: MCP1702, MCP1703 ME6209A33M3G
X7R or X5R
PIO0_14 serves as detection whether the hardware has the TLC5940 or is the switching version. For TLC5940 it must be left floating (pull-up). For switching version it must be pulled to GND.
Polymer
Pin assignment is similar to LPC812, with the following exceptions: BLANK is PIO0_15 instesad of PIO0_6 SIN is PIO0_23 instesad of PIO0_7
VIN1 is physically close to LED+. This allows two modes of operation: 1) when VIN1 is conntected to LED+ via a jumper, then the LEDs are powered from the receiver. 2) A separate power supply can be connected to LED+ (and the nearby GND), e.g. for higher voltages
Voltage regulator
Servo/Pre-processor in/out
Switched output driver
NXP LPC832 ARM Cortex-M0 16K Flash, 4K RAM TSSOP-20
Output connector
Input voltage range: 4 ... 10V

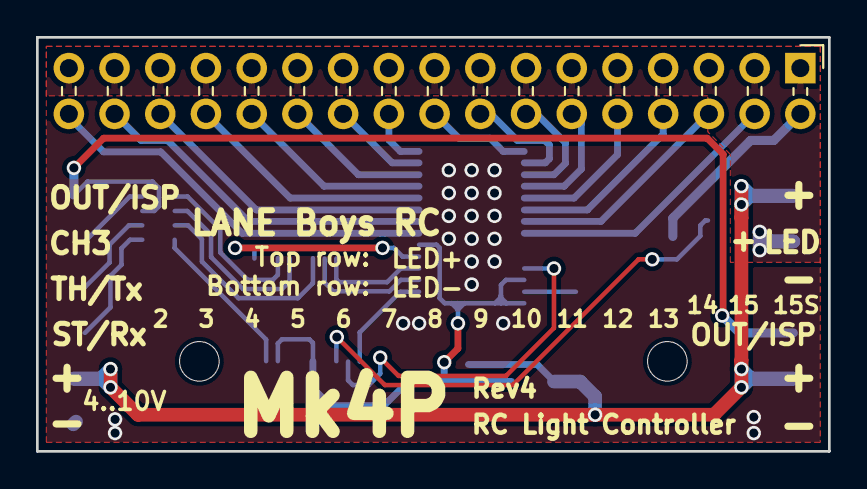
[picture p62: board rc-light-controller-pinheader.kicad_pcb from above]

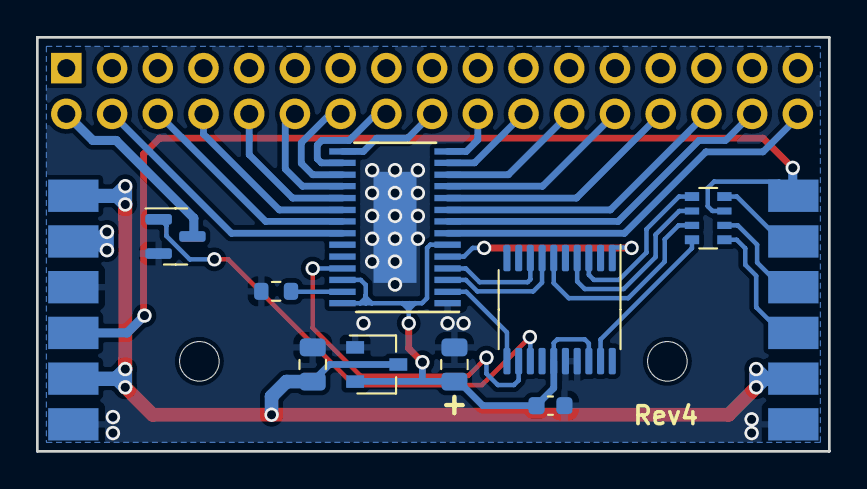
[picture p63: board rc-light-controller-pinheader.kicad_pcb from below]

Board: 2 copper layers, 44.0 x 23.0 mm, 14 parts (11 on the bottom side), 36 nets.

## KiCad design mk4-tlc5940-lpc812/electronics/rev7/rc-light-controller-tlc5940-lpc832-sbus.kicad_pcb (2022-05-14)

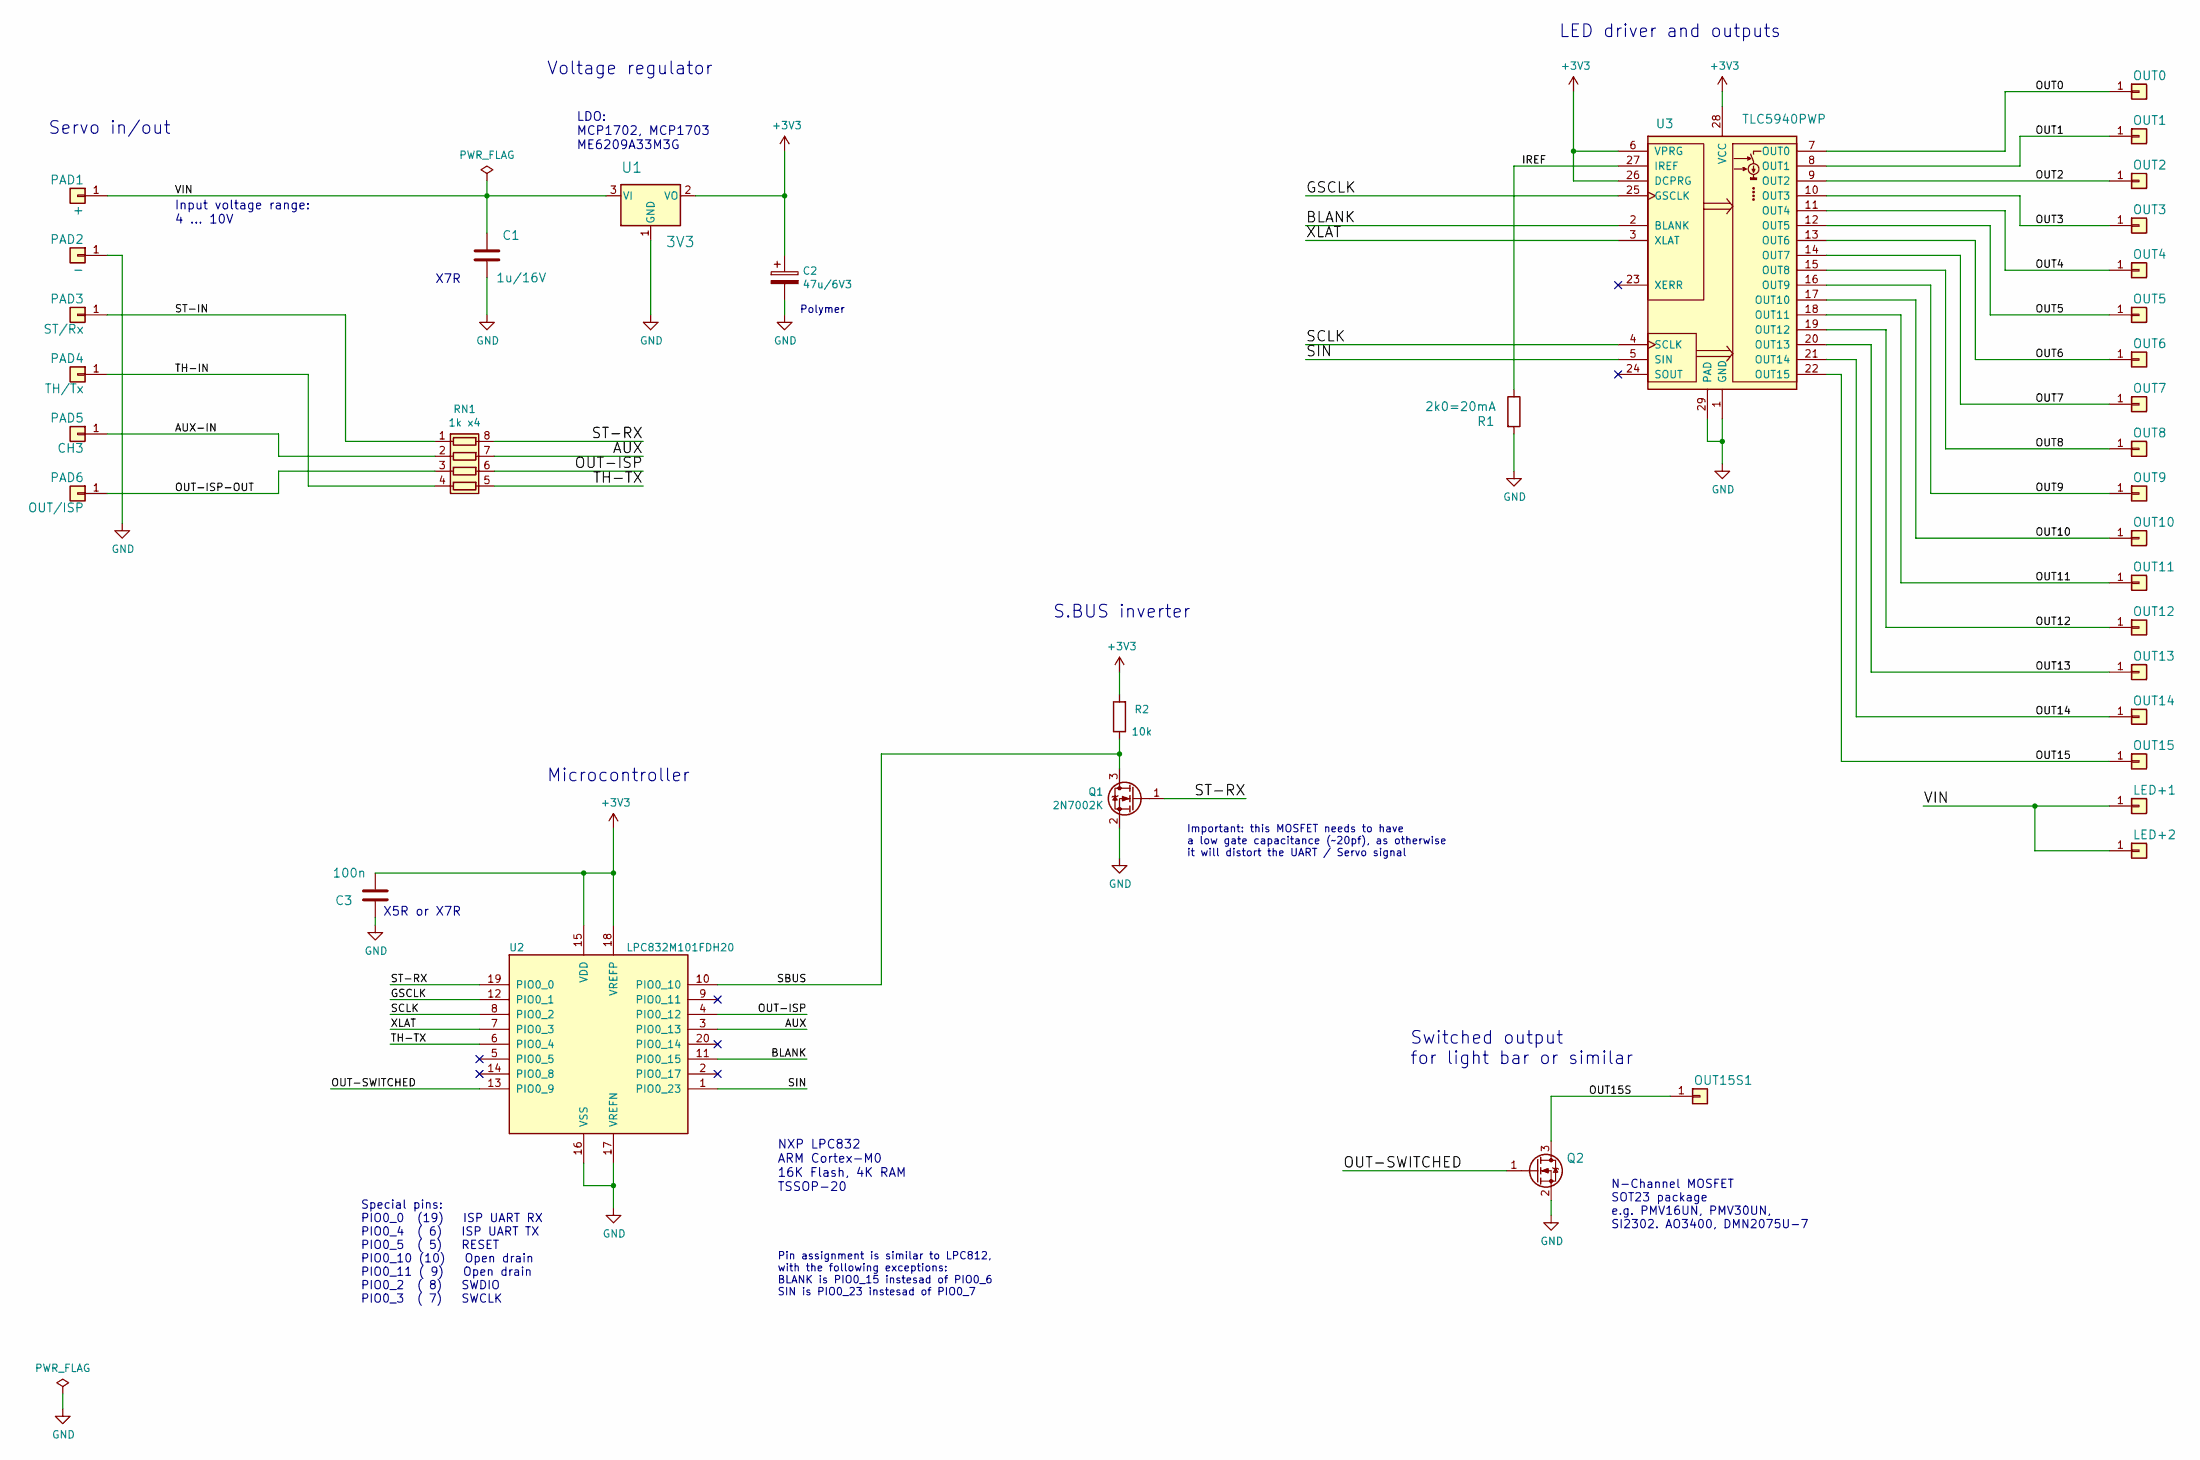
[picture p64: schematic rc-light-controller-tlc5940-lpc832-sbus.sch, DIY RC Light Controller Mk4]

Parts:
C1: 1u/16V; C_0805_2012Metric
C2: 47u/6V3; C_0805_2012Metric
C3: 100n; C_0603_1608Metric
LED+1, LED+2: SMD50X100
OUT0, OUT1, OUT2, OUT3, OUT4, OUT5, OUT6, OUT7, OUT8, OUT9, OUT10, OUT11, OUT12, OUT13, OUT14, OUT15, OUT15S1: SMD50X100
PAD1: +; SMD80X120
PAD2: -; SMD80X120
PAD3: ST/Rx; SMD80X120
PAD4: TH/Tx; SMD80X120
PAD5: CH3; SMD80X120
PAD6: OUT/ISP; SMD80X120
Q1: 2N7002K; SOT-23
Q2: NMOSSOT23; SOT-23
R1: 2k0=20mA; R_0603_1608Metric
R2: 10k; R_0603_1608Metric
RN1: 1k x4; R_Array_Convex_4x0603
U1: 3V3; SOT-23W
U2: LPC832M101FDH20; TSSOP-20_4.4x6.5mm_P0.65mm
U3: TLC5940PWP; SOP65P640X120-29N

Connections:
+3V3: C2.1, C3.2, R2.2, U1.2 (VO), U2.15 (VDD), U2.18 (VREFP), U3.6 (VPRG), U3.26 (DCPRG), U3.28 (VCC)
/AUX: RN1.7 (R2.2), U2.3 (PIO0_13)
/AUX-IN: PAD5.1, RN1.2 (R2.1)
/BLANK: U2.11 (PIO0_15), U3.2 (BLANK)
/GSCLK: U2.12 (PIO0_1), U3.25 (GSCLK)
/IREF: R1.1, U3.27 (IREF)
/OUT0: OUT0.1, U3.7 (OUT0)
/OUT1: OUT1.1, U3.8 (OUT1)
/OUT2: OUT2.1, U3.9 (OUT2)
/OUT3: OUT3.1, U3.10 (OUT3)
/OUT4: OUT4.1, U3.11 (OUT4)
/OUT5: OUT5.1, U3.12 (OUT5)
/OUT6: OUT6.1, U3.13 (OUT6)
/OUT7: OUT7.1, U3.14 (OUT7)
/OUT8: OUT8.1, U3.15 (OUT8)
/OUT9: OUT9.1, U3.16 (OUT9)
/OUT10: OUT10.1, U3.17 (OUT10)
/OUT11: OUT11.1, U3.18 (OUT11)
/OUT12: OUT12.1, U3.19 (OUT12)
/OUT13: OUT13.1, U3.20 (OUT13)
/OUT14: OUT14.1, U3.21 (OUT14)
/OUT15: OUT15.1, U3.22 (OUT15)
/OUT15S: OUT15S1.1, Q2.3 (D)
/OUT-ISP: RN1.6 (R3.2), U2.4 (PIO0_12)
/OUT-ISP-OUT: PAD6.1, RN1.3 (R3.1)
/OUT-SWITCHED: Q2.1 (G), U2.13 (PIO0_9)
/SBUS: Q1.3 (D), R2.1, U2.10 (PIO0_10)
/SCLK: U2.8 (PIO0_2), U3.4 (SCLK)
/SIN: U2.1 (PIO0_23), U3.5 (SIN)
/ST-IN: PAD3.1, RN1.1 (R1.1)
/ST-RX: Q1.1 (G), RN1.8 (R1.2), U2.19 (PIO0_0)
/TH-IN: PAD4.1, RN1.4 (R4.1)
/TH-TX: RN1.5 (R4.2), U2.6 (PIO0_4)
/VIN: C1.1, LED+1.1, LED+2.1, PAD1.1, U1.3 (VI)
/XLAT: U2.7 (PIO0_3), U3.3 (XLAT)
GND: C1.2, C2.2, C3.1, PAD2.1, Q1.2 (S), Q2.2 (S), R1.2, U1.1 (GND), U2.16 (VSS), U2.17 (VREFN), U3.1 (GND), U3.29 (PAD)

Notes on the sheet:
Special pins: PIO0_0 (19) ISP UART RX PIO0_4 ( 6) ISP UART TX PIO0_5 ( 5) RESET PIO0_10 (10) Open drain PIO0_11 ( 9) Open drain PIO0_2 ( 8) SWDIO PIO0_3 ( 7) SWCLK
Servo in/out
LED driver and outputs
Voltage regulator
Microcontroller
X7R
Input voltage range: 4 ... 10V
LDO: MCP1702, MCP1703 ME6209A33M3G
X5R or X7R
NXP LPC832 ARM Cortex-M0 16K Flash, 4K RAM TSSOP-20
Switched output for light bar or similar
N-Channel MOSFET SOT23 package e.g. PMV16UN, PMV30UN, SI2302. AO3400, DMN2075U-7
Polymer
Pin assignment is similar to LPC812, with the following exceptions: BLANK is PIO0_15 instesad of PIO0_6 SIN is PIO0_23 instesad of PIO0_7
Important: this MOSFET needs to have a low gate capacitance (~~20pf), as otherwise it will distort the UART / Servo signal
S.BUS inverter

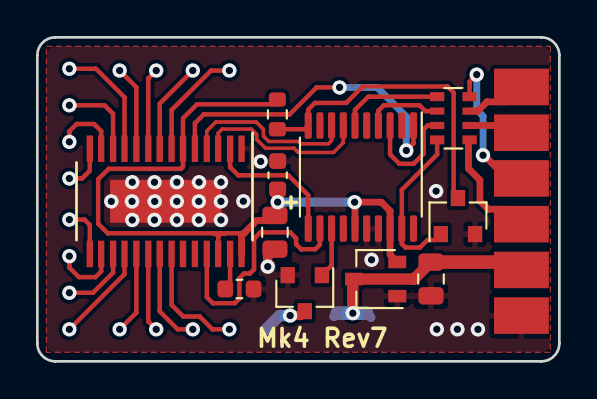
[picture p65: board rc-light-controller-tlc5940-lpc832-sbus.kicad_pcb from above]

Board: 2 copper layers, 29.0 x 18.0 mm, 36 parts (0 on the bottom side), 36 nets.

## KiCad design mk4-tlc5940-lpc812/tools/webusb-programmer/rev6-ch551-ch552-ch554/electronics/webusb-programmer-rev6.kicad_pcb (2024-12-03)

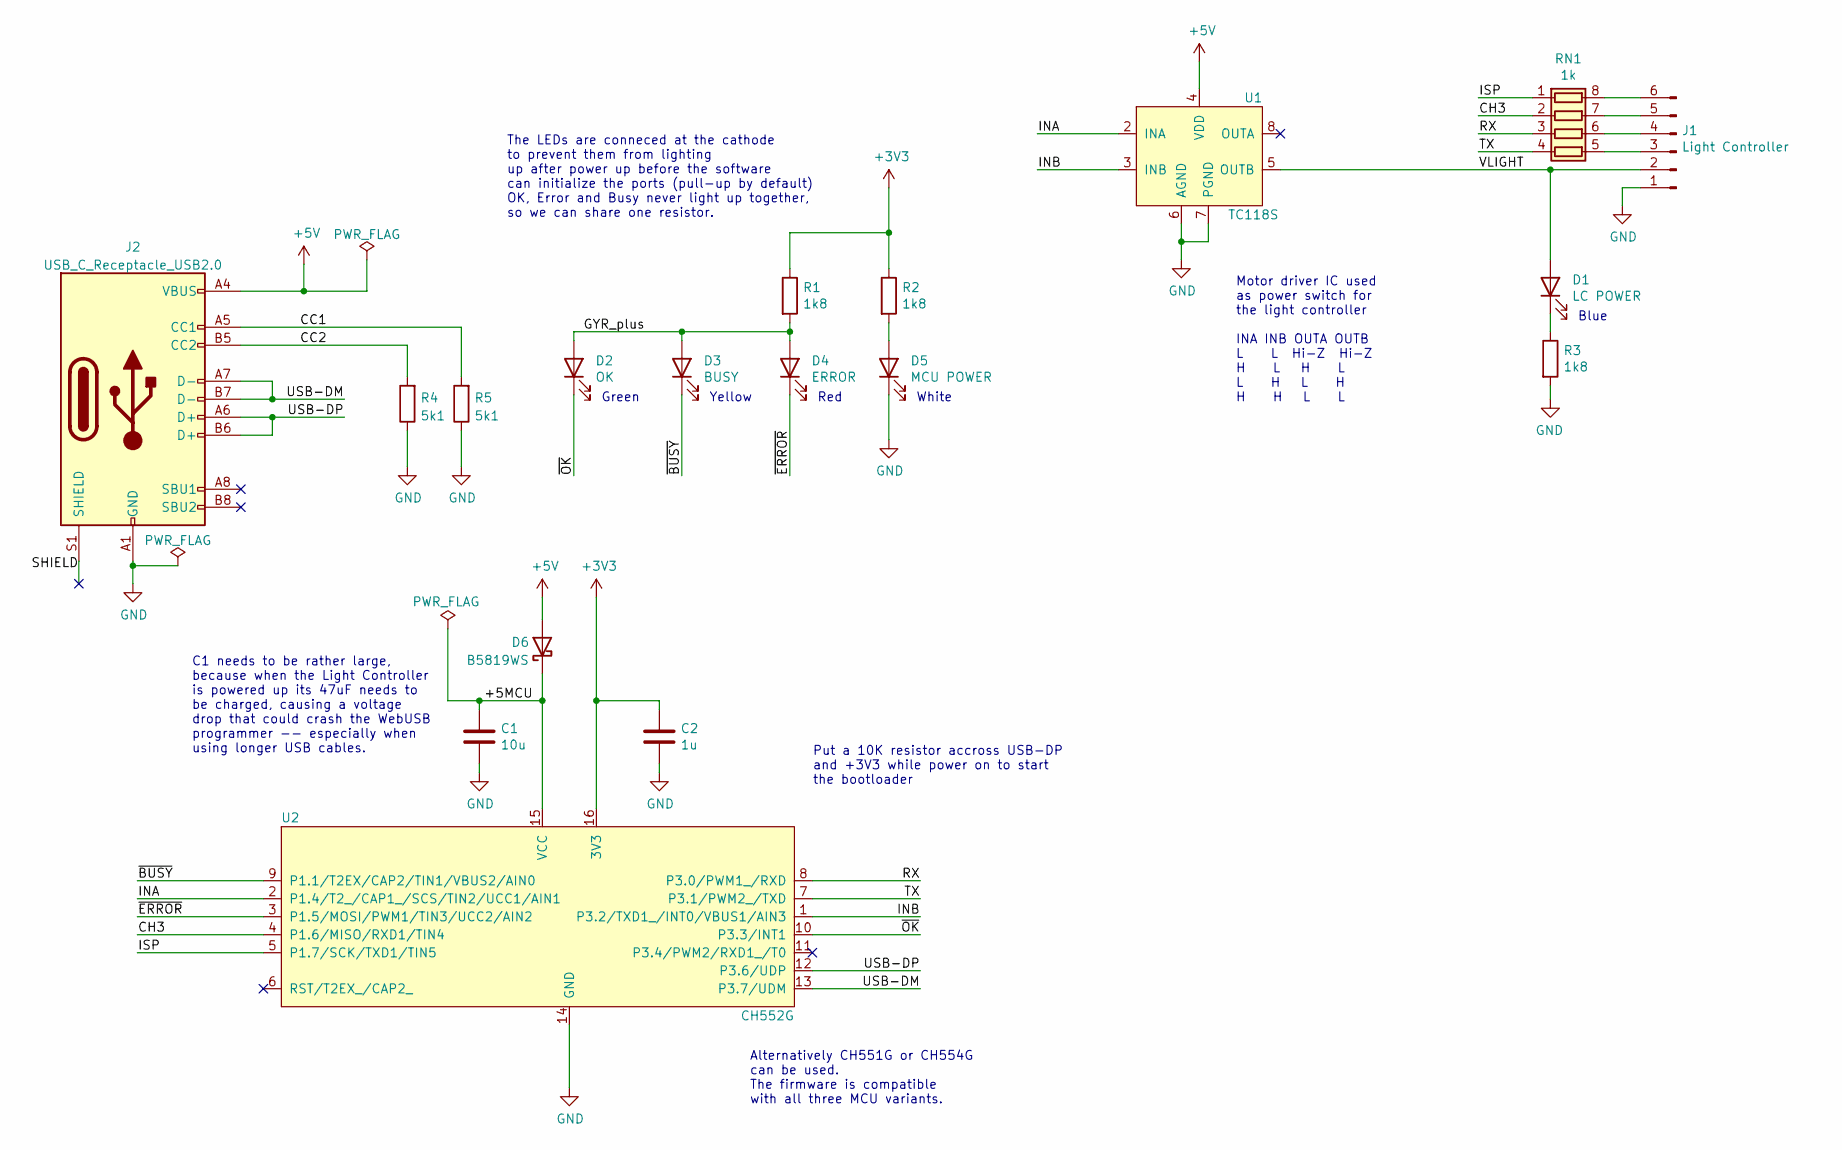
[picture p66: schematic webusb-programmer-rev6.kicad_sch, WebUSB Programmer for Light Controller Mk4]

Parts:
C1: 10u; C_0603_1608Metric
C2: 1u; C_0603_1608Metric
D1: LC POWER; LED_0805_2012Metric_see_through; LCSC part number C779807
D2: OK; LED_0805_2012Metric_see_through; LCSC part number C779806
D3: BUSY; LED_0805_2012Metric_see_through; LCSC part number C779805
D4: ERROR; LED_0805_2012Metric_see_through; LCSC part number C389527
D5: MCU POWER; LED_0805_2012Metric_see_through; LCSC part number C779804
D6: B5819WS; D_SOD-123
J1: Light Controller; PinHeader_1x06_P2.54mm_Flat
J2: USB_C_Receptacle_USB2.0; USB_C_Receptacle_G-Switch_GT-USB-7010ASV
R1, R2, R3: 1k8; R_0603_1608Metric
R4, R5: 5k1; R_0603_1608Metric
RN1: 1k; R_Array_Convex_4x0603
U1: TC118S; SOP-8_3.9x4.9mm_P1.27mm; LCSC part number C88308
U2: CH552G; SO-16_3.9x9.9mm_P1.27mm; LCSC part number C111292

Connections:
+3V3: C2.1, R1.1, R2.1, U2.16 (3V3)
+5V: D6.2 (A), J2.A4 (VBUS), J2.A9 (VBUS), J2.B4 (VBUS), J2.B9 (VBUS), U1.4 (VDD)
/+5MCU: C1.1, D6.1 (K), U2.15 (VCC)
/CC1: J2.A5 (CC1), R5.2
/CC2: J2.B5 (CC2), R4.2
/CH3: RN1.2 (R2.1), U2.4 (P1.6/MISO/RXD1/TIN4)
/GYR_plus: D2.2 (A), D3.2 (A), D4.2 (A), R1.2
/INA: U1.2 (INA), U2.2 (P1.4/T2_/CAP1_/SCS/TIN2/UCC1/AIN1)
/INB: U1.3 (INB), U2.1 (P3.2/TXD1_/INT0/VBUS1/AIN3)
/ISP: RN1.1 (R1.1), U2.5 (P1.7/SCK/TXD1/TIN5)
/RX: RN1.3 (R3.1), U2.8 (P3.0/PWM1_/RXD)
/SHIELD: J2.S1 (SHIELD)
/TX: RN1.4 (R4.1), U2.7 (P3.1/PWM2_/TXD)
/USB-DM: J2.A7 (D-), J2.B7 (D-), U2.13 (P3.7/UDM)
/USB-DP: J2.A6 (D+), J2.B6 (D+), U2.12 (P3.6/UDP)
/VLIGHT: D1.2 (A), J1.2, U1.5 (OUTB)
/~BUSY: D3.1 (K), U2.9 (P1.1/T2EX/CAP2/TIN1/VBUS2/AIN0)
/~ERROR: D4.1 (K), U2.3 (P1.5/MOSI/PWM1/TIN3/UCC2/AIN2)
/~OK: D2.1 (K), U2.10 (P3.3/INT1)
GND: C1.2, C2.2, D5.1 (K), J1.1, J2.A1 (GND), J2.A12 (GND), J2.B1 (GND), J2.B12 (GND), R3.2, R4.1, R5.1, U1.6 (AGND), U1.7 (PGND), U2.14 (GND)
unnamed: D1.1 (K), R3.1
unnamed: D5.2 (A), R2.2
unnamed: J1.3, RN1.5 (R4.2)
unnamed: J1.4, RN1.6 (R3.2)
unnamed: J1.5, RN1.7 (R2.2)
unnamed: J1.6, RN1.8 (R1.2)

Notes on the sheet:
C1 needs to be rather large, because when the Light Controller is powered up its 47uF needs to be charged, causing a voltage drop that could crash the WebUSB programmer -- especially when using longer USB cables.
Red
Blue
Green
Alternatively CH551G or CH554G can be used. The firmware is compatible with all three MCU variants.
White
Put a 10K resistor accross USB-DP and +3V3 while power on to start the bootloader
Motor driver IC used as power switch for the light controller INA INB OUTA OUTB L L Hi-Z Hi-Z H L H L L H L H H H L L
The LEDs are conneced at the cathode to prevent them from lighting up after power up before the software can initialize the ports (pull-up by default) OK, Error and Busy never light up together, so we can share one resistor.
Yellow

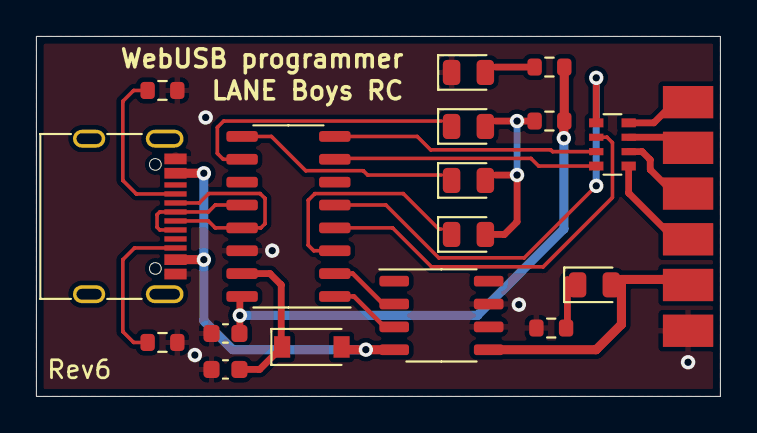
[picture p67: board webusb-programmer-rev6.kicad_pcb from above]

Board: 2 copper layers, 38.0 x 20.0 mm, 18 parts (0 on the bottom side), 25 nets.

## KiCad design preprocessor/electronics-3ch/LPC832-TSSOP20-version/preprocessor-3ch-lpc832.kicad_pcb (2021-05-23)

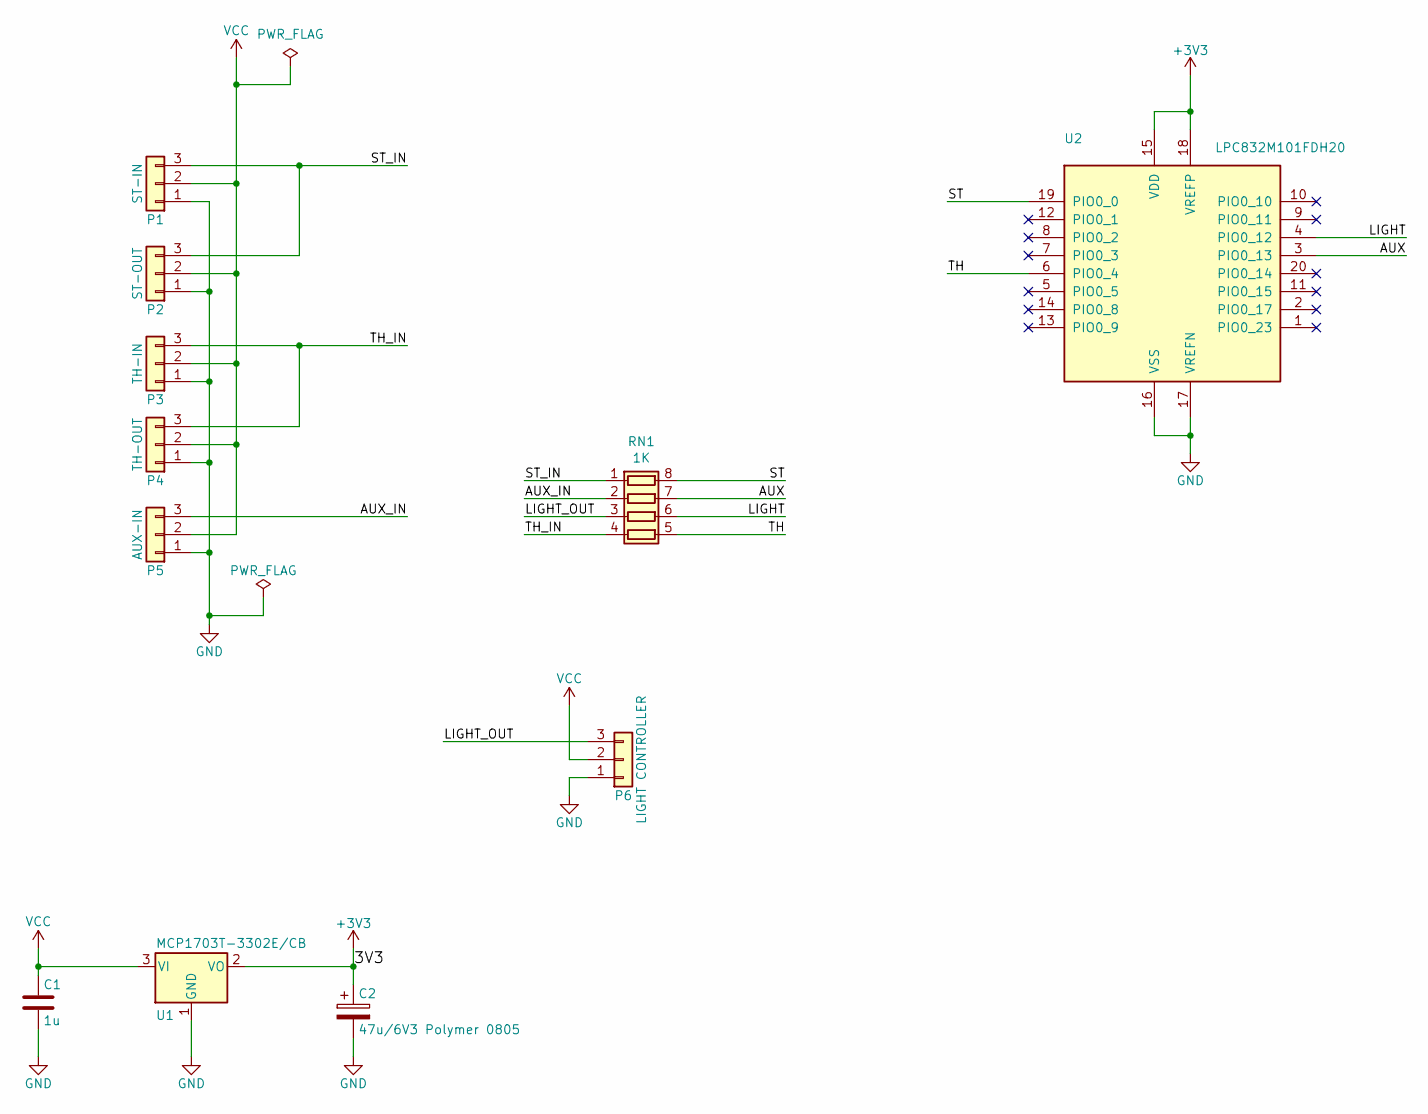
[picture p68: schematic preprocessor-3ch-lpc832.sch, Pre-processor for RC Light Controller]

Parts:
C1: 1u; C_0805_2012Metric_Pad1.15x1.40mm_HandSolder
C2: 47u/6V3 Polymer 0805; C_0805_2012Metric_Pad1.15x1.40mm_HandSolder
P1: ST-IN; Pin_Header_Straight_1x03_Pitch2.54mm
P2: ST-OUT; Pin_Header_Straight_1x03_Pitch2.54mm
P3: TH-IN; Pin_Header_Straight_1x03_Pitch2.54mm
P4: TH-OUT; Pin_Header_Straight_1x03_Pitch2.54mm
P5: AUX-IN; Pin_Header_Straight_1x03_Pitch2.54mm
P6: LIGHT CONTROLLER; Pin_Header_Straight_1x03_Pitch2.54mm
RN1: 1K; R_Array_Convex_4x0603
U1: MCP1703T-3302E/CB; SOT-23W
U2: LPC832M101FDH20; TSSOP-20_4.4x6.5mm_P0.65mm

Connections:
+3V3: C2.1, U1.2 (VO), U2.15 (VDD), U2.18 (VREFP)
/AUX: RN1.7 (R2.2), U2.3 (PIO0_13)
/AUX_IN: P5.3, RN1.2 (R2.1)
/LIGHT: RN1.6 (R3.2), U2.4 (PIO0_12)
/LIGHT_OUT: P6.3, RN1.3 (R3.1)
/ST: RN1.8 (R1.2), U2.19 (PIO0_0)
/ST_IN: P1.3, P2.3, RN1.1 (R1.1)
/TH: RN1.5 (R4.2), U2.6 (PIO0_4)
/TH_IN: P3.3, P4.3, RN1.4 (R4.1)
GND: C1.2, C2.2, P1.1, P2.1, P3.1, P4.1, P5.1, P6.1, U1.1 (GND), U2.16 (VSS), U2.17 (VREFN)
VCC: C1.1, P1.2, P2.2, P3.2, P4.2, P5.2, P6.2, U1.3 (VI)

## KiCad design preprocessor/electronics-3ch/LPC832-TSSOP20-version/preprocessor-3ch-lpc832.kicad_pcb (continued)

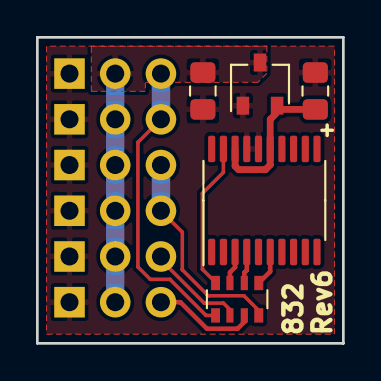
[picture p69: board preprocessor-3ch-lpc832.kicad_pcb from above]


Board: 2 copper layers, 17.0 x 17.0 mm, 11 parts (6 on the bottom side), 11 nets.

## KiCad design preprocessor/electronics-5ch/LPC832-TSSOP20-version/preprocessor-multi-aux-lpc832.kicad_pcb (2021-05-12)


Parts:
C1: 1u; C_0805_2012Metric_Pad1.15x1.40mm_HandSolder
C2: 47u/6V3 Polymer 0805; C_0805_2012Metric_Pad1.15x1.40mm_HandSolder
P1: ST-IN; PinHeader_1x03_P2.54mm_Vertical
P2: ST-OUT; PinHeader_1x03_P2.54mm_Vertical
P3: TH-IN; PinHeader_1x03_P2.54mm_Vertical
P4: TH-OUT; PinHeader_1x03_P2.54mm_Vertical
P5: AUX-IN; PinHeader_1x03_P2.54mm_Vertical
P6: LIGHT CONTROLLER; PinHeader_1x03_P2.54mm_Vertical
P7: AUX2-IN; PinHeader_1x03_P2.54mm_Vertical
P8: AUX3-IN; PinHeader_1x03_P2.54mm_Vertical
R7: 100k; R_0603_1608Metric_Pad1.05x0.95mm_HandSolder
RN1, RN2: 1K; R_Array_Convex_4x0603
U1: MCP1703T-3302E/CB; SOT-23W
U2: LPC832M101FDH20; TSSOP-20_4.4x6.5mm_P0.65mm

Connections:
+3V3: C2.1, U1.2 (VO), U2.15 (VDD), U2.18 (VREFP)
/AUX: RN1.8 (R1.2), U2.3 (PIO0_13)
/AUX2: RN1.7 (R2.2), U2.14 (PIO0_8)
/AUX2_IN: P7.3, RN1.2 (R2.1)
/AUX3: R7.2, RN1.6 (R3.2), U2.9 (PIO0_11)
/AUX3_IN: P8.3, RN1.3 (R3.1)
/AUX_IN: P5.3, RN1.1 (R1.1)
/LIGHT: RN1.5 (R4.2), U2.4 (PIO0_12)
/LIGHT_OUT: P6.3, RN1.4 (R4.1)
/ST: RN2.6 (R3.2), U2.19 (PIO0_0)
/ST_IN: P1.3, P2.3, RN2.3 (R3.1)
/TH: RN2.5 (R4.2), U2.6 (PIO0_4)
/TH_IN: P3.3, P4.3, RN2.4 (R4.1)
GND: C1.2, C2.2, P1.1, P2.1, P3.1, P4.1, P5.1, P6.1, P7.1, P8.1, R7.1, U1.1 (GND), U2.16 (VSS), U2.17 (VREFN)
VCC: C1.1, P1.2, P2.2, P3.2, P4.2, P5.2, P6.2, P7.2, P8.2, U1.3 (VI)

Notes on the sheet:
LPC832 pin usage: PIO0_0 (19, TDO, ISP-Rx) Steering input / Rx PIO0_1 (12, TDI) (TLC5940 GSCLK) PIO0_2 (8, TMS, SWDIO) (TLC5940 SCLK) PIO0_3 (7, TCK, SWCLK) (TLC5940 XLAT) PIO0_4 (6, TRST, ISP-Tx) Throttle input / Tx PIO0_5 (5, RESET) NC PIO0_6 (was TLC5940 BLANK) PIO0_7 (was TLC5940 SIN) PIO0_8 (1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
Pull-down required because PIO0_11 is open drain!
We are using PIO0_8 for AUX2. Note that on the 5ch-PP-S PIO0_6 is used so that in the future it is possible to make a 9-output Mk4S with 5-channel input. When switching hardware is detected (PIO0_14 is GND) then the software will use PIO0_6 for AUX2, otherwise PIO0_8 In our this cae PIO0_14 must th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



Board: 2 copper layers, 17.0 x 24.0 mm, 15 parts (8 on the bottom side), 15 nets.

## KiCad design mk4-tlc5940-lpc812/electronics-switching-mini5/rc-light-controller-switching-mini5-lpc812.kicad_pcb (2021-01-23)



Board: 2 copper layers, 21.0 x 24.0 mm, 21 parts (9 on the bottom side), 23 nets.

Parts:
C1: 1u/16V; C_0805_2012Metric
C2: 47u/6V3; C_0805_2012Metric
C3: 100n; C_0603_1608Metric
J1, J2, J4, J5, J6, J7, J8, J9: Conn_01x03; PinHeader_1x03_P2.54mm_Vertical_nosilk
J3: Pinheader straight 1x08; PinHeader_1x08_P2.54mm_Vertical_nosilk
R1: 100k; R_0603_1608Metric
RN1, RN2: 1k; R_Array_Convex_4x0603
T1, T2, T3, T4: PMV30UN; SOT-23
U1: LPC812M101JDH20; TSSOP-20_4.4x6.5mm_P0.65mm
U2: MCP1703A-3302_SOT23; SOT-23W

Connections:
+3V3: C2.1, C3.1, U1.15, U2.2
/AUX: RN2.4, U1.2
/AUX2: RN2.2, U1.18
/AUX2-in: J7.3, RN2.7
/AUX3: R1.1, RN2.1, U1.8
/AUX3-in: J8.3, RN2.8
/AUX-in: J6.3, RN2.5
/OUT0: T3.1, U1.1
/OUT1: T2.1, U1.6
/OUT2: T1.1, U1.7
/OUT3: T4.1, U1.10
/OUT-ISP: RN2.3, U1.3
/OUT-ISP-in: J9.3, RN2.6
/ST-RX: RN1.4, U1.19
/ST-Rx-in: J1.3, J2.3, RN1.5
/TH-TX: RN1.3, U1.5
/TH-Tx-in: J4.3, J5.3, RN1.6
/VIN: C1.1, J1.2, J2.2, J3.2, J3.4, J3.6, J3.8, J4.2, J5.2, J6.2, J7.2, J8.2, J9.2, U2.3
GND: C1.2, C2.2, C3.2, J1.1, J2.1, J4.1, J5.1, J6.1, J7.1, J8.1, J9.1, R1.2, T1.2, T2.2, T3.2, T4.2, U1.16, U1.20, U2.1
unnamed: J3.1, T4.3
unnamed: J3.3, T1.3
unnamed: J3.5, T2.3
unnamed: J3.7, T3.3

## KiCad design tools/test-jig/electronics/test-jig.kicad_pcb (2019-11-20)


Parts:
D1: LED_POWER; LED_1206_3216Metric_Pad1.42x1.75mm_HandSolder
D2: 0; LED_1206_3216Metric_Pad1.42x1.75mm_HandSolder
D3: 1; LED_1206_3216Metric_Pad1.42x1.75mm_HandSolder
D4: 2; LED_1206_3216Metric_Pad1.42x1.75mm_HandSolder
D5: 3; LED_1206_3216Metric_Pad1.42x1.75mm_HandSolder
D6: 4; LED_1206_3216Metric_Pad1.42x1.75mm_HandSolder
D7: 5; LED_1206_3216Metric_Pad1.42x1.75mm_HandSolder
D8: 6; LED_1206_3216Metric_Pad1.42x1.75mm_HandSolder
D9: 7; LED_1206_3216Metric_Pad1.42x1.75mm_HandSolder
D10: 8; LED_1206_3216Metric_Pad1.42x1.75mm_HandSolder
D11: 9; LED_1206_3216Metric_Pad1.42x1.75mm_HandSolder
D12: 10; LED_1206_3216Metric_Pad1.42x1.75mm_HandSolder
D13: 11; LED_1206_3216Metric_Pad1.42x1.75mm_HandSolder
D14: 12; LED_1206_3216Metric_Pad1.42x1.75mm_HandSolder
D15: 13; LED_1206_3216Metric_Pad1.42x1.75mm_HandSolder
D16: 14; LED_1206_3216Metric_Pad1.42x1.75mm_HandSolder
D17: 15; LED_1206_3216Metric_Pad1.42x1.75mm_HandSolder
D18: 15S; LED_1206_3216Metric_Pad1.42x1.75mm_HandSolder
H1, H2, H3, H4, H5, H6: MountingHole; MountingHole_3.2mm_M3_ISO7380
H7, H8: MountingHole; MountingHole_2.2mm_M2_ISO7380
J1: POWER; PinHeader_1x03_P2.54mm_Vertical
J2: USB_B_Micro; PinHeader_1x05_P2.54mm_Horizontal
J3: RXe_AUX3; PinHeader_1x03_P2.54mm_Vertical
J4: RXe_AUX2; PinHeader_1x03_P2.54mm_Vertical
J5: RXe_AUX; PinHeader_1x03_P2.54mm_Vertical
J6: RXe_TH; PinHeader_1x03_P2.54mm_Vertical
J7: RXe_ST; PinHeader_1x03_P2.54mm_Vertical
J8: RX8CH_S_PLUS; PinSocket_1x03_P2.54mm_Vertical
J9: RX8CH_S; PinSocket_1x07_P2.54mm_Vertical
J10: PP3CH_GND_PLUS_S; PinSocket_1x03_P2.54mm_Vertical
J11: PP3CH_S; PinSocket_1x05_P2.54mm_Vertical
J12: PP8CH_ST1; PinSocket_1x03_P2.54mm_Vertical
J13: PP8CH_ST2; PinSocket_1x03_P2.54mm_Vertical
J14: PP8CH_TH1; PinSocket_1x03_P2.54mm_Vertical
J15: PP8CH_TH2; PinSocket_1x03_P2.54mm_Vertical
J16: PP8CH_AUX; PinSocket_1x03_P2.54mm_Vertical
J17: PP8CH_AUX2; PinSocket_1x03_P2.54mm_Vertical
J18: PP8CH_AUX3; PinSocket_1x03_P2.54mm_Vertical
J19: PP8CH_Light; PinSocket_1x03_P2.54mm_Vertical
J20: TP_PLUS; PinHeader_1x02_P2.54mm_Vertical
J21: TP_GND; PinHeader_1x02_P2.54mm_Vertical
J22: TP_ST; PinHeader_1x02_P2.54mm_Vertical
J23: TP_TH; PinHeader_1x02_P2.54mm_Vertical
J24: TP_AUX; PinHeader_1x02_P2.54mm_Vertical
J25: TP_AUX2; PinHeader_1x02_P2.54mm_Vertical
J26: TP_AUX3; PinHeader_1x02_P2.54mm_Vertical
J27: TP_Light; PinHeader_1x02_P2.54mm_Vertical
J28: TP_OUT_ISP; PinHeader_1x03_P2.54mm_Vertical
J29: UART_PP; PinSocket_1x06_P2.54mm_Horizontal
J30: UART_LC; PinSocket_1x06_P2.54mm_Horizontal
J31: LC_PP; PinHeader_1x06_P2.54mm_Vertical
J32: LC_SERVO; PinHeader_1x06_P2.54mm_Vertical
J33: LED_PLUS; Pogo_pin_Drill1mm
J34: OUT0; Pogo_pin_Drill1mm
J35: OUT1; Pogo_pin_Drill1mm
J36: OUT2; Pogo_pin_Drill1mm
J37: OUT3; Pogo_pin_Drill1mm
J38: OUT4; Pogo_pin_Drill1mm
J39: OUT5; Pogo_pin_Drill1mm
J40: OUT6; Pogo_pin_Drill1mm
J41: OUT7; Pogo_pin_Drill1mm
J42: OUT8; Pogo_pin_Drill1mm
J43: OUT9; Pogo_pin_Drill1mm
J44: OUT10; Pogo_pin_Drill1mm
J45: OUT11; Pogo_pin_Drill1mm
J46: OUT12; Pogo_pin_Drill1mm
J47: OUT13; Pogo_pin_Drill1mm
J48: OUT14; Pogo_pin_Drill1mm
J49: OUT15; Pogo_pin_Drill1mm
J50: OUT15S; Pogo_pin_Drill1mm
R1: 680; R_0805_2012Metric_Pad1.15x1.40mm_HandSolder
R2: 220; R_0805_2012Metric_Pad1.15x1.40mm_HandSolder
SW1: On/Off; PinSocket_2x03_P2.54mm_Vertical
SW2: SW_AUX; SW_PUSH_6mm_H5mm

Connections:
/AUX: J5.3, J9.2, J11.5, J16.3, J24.1, J24.2, J32.5
/AUX2: J4.3, J9.3, J17.3, J25.1, J25.2
/AUX3: J3.3, J9.4, J18.3, J26.1, J26.2
/Light: J10.3, J19.3, J27.1, J27.2, J29.5, J30.4, J31.3
/OUT_ISP: J28.3, J31.6, J32.6
/ST: J7.3, J8.3, J11.1, J11.2, J12.3, J13.3, J22.1, J22.2, J32.3
/TH: J6.3, J9.1, J11.3, J11.4, J14.3, J15.3, J23.1, J23.2, J32.4
/TX: J30.5, J31.4
GND: J1.1, J2.5 (GND), J3.1, J4.1, J5.1, J6.1, J7.1, J8.1, J10.1, J12.1, J13.1, J14.1, J15.1, J16.1, J17.1, J18.1, J19.1, J21.1, J21.2, J28.1, J29.1, J29.2, J30.1, J30.2, J31.1, J32.1, R1.2, SW2.1
unnamed: D1.1 (K), R1.1
unnamed: D2.1 (K), J34.1
unnamed: D3.1 (K), J35.1
unnamed: D4.1 (K), J36.1
unnamed: D5.1 (K), J37.1
unnamed: D6.1 (K), J38.1
unnamed: D7.1 (K), J39.1
unnamed: D8.1 (K), J40.1
unnamed: D9.1 (K), J41.1
unnamed: D10.1 (K), J42.1
unnamed: D2.2 (A), D3.2 (A), D4.2 (A), D5.2 (A), D6.2 (A), D7.2 (A), D8.2 (A), D9.2 (A), D10.2 (A), D11.2 (A), D12.2 (A), D13.2 (A), D14.2 (A), D15.2 (A), D16.2 (A), D17.2 (A), J33.1, R2.1
unnamed: D11.1 (K), J43.1
unnamed: D12.1 (K), J44.1
unnamed: D13.1 (K), J45.1
unnamed: D14.1 (K), J46.1
unnamed: D15.1 (K), J47.1
unnamed: D16.1 (K), J48.1
unnamed: D17.1 (K), J49.1
unnamed: D18.1 (K), J50.1
unnamed: D18.2 (A), R2.2
unnamed: J1.2, J2.1 (VBUS), SW1.1 (A)
unnamed: J31.5, SW2.2
VCC: D1.2 (A), J3.2, J4.2, J5.2, J6.2, J7.2, J8.2, J10.2, J12.2, J13.2, J14.2, J15.2, J16.2, J17.2, J18.2, J19.2, J20.1, J20.2, J28.2, J31.2, J32.2, SW1.2 (B)

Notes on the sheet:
Individual pin headers for external receiver
8ch receiver socket
Supply
Pre-processor 3ch socket
Pre-processor 8ch socket
Light Controller
USB-to-Serial
Test point pin headers
Light Controller output
Slave/Servo output


Board: 2 copper layers, 100.0 x 100.0 mm, 80 parts (1 on the bottom side), 32 nets.

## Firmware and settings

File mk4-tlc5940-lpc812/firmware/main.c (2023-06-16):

/******************************************************************************

    Application entry point.

    Contains the main loop and the hardware initialization.

******************************************************************************/
#include <stdio.h>
#include <stdbool.h>

#include <hal.h>
#include <globals.h>
#include <printf.h>


GLOBAL_FLAGS_T global_flags;

CHANNEL_T channel[NUMBER_OF_CHANNELS] = {
    {   // STEERING
        .normalized = 0,
        .absolute = 0,
        .reversed = false,
        .auto_endpoint = true,
        .endpoint = {
            .left = 1250,
            .centre = 1500,
            .right = 1750,
        }
    },
    {   // THROTTLE
        .normalized = 0,
        .absolute = 0,
        .reversed = false,
        .auto_endpoint = true,
        .endpoint = {
            .left = 1250,
            .centre = 1500,
            .right = 1750,
        }
    },
    {   // AUX
        .normalized = 0,
        .absolute = 0,
        .reversed = false,
        .auto_endpoint = false,
        .endpoint = {
            .left = 1000,
            .centre = 1500,
            .right = 2000,
        }
    },
    {   // AUX2
        .normalized = 0,
        .absolute = 0,
        .reversed = false,
        .auto_endpoint = false,
        .endpoint = {
            .left = 1000,
            .centre = 1500,
            .right = 2000,
        }
    },
    {   // AUX3
        .normalized = 0,
        .absolute = 0,
        .reversed = false,
        .auto_endpoint = false,
        .endpoint = {
            .left = 1000,
            .centre = 1500,
            .right = 2000,
        }
    },
    {   // AUX4
        .normalized = 0,
        .absolute = 0,
        .reversed = false,
        .auto_endpoint = false,
        .endpoint = {
            .left = 1000,
            .centre = 1500,
            .right = 2000,
        }
    },
    {   // AUX5
        .normalized = 0,
        .absolute = 0,
        .reversed = false,
        .auto_endpoint = false,
        .endpoint = {
            .left = 1000,
            .centre = 1500,
            .right = 2000,
        }
    },
    {   // AUX6
        .normalized = 0,
        .absolute = 0,
        .reversed = false,
        .auto_endpoint = false,
        .endpoint = {
            .left = 1000,
            .centre = 1500,
            .right = 2000,
        }
    }

};

static uint32_t next_tick;


// ****************************************************************************
static void service_systick(void)
{
    uint32_t now = milliseconds;

    ++entropy;

    global_flags.systick = 0;
    if (now > next_tick) {
        next_tick += __SYSTICK_IN_MS;
        global_flags.systick = 1;
    }
}


// ****************************************************************************
static void check_no_signal(void)
{
    static uint16_t no_signal_timeout = 0;

    if (config.mode == STAND_ALONE) {
        global_flags.no_signal = false;
        return;
    }

    if (global_flags.new_channel_data) {
        global_flags.no_signal = false;
        no_signal_timeout = config.no_signal_timeout;
    }

    if (global_flags.systick) {
        --no_signal_timeout;
        if (no_signal_timeout == 0) {
            global_flags.no_signal = true;
        }
    }
}


// ****************************************************************************
static void output_channel_diagnostics(void)
{
    if (global_flags.new_channel_data) {
        static int16_t st = 999;
        static int16_t th = 999;

        if (st != channel[ST].normalized  ||
            th != channel[TH].normalized) {

            st = channel[ST].normalized;
            th = channel[TH].normalized;

            printf("ST=%d TH=%d\n", st, th);
        }
    }
}


// ****************************************************************************
/*
Send AUX configuration values to allow the preprocessor-simulator
to adjust its functionality automatically -- which is pretty
important as otherwise it is easy to mess up with all the
different AUX switch types

We send the configuration once after a no_signal event, and after
power on. In practice this means that the preprocessor-simulator
always sees the configuration information immediately after it
is talking to the light controller.

We send the config when we received anything from the UART
 */
static void output_config(void)
{
    static bool send_config = true;
    static bool signal_seen = false;
    // Default: 3ch-PP protocol
    uint8_t protocol = 0;

    // Set send_config only when once, until we seen a valid servo signal
    // again. Otherwise we send a CONFIG way too often
    if (global_flags.no_signal) {
        if (signal_seen) {
            signal_seen = false;
            send_config = true;
        }
    }
    else {
        signal_seen = true;
    }

    if (!send_config) {
        return;
    }

    if (!HAL_getchar_pending()) {
        return;
    }

    send_config = false;

    if (config.mode == MASTER_WITH_IBUS_READER  ||  config.mode == MASTER_WITH_SBUS_READER) {
        // 2..11 is for i-Bus or S.Bus,
        // aux_channel_offset can be retrieved by subtracting 2 from the
        // mode value in the Configurator.
        //
        // There is no way to differentiate between S.Bus and i-Bus, because
        // the UART setup is different:
        //   i-Bus: 115200 8N1
        //   S.Bus: 100000 8E2
        protocol = 2 + config.aux_channel_offset;
    }
    else if (config.flags2.multi_aux) {
        // 1: 5ch-PP protocol
        protocol = 1;
    }

    printf("CONFIG %d %d %d %d %d %d %d %d %d\n",
        protocol,
        config.flags.ch3_is_momentary, config.flags.ch3_is_two_button,
        config.aux_type, config.aux_function,
        config.aux2_type, config.aux2_function,
        config.aux3_type, config.aux3_function);
}


// ****************************************************************************
int main(void)
{
    uint8_t rx_pin = HAL_GPIO_NO_PIN;
    uint8_t tx_pin = HAL_GPIO_NO_PIN;

    // When GPIO0_14 is low we are dealing with a Mk4S (9 switched outputs)
    global_flags.switched_outputs = !HAL_gpio_read(HAL_GPIO_HARDWARE_CONFIG);

    if (config.mode != STAND_ALONE) {
        global_flags.no_signal = true;
        global_flags.initializing = true;
    }

    HAL_hardware_init();
    init_gpio_lights();
    load_persistent_storage();

    // Initialize the UART on the configured GPIO pins, which are adjusted
    // by the configurator depending on the user-supplied configuration.
    if (config.flags2.uart_rx_on_st) {
        rx_pin = HAL_GPIO_ST.pin;
    }
    if (config.flags2.uart_tx_on_out) {
        tx_pin = HAL_GPIO_OUT.pin;
    }
    if (config.flags2.uart_tx_on_th) {
        tx_pin = HAL_GPIO_TH.pin;
    }

    // NOTE: don't invert RX input when in SLAVE mode!
    HAL_uart_init(config.baudrate, rx_pin, tx_pin, config.mode != SLAVE);

    // The printf function is only used for diagnostics, so we default to
    // STDOUT_DEBUG for the file pointer!
    // If the diagnostics need to be disabled, we use NULL as file pointer
    // (which we check for in HAL_putc)
    init_printf(config.flags2.uart_diagnostics_enabled ? STDOUT_DEBUG : NULL, HAL_putc);

    // Wait for 100ms to have the supply settle down before initializing the
    // rest of the system. This is especially important for the TLC5940,
    // which misbehaves (certain LEDs don't work) when being addressed before
    // power is stable.
    //
    // It is also important in terms of servo reader function, because some
    // RC electronics like the Hobbywing Quicrun 1080 are outputing serial
    // data after startup, which interferes with the initialization procedure
    while (milliseconds < 100);

    init_servo_reader();
    init_servo_output();

    init_lights();
    HAL_hardware_init_final();

    next_tick = milliseconds + __SYSTICK_IN_MS;

    printf("\n\n******\nLight controller v%d sw=%d LPC%x\n", config.firmware_version, global_flags.switched_outputs, mcu_type);

    while (1) {
        global_flags.gear_changed = 0;
        if (global_flags.gear_change_requested) {
            global_flags.gear_change_requested = 0;
            global_flags.gear_changed = 1;
        }

        service_systick();

        global_flags.new_channel_data = false;

        output_config();
        read_all_servo_channels();
#ifdef ENABLE_PREPROCESSOR_READER
        read_preprocessor();
#endif

        process_aux();
        process_drive_mode();
        process_indicators();
        process_channel_reversing_setup();
        check_no_signal();
        process_shelf_queen_mode();

        process_servo_output();
        // process_winch();
        process_lights();
        output_preprocessor();
        output_channel_diagnostics();

        HAL_service();
    }
}

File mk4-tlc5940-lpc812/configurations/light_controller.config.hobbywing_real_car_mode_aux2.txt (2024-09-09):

{
  "config": {
    "firmware_version": 57,
    "mode": 1,
    "esc_mode": 3,
    "slave_output": false,
    "preprocessor_output": false,
    "winch_output": false,
    "steering_wheel_servo_output": true,
    "gearbox_servo_output": false,
    "ch3_is_local_switch": false,
    "ch3_is_momentary": false,
    "auto_brake_lights_forward_enabled": true,
    "auto_brake_lights_reverse_enabled": true,
    "ch3_is_two_button": false,
    "reverse_st": false,
    "reverse_th": false,
    "reverse_aux": false,
    "reverse_aux2": false,
    "reverse_aux3": false,
    "auto_brake_counter_value_forward_min": 25,
    "auto_brake_counter_value_forward_max": 125,
    "auto_brake_counter_value_reverse_min": 25,
    "auto_brake_counter_value_reverse_max": 125,
    "auto_reverse_counter_value_min": 40,
    "auto_reverse_counter_value_max": 100,
    "brake_disarm_counter_value": 50,
    "blink_counter_value": 17,
    "indicator_idle_time_value": 25,
    "indicator_off_timeout_value": 100,
    "centre_threshold_low": 8,
    "centre_threshold_high": 12,
    "blink_threshold": 30,
    "light_switch_positions": 5,
    "initial_light_switch_position": 0,
    "initial_endpoint_delta": 250,
    "ch3_multi_click_timeout": 25,
    "baudrate": 115200,
    "no_signal_timeout": 25,
    "number_of_gears": 2,
    "gearbox_servo_active_time": 50,
    "gearbox_servo_idle_time": 450,
    "servo_pulse_min": 600,
    "servo_pulse_max": 2500,
    "startup_time": 100,
    "multi_aux": true,
    "shelf_queen_mode": true,
    "us_style_combined_lights": true,
    "gearbox_light_program_control": false,
    "light_program_servo_output": false,
    "indicators_while_driving": false,
    "require_extra_click": false,
    "prefer_all_lights_off": false,
    "invert_out15s": false,
    "assign_uart_to_out": false,
    "blink_counter_value_dark": 17,
    "aux_type": 0,
    "aux_function": 1,
    "aux_type_advanced": 0,
    "aux_function_advanced": 1,
    "aux2_type": 0,
    "aux2_function": 0,
    "aux3_type": 0,
    "aux3_function": 0,
    "aux_centre_threshold_low": -10,
    "aux_centre_threshold_high": 10,
    "aux_left_centre_threshold_low": -40,
    "aux_left_centre_threshold_high": -30,
    "aux_centre_right_threshold_low": 30,
    "aux_centre_right_threshold_high": 40,
    "diagnostics_brightness": 255,
    "channel_offset": 3,
    "enable_aux_3ch_advanced": false,
    "light_switch_hysteresis": 10,
    "light_switch_centers": [
      -80,
      -40,
      0,
      40,
      80,
      0,
      0,
      0,
      0
    ]
  },
  "local_leds": {
    "0": {
      "max_change_per_systick": 0,
      "reduction_percent": 0,
      "weak_light_switch_position0": false,
      "weak_light_switch_position1": false,
      "weak_light_switch_position2": false,
      "weak_light_switch_position3": false,
      "weak_light_switch_position4": false,
      "weak_light_switch_position5": false,
      "weak_light_switch_position6": false,
      "weak_light_switch_position7": false,
      "weak_light_switch_position8": false,
      "weak_tail_light": false,
      "weak_brake_light": false,
      "weak_reversing_light": false,
      "weak_indicator_left": false,
      "weak_indicator_right": false,
      "always_on": 0,
      "light_switch_position0": 0,
      "light_switch_position1": 255,
      "light_switch_position2": 255,
      "light_switch_position3": 255,
      "light_switch_position4": 255,
      "light_switch_position5": 0,
      "light_switch_position6": 0,
      "light_switch_position7": 0,
      "light_switch_position8": 0,
      "tail_light": 0,
      "brake_light": 0,
      "reversing_light": 0,
      "indicator_left": 0,
      "indicator_right": 0,
      "diagnostics": 0,
      "name": ""
    },
    "1": {
      "max_change_per_systick": 0,
      "reduction_percent": 0,
      "weak_light_switch_position0": false,
      "weak_light_switch_position1": false,
      "weak_light_switch_position2": false,
      "weak_light_switch_position3": false,
      "weak_light_switch_position4": false,
      "weak_light_switch_position5": false,
      "weak_light_switch_position6": false,
      "weak_light_switch_position7": false,
      "weak_light_switch_position8": false,
      "weak_tail_light": false,
      "weak_brake_light": false,
      "weak_reversing_light": false,
      "weak_indicator_left": false,
      "weak_indicator_right": false,
      "always_on": 0,
      "light_switch_position0": 0,
      "light_switch_position1": 255,
      "light_switch_position2": 255,
      "light_switch_position3": 255,
      "light_switch_position4": 255,
      "light_switch_position5": 0,
      "light_switch_position6": 0,
      "light_switch_position7": 0,
      "light_switch_position8": 0,
      "tail_light": 0,
      "brake_light": 0,
      "reversing_light": 0,
      "indicator_left": 0,
      "indicator_right": 0,
      "diagnostics": 0,
      "name": ""
    },
    "2": {
      "max_change_per_systick": 0,
      "reduction_percent": 0,
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

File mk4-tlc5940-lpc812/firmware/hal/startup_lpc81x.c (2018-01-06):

#include <LPC8xx.h>


// The entropy variable is a true random number generated from the random RAM
// contents after power-up.
uint32_t entropy;


// These are all defined by the linker via the lpc81x.ld linker script.
extern unsigned int _text;
extern unsigned int _etext;
extern unsigned int _data;
extern unsigned int _data_load;
extern unsigned int _edata;
extern unsigned int _bss;
extern unsigned int _ebss;
extern unsigned int _ram;
extern unsigned int _eram;
extern void _stacktop(void);


// Forward declaration of the exception handlers.
// When the application defines a handler with the same name it will
// take precedence over these "weak" definitions
#define ALIAS(f) __attribute__ ((weak, alias (#f)))
void Reset_handler(void);
void NMI_handler(void) ALIAS(default_irq_handler);
void HardFault_handler(void) ALIAS(default_irq_handler);
void SVCall_handler(void) ALIAS(default_irq_handler);
void PendSV_handler(void) ALIAS(default_irq_handler);
void SysTick_handler(void) ALIAS(default_irq_handler);
void SPI0_irq_handler(void) ALIAS(default_irq_handler);
void SPI1_irq_handler(void) ALIAS(default_irq_handler);
void UART0_irq_handler(void) ALIAS(default_irq_handler);
void UART1_irq_handler(void) ALIAS(default_irq_handler);
void UART2_irq_handler(void) ALIAS(default_irq_handler);
void I2C_irq_handler(void) ALIAS(default_irq_handler);
void SCT_irq_handler(void) ALIAS(default_irq_handler);
void MRT_irq_handler(void) ALIAS(default_irq_handler);
void CMP_irq_handler(void) ALIAS(default_irq_handler);
void WDT_irq_handler(void) ALIAS(default_irq_handler);
void BOD_irq_handler(void) ALIAS(default_irq_handler);
void WKT_irq_handler(void) ALIAS(default_irq_handler);
void PININT0_irq_handler(void) ALIAS(default_irq_handler);
void PININT1_irq_handler(void) ALIAS(default_irq_handler);
void PININT2_irq_handler(void) ALIAS(default_irq_handler);
void PININT3_irq_handler(void) ALIAS(default_irq_handler);
void PININT4_irq_handler(void) ALIAS(default_irq_handler);
void PININT5_irq_handler(void) ALIAS(default_irq_handler);
void PININT6_irq_handler(void) ALIAS(default_irq_handler);
void PININT7_irq_handler(void) ALIAS(default_irq_handler);

extern int main(void);


// ****************************************************************************
// Interrupt vectors
__attribute__ ((section(".isr_vectors")))
void (* const vectors[])(void) = {
    &_stacktop,             // The initial stack pointer
    Reset_handler,          // Reset handler
    NMI_handler,            // NMI handler
    HardFault_handler,      // Hard fault handler
    0,                      // Reserved
    0,                      // Reserved
    0,                      // Reserved
    0,                      // Reserved
    0,                      // Reserved
    0,                      // Reserved
    0,                      // Reserved
    SVCall_handler,         // SVCall handler
    0,                      // Reserved
    0,                      // Reserved
    PendSV_handler,         // PendSV handler
    SysTick_handler,        // SysTick handler

    // LPC81x specific vectors
    SPI0_irq_handler,       // SPI0
    SPI1_irq_handler,       // SPI1
    0,                      // Reserved
    UART0_irq_handler,      // UART0
    UART1_irq_handler,      // UART1
    UART2_irq_handler,      // UART2
    0,                      // Reserved
    0,                      // Reserved
    I2C_irq_handler,        // I2C
    SCT_irq_handler,        // SCTimer
    MRT_irq_handler,        // Multi-rate timer
    CMP_irq_handler,        // Comparator
    WDT_irq_handler,        // Watchdog
    BOD_irq_handler,        // Brown Out Detect
    0,                      // Reserved
    WKT_irq_handler,        // Wakeup timer
    0,                      // Reserved
    0,                      // Reserved
    0,                      // Reserved
    0,                      // Reserved
    0,                      // Reserved
    0,                      // Reserved
    0,                      // Reserved
    0,                      // Reserved
    PININT0_irq_handler,    // PIO INT0
    PININT1_irq_handler,    // PIO INT1
    PININT2_irq_handler,    // PIO INT2
    PININT3_irq_handler,    // PIO INT3
    PININT4_irq_handler,    // PIO INT4
    PININT5_irq_handler,    // PIO INT5
    PININT6_irq_handler,    // PIO INT6
    PININT7_irq_handler,    // PIO INT7
};

static void default_irq_handler(void)
{
    while (1);
}


// ****************************************************************************
// Simple gcc-compatible C runtime initialization
//
// This works in conjunction with lpc81x.ld
// ****************************************************************************
void Reset_handler(void)
{
    unsigned int *source;
    unsigned int *destination;
    unsigned int *end;
    uint32_t temp_entropy;

    // Calculate the entropy random value from the RAM contents after reset
    // Only process RAM locations unitl we reach the stack.
    temp_entropy = 0x0817;  // Just an arbitrary initialization value
    source = &_ram;
    end = (unsigned int *)__get_MSP();
    while (source < end) {
        temp_entropy ^= *(source++);
    }

#ifndef NODEBUG
    // Place stack canaries into RAM, but only up to the current stack pointer
    destination = &_ram;
    end = (unsigned int *)__get_MSP();
    while (destination < end) {
        *(destination++) = 0xcafebabe;
    }
#endif

    // Copy initialization values from Flash to RAM
    source = &_data_load;
    destination = &_data;
    end = &_edata;
    while (destination < end) {
        *(destination++) = *(source++);
    }

    // Zero out uninitialized RAM
    destination = &_bss;
    end = &_ebss;
    while (destination < end) {
        *(destination++) = 0;
    }

    // Copy the calculated random value into the final destination RAM
    // (which we just erased above ...)
    entropy = temp_entropy;

    main();
    while (1);  // Hang if main() returns
}

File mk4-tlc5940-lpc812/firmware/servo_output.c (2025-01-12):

/******************************************************************************
******************************************************************************/
#include <stdint.h>
#include <stdbool.h>

#include <hal.h>
#include <globals.h>
#include <printf.h>


static bool next = false;
static int16_t servo_position = 0;
static uint16_t servo_pulse;

static uint16_t gearbox_servo_counter;
static bool gearbox_servo_active;

static SERVO_ENDPOINTS_T servo_setup_endpoint;
SERVO_ENDPOINTS_T servo_output_endpoint;


// ****************************************************************************
static void activate_gearbox_servo(void)
{
    gearbox_servo_active = true;
    gearbox_servo_counter = config.gearbox_servo_active_time;

    HAL_servo_output_enable();
}


// ****************************************************************************
void init_servo_output(void) {
    uint8_t pin = HAL_GPIO_NO_PIN;

    if (!config.flags2.servo_output_enabled) {
        return;
    }

    servo_pulse = servo_output_endpoint.centre;

    // Initialize the servo output on the configured pin
    if (config.flags2.servo_on_th) {
        pin = HAL_GPIO_TH.pin;
    }
    if (config.flags2.servo_on_out) {
        pin = HAL_GPIO_OUT.pin;
    }
    HAL_servo_output_init(pin);

    if (config.flags.gearbox_servo_output) {
        global_flags.gear = GEAR_1;
        activate_gearbox_servo();
    }
}


// ****************************************************************************
void set_servo_pulse(uint16_t value)
{
    servo_pulse = value;
}

// ****************************************************************************
void set_servo_position(int16_t value)
{
    // Ensure the servo position is in the range of -100 .. 0 ,, +100
    value = MAX(value, -100);
    value = MIN(value, 100);

    servo_position = value;
}

// ****************************************************************************
int8_t get_servo_position(void)
{
    return servo_position;
}

// ****************************************************************************
void set_gear(uint8_t new_gear) {
    // Ensure that new_gear is in the valid range
    if (new_gear < 1) {
        new_gear = 1;
    }
    if (new_gear > config.number_of_gears) {
        new_gear = config.number_of_gears;
    }

    if (global_flags.gear == new_gear) {
        return;
    }

    global_flags.gear = new_gear;
    global_flags.gear_change_requested = true;
    printf("gear %d\n", global_flags.gear);
    activate_gearbox_servo();
}

// ****************************************************************************
void gearbox_action(uint8_t ch3_clicks)
{
    if (!config.flags.gearbox_servo_output) {
        return;
    }

    // 2-speed gearbox: one click is Gear 1; two clicks is Gear 2
    if (config.number_of_gears == 2) {
        if (ch3_clicks == 1) {
            set_gear(GEAR_1);
        }
        else {
            set_gear(GEAR_2);
        }
    }

    // 3-speed gearbox: one click switches gear up, two clicks gear down
    else {
        if (ch3_clicks == 1) {
            if (global_flags.gear == GEAR_1) {
                set_gear(GEAR_2);
            }
            else {
                set_gear(GEAR_3);
            }
        }
        else {
            if (global_flags.gear == GEAR_3) {
                set_gear(GEAR_2);
            }
            else {
                set_gear(GEAR_1);
            }
        }
    }
}


// ****************************************************************************
static void diag(const char *s)
{
    printf("servo setup %s\n", s);
}


// ****************************************************************************
void servo_output_setup_action(uint8_t ch3_clicks)
{
    if (!config.flags2.servo_output_enabled) {
        return;
    }

    if (global_flags.servo_output_setup == SERVO_OUTPUT_SETUP_OFF) {
        servo_output_endpoint.left = 900;
        servo_output_endpoint.centre = 1500;
        servo_output_endpoint.right = 2100;
        global_flags.servo_output_setup = SERVO_OUTPUT_SETUP_LEFT;
        diag("left");
    }
    else {
        if (ch3_clicks == 1) {
            // 1 click: next setup step
            next = true;
            //global_flags.steering_wheel_servo_setup_mode = STEERING_WHEEL_SERVO_SETUP_MODE_NEXT;
        }
        else {
            // More than 1 click: cancel setup
            global_flags.servo_output_setup = SERVO_OUTPUT_SETUP_OFF;
            load_persistent_storage();
            diag("cancelled");
        }
    }
}


/******************************************************************************

    This function calculates:

          (right - centre) * abs(steering)
          -------------------------------- + centre
                    100

    To ease calculation we first do right - centre, then calculate its absolute
    value but store the sign. After multiplication and division using the
    absolute value we re-apply the sign, then add centre.

    Note: this function is needed by Process_servo_setup, so it can't be
    removed e.g. if only a gearbox servo is used.

******************************************************************************/
static void calculate_servo_pulse(int16_t value)
{
    if (value < 0) {
        servo_pulse = servo_output_endpoint.centre -
            (((servo_output_endpoint.centre - servo_output_endpoint.left) *
                (-value)) / 100);
    }
    else {
        servo_pulse = servo_output_endpoint.centre +
            (((servo_output_endpoint.right - servo_output_endpoint.centre) *
                value) / 100);
    }
}
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

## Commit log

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2014-12-05 Make middle layer a single outline, no internal milling
    Add silk screen identification too
    [case-middle.brd]
2014-12-05 Place GPIO definitions in global.h
    Still missing: GPIO bit number definitions for io-direction
    [globals.h, lights.c, main.c]
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2014-12-06 Fix gamma table value
    [config.c]
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2014-12-11 Fix servo reader and gearbox servo idle time
    [servo_output.c, servo_reader.c]
2014-12-11 Fix CH3 not working as we must not set its center at startup
    [servo_reader.c]
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2014-12-13 Fix CH3 initialization.
    CPPM reader is working fine!
    [servo_reader.c]
2014-12-13 Fix throttle initialization
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2015-04-17 Fix issue with light programs not working on Slave
    [config.c, lights.c]
2015-06-26 Add clear button to reset LED configuration
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2015-11-09 Fix bug "fade all leds stepside var" not working
2015-12-01 s0len0id (github): make Gerber files compatible with OSH Park
    - Both MK4 and MK2 Gerber ZIP files fixed
    - Outlines were missing.
    - CAM file for OSH Park was the original file, which did not produce
    correct results. A modified CAM file has now been added.
2016-02-28 Fix typo with default right endpoint (1450 instead 1750)
    Reported by Locke; THANKS!
    [main.c]
2016-04-04 Add Y-cable replacement prototyping board pin-out
2017-01-29 Show warning error if users try to run the configurator source code
    If parser.js is not present then we show a large error message, instructing
    the user to download the correct file.
    It happened that someone downloaded the source code from Github and tried
    to load configurator.html, without having installed gulp or built the Light
    program assembler. Then simply nothing happens.
    To fix this we renamed configurator.html to source.html.
    We also upgraded gulp-inline-source and added error messages to the build
    process.
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2017-07-21 Fix silk screen, change 0603 for hand soldering
    [preprocessor.kicad_pcb, preprocessor.sch]
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2017-08-10 Add light program that blinks the output number
    Test light program that flashes the output number.
    This is helpful to understand which LED is connected to which
    output if you can't trace out
    the wireing.
    Short flashes represent a count of 1, long flashes a count of 5.
    OUT0 is always lit while the other outputs perform their flashes.
    All outputs are off for 500 ms to serve as synchronization.
    Example: long-short-short = 5+1+1 = OUT7
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2017-10-10 Add clearance between light outputs and TLC5940
    [mk5.kicad_pcb]
2017-10-10 Tweak a few traces, fix DRC issues
    [mk5.kicad_pcb]
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2017-11-17 Fix persistent storage only storing data when it is virgin
    [config.c, persistent_storage.c]
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2017-11-19 Flip case around to make it actually fit ...
    [light-controller-case.scad, light-controller-case.stl]
2017-11-19 Finalize layout with reverse-mount LED
    [mk5.kicad_pcb, mk5.sch]
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2017-11-24 Update TODO and fix XLAT pin issue
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2017-11-25 Fix issue with HAL port not working
    Temporarily disable stack check, it hangs in MASTER_MODE?
    [config.c, uart_reader.c]
2017-11-25 Fix RAM initialization and stack check
    [main.c, startup_lpc81x.c]
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2017-12-02 Add a simple box to protect the light controller in the car
    [light-controller-box.scad, light-controller-box.stl]
2017-12-05 Recycle SAMD11 to SAMD21. SAMD11 only has 16 KB Flash, too small
    [mk5.kicad_pcb, mk5.sch]
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2017-12-13 Fix LDO 3D model orientation
    [preprocessor.kicad_pcb]
2017-12-13 Activate servo during initialization only when gearbox output
    Currently when servo output is selected the servo is set to a value
    that is not desired for a short time.
    [servo_output.c]
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2017-12-13 Find common pin-out between own hardware and Arduino MKRZero
    For the SAM R21 Xplained Pro board we have to use some other
    ports and swap the SERCOMs
    [mk5.kicad_pcb, mk5.sch]
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2017-12-13 Fix KiCad name
2017-12-13 Add PA03 issue on Arduino
2017-12-13 OUT15S moved from PA03 to PA02, as PA03 has large cap on Arduino (AREF)
    [mk5.kicad_pcb, mk5.sch]
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2017-12-15 LED is separate from OUT15
    We put it on PA01, which is one of the crystal pin on Arduino.
    On Arduino the LED is on PB08, which we don't have on the
    32 pin package.
    We will have to see if we can drive two LEDs with the same software,
    especially in the boot loader
    [mk5.kicad_pcb, mk5.sch]
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2017-12-21 Add issue with ARM section in linker script
2017-12-21 Add bootloader, working!
    Missing:
    - Detect when app switched into bootloader
    - User can manually force the bootloader
    [main.c]
2017-12-21 DFU can now trigger proper reboot
    [hal_samd21.c]
2017-12-21 Fix stray .ARM.exidx section (used by libgcc)
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2017-12-22 Fix dfu-util reporting 'dfu-util: error detaching' when switching from run time mode to dfu mode
    [hal_samd21.c]
2017-12-22 Fix dfu-util reporting 'dfu-util: unable to read DFU status after completion' after flashing
    [main.c]
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2018-01-05 Revert to using different device ID for bootloader
    It seems like in Windows Chrome has an issue reconnecting
    the device, it still thinks the device is in runtime mode.
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2018-01-05 Fix DFU Windows driver
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2018-01-06 Fix once and for all loading of initialized data
    The issue is that we were using _etext to know the ROM address
    where the initialization data is stored.
    However, if there are multiple ROM sections then we always
    have to ensure to move _etext to the ROM section that is right
    before the .data section.This is very error prone.
    A better solution is to define _data_load and assigning it
    to LOADADDR(.data).
    It is surprising that almost all vendor linker scripts use
    _etext for the initialization data address. Maybe a case of
    copying, just like I did ...
    [startup_lpc81x.c]
2018-01-06 Fix servo reader for Spektrum 4210 and 4220 receivers
    Those receivers seem to output ST and TH signals at different
    frequencies. This caused "flashing" when the throttle was pulled,
    and also caused the throttle not to initialize properly when
    it was not near around 1500 us.
    The changed algorithm passes on the previously read channel instead
    of "0".
    This means that the channel with the highest frequency dictates
    how often new servo data is passed to the light controller, and
    the data of the other channels may reflect an earlier state.
    [config.c, hal_lpc81x.c, hal_samd21.c]
2018-01-09 Move TH to PA18, to free PA17 which is the LED on Arduino Zero
    [mk5.kicad_pcb, mk5.sch]
2018-01-11 Fix writing PLL calibration values stored in NVROM
    [hal_samd21.c]
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2018-01-16 Fix issue with Spektrum and Quicrun 1080 ESC
    The issue is that the serial output caused generated by the
    Quicrun ESC is interfering with the servo reader initialization.
    Simply initializing the servo reader only after 100 ms resolves
    the issue.
    [config.c, main.c]
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2018-02-17 Fix SPI port mux, TLC5940 is now working
2018-02-18 Refactor board: all signals on pin header
    Board is now larger, but all pins are exposed.
    ST and Rx pin are now combined.
    Staggered pin-header holes for SWD
    More annotations on silkscreen
    [mk5.kicad_pcb, mk5.sch]
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2018-02-18 Fix TXPO value for Tx on TH pin
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2018-02-20 Add reset pad
    [mk5.kicad_pcb, mk5.sch]
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2018-02-22 Replace series resistors with test points
    Place LED on 1mm grid
    Unify most of the LED pad via locations
    [mk5.kicad_pcb, mk5.sch]
2018-02-22 Add 100n for reset, 10k pull-up for SWDCLK
    [mk5.kicad_pcb, mk5.sch]
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2018-02-25 Fix Light output needs to transfer 6 bit words to TLC5940
    [hal_samd21.c]
2018-02-25 Fix input min configuration with pull-up
    [hal_samd21.c]
2018-02-27 Pull-up on BLANK, pull-down on OUT15s
    To avoid LEDs coming on while the MCU is in the bootloader or in
    reset
    [mk5.kicad_pcb, mk5.sch]
2018-02-27 Remove BLANK and OUT15S handling in bootloader
    Actually the hardware has to take care of this, because otherwise
    the LEDs will briefly be flashing during reset anyway.
    [hal_samd21.c, main.c]
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2018-02-28 Remove erase_mass as it bricks the chip if the bootloader is protected
    The DSU can erase the flash, but the User Row protection is still in
    place. The Blackmagic probe can no longer write the firmware due
    to the protection, but also does not check for those failures.
    After erase_mass it is necessary to remove BOOTPROT and flash row
    protection. BOOTPROT can not be modified with the standard Blackmagic
    probe, it requires a hacked firmware.
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2018-03-12 Give the test IF its own USB interface
    Since we can't have CDC (Windows 8 driver signing requirement) we
    rather use WinUSB with a vendor specific interface.
    This way one app can claim the interface, and other's can't interfere.
    [hal_samd21.c]
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2018-05-18 Fix assembler using ' instead of " for section name
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2018-05-23 Add issue with weak ground table
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2019-01-06 Fix documentation regarding steering wheel servo setup
2019-03-08 Add Rev 2 of the Mk4 PCB
    Kicad import from Eagle, then modified
    [rc-light-controller-tlc5940-lpc812.kicad_pcb, rc-light-controller-tlc5940-lpc812.sch]
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2019-04-17 Change LPC footprint
    NEED TO VERIFY IT IS THE CORRECT ONE!
    [rc-light-controller-tlc5940-lpc812.kicad_pcb, rc-light-controller-tlc5940-lpc812.sch]
2019-04-18 Fix LPC812 footprint
    [rc-light-controller-tlc5940-lpc812.kicad_pcb, rc-light-controller-tlc5940-lpc812.sch]
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2019-05-23 Fix output pin for master driving slave with preprocessor
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2019-07-12 Make Rev3 preprocessor
    Change to better footprints for resistors and LDO
    Change LDO bypass cap to 47uF polymer
    Add + symbol for polymer cap
    [preprocessor.kicad_pcb, preprocessor.sch]
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2019-08-05 Fix dark blink phase default value
    [config.c]
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2019-08-20 Implement configuration documentation and fixes via header
    [preprocessor-simulator.py]
2019-08-30 Add correct AUX button labels
    Button for Analog type sets slider to 0
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2019-08-31 Remove MK5 version
    We are not going to pursue the MK5 version, its larger
    hardware does not really make sense.
    [mk5.kicad_pcb, mk5.sch]
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2019-09-01 Fix table for ground fault not lining up
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2019-09-29 Update TODO, fix configurations
    [light_controller.config.abc-hobby-honda-civic.txt, light_controller.config.ta03fs-toyota-corolla.txt]
2019-09-29 Fix light program disassembler
    Issue with string vs integer: when running the browser
    then light programs were decoded as integer, while in Node it
    was received as string.
    This messed up leds_used when we apply parseInt(x,16) to something
    that is already an integer.
2019-09-29 Fix shelf queen mode light switch position range
2019-10-01 Config changes
    Enable servo output for default firmware image
    Change CH3 click timeout to 500 ms (300 ms default is too fast for some people)
    [config.c]
2019-10-04 Fix 5-ch master with uart reader mode load/write
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2019-10-06 Fix CH3 and 5ch preprocessor
    [config.c, servo_reader.c]
2019-10-11 Fix functionality when using Browsers Save As
    If the user is saving an offline version of the Configurator
    via the browsers Save As function, then the hydrated HTML version
    gets saved.
    We therefore need to clean the HTML before populating it from
    JavaScript.
    The issues were in the LED tables and the CodeMirror editor
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2019-11-13 Fix issue with logical or operation on leds_used
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2020-03-20 Fix sending and receiving of USB and UART data
    Loopback now works correctly!
    [hal_samd21.c]
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2020-03-21 Implement programming and reliable light controller reset
    [hal_samd21.c, main.c]
2020-03-22 Implement shorting of light controller power
    When in ISP mode, turning the power off causes the MCU to
    not reset properly. Most likely there is no brown-out detection
    and the MCU is in deep sleep. Once power is reapplied it seems
    to be in a weird state.
    This is not an issue when the light controller program is running
    as it seems to keep the MCU active, draining the power quickly.
    The solution is to put a MOSFET and a 100 Ohm resistor accross
    the supply rail and short it out when the power is off.
    This way everything works reliably.
    [hal_samd21.c]
2020-03-22 Add MOSFET to short light controller power supply
    [webusb-programmer.kicad_pcb, webusb-programmer.sch]
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2020-03-28 Fix Slave function
    When we implemented the 5-channel pre-processor apparently
    the slave function was broken on multiple levels:
    - The configurator did not set the operating mode correctly
    when saving the slave
    - The master continued outputing pre-processor information
    when the slave was active
    - The UART reader was not disabled on the slave
    [config_lights.c, uart_reader.c]
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2020-04-03 Fix device connect/disconnect
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2020-04-17 Fix TX/RX switching to GND when power is off
    [hal_samd21.c, main.c]
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2020-05-02 Focus correct buttons upon page entry
2020-06-06 Fix slave LEDs setting light_switch_positions even if SLAVE output is off
2020-06-15 Reduce FW size by reusing normalize function
    Originally we duplicated the ST/TH normalization function for
    AUX usage when we introduced the 5ch Pre-Processor, as some
    minor changes were neded for AUX.
    We have now reverted to a single normalization function that
    handles the small differences, which are related to auto-endpoint
    adjustment only being relevant for ST and TV. A flag in CHANNEL_T
    lets the function know whether auto-endpoint is applicable or not.
    [config.c, globals.h, main.c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]
2020-06-19 Make right indicator start flashing immediately
    Since quite a long time, the left indicator started to
    engage immediately, but the right indicator only after a
    short while. After several years someone found out...
    The issue was that actually the left indicator was wrong:
    BLINK_LEFT_ARMED was supposed to ensure that the steering
    wheel is held for a certain amount of time before the indicators
    engage. The check was implemented wrong for the left indicators
    but correct for the right ones.
    Since it is better anyway to have the indicators come one
    immediately we can save a bit of code and remove the BLINK_X_ARMED
    funcitons
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2020-06-21 Fix winch run-conditions for light programs
    [config.c, light_programs.c]
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2020-07-23 Change resistor array from concave to convex type.
    Convex types seem to be more common, at least on LCSC
    [rc-light-controller-pinheader-lpc812.kicad_pcb, rc-light-controller-pinheader-lpc812.sch, rc-light-controller-switching-lpc812.kicad_pcb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]
2020-07-23 Remove outdated library symbols and footprint
    Move everything to KiCAD symbols and footprints, except
    for the TLC5940 where we have a custom footprint to
    manage the solder paste.
    [rc-light-controller-pinheader-lpc812.kicad_pcb, rc-light-controller-pinheader-lpc812.sch]
2020-07-24 Remove unused legacy library symbols and footprints
    All symbols and footprints have now been switched to KiCAD
    versions.
    [rc-light-controller-switching-lpc812.kicad_pcb, rc-light-controller-switching-lpc812.sch]
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2020-07-24 Add datasheets and fix part values
    [rc-light-controller-pinheader-lpc812.sch, rc-light-controller-switching-lpc812.sch]
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2020-07-25 Remove all PCB revisions
    We can always get them back from Git anyway
    [case-middle.brd, case-outline.dxf, case-top.brd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]
2020-07-26 Swap VIN and LED+, add version detection
    [rc-light-controller-pinheader-lpc812.kicad_pcb, rc-light-controller-pinheader-lpc812.sch, rc-light-controller-switching-lpc812.kicad_pcb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]
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2020-07-26 Change solder paste clearance to 5%
    [rc-light-controller-pinheader-lpc812.kicad_pcb, rc-light-controller-switching-lpc812.kicad_pcb]
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2020-08-13 Fix GPIO ports for switching version
    [lights.c]
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2020-08-17 Fix slave output not working
    [globals.h, lights.c]
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2020-09-19 Tweak Mk4P and Mk4S case design
    Reduce gap to 0.3
    Make screw hole not go all the way through so that we can
    print a clean bottom layer without interruption.
    [light-controller-case-mk4s-mk4p.scad]
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2020-10-24 Add invert_out15s and prefer_all_lights_off features
    invert_out15s inverts the switched light output on a low level.
    Requested in the German forum to control the enable pin of
    an external DC/DC converter
    prefer_all_lights_off changes the behaviour of 3 clicks.
    When enabled, if the lights are on in any position, then 3-clicks
    now toggles the lights to off.
    Only when the lights are off, then 3-clicks switches to the highest
    light switch position.
    [config.c, globals.h, lights.c]
2020-11-15 Fix TH being output in ServoReader
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2020-12-19 Replace expensive 47u cap with MLCC 10u 0603
    Tested on a prototype and working without issue
    [webusb-programmer.kicad_pcb, webusb-programmer.sch]
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2020-12-28 Fix load button prompting twice
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2021-01-03 Fix Mk4P labeling on the schematics
    [rc-light-controller-pinheader-lpc812.sch]
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2021-01-04 Change output labels back to 0..2
    16..18 may be weird as it is not in line with all the other
    light controllers
    [rc-light-controller-switching-mini-lpc812.kicad_pcb]
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2021-01-10 Fix AUX2 and improve the layout
    [rc-light-controller-switching-mini-lpc812.kicad_pcb, rc-light-controller-switching-mini5-lpc812.kicad_pcb, rc-light-controller-switching-mini5-lpc812.sch]
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2021-01-13 Fix manual indicator hysteresis
    [aux_handler.c, config.c]
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2021-01-31 Make steering, throttle, aux, aux2 and aux3 predefined variables
    Makes the code easier, and is way more flexible.
    Supports if and skip if.
    Assembler and disassembler have been updated
    [config.c, globals.h, light_programs.c]
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2021-02-11 Fix board thickness dimensions
    [preprocessor-multi-aux-tssop20.kicad_pcb, preprocessor-multi-aux-xson16.kicad_pcb, preprocessor-multi-aux.kicad_pcb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]
2021-02-11 Rename mk4s-mini5 to 5ch-PP-S
    Otherwise people constantly confuse it with the mk4s-mini
    [preprocessor-multi-aux-switching.kicad_pcb, preprocessor-multi-aux-switching.sch]
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2021-02-11 Fix via size and improve ground stitching
    [rc-light-controller-tlc5940-lpc812.kicad_pcb]
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2021-02-14 Add and fix product label on silkscreen
    [preprocessor-multi-aux-xson16.kicad_pcb, preprocessor.kicad_pcb]
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2021-02-23 Fix 5ch-PP-S AUX2 handling and configurator
    [hal_lpc81x.c]
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2021-03-11 Fix TLC5940 footprint being SMD
    [rc-light-controller-tlc5940-lpc812.kicad_pcb]
2021-03-12 Reverse LED polarity to prevent pull-up from lighting them up
    [webusb-programmer-ch55x.kicad_pcb, webusb-programmer-ch55x.sch]
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2021-03-20 Reduce complexity by using internal LDO and no shorting MOSFET
    [webusb-programmer-ch552.kicad_pcb, webusb-programmer-ch552.sch]
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2021-03-21 Add Gerber and fix schematics metadata
    [webusb-programmer-ch552.sch]
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2021-03-28 Add channel reversing to the configurator
    The ST and TH reversing via the transmitter (7-clicks) still
    remains, but now we have also channel reversing at configuration
    time.
    This is useful when making light programs that read AUX channels,
    but then during testing we discover that "left gimbal" means
    actually longer servo pulses -- there is no standard, every
    radio manufacturer does it differently.
    [config.c, globals.h, persistent_storage.c]
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2021-04-12 Fix R5, T1, U$1 not being reflected in Pick and Place file
    [rc-light-controller-tlc5940-lpc812.kicad_pcb, rc-light-controller-tlc5940-lpc812.sch]
2021-04-13 Work on LPC832 support
    Pre-processor input and pre-processor output are working.
    Basic functionality is working.
    Servo reader is not working yet.
    TLC5940 control not tested.
    Servo output not tested.
    [hal_lpc81x.c]
2021-04-13 Fix DEVICE_ID address 0x3f8, not 0x3f4
    [LPC8xx.h]
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2021-05-01 Remove default light program, no longer needed
    [config.c, globals.h, light_programs.c]
2021-05-01 Fix light programs malfunctioning
    [alternate.test.sequence.config.txt]
2021-05-01 Make light programs structure volatile
    This is necessary to prevent the that the compiler optmizies
    code away and breaks the function when the configurator adds
    more light programs
    [globals.h]
2021-05-01 Fix new values when loading old configurations
    [alternate.test.sequence.config.txt]
2021-05-01 Make all example configurations work on latest configurator
    Main issue was labels being called "hazard", which is now
    a built-in variable by default
    [light_controller.config.lexus-rcf.txt, light_controller.config.subaru-impreza-2008.txt, light_controller.config.subaru-prototype.txt]
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2021-05-09 Correct MCU pin usage
    [preprocessor-multi-aux-lpc832.sch]
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2021-05-21 Fix 5ch-PP for LPC832
    PINENABLE was configured for LPC812, but the bits have a
    different meaning on LPC832. So in LPC832 we accidentally
    turned out XTAL-IN function on GPIO8 (instead of enabling RESET).
    Since we don't need the reset pin anyway, we just remove PINENABLE.
    [config.c, hal_lpc81x.c]
2021-05-21 Fix LPC812 not working after removing PINENABLE
    [config.c, hal_lpc81x.c]
2021-05-23 Fix 3chPP LPC812 silk screen + label for 47u
    [preprocessor-3ch-lpc832.kicad_pcb]
2021-05-24 Fix PINENABLE for both LPC812 and LPC832
    v39 fixed LPC812, but 832-based Mk4P was no longer working because
    SWD pins are enabled after reset!
    [config.c, hal_lpc81x.c]
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2021-08-10 Fix soldermask settings
    [rc-light-controller-switching-lpc832.kicad_pcb]
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2021-08-29 Fix shelf queen mode
    Issue with the new diagnstics taking place even when
    shelf queen mode is active.
    [config.c, lights.c]
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2021-09-19 Fix light_switch_position range for light programs
    [config.c, light_programs.c]
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2021-11-04 Fix setting of SMOD for fast baudrate mode
    [main.c]
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2021-11-10 Configurator: Fix ms->us; Program button focus
    Some servo pulse values used a unit of ms when it was actually us.
    The program button is now being focused when the programming
    tab is entered, which improves keyboard usability
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2021-11-27 Remove more obsolete files; fix broken links and clarify things
    [rc-light-controller-tlc5940-lpc812.kicad_pcb, rc-light-controller-tlc5940-lpc812.sch]
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2021-12-07 i-Bus now working
    To fix: automatic selection of i-Bus or Pre-Processor in
    the configurator
    [hal_lpc81x.c, ibus_reader.c, main.c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]
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2021-12-07 Add i-Bus example data from an actual receiver and fix i-Bus decoder
    [ibus_reader.c]
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2021-12-20 Fix all leds if no LED declared
    If no LED is defined, but an assinment was made to "all leds",
    then an error message was shown without any information what
    the issue was.
    Example:
    run always
    all leds = 100
    end
    Now the message "No LED defined" is shown.
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2022-05-04 Fix help text in schematics
    [rc-light-controller-tlc5940-lpc832-sbus.sch]
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2022-07-14 Use RXPOL to invert S.Bus UART instead of hardware inverter
    [config.c, hal_lpc81x.c, main.c]
2022-07-14 Output correct MCU type in diagnostics
    Refactor from a flag to the variable mcu_type
    [hal_lpc81x.c, main.c]
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2022-11-23 Fix Slave when running at 100000 BAUD
    Issue: the slave must not invert the Rx pin! Only when processing
    S-Bus input do we want to invert the Rx pin.
    [config.c, hal_lpc81x.c, main.c]
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2023-02-08 Make firmware run, WS2811 not working yet
    [hal_lpc81x.c]
2023-03-03 Revert firmware to before adding WS2811 support
    [config.c, globals.h, hal_lpc81x.c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]
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2023-11-09 Fix 3ch PP not setting multi-aux flag despite outputing full packet
    [preprocessor_output.c]
2023-12-29 Fix Servo output from AUX channel
2023-12-29 Fix servo setup number of clicks is 8, not 7
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2024-09-09 Fix LED names defined in the table were only working in the first Light program
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2025-01-13 Fix issues caused by different SOT-32 footprint
    [rc-light-controller-switching-lpc832.kicad_pcb]
2025-01-13 Fix layout and pass DRC
    [rc-light-controller-pinheader-lpc832.kicad_pcb, rc-light-controller-switching-lpc832.kicad_pcb]
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
